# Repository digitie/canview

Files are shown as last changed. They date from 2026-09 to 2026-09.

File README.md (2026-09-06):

# canview

현대·기아·제네시스 차량의 CAN 데이터를 별도 **Communicator**에서 수집하고, `ESP-NOW`로 Waveshare `ESP32-S3-Touch-LCD-3.5` 기반 **Controller**에 전달해 시각화하는 프로젝트다. Controller는 최대 3개의 CAN 버스에서 들어오는 데이터를 표시하고, 필요한 경우 안전하게 제한된 의도 명령을 Communicator에 전달한다.

현재 1차 대상은 다음 차량이다.

- 2017년식 Hyundai Tucson TL
- 2.0 디젤
- 4WD
- BlueLink 사양

차량별 CAN 정의는 `commaai/opendbc`의 공개 DBC를 기준으로 시작한다. upstream에 2017년식 Tucson 전용 항목이 확인되지 않으므로, 현재 저장된 DBC는 실차 캡처로 검증해야 하는 후보 정의다.

## 문서

상세 문서를 한꺼번에 읽지 않도록 [문서 지도](docs/README.md)가 작업별 진입점과 정본 관계를 관리한다.

- [아키텍처 개요](docs/architecture/README.md): 장치·권한·protocol·기능 설계
- [현재 진척과 다음 작업](docs/resume.md)
- [열린 task와 gate](docs/tasks.md)
- [결정 색인과 ADR](docs/decisions.md)
- [적대적 리뷰 아카이브](docs/reviews/README.md)
- [에이전트 workflow](docs/runbooks/agent-workflow.md)

## UI prototype

320×480 세로 화면에 맞춘 주행·소리·FFT·자동화·설정 UI를 HTML prototype과 LVGL 8.4 코드로 제공한다. 현대 표준형 5W의 짙은 청색 tone과 LVGL 공식 eBike·Music 등 전체 데모의 유효한 패턴을 선별했다. 주행 화면 높이의 약 75%를 순정형 4WD 구동계에 할당하고, 중앙 차량·앞뒤 differential·shaft·네 바퀴 분절 torque bar를 표시한다. 순간연비는 차량 중앙에 두며 DPF와 작은 원형 속도·RPM이 이어진다. 현재 속도와 제한속도는 모든 화면에서 유지한다. 아래 값은 레이아웃 검토용 데모이며 실차 측정값이 아니다.

| 주행 상태 | 소리 제어 | FFT 분석 |
|---|---|---|
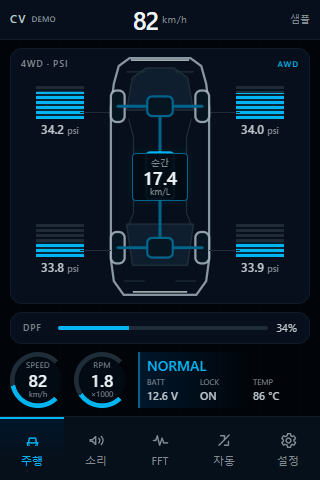
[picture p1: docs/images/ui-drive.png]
주행 화면
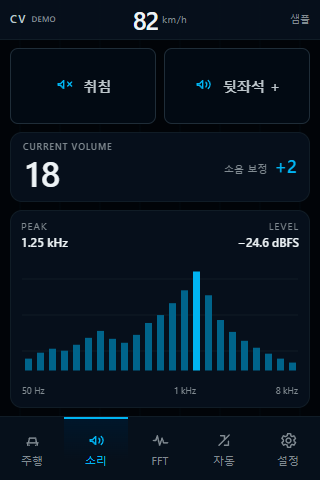
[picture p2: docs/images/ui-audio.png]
소리 화면
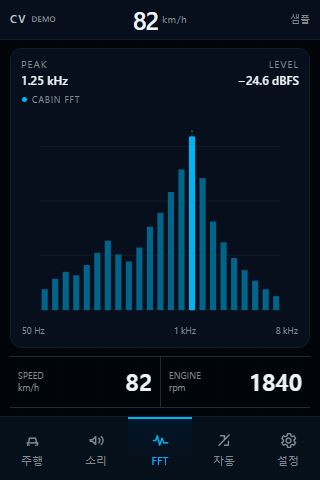
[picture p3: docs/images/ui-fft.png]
FFT 화면
|  |  |  |

| SPORT 자동화 | 설정 | 자동화 상세 설정 |
|---|---|---|
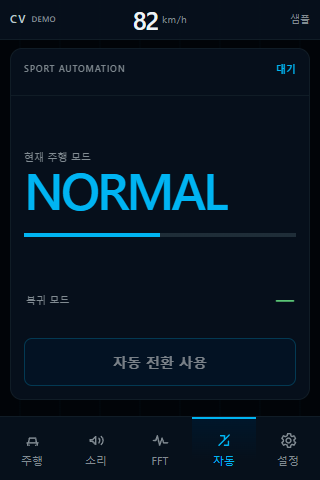
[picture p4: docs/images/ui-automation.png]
자동화 화면
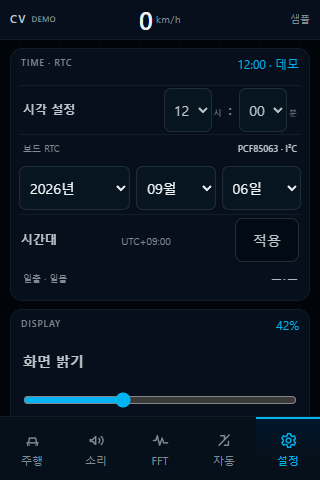
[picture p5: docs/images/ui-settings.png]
설정 화면
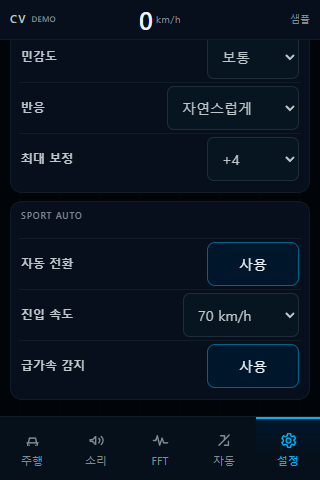
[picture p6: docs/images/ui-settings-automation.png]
소음·SPORT 설정 화면
|  |  |  |

- 브라우저 prototype: [`ui/prototype/`](ui/prototype/)
- LVGL 8.4 UI: [`ui/lvgl/`](ui/lvgl/)
- wire protocol C 구조: [`protocol/canview_protocol.h`](protocol/canview_protocol.h)

미확정 CAN ID·bit·scale은 별도 `Diagnostic Bridge`가 ESP-NOW read-only peer로 수신하고, 휴대폰이 Bridge의 고정-channel SoftAP에 접속해 확인하는 구조를 기본안으로 한다. 아래 정적 prototype은 세 CAN bus 상태, 행동 전후 capture, 64-bit 변화 지도와 후보 decoder의 모바일 정보 구조를 보여준다. 실제 REST·WebSocket firmware는 [구현 명세](docs/architecture/diagnostic-bridge.md)의 단계에 따라 추가한다.

| Diagnostic Bridge 상태 | Signal Lab |
|---|---|
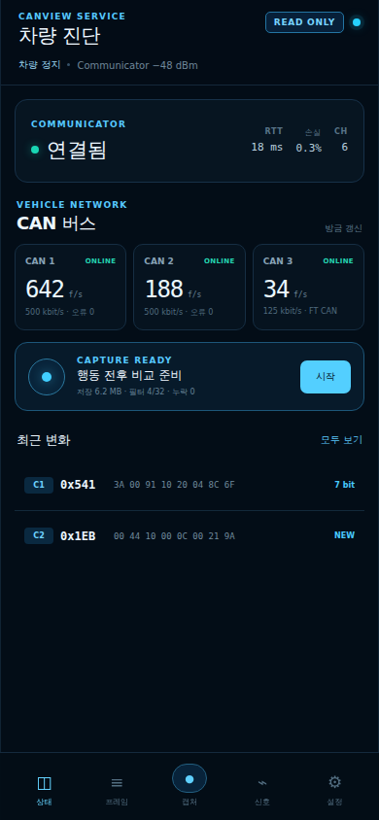
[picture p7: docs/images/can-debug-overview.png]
진단 상태 화면
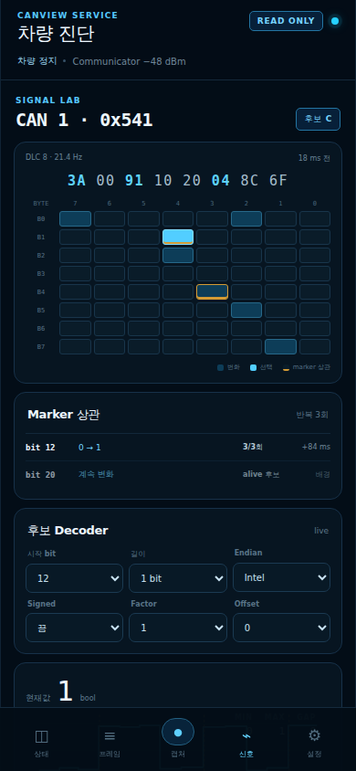
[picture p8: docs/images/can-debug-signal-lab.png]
신호 분석 화면
|  |  |

- 모바일 진단 prototype: [`ui/diagnostic-web/`](ui/diagnostic-web/)

## 저장된 DBC

원본은 `dbc/opendbc/`에 upstream 파일을 수정하지 않고 저장했다.

- `hyundai_can.dbc`: 현재 Hyundai 공통 CAN generator source. 1차 대상의 주 후보
- `hyundai_2015_ccan.dbc`: 구형 Classic CAN 참고 정의
- `hyundai_2015_mcan.dbc`: 구형 Multimedia CAN 참고 정의
- `LICENSE`: DBC 원본 저장에 필요한 upstream MIT License

파일의 upstream commit, SHA-256, 적용 범위는 [dbc/README.md](dbc/README.md)에 고정해 두었다.

## 저장소 상태

DBC 원본, hardware 기준, 기능 안전 경계, ESP-NOW wire 구조, 화면 prototype과 LVGL UI 계층을 포함한 설계 기준 저장소다. 실제 Communicator와 Controller firmware 통합은 실차 capture로 신호를 검증하면서 단계적으로 추가한다.

현재 저장소는 차량 송신 가능 상태가 아니다. protocol payload ABI·codec, 완성 firmware project, 승인 회로도와 firmware 독립 hard TX gate, 대상 차량 evidence가 모두 미완료다. 구현 순서와 차량 연결 gate는 [구현 준비 기준](docs/architecture/implementation-readiness.md)과 [task backlog](docs/tasks.md)를 따른다.

## 주요 원문

- [Waveshare ESP32-S3-Touch-LCD-3.5 제품 문서](https://docs.waveshare.com/ESP32-S3-Touch-LCD-3.5)
- [Waveshare 리소스 및 회로도](https://docs.waveshare.com/ESP32-S3-Touch-LCD-3.5/Resources-And-Documents)
- [Waveshare 예제 저장소](https://github.com/waveshareteam/ESP32-S3-Touch-LCD-3.5/)
- [commaai/opendbc](https://github.com/commaai/opendbc)

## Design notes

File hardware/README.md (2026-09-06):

# CANView KiCad 하드웨어

KiCad **10.0.6 Windows native**로 생성·내보내는 R1 상세 회로 검토본이다. 네 보드 모두 로컬 심벌·footprint, 부품별 사양, 연결표와 실제 KiCad netlist를 포함한다. **PCB 라우팅·Gerber·실물 시험은 포함하지 않으며 제작/차량 연결 승인본이 아니다.**

| 보드 | 편집 프로젝트 | 사람이 읽는 회로 | netlist |
|---|---|---|---|
| Communicator | [KiCad](communicator/kicad/communicator.kicad_pro) | [PDF](communicator/schematic.pdf) | [.net](communicator/communicator.net), [XML](communicator/netlist.xml) |
| Bridge | [KiCad](bridge/kicad/bridge.kicad_pro) | [PDF](bridge/schematic.pdf) | [.net](bridge/bridge.net), [XML](bridge/netlist.xml) |
| Controller 어댑터 | [KiCad](controller-adapter/kicad/controller-adapter.kicad_pro) | [PDF](controller-adapter/schematic.pdf) | [.net](controller-adapter/controller-adapter.net), [XML](controller-adapter/netlist.xml) |
| 원격 마이크 | [KiCad](microphone/kicad/microphone.kicad_pro) | [PDF](microphone/schematic.pdf) | [.net](microphone/microphone.net), [XML](microphone/netlist.xml) |

각 보드의 `bom.csv`는 reference/MPN/footprint/정격/허용오차/source/DNP/sheet를, `pinmap.csv`는 부품의 **물리 패드 번호별** net과 NC를 기록한다. `GEN-R-*`, `GEN-C-*`는 제조사 주문번호가 아니라 명시 사양의 구매 규격이다. 실제 구매품을 고를 때 동일 크기·전압·전력·온도·유효용량을 확인해야 한다. `PCB-PAD-1MM`는 구매 부품이 없는 테스트 패드다. `MP`는 JST 금속 고정 탭이며 신호 접점이 아니므로 명시적으로 NC다. USB 실드 패드는 `SH`로 GND에 연결한다.

설계 이유는 [R1 문서 지도](../docs/hardware/r1/README.md), 제조사 원본과 참조 페이지는 [references](references/README.md), 자동검사 결과는 [validation.json](validation.json), 수치 검산은 [margin-check.json](margin-check.json)에 있다.

## Windows 재생성

```powershell
Set-Location F:/dev/canview
.\tools\hardware\export-review.ps1
& 'C:\Program Files\KiCad\10.0\bin\python.exe' tools\hardware\validate_exports.py
& 'C:\Program Files\KiCad\10.0\bin\python.exe' tools\hardware\check_margins.py
& 'C:\Program Files\KiCad\10.0\bin\python.exe' -m unittest discover -s tools\protocol -p test_navigation_codec.py -v
# commit 이후, 저장된 evidence와 실제 Git blob을 대조 (read-only)
& 'C:\Program Files\KiCad\10.0\bin\python.exe' tools\hardware\validate_exports.py --git-revision HEAD
```

회로 source → KiCad XML/sexpr netlist → ERC → PDF 순서이며 각 native process의 종료를 기다린다. validator는 모든 부품의 실제 footprint를 KiCad `pcbnew`로 열고, 번호 있는 패드 집합/NC/net/BOM/주요 안전 pin을 대조한다. 자동검사 통과는 정격·PCB parasitic·고장 주입 검증을 대신하지 않는다. 로컬 symbol과 footprint에는 생성 입력과 출처가 포함되며 3D 모델은 KiCad 설치 경로 참조일 수 있다.

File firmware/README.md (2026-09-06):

# 펌웨어 진입점

현재 코드는 기능 구현 전의 안전 부팅/공용 codec 기반이다. 후속 agent는 [기반 구조와 인수인계](../docs/architecture/firmware-foundation.md)를 먼저 읽고 자신의 상세 task만 연다.

| 대상 | 프로젝트 |
|---|---|
| Controller | [controller](controller/README.md) |
| Communicator ESP32 | [communicator/esp32](communicator/esp32/README.md) |
| Communicator STM32 | [communicator/stm32](communicator/stm32/README.md) |
| Diagnostic Bridge | [diagnostic-bridge](diagnostic-bridge/README.md) |

공용 C99 코드는 ../shared, 장치 조합은 app/startup.c와 각 bsp, SDK 호출은 platform에 둔다.
BSP는 firmware/boards/boards.json과 원본 pinmap에서 생성한 board_pins.h를 사용한다.
기존 Controller components와 STM32 auto_sport는 legacy host 회귀에만 포함하고 새 target image에서는 제외한다.

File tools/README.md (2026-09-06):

# CANView 개발 도구

이 디렉터리는 Windows 정본 개발환경의 버전 manifest와 SDK 준비 스크립트를 보관한다. 실제 제품 기능이나 차량 설정은 이 디렉터리에 두지 않는다.

## 고정 버전

`toolchain-versions.json`이 현재 선택한 Windows x64 환경의 machine-readable 정본이다.

- ESP-IDF `v6.0.3`, target `esp32s3`
- STM32CubeG4 `v1.6.3`, MCU `STM32G474CEU6`
- CMake `4.4.3`
- Ninja `1.13.2`
- Arm GNU Toolchain `15.3.Rel1` (GCC `15.3.x`)
- KiCad `10.0.6` (`kicad-cli`, 회로도 export/ERC)

ESP-IDF와 STM32CubeG4는 manifest에 기록한 commit까지 검증한다. 버전 tag만 확인하지 않으므로 이동 tag나 잘못된 checkout을 조용히 사용하지 않는다.

## Windows 준비

먼저 CMake, Ninja, Git을 Windows `PATH`에 설치한다. Arm GNU Toolchain은 아래 설치 스크립트로 manifest의 `archiveUrl`에서 직접 내려받아 archive SHA-256, ZIP entry layout, 설치 root 전체 파일 inventory를 검증한다. `setup-windows.ps1`은 archive SHA-256과 provenance의 전체 파일 hash를 다시 확인하며 provenance marker가 없는 ambient `PATH` compiler를 사용하지 않는다. ESP-IDF build path에는 공백을 사용할 수 없으므로 Windows 사용자 profile 경로에 공백이 있으면 공백 없는 `-ToolRoot`를 지정한다. 그 다음 PowerShell에서 다음을 실행한다.

```powershell
Set-ExecutionPolicy -Scope Process -ExecutionPolicy Bypass
. .\tools\environment\install-arm-gnu.ps1
. .\tools\environment\foundation-windows.ps1
. .\tools\environment\setup-windows.ps1
```

기본 직접 설치 위치는 `%LOCALAPPDATA%\CANView\toolchains\arm-gnu-toolchain-15.3.rel1`이며 setup script가 provenance marker와 설치 root 전체 파일 hash를 확인한 뒤 자동 탐색한다. 이미 받은 archive를 재사용하려면 다음처럼 명시한다.

```powershell
. .\tools\environment\install-arm-gnu.ps1 -ArchivePath C:\path\arm-gnu-toolchain-15.3.rel1-mingw-w64-x86_64-arm-none-eabi.zip -AdoptExisting
```

이미 같은 release를 수동 압축 해제한 경로라면 `-AdoptExisting`를 추가한다. 스크립트가 pinned archive의 layout과 전체 파일 SHA-256을 대조한 뒤에만 provenance marker를 만든다. 설치 후 파일을 추가·삭제·변조하면 다음 setup 검증이 실패한다.

다른 verified 설치 위치를 사용할 때는 설치와 setup에 같은 root를 명시한다.

```powershell
. .\tools\environment\install-arm-gnu.ps1 -Destination C:\ArmGNU
. .\tools\environment\setup-windows.ps1 -ArmGnuRoot C:\ArmGNU\arm-gnu-toolchain-15.3.rel1 -ArmGnuArchive C:\path\arm-gnu-toolchain-15.3.rel1-mingw-w64-x86_64-arm-none-eabi.zip
```

예를 들어 사용자 profile에 공백이 있는 경우:

```powershell
. .\tools\environment\setup-windows.ps1 -ToolRoot C:\CANViewToolchains
```

스크립트는 최신으로 임의 갱신하지 않고, manifest에 고정된 ESP-IDF와 STM32CubeG4를 `%LOCALAPPDATA%\CANView\toolchains` 아래에 clone한다. ESP-IDF Python 도구를 설치한 뒤 현재 세션에 `IDF_PATH`와 `STM32CUBE_G4_ROOT`를 설정한다.

이미 SDK를 준비한 뒤 검증만 할 때는 archive가 설치 때 기록한 경로에 남아 있거나, `-ArmGnuArchive`로 같은 archive를 명시해야 한다.

```powershell
. .\tools\environment\setup-windows.ps1 -VerifyOnly -ArmGnuArchive C:\path\arm-gnu-toolchain-15.3.rel1-mingw-w64-x86_64-arm-none-eabi.zip
```

`-VerifyOnly`에서도 archive SHA-256, 설치 root 전체 파일 inventory, CMake·Ninja·Arm GCC 버전과 SDK commit, `idf.py`, STM32G4 device header를 모두 확인한다.

## 대상별 빌드

```powershell
# Controller: ESP32-S3R8, 16 MB Flash / 8 MB PSRAM
idf.py -C firmware/controller set-target esp32s3
idf.py -C firmware/controller build

# Communicator ESP32: ESP32-S3-WROOM-1-N16R8, 16 MB Flash / 8 MB Octal PSRAM (ECC)
idf.py -C firmware/communicator/esp32 set-target esp32s3
idf.py -C firmware/communicator/esp32 build

# 외부 component의 public protocol 의존성 compile fixture
idf.py -C tests/fixtures/idf-public-component set-target esp32s3
idf.py -C tests/fixtures/idf-public-component build

# Communicator STM32: Debug 또는 Release
Push-Location firmware/communicator/stm32
cmake --preset debug
cmake --build --preset debug
Pop-Location
```

## KiCad 회로도 산출물 재생성

KiCad `10.0.6`의 bundled Python으로 회로도 원본을 재생성하고, `kicad-cli`로 XML netlist·ERC JSON·PDF를 같은 revision으로 갱신한다.

```powershell
. .\tools\hardware\export-review.ps1
```

이 스크립트는 `hardware/`의 Communicator·Bridge·Controller adapter·microphone 네 보드를 갱신하고, ERC·BOM·netlist·named-pad 정합성 및 정적 전원/WD 계산까지 검사한다. 검사 실패 시 nonzero로 종료한다. [상세 사용법과 제작 전 제한](../hardware/README.md)을 따른다. 실제 전원·PCB·HIL 승인을 뜻하지 않는다.

PowerShell에서 `idf.py`를 찾지 못하면 새 세션에서 다시 dot-source하고, STM32 configure가 실패하면 Arm archive 경로와 `STM32CUBE_G4_ROOT`를 확인한다. target build가 실제로 실행되지 않은 상태를 성공으로 기록하지 않는다.

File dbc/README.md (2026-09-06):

# Hyundai DBC 저장소

## 1. 저장 목적

이 디렉터리는 `commaai/opendbc`에서 가져온 Hyundai·Kia·Genesis 계열 CAN 정의를 `canview`의 재현 가능한 입력으로 보관한다. DBC 파일은 차량 CAN raw frame을 사람이 읽을 수 있는 message/signal 값으로 decode하기 위한 정의이며, 파일에 정의된다고 해서 모든 연식·트림·시장 사양에서 동일하게 동작한다는 뜻은 아니다.

원본 DBC는 프로젝트에서 임의로 수정하지 않았다. 차량별 보정이나 캡처 결과는 원본 파일을 덮어쓰지 않고 별도 파일과 검증 기록으로 추가한다.

## 2. upstream 고정 정보

| 항목 | 값 |
|---|---|
| 저장소 | [`commaai/opendbc`](https://github.com/commaai/opendbc) |
| snapshot commit | [`3e92d112129507debe45364891954db70238997a`](https://github.com/commaai/opendbc/tree/3e92d112129507debe45364891954db70238997a) |
| snapshot 날짜 | 2026-09-03 기준 checkout |
| 라이선스 | MIT. 원문은 [`dbc/opendbc/LICENSE`](opendbc/LICENSE) |
| 1차 대상 | 2017 Hyundai Tucson TL, 2.0 디젤, 4WD, BlueLink |
| 1차 주 후보 | `hyundai_can.dbc` |

### 저장 파일과 역할

| 로컬 파일 | upstream 원본 경로 | 역할 |
|---|---|---|
| [`hyundai_can.dbc`](opendbc/hyundai_can.dbc) | `opendbc/dbc/generator/hyundai/hyundai_can.dbc` | 현재 Hyundai 공통 CAN generator source. 1차 대상의 주 후보 |
| [`hyundai_2015_ccan.dbc`](opendbc/hyundai_2015_ccan.dbc) | `opendbc/dbc/hyundai_2015_ccan.dbc` | 구형 Classic CAN 비교용 |
| [`hyundai_2015_mcan.dbc`](opendbc/hyundai_2015_mcan.dbc) | `opendbc/dbc/hyundai_2015_mcan.dbc` | 구형 Multimedia CAN 비교용 |
| [`LICENSE`](opendbc/LICENSE) | `LICENSE` | upstream MIT License 원문 |

현재 1차 대상은 Classic CAN 후보이므로 CAN-FD generator와 include 파일은 이 snapshot에 복사하지 않았다. CAN-FD 차량을 추가할 때는 `hyundai_canfd.dbc`와 상대 include인 `_hyundai_canfd_common.dbc`를 같은 upstream commit에서 함께 고정한다.

## 3. 무결성 확인

현재 저장해야 할 SHA-256은 다음과 같다. upstream을 갱신할 때는 commit과 해시를 함께 바꾼다.

| 파일 | SHA-256 |
|---|---|
| `hyundai_can.dbc` | `a3fb6e98bfdc0041914643f1422b1bb9290462981c40249a05cd7773e71a8bc3` |
| `hyundai_2015_ccan.dbc` | `d7f822e3a8d220cfde83aec2ae4ed28ddbc44a38ff29bea2e12e3e321d73a607` |
| `hyundai_2015_mcan.dbc` | `b18e69bdd30e53fe689b23fbd59779095249a1bb5b2391435e814a490fa924e4` |
| `LICENSE` | `6543c4a66b46affddae1b9ae1e1992687f0b7191e74ba3a7235388b9f42a6d13` |

확인 명령:

```bash
sha256sum dbc/opendbc/*.dbc dbc/opendbc/LICENSE
```

## 4. 1차 차량 적용 방법

upstream의 일반 `HYUNDAI_TUCSON` 플랫폼은 `hyundai_can_generated`를 사용한다. 따라서 generator source인 `hyundai_can.dbc`를 1차 decode 후보로 선택했다. 하지만 upstream에는 2017 Tucson TL의 엔진·구동·BlueLink 조합을 별도 fingerprint로 확정한 항목이 없으므로, 이 선택은 “후보”이며 실차 검증 결과가 아니다.

실차 적용 순서는 다음과 같다.

1. 차량의 실제 CAN connector, bus, bitrate를 listen-only로 확인한다.
2. ignition off/on, idle, 주행, 변속, 제동, 4WD 상태를 별도 캡처한다.
3. `hyundai_can.dbc`로 ID와 signal을 decode한다.
4. 계기판·실측값과 비교해 신호를 A/B/C/X 등급으로 기록한다.
5. 검증된 신호만 기본 화면에 표시하고, 미확인 값은 일반 UI에서 숨긴 채 service log에 `candidate`/`raw`로 기록한다.

차량별 결과는 [2017 Tucson TL 문서](../docs/vehicle/target-2017-tucson.md)에 기록한다. 내비·연비·오디오·BCM·IPS·도어를 포함한 상세 후보와 제어 등급은 [signal catalog](../docs/vehicle/signal-catalog.md)에 있다.

## 5. 우선 확인할 신호

다음은 `hyundai_can.dbc`를 읽어 정리한 1차 후보 목록이다. ID는 표준 11-bit decimal/hex 표기이며, 실차 bus 위치와 존재 여부는 아직 확정하지 않았다.

| Message (ID) | 주요 signal | DBC 변환 |
|---|---|---|
| `CLU11` (`0x4F1`) | `CF_Clu_Vanz` | factor `0.5`, `km/h or MPH` |
| `CLU12` (`0x5B0`) | `CF_Clu_Odometer` | factor `0.1`, `km` |
| `WHL_SPD11` (`0x386`) | `WHL_SPD_FL/FR/RL/RR` | factor `0.03125`, `km/h` |
| `EMS11` (`0x316`) | `N`, `TQI`, `VS` | `N`: `0.25 rpm`; `VS`: `1 km/h` |
| `EMS12` (`0x329`) | `TEMP_ENG`, `TPS`, `ENG_VOL` | 온도 `0.75/-48`; TPS `0.4694836/-15.0234742`; 용적 `0.1` |
| `EMS14` (`0x545`) | `VB`, `EMS_VS` | `VB`: `0.1015625 V`; `EMS_VS`: `0.0625 km/h` |
| `EMS16` (`0x260`) | `ENG_STAT`, `GLOW_STAT` | 상태 code/flag |
| `EMS19` (`0x492`) | `CR_Ems_EngOilTemp`, `DPF_LAMP_STAT` | 온도 `0.75/-40` |
| `TCU11` (`0x111`) | `G_SEL_DISP`, `GEAR_TYPE`, `N_TC` | `N_TC`: `0.25 rpm` |
| `TCU12` (`0x112`) | `CUR_GR`, `VS_TCU`, `N_TC_RAW` | 현재 기어/속도/RPM 후보 |
| `_4WD11` (`0x428`) | `_4WD_TYPE`, `_2H_ACT`, `_4H_ACT`, `LOW_ACT`, `AUTO_ACT`, `LOCK_ACT` | bit flag/상태 code |
| `_4WD12` (`0x429`) | `FRSS`, `FLSS`, `RRSS`, `RLSS`, `CLU_PRES` | wheel speed byte, pressure factor `0.0625` |
| `_4WD13` (`0x42A`) | `_4WD_CURRENT`, `_4WD_POSITION`, `_4WD_STATUS` | current/position/status 후보 |
| `ESP12` (`0x220`) | `LAT_ACCEL`, `LONG_ACCEL`, `YAW_RATE` | accel factor `0.01`; yaw factor `0.01` |
| `SAS11` (`0x2B0`) | `SAS_Angle` | signed factor `0.1 deg` |
| `MDPS11`/`MDPS12` (`0x381`/`0x251`) | steering angle/torque | 표시 전용 후보 |
| `TPMS11` (`0x593`) | tire status/pressure bytes | 단위·위치 별도 검증 |
| `SCC11` (`0x420`) | `ObjValid`, `ACC_ObjDist`, `ACC_ObjRelSpd` | read-only 참고 |
| `LKAS11` (`0x340`) | warning/request fields | 송신 금지 |

DBC의 sender/receiver 표기와 실제 차량 bus의 위치는 서로 다른 정보다. `sender`가 `EMS`라고 되어 있어도 차량에서 어느 물리 CAN bus에 보이는지는 캡처로 정한다.

## 6. Python decode 예

검증용으로만 사용한다. 차량에 연결하거나 frame을 송신하는 코드가 아니다.

```bash
python -m pip install cantools
```

```python
import cantools

db = cantools.database.load_file("dbc/opendbc/hyundai_can.dbc")
message = db.get_message_by_frame_id(0x4F1)
decoded = message.decode(bytes.fromhex("00 00 00 00"), decode_choices=False)
print(message.name, decoded)
```

실제 payload의 byte order, counter, checksum, multiplex 조건을 캡처와 함께 확인한다. 임의 payload를 차량 bus로 전송하지 않는다.

## 7. 갱신 절차

upstream DBC를 갱신할 때는 다음을 모두 한 변경으로 남긴다.

1. upstream commit을 선택하고 URL을 기록한다.
2. 원본 상대 경로를 보존해 필요한 include/source를 복사한다.
3. 파일을 수정하지 않고 SHA-256을 계산한다.
4. 이 문서의 commit, 날짜, 해시, 파일 역할을 갱신한다.
5. 1차 대상 차량에서 재캡처하거나 기존 캡처를 다시 decode한다.
6. 변경 전후의 signal 목록과 해석 차이를 기록한다.

## 8. 라이선스

저장된 DBC와 `LICENSE`는 `commaai/opendbc` snapshot에서 가져왔다. 배포·변경·고지 시 [`dbc/opendbc/LICENSE`](opendbc/LICENSE)의 MIT 조건을 따른다. 프로젝트 문서의 차량별 검증 결과와 새 보정 DBC는 원본 upstream 파일과 별도로 관리한다.

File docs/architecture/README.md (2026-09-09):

# CANView 아키텍처

이 문서는 CANView의 장치 관계, 데이터 흐름과 권한 경계를 설명하는 상위 아키텍처 정본이다. 여기서 전체 형태를 확인한 뒤 변경 대상에 해당하는 상세 문서만 읽는다. 구현 순서는 [implementation readiness](implementation-readiness.md), 결정의 역사는 [ADR 색인](../adr/README.md), 현재 작업은 [tasks](../tasks.md)를 따른다.

## 문서 사용법

| 변경 대상 | 상세 정본 |
|---|---|
| 장치명·peer routing·장애 상태 | [시스템 구조](system.md) |
| repository 목표 구조·runtime 경계·release gate | [구현 준비 기준](implementation-readiness.md) |
| 실제 기반 코드·MCU 독립 API·다음 agent 인수인계 | [펌웨어 기반 구조](firmware-foundation.md) |
| 전체 계획 감사·요구사항별 수용 기준 추적 | [요구사항 coverage](requirements-coverage.md) |
| ESP-NOW·UART wire 계약 | [프로토콜 인덱스](protocols/README.md) |
| 독립 OTA·부트 복구·N16R8 회로 변경 | [OTA 설계와 적대적 리뷰](ota.md) |
| 외부 GNSS·온보드 INS·기압·시간 | [센서 확장 계약](protocols/navigation.md), [R1 하드웨어](../hardware/r1/README.md) |
| Controller 수신·filter·DBC decode | [Controller CAN pipeline](controller-can-pipeline.md) |
| Diagnostic Bridge·capture·REST/WS | [Diagnostic Bridge](diagnostic-bridge.md) |
| 4WD·DPF·audio·SPORT 기능 | [기능 설계](features.md) |
| 밝기·FFT 음량·SPORT 상태기계 | [자동화 설계](automation.md) |

하드웨어, 차량 evidence와 UI 시각 설계는 architecture의 입력이지만 각각 [hardware](../README.md#하드웨어), [vehicle](../README.md#차량과-신호), [UI](../README.md#ui) 문서가 상세 정본이다. 일반 작업에서 위 문서를 모두 선제적으로 읽지 않는다.

## 1. 시스템 범위

CANView는 2017 Tucson TL 2.0 디젤 4WD BlueLink를 1차 대상으로 하는 차량 CAN viewer/controller다. 동일한 구조로 현대·기아·제네시스 차량 profile을 확장할 수 있지만, DBC에 존재한다는 이유만으로 차량별 신호나 제어 명령을 확정하지 않는다.

시스템은 다음 세 장치로 나뉜다.

| 장치 | 하드웨어 | 주 책임 |
|---|---|---|
| Controller | Waveshare ESP32-S3-Touch-LCD-3.5 | LVGL 운전자 UI, 터치, Controller-local 설정, ESP-NOW 명령 요청 |
| Communicator | ESP32-S3-WROOM-1-N16R8 + STM32G474CEU6 + 3 CAN PHY | CAN 수집, timestamp, 안전 상태, 검증된 제한 송신 |
| Diagnostic Bridge | 별도 ESP32-S3 | read-only CAN 관찰, capture, signal lab, 휴대폰용 SoftAP 웹 |

## 2. 데이터 흐름

    차량 CAN 1/2/3
          │
          ▼
    TCAN1046AV-Q1 2채널 + MAX3055 1채널
          │
          ▼
    STM32G474CEU6
      ├─ FDCAN raw capture / bus fault / timestamp
      ├─ local safety profile / command executor
      └─ UART 4 Mbps, RTS/CTS
          │
          ▼
    Communicator ESP32-S3-WROOM-1-N16R8
      ├─ ESP-NOW secure session
      ├─ peer별 filter / quota / retry
      └─ Controller·Diagnostic Bridge routing
          │
          ├──────────────► Controller
          │                 LVGL·상태표시·제한 명령 의도
          │
          └──────────────► Diagnostic Bridge
                            capture·후보 분석·HTTP/WebSocket
                                      │
                                      ▼
                                   휴대폰

Controller와 Communicator 사이에는 ESP-NOW 양방향 링크를 사용한다. Diagnostic Bridge는 별도 peer로 관찰 stream을 받으며, 차량 CAN 송신 경로에는 연결하지 않는다. broadcast raw telemetry와 무제한 multi-hop mesh는 사용하지 않는다.

현재 STM32의 capture-only C source 계약은 [T-103 FDCAN capture 문서](../../firmware/communicator/stm32/docs/fdcan-capture.md)에 있다. IRQ raw snapshot, bounded ring, timestamp 확장과 generic inventory는 관찰 데이터만 만들며, 기본 app wiring이 시작되기 전까지 실제 bus 연결 권한을 부여하지 않는다.

## 3. 책임과 신뢰 경계

| 계층 | 허용 책임 | 금지 책임 |
|---|---|---|
| Controller | 운전자에게 검증된 상태 표시, 입력 검증, local 설정, 의미 있는 명령 요청 | 임의 CAN frame 생성, 최종 safety 판정, 후보 신호의 확정 표시 |
| Communicator ESP32 | ESP-NOW 인증·session·queue·peer 권한·UART routing | DBC 의미 해석, CAN peripheral 직접 제어, 최종 TX 허용 |
| Communicator STM32 | CAN timestamp/error, generated profile, local safety 재검사, 제한 executor | 무선 payload를 그대로 신뢰, raw replay, UI 상태를 차량 사실로 사용 |
| Diagnostic Bridge | read-only inventory·capture·candidate·evidence·웹 진단 | control lease, vehicle CAN TX, raw replay |
| CAN PHY | 논리 신호와 물리 bus 변환, standby·fault 처리 | bitrate·signal 의미·제어 권한 결정 |

차량 CAN 송신은 다음 네 요소가 동시에 맞아야 한다.

1. 검증된 vehicle profile과 command builder
2. 최신이고 유효한 STM32 local safety snapshot
3. Primary Controller의 control lease와 인증된 명령
4. build mode·전원·외부 watchdog·hard TX gate의 허용 상태

하나라도 빠지면 송신하지 않고 이유와 revision을 기록한다.

## 4. 안전 상태와 build mode

| build mode | 허용 동작 | 실제 차량 연결 |
|---|---|---|
| CAPTURE_ONLY | CAN 수신·통계·표시·capture | 수신 전용으로만 허용 |
| BENCH_TX | current-limited 전원과 HIL에서 제한 송신 | 차량 연결 금지 |
| VEHICLE_TX | 모든 hardware·firmware·profile·evidence gate 통과 뒤 제한 송신 | release qualification 후에만 허용 |

전원·reset·brownout·watchdog·통신 단절 시 기본 상태는 CAN 송신 차단이다. TCAN 채널은 standby, MAX3055는 Power-On Standby, 외부 TX gate는 off로 수렴해야 한다. firmware GPIO 초기화만으로 이 조건을 보장한다고 간주하지 않는다.

## 5. 저장소 구조

    protocol/                         — ESP-NOW/UART schema와 생성 ABI
    dbc/                              — upstream DBC 원본과 라이선스
    firmware/controller/              — Controller ESP-IDF/LVGL
    firmware/communicator/esp32/      — Communicator 무선 MCU
    firmware/communicator/stm32/      — STM32 CMake/FDCAN/UART
    hardware/communicator/            — pinmap·KiCad·BOM·전원 계산
    ui/prototype/                     — 화면 검토용 HTML prototype
    ui/lvgl/                          — LVGL 화면 코드
    ui/diagnostic-web/                — 모바일 진단 웹 prototype
    tests/                            — host·protocol·fault·HIL test
    docs/architecture/                — 상위 구조·protocol·기능 설계
    docs/hardware/                    — Controller·Communicator 하드웨어
    docs/development/                 — Windows 환경과 toolchain
    docs/vehicle/                     — 대상 차량·DBC·signal evidence
    docs/ui/                          — UI 설계와 LVGL 검토
    docs/reviews/                     — 독립 review 이력
    docs/adr/                         — 결정 기록
    docs/runbooks/                    — 에이전트 운영 절차
    docs/tasks.md                     — 열린 task 요약
    docs/tasks/                       — task별 상세 문서

## 6. 문서 정본

| 목적 | 정본 |
|---|---|
| 전체 구현 기준 | [구현 준비 기준](implementation-readiness.md) |
| 장치·데이터 흐름 | 이 문서와 [시스템 상세](system.md) |
| 하드웨어 | [Communicator](../hardware/communicator.md), [Controller](../hardware/controller.md) |
| protocol | [protocol index](protocols/README.md) |
| 차량 신호·기능 | [signal catalog](../vehicle/signal-catalog.md), [기능 설계](features.md) |
| 진단 웹 | [Diagnostic Bridge](diagnostic-bridge.md) |
| 결정 | [ADR](../adr/README.md), [결정 색인](../decisions.md) |
| 진척 | [resume](../resume.md), [journal](../journal.md) |
| 작업 | [task 요약](../tasks.md)과 [상세 task](../tasks/) |

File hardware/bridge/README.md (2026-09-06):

# Bridge 회로

USB-C 전원의 ESP32-S3-WROOM-1-N8R2 read-only 진단 Bridge다. CAN PHY/차량 TX 경로는 없다.

[KiCad](kicad/bridge.kicad_sch) · [PDF](schematic.pdf) · [netlist](bridge.net) · [BOM](bom.csv) · [pinmap](pinmap.csv)

USB-C는5V1.5A 이상 C-to-C source를 요구한다. 상세 전원/핀/검증은 [R1 설명](../../docs/hardware/r1/bridge-controller-microphone.md)과 [공통 재생성 안내](../README.md)를 따른다. ERC와 정합성 통과는 제작·RF·USB 인증이 아니다.

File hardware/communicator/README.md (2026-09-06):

# Communicator R1 회로 산출물

이 디렉터리는 `R1-review` 제안 회로의 검토 산출물을 보관한다. 현재 상태는 **제작 정본이 아니며 차량 CAN 연결·송신 승인도 아니다**.

## 포함 범위

- [kicad/communicator.kicad_sch](kicad/communicator.kicad_sch): 전원/USB, STM32/ESP32, CAN PHY/gate, MTi7/BMP384, GPS, 24개 테스트 패드의 28개 상세 sheet와 root
- `bom.csv`: MPN·footprint·source·DNP·sheet가 포함된 검토용 BOM
- [netlist.xml](netlist.xml), [communicator.net](communicator.net): KiCad가 실제 내보낸 XML/sexpr netlist
- `pinmap.csv`: KiCad symbol pin과 net을 펼친 기계 판독 표
- `connectivity.json`: source에서 생성된 sheet·component·net 연결 모델과 provenance
- `erc.json`: KiCad ERC 결과
- `preview.png`, `schematic.pdf`: 사람이 검토할 수 있는 export
- `../libraries/`: 이 회로에서 사용하는 symbol·footprint 사본
- `../references/manifest.json`: 부품 원문과 SHA-256 기록. 현재 manifest에는 `stm32g4-hardware` 원문 fetch timeout이 기록되어 있어 reference evidence가 완전하지 않다.

## 현재 gate

KiCad10.0.6에서 **ERC0개와 named-pad/net/BOM 정합성 검사 통과**다. [검증 JSON](../validation.json)을 참조한다. MAX20040 U8 footprint는 제조사 land 원본 대조가 미완료인 PROVISIONAL이며, PCB·열·SI·전원 transient/SOA·HIL 검증도 없다. [제작 전 조건](../../docs/hardware/r1/verification.md)을 닫기 전 주문·조립·차량 연결에 사용하지 않는다.

특히 다음 안전 경계는 회로와 firmware 양쪽에서 다시 확인해야 한다.

- TX permit이 없거나 MCU·rail·watchdog·물리 arm 조건이 사라지면 세 CAN TXD가 recessive/tri-state로 수렴해야 한다.
- CAN1/2 split termination은 DNP, CAN3 RTH/RTL4.7k는 FIT 출발값이다. 검증된 ISO11898-3 버스에서만 사용할 수 있다.
- ESP32 USB/SWD는 차량 전원과 분리된 service 경로이며, USB·SWD만 연결해도 CAN PHY가 활성화되면 안 된다.

## 재생성 원칙

정본 입력은 `tools/hardware/*_circuits.py`다. `connectivity.json`도 생성물이므로 수동 편집하지 않는다. 네 보드의 회로도·netlist·BOM·pinmap·ERC/PDF를 함께 갱신한다. [FW 핀맵](../../docs/hardware/r1/firmware-pinmap.md)과 [전원/CAN 설명](../../docs/hardware/r1/communicator-circuit.md)을 사용하고, [이전 pin proposal](history/pinmap-pre-r1.csv)은 오류가 포함된 이력이므로 구현에 사용하지 않는다. Windows 저장소 루트에서 실행한다.

```powershell
. .\tools\hardware\export-review.ps1
```

이 스크립트가 `build_schematics.py`를 KiCad `10.0.6` bundled Python으로 실행한 뒤 `kicad-cli`로 XML netlist, ERC JSON, PDF를 내보낸다. 생성된 산출물을 손으로 고치지 않으며, vendor PDF는 reference evidence로만 사용한다. `ESP32-S3-MINI-1`은 S2 footprint를 재사용하지 않고 공식 S3 land pattern을 vendored footprint로 사용한다. STM32 UFQFPN48의 7번 패드는 `PG10-NRST` 이중 기능이며 `SYS_RESET_N`에 연결한다.

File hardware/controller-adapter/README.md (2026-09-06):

# Controller 마이크 adapter

Waveshare의32pin female header에 연결하는 male adapter다. 카메라 GPIO38/39/40을 원격 I²S mic에 사용하므로 카메라와 동시 사용할 수 없다. RTC는 Waveshare 내장 회로를 재사용한다.

[KiCad](kicad/controller-adapter.kicad_sch) · [PDF](schematic.pdf) · [netlist](controller-adapter.net) · [BOM](bom.csv) · [pinmap](pinmap.csv)

케이블 LVDS100Ω 종단과5V fuse가 포함된다. mating 높이·방향·간섭은 실물 검증 전이다. [케이블/핀/타이밍 설명](../../docs/hardware/r1/bridge-controller-microphone.md)을 먼저 읽는다.

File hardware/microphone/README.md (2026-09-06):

# 원격 I²S 마이크

T5848 1.8V mic, LVDS 수신/송신, AXC level translation,3.3/1.8V LDO를 사용한다.32kHz/64fs, BCLK2.048MHz가 기준이며 일반3.3V I²S를 케이블에 직접 보내지 않는다.

[KiCad](kicad/microphone.kicad_sch) · [PDF](schematic.pdf) · [netlist](microphone.net) · [BOM](bom.csv) · [pinmap](pinmap.csv)

3m는 검증 전 길이 목표다. acoustic hole/annular GND/paste 공정과 케이블 지연은 [설계·수용 기준](../../docs/hardware/r1/bridge-controller-microphone.md)에 따라 시험한다. ERC 통과만으로 길이·음질·소음 기반 볼륨 동작을 보장하지 않는다.

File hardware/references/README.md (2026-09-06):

# R1 제조사 원문 참조색인

2026-09-05 기준 `pdf/`에 저장된 **PDF 56개, 총 1,745쪽**의 사용처를 연결한다. [manifest](manifest.json)의 저장 문서 56개와 실제 파일을 대조한다. [참조 입력](../../tools/hardware/references.json)은 58개 항목이며, 그중 AN5093와 MAX20040 단독 회로도는 저장되지 않았다. 최신 MAX Rev 16과 land 90-0409의 미확보 상태는 아래에서 별도로 관리한다. 이 색인은 회로·PCB 제작 승인서가 아니다.

## 정본과 읽는 방법

| 찾는 정보 | 정본·해석 |
|---|---|
| 공식 출처·실제 미러·파일 무결성 | [manifest.json](manifest.json)의 같은 `id` 항목: `url`, `download_url`, `file`, `bytes`, `sha256`. `download_url`이 없으면 별도 미러가 기재되지 않은 것이며, 최종 HTTP 리다이렉트까지 기록됐다는 뜻은 아니다. |
| 개정·사용 의도 | 같은 manifest 항목의 `use`와 저장 PDF 본문의 개정 표시. 현재 manifest에는 독립 `revision` 필드가 없고 일부 개정만 `use`에 기록돼 있다. 미기재 개정을 추정하거나 모든 저장본을 최신판으로 간주하지 않는다. 수집 입력의 `use`는 [references.json](../../tools/hardware/references.json)에서 추적한다. |
| 전원·CAN 채택 결정 | [Communicator 회로](../../docs/hardware/r1/communicator-circuit.md), [핀맵·FW 계약](../../docs/hardware/r1/firmware-pinmap.md) |
| 센서·GNSS·원격 수음 결정 | [위치·관성 하드웨어](../../docs/hardware/r1/navigation-hardware.md), [Bridge·Controller·마이크](../../docs/hardware/r1/bridge-controller-microphone.md) |
| 아직 승인하지 않은 조건 | [검증·제작 전 조건](../../docs/hardware/r1/verification.md), [PDF 확보·실패 기록](../../docs/hardware/r1/pdf-acquisition.md) |

아래 파일 링크의 이름은 manifest의 `id`와 동일하다. **모든 쪽수는 표지부터 세는 PDF 1기준**이며 `#page=N`은 첫 참조 쪽이다. 뷰어가 이를 무시하면 쪽 번호를 직접 입력한다. 절·표 이름은 저장본에서 찾을 검색어다. `use`에 적힌 예전 쪽수보다 아래 저장본 기준 위치를 우선한다. 특히 TPS629210 MODE/VSET 표는 11~13쪽, SN74LV1T125 핀 표는 4쪽이다.

MTi 사용자 매뉴얼만은 **PDF 쪽 = 인쇄 쪽 + 3**이다. 예를 들어 인쇄 78쪽 전원 절은 PDF 81쪽이다. 이 보정을 다른 PDF나 별도의 Xsens GNSS 응용 노트에 일괄 적용하지 않는다.

## 1. 차량 입력·보호·AUTO5V — 13개

[Communicator 회로 §2~3](../../docs/hardware/r1/communicator-circuit.md)의 출처다. 제조사 응용회로를 출발점으로 쓰되 TVS 에너지, FET SOA, 보상 루프와 기동 조건은 실제 운용점에서 별도 검증한다.

| 저장 PDF / 전체 쪽수 | 정확한 참조 쪽·절 | 회로 반영 또는 배제 사유 |
|---|---|---|
| [lm7480](pdf/lm7480.pdf#page=3) / 46 | 3쪽 §6 핀, 4~9쪽 §7 정격·전기 특성, 29~32쪽 §10.3 공통 소스 응용, 35쪽 배치, 43~45쪽 DRR 도면·land·paste | LM74800과 공통 소스 FET 2개, OV 차단·VS/CAP 공급에 반영. EP는 FLOAT이며 일반 land 예시를 이유로 GND via를 넣지 않는다. 전류 제한 기능으로 해석하지 않는다. |
| [lm7480-evm](pdf/lm7480-evm.pdf#page=4) / 15 | 4쪽 §3/Fig. 3-1 회로, 9~10쪽 §6.1 배치, 11~12쪽 BOM | 공통 소스 연결·부품 선택 참고. EVM의 CS 15nF는 그대로 채택하지 않고 아래 TI 교정 사례와 데이터시트에 따라 1µF로 반영했다. |
| [lm7480-surge](pdf/lm7480-surge.pdf#page=7) / 13 | 4~6쪽 Design #1~2, 7쪽 Design #3 공통 소스·load dump | 공통 드레인/단일 이상 다이오드와 구분해 공통 소스 구성을 선택. 예제의 200V 표기는 R1의 surge 시험 통과 근거가 아니다. |
| [buk9y12-100e](pdf/buk9y12-100e.pdf#page=2) / 13 | 2쪽 §5 핀·§8 DC VGS ±10V, 4쪽 SOA, 10쪽 SOT669 | **교체·미채택**: LM74800의 지속 게이트 구동 정격에 부족하다. 최초 후보 감사 근거로만 보존한다. |
| [buk7y12-100e](pdf/buk7y12-100e.pdf#page=2) / 13 | 1쪽 RDS(on), 2쪽 §5 핀·§8 **DC VGS ±20V**, 4쪽 SOA, 10쪽 SOT669 | 수정 Q1/Q2, 100V·12mΩ@10V, 기존과 같은 LFPAK56. LM 최대14.5/13V와 DC 정격을 대조했으며 pulse SOA/실측 승인은 별개다. |
| [bas21h](pdf/bas21h.pdf#page=2) / 10 | 2쪽 §2 핀, 3~5쪽 정격·특성, 6~7쪽 §9·11 외형·납땜 land | LM74800 CS→VS bootstrap 공급의 200V 다이오드. 극성과 SOD123F를 보존한다. |
| [bzt52h](pdf/bzt52h.pdf#page=2) / 14 | 2쪽 §5 핀, 4~10쪽 §8~10 정격·제너 특성, 11쪽 §11~12 외형·land | VS의 47V 제너 clamp에 반영. 제너 허용차·전류·손실을 포함해 검증하며 nominal 47V만으로 보호 완료를 주장하지 않는다. |
| [littelfuse-451](pdf/littelfuse-451.pdf#page=2) / 4 | 2쪽 품목별 전기 정격·I²t, 3쪽 시간/전류·온도 곡선, 4쪽 치수·권장 패드 | 0451001.MRL 1A와 Nano2 패키지에 반영; 1206 대체 금지. **2023-09-18 구판**, 확인된 공식 2025-12-01 개정과 다르다. 외부 하네스 퓨즈와 협조 시험이 남아 있다. |
| [smbj](pdf/smbj.pdf#page=2) / 6 | 1~3쪽 최대·품목별 전기 정격, 4쪽 펄스/열 곡선, 5쪽 SMB 외형·패드 | SMBJ36CA 입력 TVS. 600W/10·1000µs 정격을 수백 ms load dump 에너지 보장으로 확대하지 않는다. |
| [max20040](pdf/max20040.pdf#page=9) / 20 | 2~6쪽 정격·전기 특성, 3쪽 패키지 표, 9~10쪽 핀, 14~17쪽 FB/보상 설계, 18쪽 배치, 20쪽 개정 이력 | MAX20040B, 5.0875V nominal 분압, 두 LX/BST 루프·Kelvin sense의 근거. **Rev 15, 3/24 구판**이며 Rev 16의 절대최대정격 Note 1·2 변경을 대체하지 못한다. 3쪽의 land ID만으로 footprint 치수 검증을 완료하지 않는다. |
| [max20040-evm](pdf/max20040-evm.pdf#page=3) / 8 | 3쪽 BOM의 D1 BAT54ALT1G, 4쪽 `MAX20040 EV Kit Schematic`, 8쪽 개정 이력 | **Rev 3, 3/24**. 공통 anode D1의 외부 bootstrap 충전 경로를 반영하되 R1은 PMEG4010BEA 2개를 쓴다. 보상 부품은 출발값일 뿐 수정 출력/PCB의 안정성 승인값이 아니다. 단독 schematic PDF와는 다른 문서다. |
| [pmeg4010bea](pdf/pmeg4010bea.pdf#page=1) / 8 | 1쪽 §5 핀, 2~3쪽 §8~10 정격·누설/순방향 특성, 4~5쪽 외형·land | AUTO_VCC4→BST1/BST2 각각 A→K의 40V Schottky. pin1=K/pin2=A, SOD323을 적용. 고온 누설과 충전 peak/역전압은 실측 대상이다. |
| [coilcraft-xal5030](pdf/coilcraft-xal5030.pdf#page=1) / 4 | 1쪽 XAL50xx 규격 표, 2~3쪽 L/전류 곡선, 4쪽 외형·패드/포장 | XAL5030-472MEC 4.7µH 출발값. 포화·RMS 전류와 온도별 유효 L을 확인하며, 작은 외형만으로 인덕터를 교체하지 않는다. |

## 2. 전원 선택·USB-C·레일 판정 — 9개

[Communicator 회로 §3~4](../../docs/hardware/r1/communicator-circuit.md)에 연결된다. 전원 선택 상태와 PGOOD, 하락 검출 지연과 회복 지연을 서로 구분한다.

| 저장 PDF / 전체 쪽수 | 정확한 참조 쪽·절 | 회로 반영 또는 배제 사유 |
|---|---|---|
| [tps629210](pdf/tps629210.pdf#page=11) / 51 | 3쪽 핀, 5~6쪽 전기 특성, 11쪽 §8.3.1 MODE, 12~13쪽 §8.3.3/Table 8-2 VSET, 20~22쪽 L/C 선정, 40쪽 배치 | SYS3V3: 249k VSET, 27.4k MODE, 2.2µH/22µF 출발값. `use`의 15~17쪽을 VSET 표 위치로 그대로 인용하지 않는다. 임의 bulk 추가는 재검증한다. |
| [murata-dfe252012](pdf/murata-dfe252012.pdf#page=1) / 1 | 1쪽 DFE252012P 규격·2.2µH 품목·치수·권장 패드 | 시스템 buck의 2.2µH 후보와 land 참조. 실제 공급 MPN의 전류·높이·유효 L 확인이 필요하다. |
| [tps2116](pdf/tps2116.pdf#page=3) / 25 | 3쪽 핀, 4~6쪽 정격·전기 특성, 12~15쪽 §7.6/§8 우선선택·응용, 17쪽 배치 | AUTO5V 우선/USB 보조 mux와 역류 차단. ST를 PGOOD로 쓰지 않으며 전환 중 droop·유한 역류 응답을 시험한다. |
| [tps2553](pdf/tps2553.pdf#page=13) / 33 | 3쪽 핀, 4~6쪽 정격, 13~14쪽 §8.5.1/Fig. 22 ILIM, 16~21쪽 응용, 30~32쪽 DBV 외형·land·paste | USB 약1A 및 GPS 전류 제한. RILIM 오차/최소·최대를 반영한다. current limit는 과전압 보호가 아니며 무조건 자동 재시도 회로를 복제하지 않는다. |
| [tusb320lai](pdf/tusb320lai.pdf#page=3) / 38 | 3쪽 핀, **4쪽 VDD2.7~5.0V**, 10쪽 모드 표, 11쪽 §7.2.2 전류 광고, 14쪽 §7.3.3 dead battery, 26~29쪽 UFP 응용·전원·배치 | PORT=GND, ADDR=NC GPIO sink와 내부 Rd. U16 USB전용3.3V로 감지부를 공급하며 VBUS 직결 금지. 외부 Rd 중복·default-current 기동·고전압 PD 협상은 채택하지 않는다. |
| [tps7a20](pdf/tps7a20.pdf#page=3) / 63 | 3~4쪽 패키지별 핀, 5~7쪽 정격, 27~31쪽 §7 커패시터·손실·응용/배치 | USB CC 사전감지/PHY/GPS 및 원격 mic LDO. USB CC용은3k로최소1mA 부하를 두어6쪽 ±1.5% 조건을 맞춘다. 각 도메인을 합치지 않는다. |
| [tlv803e](pdf/tlv803e.pdf#page=4) / 52 | 4~5쪽 DPW 포함 핀, 8~9쪽 임계·reset 시간, 17~19쪽 reset 동작, 20쪽 응용 | SYS/PHY 3.3V reset의 A30 3.08V, release 130~270ms 기준. USB 선연결 뒤 PHY 기동도 초기화하며 MCU 내부 BOR만으로 대체하지 않는다. |
| [tps3700](pdf/tps3700.pdf#page=4) / 27 | 4쪽 핀, 6~7쪽 정확도·타이밍, 13~18쪽 분압·응용 | PROTECTED_VBAT 약8V 판정. 임계·누설·저항 오차를 포함한다. 최종 AUTO5V의 좁은 창은 별도 TPS3890이 맡는다. |
| [tps3890](pdf/tps3890.pdf#page=5) / 27 | 3쪽 핀, 5쪽 §7.5~7.6, 12~16쪽 지연·동작·응용, 24~26쪽 DSE 외형·land·paste | AUTO5V의 1.15V 기준 supervisor와 CT 회복 지연. 하락 지연 max 미명시·작은 collapse 여유를 남은 시험 조건으로 유지한다. |

## 3. CAN 물리계층·독립 TX 차단 — 12개

[Communicator 회로 §5~6](../../docs/hardware/r1/communicator-circuit.md)의 근거다. 수신 허용과 차량 송신 허용은 별개이며, 데이터시트의 기능만으로 차량별 bus 종류나 고장 안전성을 확정하지 않는다.

| 저장 PDF / 전체 쪽수 | 정확한 참조 쪽·절 | 회로 반영 또는 배제 사유 |
|---|---|---|
| [tcan1046av](pdf/tcan1046av.pdf#page=4) / 43 | 4~5쪽 §7 핀, 6~12쪽 정격, 20~25쪽 핀 동작/standby, 26~30쪽 응용·배치 | CAN1/2 PHY. DYY14의 5=GND2, 7=RXD2, 8=STB2, 11=VIO를 반영. reset 중 TXD/STB 외부 pull-up을 유지한다. |
| [tcan1046-evm](pdf/tcan1046-evm.pdf#page=4) / 18 | 4쪽 §1.2.1 회로, 7쪽 §2.1 전원 구성 | bypass와 CAN FD 종단 참고. 차량 중간 노드의 split termination은 DNP이며 EVM 종단/CMC 구성을 전부 복제하지 않는다. |
| [max3055](pdf/max3055.pdf#page=11) / 19 | 1쪽 기본회로, 2~6쪽 정격, 11쪽 핀 설명, 12쪽 INH/기능도, 15~16쪽 모드 표·bus 종단, 17쪽 EMI/반사 | 검증된 저속 FT CAN3에만 사용. BATT/WAKE/INH/ERR과 RTH·RTL 분산 종단을 반영하며 CANH–CANL 120Ω 및 FD 운용은 배제한다. 4.7k는 전체망 100Ω을 혼자 구성한다는 뜻이 아니다. |
| [esd2can24](pdf/esd2can24.pdf#page=3) / 26 | 3쪽 핀, 4~6쪽 정격·용량, 12~13쪽 §7~9 응용·배치 | CAN 포트 ESD 보호와 짧은 return. ESD 정격을 차량 load-dump 전력 흡수 능력으로 해석하지 않는다. |
| [sn74lvc2g125](pdf/sn74lvc2g125.pdf#page=4) / 30 | 4쪽 핀, 5~7쪽 정격·Ioff, 11쪽 기능, 12~14쪽 응용/OE·배치 | FD TX/STB와 GNSS 전원 도메인 격리. 상대 rail과 OE 기본 pull을 함께 설계하며 단순 버퍼 추가만으로 전원 순열 시험을 대신하지 않는다. |
| [sn74lvc2g17](pdf/sn74lvc2g17.pdf#page=3) / 36 | 3쪽 핀, 4~5쪽 정격·입력/Ioff, 8~11쪽 기능·응용 | MAX3055 RXD/ERR 및 도메인 sense의 5V tolerant Schmitt 입력. 무전원 안전 근거 없는 단순 저항 분압안을 배제한다. |
| [sn74lv1t125](pdf/sn74lv1t125.pdf#page=4) / 26 | 4쪽 핀, 5~6쪽 정격·입력 임계, 12~13쪽 기능·전원 | **교체·미채택**: 과거 FT gate 후보 감사용. 별도 PHY3V3의 active-low OE pull-up은 해당 rail 소실 시 fail-open이므로 사용 금지. |
| [sn74ahct1g126-q1](pdf/sn74ahct1g126-q1.pdf#page=3) / 23 | 3쪽 핀, 4~5쪽 VCC3~5.5V·VIH2V·입력누설, 8쪽 active-high OE/필수 pull-down, 13쪽 주문 MPN, **17~19쪽 DBV** 도면(20~22쪽은 DCK) | 수정 U28/U29, AUTO5V 공급·OE마다1k GND. 주문명 CAHCT1G126DBVRQ1을 보존한다. 출력 Ioff를 추정하지 않는다. |
| [sn74lvc1g04](pdf/sn74lvc1g04.pdf#page=3) / 47 | 3쪽 핀, 4~6쪽 정격, 10~12쪽 진리표·응용 | TX_PERMIT→active-low OE 및 논리 극성 변환. reset/무전원 외부 pull을 생략하지 않는다. |
| [sn74lvc1g11](pdf/sn74lvc1g11.pdf#page=3) / 37 | 3쪽 핀, 4~5쪽 정격, 9쪽 진리표, 10~12쪽 응용 | rail/reset/물리 ARM/watchdog의 hardware AND에 반영. 소프트웨어 flag 하나로 permit을 우회하지 않는다. |
| [sn74lvc1g74](pdf/sn74lvc1g74.pdf#page=4) / 31 | 4쪽 핀(Q=5, 반전 Q=3), 6~8쪽 동작·타이밍, 10쪽 비동기 clear 진리표 | 고장 시 arm latch clear, 회복 뒤 새로운 STM 상승 edge로만 재무장. watchdog 회복에 따른 자동 TX 복귀를 배제한다. |
| [tps3431](pdf/tps3431.pdf#page=3) / 31 | 3쪽 핀, 5~7쪽 전기·타이밍, 9~13쪽 watchdog/기동·시간 설정, 17~18쪽 가변 시간 응용 | 외부 WDI health 감시와 WDO latch 해제. 120pF 출발값의 오차를 계산하며 무조건 동작하는 timer/DMA 토글을 건강성 증거로 쓰지 않는다. |

## 4. MCU·무선 모듈·커넥터 — 7개

[핀맵·FW 계약](../../docs/hardware/r1/firmware-pinmap.md)에 적용한다. GPIO 번호, chip pad, module pad와 케이블 mating face를 구분한다.

| 저장 PDF / 전체 쪽수 | 정확한 참조 쪽·절 | 회로 반영 또는 배제 사유 |
|---|---|---|
| [stm32g474](pdf/stm32g474.pdf#page=49) / 236 | 49쪽 §4.1 UFQFPN48, 56~72쪽 Table 12 핀, 73~79쪽 Table 13 AF, 82~88쪽 정격/전원, 117~118쪽 HSE, 133쪽 NRST, 203~205쪽 §6.2 외형·권장 footprint | DS12288 Rev 6 저장본. STM32G474CEU6의 3 FDCAN/UART/SWD·전원·EP49=GND에 반영. 다른 package 표나 PG10 GPIO 설정을 복사하지 않는다. AN5093 저장본을 확보했다는 뜻은 아니다. |
| [esp32s3-mini](pdf/esp32s3-mini.pdf#page=10) / 53 | 10~12쪽 §3 핀, 14~16쪽 boot/reset, 27~29쪽 정격/소비전류, 39~41쪽 모듈·주변회로, 43~46쪽 치수·land/배치 | Communicator N4R2의 pad/USB/UART/INS 연결과 RF keepout. PSRAM용 핀을 회수하지 않으며 WROOM pad 번호를 혼용하지 않는다. |
| [esp32s3-wroom](pdf/esp32s3-wroom.pdf#page=10) / 53 | 10~12쪽 §3 핀, 14~16쪽 boot/reset, 27~29쪽 정격/소비전류, 39~41쪽 모듈·주변회로, 43~46쪽 치수·land/배치 | Bridge N8R2, native USB·BOOT/PAIR 최소 보드에 반영. 별도 CAN PHY·TX 권한이나 SD 회로 추가 근거로 쓰지 않는다. |
| [abracon-abm8](pdf/abracon-abm8.pdf#page=1) / 2 | 1쪽 표준 규격·주문 옵션, 2쪽 외형·권장 패드 | 16MHz/CL18pF HSE crystal 출발값. 부하용량·stray·drive limit를 확인하며 STM의 8MHz 예시 값을 그대로 복제하지 않는다. |
| [gct-usb4105](pdf/gct-usb4105.pdf#page=1) / 2 | 1쪽 전기 정격·접점·기계/PCB 도면 | USB-C receptacle의 A/B 접점·shield·패드 대응. 기계적 전류 정격이 CC 광고나 USB 입력 예산을 대신하지 않는다. |
| [jst-gh](pdf/jst-gh.pdf#page=2) / 6 | 1쪽 정격, 2쪽 PCB/조립 도면, 3쪽 housing/header·No.1 표시, 6쪽 품번 체계 | CAN/GNSS/PPS/mic 하네스의 GH 접점·pin1 방향. 기계 탭 MP는 신호 pad가 아니며 PCB top view와 mating face를 뒤집어 확인한다. |
| [jst-xh](pdf/jst-xh.pdf#page=1) / 9 | 1쪽 3A/AWG22 정격, 2쪽 PCB/조립, 3~5쪽 contact/housing/header | 차량 입력 XH2의 극성·crimp·기계 치수. 차량 OEM 커넥터 pinout 근거가 아니며 외부 퓨즈를 생략하지 않는다. |

## 5. GNSS·INS·기압계 — 5개

[위치·관성 하드웨어](../../docs/hardware/r1/navigation-hardware.md)의 선택 근거다. GNSS 모델/firmware와 PPS·프로토콜 호환성은 실물 조합 시험 전까지 후보 상태다.

| 저장 PDF / 전체 쪽수 | 정확한 참조 쪽·절 | 회로 반영 또는 배제 사유 |
|---|---|---|
| [xsens-mti1-current](pdf/xsens-mti1-current.pdf#page=14) / 96 | PDF 14~18쪽(인쇄 11~15) 핀/strap, PDF 19~27쪽(16~24) MTSSP/SPI, PDF 34쪽(31) barometer·36쪽(33) outage, PDF 41~44쪽(38~41) 정격/footprint, PDF 48쪽(45) 세대별 외형, PDF 81~88쪽(78~85) 전원·연결, PDF 93쪽(90) footprint | 2025-04-23 매뉴얼의 MTI-7-5A-T v5. SPI mode3/≤2MHz·filler/guard·open-drain reset, AUX SPI BMP384, VDDA 필터에 반영. GNSS outage 45초 이후 위치/속도 중단을 명시하고 일반 AHRS·무제한 DR로 확대하지 않는다. |
| [xsens-gnss](pdf/xsens-gnss.pdf#page=16) / 31 | 7쪽 §2.3 지원 수신기/인터페이스, 16~17쪽 §4 u-blox 설정, 20~21쪽 §7 NMEA, 22~25쪽 상태·동기·안테나 | MTAN001 Rev A의 GNSS 설정 ownership와 상태 검증 참고. F9P/MTi 실제 버전 조합을 무조건 호환으로 승격하지 않는다. 이 문서는 쪽수 +3 보정 대상이 아니다. |
| [bmp384](pdf/bmp384.pdf#page=45) / 58 | 6~8쪽 §1~2 정격, 41~44쪽 SPI/타이밍, 45~46쪽 §6 핀·SPI 연결, 48쪽 §7.1~7.2 외형·land, 51~53쪽 실장 | MTi AUX SPI 전용 10pad 센서와 100nF bypass. I²C 스캔 대상이 아니며 bottom drawing을 PCB top view와 대조한다. pressure port 코팅/접착제 차폐는 금지한다. |
| [holybro-f9p](pdf/holybro-f9p.pdf#page=2) / 5 | 2쪽 SKU12018 규격, 3쪽 Pin Map, 4~5쪽 케이스·안테나 치수 | H-RTK F9P Helical UART형 출발점. URL 파일명은 V1.0이지만 **저장 본문은 2020-11 V1.1**이다. GH10 데이터와 GH6 PPS를 분리하고 DroneCAN형·다른 SKU와 혼용하지 않는다. |
| [we74279279](pdf/we74279279.pdf#page=1) / 7 | 1쪽 전기 특성·권장 land, 2쪽 임피던스/온도 derating | MTi v5 VDDA 필터의 0402/600Ω@100MHz ferrite 참고. 전원 필터의 DC 저항·전류를 검증하며 CAN CMC로 전용하지 않는다. |

## 6. Controller·RTC·원격 마이크 — 7개

[Bridge·Controller·마이크](../../docs/hardware/r1/bridge-controller-microphone.md)에 적용한다. raw I²S 장거리 배선, 카메라와 GPIO 동시 사용, T5848의 3.3V 직접 구동은 배제한다.

| 저장 PDF / 전체 쪽수 | 정확한 참조 쪽·절 | 회로 반영 또는 배제 사유 |
|---|---|---|
| [waveshare-controller](pdf/waveshare-controller.pdf#page=1) / 1 | 1쪽 전체 schematic 중 J8 확장 헤더·camera/audio GPIO·RTC 전원 회로 | 기존 Controller를 복제하지 않고 최소 mating 어댑터를 만든다. GPIO38/39/40 사용 시 카메라를 비활성화/분리하고 J8 성별·높이·삽입 방향은 실물 확인한다. |
| [pcf85063](pdf/pcf85063.pdf#page=22) / 65 | 5쪽 §7.2 핀, 22쪽 §8.3.1.1 OS flag, 35쪽 §9.5.1~2 주소/읽기·쓰기, 46쪽 응용 | Waveshare가 연결한 PCF85063A Rev 7 원문. 기존 RTC 0x51을 재사용하고 OS flag·날짜·backup 유지/readback을 확인한다. 정확한 보드 suffix나 시간 유효성을 단순 I²C 응답만으로 단정하지 않는다. |
| [t5848](pdf/t5848.pdf#page=7) / 42 | 5쪽 HQ 조건, 7쪽 I²S 전기/타이밍, 8쪽 최대 정격, 10쪽 핀, 30~31쪽 I²S 형식, 35쪽 bypass, 37쪽 land/paste, 39쪽 package | DS-000479 Rev 1.0. 1.8V, pin7=VDD/pin6=SCK, LR=GND와 음향 NPTH를 적용. R1은 32kHz/64fs(2.048MHz); `use`의 48kHz를 현재 설정으로 옮기지 않는다. 16kHz/64fs는 HQ 범위 밖이며 지연·유효 bit를 실측한다. |
| [sn65lvds1](pdf/sn65lvds1.pdf#page=3) / 44 | 3쪽 driver/receiver 핀, 4~8쪽 정격·전기/스위칭, 14~17쪽 기능, 19~27쪽 응용·종단/전송선 | SN65LVDS1/2로 BCLK·WS·DATA 세 차동 pair를 구성하고 receiver 끝에만 100Ω. 수m raw I²S 및 RJ45/PoE 오접속 가능 구성을 배제한다. 3m는 SI 승인 길이가 아닌 목표다. |
| [sn74axc1t45](pdf/sn74axc1t45.pdf#page=3) / 45 | 3쪽 핀, 5~6쪽 정격, 17쪽 §7.3.4 Ioff, 18~20쪽 고정 방향/단방향 응용 | mic의 1.8↔3.3V 고정 방향 변환과 전원 도메인 분리. LVDS 자체가 mic VDD 정격을 해결한다고 가정하지 않는다. |
| [tpd2e2u06](pdf/tpd2e2u06.pdf#page=3) / 23 | 3쪽 핀/정격, 4쪽 용량·전기 특성, 10~12쪽 응용·배치 | USB/GNSS/LVDS 커넥터 근처 ESD 보호. 용량·return 경로를 포함해 신호 품질을 확인한다. |
| [bourns-psmf](pdf/bourns-psmf.pdf#page=1) / 7 | 1쪽 품목 전기 정격, 2쪽 온도 derating, 3쪽 trip 곡선, 4쪽 리플로 조건 | MF-PSMF010X-2 마이크 전원 PTC: 100mA hold/300mA trip 출발점. 정밀 전류 제한기·즉시 차단기로 해석하지 않으며 고온 hold·저항·단락 열을 시험한다. |

## 7. 비교용으로 보존한 미채택 부품 — 3개

저장돼 있다는 이유로 현재 BOM의 실장 부품으로 간주하지 않는다.

| 저장 PDF / 전체 쪽수 | 정확한 참조 쪽·절 | 배제 사유 |
|---|---|---|
| [sn74lvc125a](pdf/sn74lvc125a.pdf#page=3) / 37 | 3쪽 핀, 4~6쪽 정격, 9~12쪽 tri-state/OE 응용 | 과거 4채널 TX gate 비교 근거. 현재 R1은 SN74LVC2G125/SN74AHCT1G126-Q1이므로 이 문서를 현재 buffer pinmap에 적용하지 않는다. |
| [sn74ahct1g125](pdf/sn74ahct1g125.pdf#page=3) / 26 | 3쪽 핀, 4~5쪽 정격·전기 특성, 8~11쪽 기능·응용 | FT TX/EN 비교 후 미채택. 명시되지 않은 Ioff/무전원 보호를 부품 계열명에서 추정하지 않는다. |
| [tps3808](pdf/tps3808.pdf#page=6) / 39 | 6~7쪽 전기 특성, 10~13쪽 임계·히스테리시스·reset 동작, 14~15쪽 응용 | Rev N 비교본. 좁은 FT 5V 판정 창의 최악 정확도·히스테리시스 조건 때문에 미채택; 최종 AUTO5V 판정은 TPS3890을 참조한다. |

## 8. 저장되지 않은 원문과 웹 열람 근거

아래 항목은 **56개 저장 PDF에 포함하지 않는다**. manifest의 `failures`는 AN5093/단독 schematic 두 항목만 담으므로, 그 배열만 보고 최신 개정·land 원문이 모두 확보됐다고 판단하면 안 된다. 후속 적대적 리뷰 수정에서 BUK7Y12와 AHCT1G126-Q1 원문2개를 추가 확보했다.

| 원문·공식 경로 | 확인 범위와 남은 제한 |
|---|---|
| [MAX20039/MAX20040 Rev 16](https://www.analog.com/media/en/technical-documentation/data-sheets/max20039-max20040.pdf) | 확인된 공식 Rev 16(4/25), 20쪽은 **바이너리 미확보**. 저장 Rev 15와 구분한다. 특히 2~3쪽 절대최대정격/관련 Note 1·2와 20쪽 개정 이력을 다시 확인해야 한다. `max20040-rev16.pdf`는 존재하지 않는다. |
| [ST AN5093](https://www.st.com/resource/en/application_note/an5093-getting-started-with-stm32g4-series--hardware-development-boards-stmicroelectronics.pdf) | 이전 웹 열람에서 Rev 2(2019-10), 35쪽 확인. 전원 6~13쪽, HSE 20쪽, debug·권고·참조회로 25~33쪽이 사용 범위다. **로컬 바이너리 미확보**이므로 이번 Windows PDF 검증 대상이 아니다. |
| [ADI 패키지/land 원문 포털](https://www.analog.com/en/resources/packaging-quality-symbols-footprints/package-index.html) — 21-100068 / 90-0409 | MAX 저장본 3쪽이 outline 21-100068과 land 90-0409를 지정한다. **land 90-0409 원문 미확보**이며 치수 overlay·pad1·EP/paste·via 승인은 남아 있다. 후보 KiCad footprint를 제조사 land 검증 완료로 표시하지 않는다. |
| [MAX20040 단독 schematic](https://www.analog.com/media/en/technical-documentation/eval-board-schematic/max20039_40_evkit_schematic.pdf) | 이전 웹 열람의 1쪽 자료이나 **로컬 바이너리 미확보**. 저장 EVM 4쪽은 bootstrap 근거로 사용할 수 있지만, 이를 추출해 원본 단독 PDF로 대체하지 않는다. |
| [MAX20090/MAX20090B 공식 PDF](https://www.analog.com/media/en/technical-documentation/data-sheets/MAX20090-MAX20090B.pdf#page=29) | 이번 웹 열람에서 Rev 9(3/24), 30쪽 중 **29쪽 Package Information 표** 확인. T2044+4C/21-100172와 T2044Y+4C/21-100068이 land 90-0409를 공유한다. **PDF 바이너리는 미확보**이며 shared-land ID의 교차 근거일 뿐 전체 도면 치수·MAX20040 footprint 승인 또는 MAX20090 회로 채택 근거가 아니다. |

## 9. TI·ST 포럼과 현장 사례

다음은 제조사 포럼의 사용자 측정·지원 답변이다. 데이터시트/정격의 대체 정본이나 CANView 실측 결과가 아니며, 적용 부품·회로·증상 조건을 함께 읽는다. 웹 링크만 보존하며 PDF 확보 목록에 넣지 않는다.

| 근거 링크 | 반영·주의 |
|---|---|
| [TI E2E — LM7480-Q1 DGATE Voltage unstable](https://e2e.ti.com/support/power-management-group/power-management/f/power-management-forum/1575206/lm7480-q1-dgate-voltage-unstable) | TI 답변은 EVM CS 15nF를 1µF로 교정하고 사용자는 A pin 가까이에 적용 후 개선을 보고했다. R1 CS 1µF의 근거다. 글 중 charge-pump 100nF→1µF 시도는 효과가 없었다고 보고됐으므로 CS 교정과 혼동하지 않는다. |
| [TI E2E — TUSB320 VBUS 직접 공급 문의](https://e2e.ti.com/support/interface-group/interface/f/interface-forum/936742/tusb320-maximum-recommended-vdd-is-5v-where-the-usb-voltage-may-be-up-to-5-25v-can-the-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) | TI 지원자가 VDD 권장 범위 준수를 위해 외부 LDO를 권고한다. 수정 R1의 USB_CC3V3 사전 공급과 연결되며 absolute max6V를 정상 운용 상한으로 쓰지 않는다. |
| [ST Community — PG10-NRST를 NRST로 구성하는 방법](https://community.st.com/stm32cubemx-mcus-29/how-we-should-do-to-configure-the-pg10-nrst-pin-as-nrst-we-just-choise-gpio-input-60075) | PG10/NRST 기능이 option byte와 관련됨을 확인하는 사례. R1은 NRST 기능을 보존한다. ST 답변도 RM0440 개정에 따라 절 번호가 바뀌었음을 지적하므로 옛 게시글 절 번호를 현재 RM 절로 복사하지 않는다. |
| [ST Community — STM32G474RE PG10 MCO 사례](https://community.st.com/stm32cubemx-mcus-29/how-to-use-mco-at-pg10-nrest-pin-with-stm32g474re-init-code-from-stm32cubemx-always-works-at-pa8-pin-as-mco-function-613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) | PG10를 GPIO/MCO로 돌리면 외부 reset과 debugger의 hardware-reset 접속을 잃을 수 있다는 사용자 사례다. 해당 전환 코드를 R1에 적용하지 않는다. |

GNSS 하네스의 최신 제품별 접점 설명은 [Holybro 공식 UART F9P pinout](https://docs.holybro.com/gps-and-rtk-system/f9p-h-rtk-series/standard-f9p-uart/pinout)을 함께 참조한다. 기존 회로결정의 GH10-5=SDA/GH6-5=PPS를 확인하는 경로이며, 판매 옵션·구매품 도통 검사를 대체하지 않는다.

## 10. 실제 읽음·검증 범위와 저작권

Windows native KiCad Python 3.11.5에 `.tools/hardware-python`의 PyMuPDF 1.26.4를 로드해 최초54개 파일의 `%PDF`, 바이트 수, SHA-256과1,709쪽 문자 추출을 검증했다. 이후 추가 원문2개를 포함한56개/1,745쪽 재검증은 [검증 기록](../../docs/hardware/r1/verification.md)에 남긴다. 색인에는 절·표제와 선택한 핵심 문구를 확인한 범위를 기록했다. **전체 원문 정독, 모든 표 셀·각주 대조, 모든 그림 육안 검토 또는 land 치수 overlay를 끝냈다는 뜻은 아니다.**

문자 추출이 비어 있는 쪽은 `sn74lvc125a` 29쪽, `sn74lvc1g04` 26쪽, `tlv803e` 42쪽, `tps3431` 27쪽, `tps7a20` 56쪽의 5쪽이다. 파일 손상으로 단정하지 않았고 이 쪽들의 OCR/도면 검증 완료도 주장하지 않는다. 제조사 package 도면·부품 변형·reflow/paste와 전원 정격 최악 조건의 최종 승인은 [제작 전 조건](../../docs/hardware/r1/verification.md)에 남긴다.

공개 다운로드 가능 여부와 재배포 허락은 같은 의미가 아니다. **PDF의 저작권은 각 제조사·원저작권자에게 있으며 CANView 프로젝트 라이선스가 적용되지 않는다.** 원문 고지·상표·개정 표시를 보존하고 각 문서의 이용/재배포 조건을 따른다. 미러 저장본이 공식 서버 파일과 바이트 단위로 같다는 검증은 별도이며, 이 색인의 해시 일치는 저장본과 manifest 사이의 무결성만 뜻한다.

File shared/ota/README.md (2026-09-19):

# OTA portable parser 구현 중

[T-007](../../docs/tasks/T-007-ota-container.md)의 C99 내부 primitive다. 현재
`src/cbor_head.c`와 `src/cbor_document.c`는 head와 문서 구조를 검사하며
완전한 `.cvota` verifier가 아니다.
SDK/HAL/RTOS·heap·전역 가변 상태·ISR·Flash writer 의존성은 없다.

## Schema와 서명 전 JSON 입력

[wire 계약](../../protocol/schema/ota-container-v2.yaml)은 기존 C/Python의 CVOTA002
header·정렬·enum·native metadata 배정을 기록한다. [JSON schema](../../schema/cvota-v2.schema.json)는
packager 작성 입력이며 wire JSON이 아니다. `x-cbor-key` 순서로 integer-key map을 만들고
package_id/sha256의 소문자 hex를 CBOR byte string으로 변환한다. JSON schema는 기본
구조·범위를 기술하며 ABI 교차 제약·중복 target·총길이는 기존 typed 검사기가 맡는다.
JSON 숫자는 정수 literal만 허용한다. 소수/지수 표현과 NaN/Infinity를 거부하며
u64를 문자열이나 JavaScript Number로 변환하지 않는다.

서명 전 CBOR는 다음 명령으로 생성한다. Python 표준 JSON parser와 기존 typed
검사를 재사용하며 새 JSON Schema 엔진이나 암호 구현을 추가하지 않았다.

```powershell
python -B tools/ota/manifest_json.py input.json output.cbor
```

입력은 최대32KiB UTF-8이며 duplicate/unknown key, 경로/URL/Flash 주소 필드를 허용하지
않는다. 출력은 최대16KiB CBOR이고 기존 파일을 덮어쓰지 않는다. 성공 메시지의
`UNSIGNED_MANIFEST`는 인증·native image/hash 검증이나 완전한 `.cvota` 생성이 아니다.
다음 packager 단계에서 실제 native image 검증·서명과 결합해야 한다. 현재 schema도
최종 독립 리뷰 전 구현 후보이며 배포 승인을 뜻하지 않는다.

## 바깥 컨테이너 조립·검사

`tools/ota/container.py`는 위 CBOR의 외부 detached raw P256 서명과 image들을 조립하고,
신뢰된 공개키/identity로 manifest·전체 길이·zero padding·image SHA-256을 검사한다.
기존 `cryptography`와 typed 검사기를 재사용하며 개인키를 생성·읽기·저장하지 않는다.
새 파일만 만들고 기존 출력은 덮어쓰지 않는다. 입력 검증 실패 시 출력 파일을 만들지
않으며 OS 쓰기 실패의 부분 파일도 성공으로 표시하지 않는다.

```powershell
python -B tools/ota/container.py --public-key trusted.pem --role 1 --board BOARD --layout LAYOUT --epoch 7 --key-id 11 assemble input.json signature.bin output.cvota esp.bin stm.bin
python -B tools/ota/container.py --public-key trusted.pem --role 1 --board BOARD --layout LAYOUT --epoch 7 --key-id 11 check output.cvota
```

서명 입력은 정확한 CBOR이고 raw 서명은 big-endian `r[32] || s[32]`다. image 순서는
manifest와 같아야 한다. 성공은 `MANIFEST_AND_HASHES_MATCHED`일 뿐 native image 서명,
로컬 compatibility/floor, Flash 쓰기·설치 승인이 아니다. Native-aware 검사는 아래
`--native` 경로를 사용하며 target owner 연결은 남아 있다. host 입력은 format 상한으로 제한하며 MCU에는
전체 package를 메모리에 올리지 않는다.

### 일반 native 서명·metadata 검사

`--native`를 주면 기존 조립/검사 명령에서 outer 검증 뒤 공식 espsecure5.4.0의
RSA3072 검증 및 MCUboot v2.4.0 imgtool의 SHA256/P256 검증을 실행한다.
ESP image 구조·checksum·선택적 digest는 공식 esptool parser를 사용한다.
MCUboot는 기존 C 검사기와 같은 비압축·비암호화512B header/176B protected TLV
profile로 제한한 뒤 공식 verifier에 넘긴다. CANView 고정168B metadata와 version을
signed manifest에 대조하며 release_sequence는 정수 u64 그대로 비교한다.
package 안의 key/identity를 신뢰 root로 채택하지 않는다.

```powershell
python -m pip install --only-binary=:all: --require-hashes -r tools/requirements-ota-native-build.lock
python -m pip install --no-build-isolation --require-hashes -r tools/requirements-ota-native.lock
python -B tools/ota/container.py --public-key trusted.pem --role 1 --board BOARD --layout LAYOUT --epoch 7 --key-id 11 --native --esp-public-key esp-public.pem --stm-public-key stm-public.pem --mcuboot-root C:/cv/mcuboot-2.4.0 check output.cvota
```

같은 global 옵션 뒤에 `assemble input.json signature.bin output.cvota esp.bin stm.bin`을
사용하면 모든 요청 검증을 마친 뒤에만 새 파일을 만든다. `--native` 없이 native key
옵션을 주면 조용히 무시하지 않고 실패한다. ESP/STM key는 해당 target이 있을 때 필수다.
Controller/Bridge는 ESP 공개키만 필요하며 STM checkout을 요구하지 않는다.
MCUboot checkout은 toolchain manifest의 commit 및 clean 상태를 확인한다.
서명키 생성이나 signing service는 추가하지 않는다. 공식 도구로 이미 서명한 image와
외부 detached manifest 서명을 받아 조립·검증하는 경계다.

성공 출력은 `NATIVE_SIGNATURES_AND_METADATA_MATCHED`이며 로컬 호환성/floor·설치
승인은 여전히 `NOT_VERIFIED`다. Host 임시 디렉터리에는 image와 공개키만 기록한다.
공식 verifier의 실패·timeout·의존성 누락은 실패이며 Flash/serial/provisioning을 호출하지 않는다.
입력 길이는 기존 manifest 상한을 따르지만 host의 image 복사·SDK 객체·subprocess를
포함한 peak RAM/WCET 보장은 아니다. 모든 MCU timing/heap/HIL gate와 구분한다.

Windows CPython3.14용 새 lock은 공식 PyPI의 esptool sdist와 dependency wheel hash를
고정한다. esptool에는 wheel이 없어 고정 setuptools82.0.1을 먼저 설치한 후 build
isolation을 끈다. SDK를 임의 patch하거나 다른 암호 구현으로 바꾸지 않는다.
`ota-native-container` CTest는 보존 golden, 다른 identity의 ESP3역할, u64 경계,
outer-valid/native-invalid·metadata mismatch·잘못된 key·기존 출력 보존을 검사한다.

## Head 검사

- 입력은 호출 동안만 빌리고 저장하지 않는다. output과 입력은 겹치면 안 된다.
- 최대 9 byte만 읽는다. 모든 argument는 unsigned 64-bit이며 최소 길이만 허용한다.
- truncated prefix는 INCOMPLETE, reserve/indefinite·비최소 길이는 MALFORMED다.
- 허용 major type은 unsigned/bytes/text/array/map이다. 음수/tag/float/simple은 거부한다.
- head 함수는 본문을 검사하지 않는다. 문서 검사는 아래 별도 함수를 사용한다.
- OK는 head 파싱만 성공했다는 뜻이며 erase/write/PREPARED/boot selector 권한이 아니다.

바이트 계약의 근거는 [RFC 8949 §3·§4.2.1](https://datatracker.ietf.org/doc/html/rfc8949#section-4.2.1)이다.

## 문서 구조 검사

`canview_ota_cbor_validate()`는 root map 한 개를 고정 크기 stack으로 순회한다.
16 KiB, container 깊이8(root=1), key/value/container 합계2048 item을 상한으로
한다. 모든 map의 unsigned integer key는 엄격한 오름차순이고 중복·역순을
거부한다. UTF-8 scalar, payload truncation, trailing byte도 검사한다.
integer key profile은 내부 구현 후보이며 최종 manifest 필드 schema를 확정한
것이 아니다. 서명 대상의 의미·required field·role/board/layout은 검사하지 않는다.

입력은 호출 동안 읽기만 하며 보존하지 않는다. 재귀·heap·callback·공유 가변
상태가 없어서 불변 입력을 사용하는 독립 호출은 thread-safe다. 실행량은 byte와
item 수에 선형이지만 실제 MCU 시간·전체 call-chain stack은 별도 측정해야 한다.
부분 입력은 INCOMPLETE이며 CBOR 검사기 자체는 내부 수신 상태를 유지하지 않는다.
부분 수신은 아래 prefix 조립기가 담당한다. OK는 구조 검사 성공일 뿐 Flash writer를 호출하지 않는다.

`tools/ota/cbor.py`는 별도 Python encoder/decoder이며 동일 제한·반환 분류를
시험한다. host 객체와 출력 buffer를 사용하므로 C의 무할당 구현과 구분한다.
`tests/ota/`의 CTest 세 개는 uint64 경계·전체 첫 byte 공간·UTF-8·중첩·item/byte
상한·잘린 prefix·고정 seed 변이·순환 Python 입력을 검사한다. 재현 명령은
host build 뒤 `ctest --test-dir build/host-debug -R ota-cbor --output-on-failure`다.

상위 manifest schema·서명 검사·body streaming은 아래 절의 구현을 사용한다.
완전한 native signed packager/golden·정상 target 연결과 최종 검증은
남아 있다. 현재 production app은 이 primitive를
호출하지 않으며 physical/HIL은 NOT_RUN이다. 내부 header는 최종 public API가 아니다.

## 서명 prefix 연결 후보

`canview_ota_prefix_init/feed/finish()`는 caller의 고정16KiB급 buffer에서 prefix만
조립한다. 단일 owner가 task stack 밖에 보관하며 입력 chunk는 호출 중만 빌린다.
호출당 최대16KiB 복사·전체 최대16472B이고 heap/암호 callback은 없다. body가 같은
chunk에 있으면 `consumed` 뒤를 보존해 다음 단계에 전달한다. NULL/겹침/미초기화
인자는 context를 변경하지 않으며 길이·중복·누락 오류는 init 전까지 보존한다.
timeout/연결 종료 시 owner가 init으로 부분 입력을 폐기해야 한다. 자동 재개나 시간
판정은 하지 않는다. 완료 OK는 미인증 byte 조립일 뿐이며 기존 body open의 서명·정책
검사를 통과해야 한다. CTest `ota-prefix-stream`, `ota-container`가 수신 경계와
실제 P256/SHA-256 CNG body 연결·borrowed buffer 수명을 검사한다.

`src/envelope.c`는 작은 header+CBOR+서명 prefix를 검사한다. `tools/ota/envelope.py`
는 같은 prefix 뒤에 image bytes를 순서대로 붙이는 조립 함수다. 압축/파일시스템
경로/임의 Flash 주소는 없다. 아래 byte layout은 T-007 내부 구현 후보이며 전체
manifest schema와 최종 호환성 계약의 review 전에는 배포 포맷으로 사용하지 않는다.

| offset | 크기 | 내용 |
|---|---|---|
| 0 | 8 | ASCII `CVOTA002` |
| 8 | 2 | format version2 |
| 10 | 2 | header 길이24 |
| 12 | 4 | CBOR manifest 길이1..16384 |
| 16 | 2 | manifest signature 길이64 |
| 18 | 2 | header가 주장하는 image 수1..3 |
| 20 | 4 | header가 주장하는 전체 file 길이 |
| 24 | 가변 | 정확한 deterministic CBOR byte열 |
| CBOR 뒤 | 64 | ECDSA-P256/SHA-256 `r[32] || s[32]` |
| 서명 뒤 | 가변 | 64KiB 정렬의0 padding과 순차 image bytes; prefix 입력에는 넣지 않음 |

header 정수는 little-endian, r/s는 각각 big-endian이다. 전체 file 상한은
3×(4MiB+64KiB)+최대 prefix의 보수적 format 상한일 뿐 role/slot 허용값이 아니다. 역할별 한두
이미지 제한·서명된 길이/대상과 header 대조·본문 검증은 다음 manifest 단계에
연결해야 한다. 현재 `declared_*` 결과를 신뢰된 설치 정보로 사용하면 안 된다.

검증 callback에는 정확한 CBOR bytes를 한 번 전달한다. 공개키는 신뢰된 caller
context에서 공급하며 파일 속 key를 root로 채택하지 않는다. portable 코드에는
SDK/heap/Flash writer가 없고 provider의 crypto 상태·수명·cleanup은 별도 책임이다.
실패 시 출력은0이며 provider 오류를 전파한다. 서명 OK도 설치 권한이 아니다.

Windows host 교차 시험만 Microsoft CNG의 실제 P256/SHA-256을 사용한다.
`cryptography==48.0.0`으로 메모리에서 임시 개인키를 생성·서명하고 CNG가 검증한다.
개인키는 파일/Git/장치에 저장하지 않는다. 합성 image는 부팅 가능하거나 image
자체 서명이 검증된 firmware가 아니다. board/epoch/호환성은 아래 typed manifest와
preflight가 검사한다. 부팅·Flash writer 연결은 남아 있다. 별도의 보존
[signed golden](../../tests/fixtures/ota-signed-golden/README.md)은 실제 SDK ESP BIN과
공식 ESP/STM signing 도구를 사용하며 위 임의 bytes 시험과 구분한다.
CNG provider는 장치 firmware에 링크하지 않는다.

Windows x64 CPython3.14에서는 먼저 `python -m pip install --only-binary=:all:
--require-hashes -r tools/requirements-ota.lock`을 실행한다. host build 뒤
`ctest --test-dir build/host-debug -R ota-envelope --output-on-failure`로 재현한다.
Linux는 portable 경계 시험만 실행하며 Windows CNG 시험 성공으로 집계하지 않는다.
암호 API 근거는 [Cryptography48 EC](https://cryptography.io/en/48.0.0/hazmat/primitives/asymmetric/ec/),
[CNG verify](https://learn.microsoft.com/en-us/windows/win32/api/bcrypt/nf-bcrypt-bcryptverifysignature),
[CNG 공개키 구조](https://learn.microsoft.com/en-us/windows/win32/api/bcrypt/ns-bcrypt-bcrypt_ecckey_blob)다.

## Typed manifest 검사 후보

ESP native 검증의 SDK adapter와 실제 compile/link fixture는
[SDK fixture 계약](../../tests/fixtures/idf-ota-image/README.md)에 있다. SDK 타입은
platform/BSP 경계에만 두며 이 portable 모듈에 포함하지 않는다. 반환한 signed
metadata 대조는 아래 공통 검사기로 수행하며 body/설치 provider 연결은 아직 남아 있다.

`canview_ota_manifest_check()`는 기존 prefix/서명 검사를 호출한 뒤 고정 구조체를
채운다. 범용 객체 tree나 heap 없이 필드를 순서대로 읽고 입력 pointer를 보존하지
않는다. 실패 시 결과 전체를0으로 만든다. verify callback의 독립 context/out
재진입은 가능하고, 동일 출력이나 입력을 callback에서 변경하는 것은 금지한다.
실행은 최대16KiB 구조 검사와 서명1회, image≤3·ABI 조합≤16의 고정 반복으로
제한된다. MCU의 실제 timing/전체 call-chain stack은 아직 측정하지 않았다.

아래 integer key는 **미배포 내부 후보**다. 정식 schema/packager/native image
연결과 최종 리뷰 전 wire 계약을 확정하거나 외부에 배포하지 않는다.

| root key | 필드 | 형식 |
|---|---|---|
| 0 | format_version | uint32, 값2 |
| 1 | package_id | bytes16 |
| 2 | role | Communicator1, Controller2, Bridge3; peer 권한 enum과 별개 |
| 3, 4, 5 | board_revision, layout_id, release | 1..63 printable ASCII; 표시 버전은 비교하지 않음 |
| 6, 7 | security_epoch, key_id | uint32 |
| 8 | images | descriptor map 배열 |
| 9 | compatibility | key0 ESP 범위,1 STM 범위,2 peer 범위,3 허용 ESP/STM ABI 쌍 배열 |
| 10 | config_schema | `[read_min:uint32, read_max:uint32, snapshot:uint32]` |
| 11 | requires | `[minimum_bootloader:uint32, minimum_recovery:uint32, capabilities:uint64]` |

image map key0..6은 차례로 target enum, length:uint32, SHA-256:bytes32,
version:text, release_sequence:uint64, native signature 형식, ABI:uint32다.
signature 형식1은 ESP Secure Boot V2,2는 MCUboot P256이며 실제 서명은 native
image 안에 있다. manifest의 이 숫자만으로 이미지 서명이 검증됐다고 판단하지 않는다.
모든 map은 정확한 필수 key 집합만 허용하고 누락/추가/중복/역순을 거부한다.

target1은 Communicator ESP(4MiB),2는 Communicator STM(180KiB),3은 Controller
(4MiB),4는 Bridge(2.5MiB)다. Controller/Bridge는 해당 image1개, Communicator는
중복 없는 ESP/STM1~2개만 허용한다. zero/초과 길이와 잘못된 native signature
형식을 거부하고 offset은 prefix 끝/직전 image 끝을64KiB 경계로 올려 만든다. 외부 offset,
경로, 주소, recovery/bootloader target은 없으므로 겹친 blob을 지정할 수 없다.
계산한 image 수와 전체 길이는 header의 주장과 정확히 대조한다.

정렬 이유와 version1 거절은 [ADR-009](../../docs/adr/009-ota-native-image-alignment.md),
byte 계약은 [OTA §7](../../docs/architecture/ota.md#7-패키지인증보안-계약)을 따른다.
prefix 검사는 padding을 읽거나 검증한 것으로 간주하지 않는다.

identity는 신뢰된 BSP/provisioning caller가 공급한다. 파일/HTTP에서 기대 role,
board/layout, epoch, key_id를 가져오면 안 된다. key_id는 verify context에서 실제
선택한 역할별 root와 같아야 한다. 현재 합성 host fixture의 board/layout 문자열은
실제 보드나 승인된 Flash layout ID가 아니다.

ABI 범위의 min≤max, image ABI 포함, 조합 범위/중복·Communicator 비어 있지 않은
조합 목록, config snapshot의 범위 포함을 검사한다. **실제 실행중/새 image와 네
old/new 조합의 호환성 대조, requires 충족, version floor와 본문 검사는 아래 별도
단계에서 수행한다.** STM native 검사와 ESP SDK adapter·BSP 연결은 구현했다.
정상 OTA owner/장치 실행·target 통합은 아직 남아 있다.
OK는 erase/write/PREPARED/boot selector 권한이 아니다. 정식 CLI·golden/target 연결도 남았다.

`ctest --test-dir build/host-debug -R ota-manifest --output-on-failure`로 C/Python
typed 교차 시험을 실행한다. portable probe는 서명 mock을 사용하며 Windows CNG
probe를 사용하는 별도 시험만 실제 서명 검증이다. 양쪽은 잘못된 role/board/layout/
epoch/key, 필드 누락/추가, 중복 target/key, 길이 상한, uint64 sequence 보존,
truncation, ABI/config 경계를 검사한다. 실제 firmware 설치·물리/HIL은 NOT_RUN이다.

## 순차 image 본문 검사

`body_open()`은 완전한 prefix의 manifest·로컬 호환성·version floor를 검증한 뒤 첫 SHA-256
operation을 시작한다. `body_feed()`는 절대 file offset과0..16KiB chunk를 받아
prefix 실제 크기부터 padding·이미지 경계를 순서대로 처리한다. padding은0인지
검사만 하며 hash에서 제외한다.64KiB buffer는 없다. image bytes는 복사/보존하지 않고 SDK provider의
update에 전달한다. 끝에서 signed descriptor의 SHA-256과 대조한 뒤 operation을
정리한다. 모든 image가 맞아야 `HASHES_MATCHED`가 된다. `body_finish()`는 EOF를
확인하며 아직 부족하면 `INCOMPLETE/FAILED`로 종료한다. 이름은 모두
`canview_ota_` prefix를 가진 내부 C API다.

- caller는 body 객체를 처음에 `{0}`으로 초기화하고 한 task에서 직렬 호출한다.
  prefix/identity/runtime/floor/chunk는 호출 중만 빌리며 descriptor와 hash 함수표는 복사한다.
  provider context는 reset 성공까지 유효해야 한다. 활성 body 복사/memset은 금지한다.
- offset 중복·누락, 길이 초과, hash/provider 오류는 FAILED이며 manifest 결과를
  지우고 floor 판정도 무효화한다. 실패한 stream에 재전송해 이어 쓰지 않는다.
  reset 후 prefix부터 다시 검증한다.
- `body_reset()`은 부분 start/수신/finish/실패를 정리한다. cleanup 실패 시 context와
  자원 소유 상태를 보존해 reset을 재시도할 수 있다. 원 오류와 cleanup 오류는 별도다.
- busy flag는 동일 객체 callback 재진입만 막는다. thread lock이 아니며 ISR에서
  호출하지 않는다. 호출당 hash에 전달하는 데이터는 최대16KiB, image 경계 반복≤3이다.
  빈 chunk는 offset을 진행시키지 않는다. transport timeout은 caller가 reset으로 종료한다.

암호 구현은 provider가 소유한다. Windows host는 기존 CNG P256 verifier를
`tests/ota/cng_provider.c`로 추출해 재사용하고 CNG SHA-256 operation을 연결했다.
Windows SDK가 hash object를 할당/해제하므로 이 **host provider의 할당**을 portable
core의 무힙 특성과 혼동하지 않는다. 실제 장치용 SDK provider는 아직 연결하지 않았다.
[CNG 생성](https://learn.microsoft.com/en-us/windows/win32/api/bcrypt/nf-bcrypt-bcryptcreatehash),
[완료](https://learn.microsoft.com/en-us/windows/win32/api/bcrypt/nf-bcrypt-bcryptfinishhash),
[해제](https://learn.microsoft.com/en-us/windows/win32/api/bcrypt/nf-bcrypt-bcryptdestroyhash)의
공식 계약을 따른다.

`ctest --test-dir build/host-debug -R ota-body --output-on-failure`로 실행한다.
portable probe의 sum/length 모형은 실패·수명 시험일 뿐 SHA-256 검증이 아니다.
Windows crypto probe는 역할별 임시 공개키, 실제 P256 서명과 SHA-256, `abc` known
answer, 본문 변이·최대 image·잘린 입력·provider/cleanup 실패를 시험한다. 시험은
native firmware가 아닌 합성 bytes만 사용하며 개인키를 저장하지 않는다.

`HASHES_MATCHED`는 **native image signature/protected metadata·최신 version floor 재검증,
설치 직전 로컬 상태 재확인, Flash read-back, 설치 또는 PREPARED 승인과 별개**다.
이 모듈에는 writer·boot selector callback 자체가 없다. prefix 부분 수신과 outer 조립/
검사 CLI·보존 signed golden과 host `--native` 연결은 구현되어 있다.
실제 ESP/STM provider와 정상 target owner 통합·최종 검증은 남아 있다.
schema와 서명 전 JSON 작성 도구는 위 절의 구현을 사용한다.

## 수신 저장 호출 순서

수신 저장과 연결할 때는 [stage.h](src/stage.h)의 수신 전용 조정 함수를 사용한다.
순서는 `body_open(서명/identity/길이/호환성/floor) → storage.begin →
body_feed 성공 뒤 storage.write → body_finish 뒤 storage.verify`다.
실제 erase/write/partition 선택은 BSP provider가 소유하며, parser 안에 SDK 호출이나
Flash 주소를 넣지 않는다. 새 설치 상태기계·journal·재부팅·비동기 queue는 없다.

stage는 `{0}`인 단일 task 소유 고정 context와 기존 body를 사용한다. prefix/chunk는
호출 중만 빌리고 복사하지 않는다. 모든 callback은 동기이고 재진입은 RESOURCE_BUSY다.
호출 실패 뒤 추가 write/native 검증을 차단하며 reset이 storage close와 body cleanup을
수행한다. partial begin도 close하며 cleanup 실패 시 최초 오류와 context를 보존한다.
`EMPTY → RECEIVING → NATIVE_MATCHED`, 오류 시 `FAILED → reset → EMPTY`로 전이한다.
NATIVE_MATCHED도 PREPARED·boot selector·사용자 승인·설치 권한이 아니다.

storage.begin은 검증된 enum target을 고정 비활성 slot/staging map에만 대응해야 한다.
write는 prefix 이후 컨테이너 절대 offset·padding을 받으며 read-back 뒤에만 OK다.
verify는 저장된 image 전체 native hash/서명/metadata를 대조한다. provider는 prefix/
manifest 입력을 호출 뒤 보존하지 않고 필요한 상태만 자신의 context에 복사한다.
어떤 callback도 설치나 journal commit을 수행하면 안 된다. 로컬 freshness·전원·실제
partition allowlist는 T-204/T-107, 승인·영속 정책은 T-205에서 추가 검증한다.

`ota-stage-order`는 실제 C parser와 storage/native callback 모형을 연결한다. 세 역할,
금지 target·wrong identity, 사전 검증 실패, 부분 입력·중복/hole·본문 변조, provider 실패,
callback 재진입·cleanup 재시도와 출력 상태를 검사한다. Windows의
`ota-stage-order-crypto`만 outer P256/SHA256에 실제 CNG를 사용한다. storage/native
callback은 양쪽 모두 모형이며 실제 Flash/장치 서명 검증 증거가 아니다.
Open 인자 방어는 정상 입력의 begin/close 양성 대조 뒤 한 인자만 바꿔 검사한다.
중첩 시험은 정렬된 stage storage에 유효 값을 복사하고 제어 필드는 보존한다.
Reset 전에 body가 EMPTY인지 확인해 하위 parser가 입력을 지운 뒤 같은 오류를
반환하는 경우와 사전 거절을 구별한다. `ota-stage-oracle`은 사전 begin·거절 후
write·native 오류 무시·hash context 및 identity 중첩 방어 삭제의 다섯 실제 C
mutant를 컴파일해 정상 exit0/변이 CHECK 실패 exit1을 요구한다.
SDK fixture는 stage 네 API를 compile/link하고 NULL 계약만 연결한다. 이 단계에서도
실제 writer allowlist·장치 실행·total stack/heap/WCET는 NOT_RUN/후속 gate다.

### 정적 자원 근거와 장치 측정 경계

ESP-IDF6.0.3의 현재 Xtensa fixture ELF DWARF에서 prefix16488B, body856B,
stage896B, PSA context108B를 확인했다. stage는 body를 포함하므로 둘을 더하지 않는다.
실제 receiver는 prefix/body/PSA를 static으로 배치해17452B를 사용한다. 향후 같은
prefix/PSA와 stage를 배치하면17492B이며, 별도16KiB chunk buffer까지 둔다면33876B다.
후자의 합계는 통합 전 산술량이며 실제 정상 앱의 전체 RAM이나 여유량이 아니다.
입력 native image는 호출 중 빌리며 이 context에 전체 image를 복사하지 않는다.

현재 compiler의 자체 stack frame은 stage open48B·feed/finish/reset32B,
manifest_check880B·CBOR validate208B·STM native144B다. 각 `.su` 값은 다른
함수와 SDK 호출 chain을 포함하지 않으며 합산만으로 총 stack을 인증하지 않는다.
[수신 fixture](../../tests/fixtures/idf-ota-image/README.md#전체-컨테이너-수신-fixture)의
stack16384B 역시 예약량이지 측정으로 보증한 값이 아니다.

CBOR는16KiB/2048item/depth8로 제한하고 재귀·heap 없이 byte/item에 선형이다.
Manifest P256 검증은 open당1회이며 역할별 image는 최대2개, ABI 조합은 최대16개다.
Body feed는 최대16KiB를 소비하고 image 경계에서만 hash finish/start를 수행한다.
전체 payload의 SHA256은 image당1회이며 native 검증은 별도다. STM native 검사는
최대180KiB image를 SHA256으로 최대2회 읽고 P256을1회 호출한다. 이 연산량 상한과
host 시험 timeout은 MCU 실행시간/WCET가 아니다. callback 내부 지연은 portable
core가 선점하거나 timeout으로 중단하지 못하므로 단일 owner가 watchdog·응답 예산을
실제 target에서 검증해야 한다.

PSA adapter는 volatile 공개키1개와 hash operation1개를 소유한다. SDK 내부 할당은
없다고 가정하지 않으며 부족/실패와 cleanup 재시도를 시험한다. SDK 내부 peak heap,
전체 stack high-water·최대 크기 입력 시간·watchdog 지연은 장비 부재로 NOT_RUN이다.
Owner는 T-204/T-107의 target 구현자, 영속 정책 연결은 T-205, 실측 gate는 T-508 및
해당 장치 qualification 전이다. foundation의 합성 budget fixture로 대체하지 않는다.

## 로컬 호환성 사전 검사

별도 framework 대신 기존 manifest 검사 뒤에 `canview_ota_manifest_preflight()`를
연결했다. body open도 이 함수를 호출하므로 호환성이 맞기 전 hash operation을
시작하지 않는다. 검사 실패 시 해석 결과를 모두 지운다.

- 로컬 snapshot은 BSP와 신뢰된 boot/정상 앱 metadata에서 caller가 읽는다.
  파일/HTTP 입력을 복사하지 않는다. `available=false`면 INCOMPLETE이며0으로 추정하지
  않는다. recovery 실행 중에도 esp/stm_abi는 recovery 자신의 값이 아닌 정상 앱 또는
  검증된 보존 정상본의 값이다. 이를 확인하지 못하면 사전 검사를 통과할 수 없다.
- Communicator의 `(old,old)`, `(new,old)`, `(old,new)`, `(new,new)`가 모두 signed
  조합 목록에 있어야 한다. 한 image만 포함하면 나머지 MCU는 기존 ABI를 유지한다.
  같은 ABI의 중복 조합은 목록에 한 번만 있으면 된다. 범위와 조합 수는 기존 parser가 제한한다.
- ESP/STM 각각의 bootloader/recovery ABI가 manifest 최소 요구 이상인지 확인한다.
  Controller/Bridge에서는 사용하지 않는 stm_*를 검사하지 않는다. 외부 peer의 연결이나
  ABI는 이 설치 사전 조건에 넣지 않는다. peer 기능 협상과 차량 권한은 별도다.
- 필요한 hardware capability는 로컬 bit 집합의 부분집합이어야 한다. 보존 중인 config
  schema는 후보의 읽기 범위 안이어야 한다. snapshot을 수정하거나 migration하지 않는다.

이 함수는 서명된 후보의 주장과 로컬 snapshot을 비교할 뿐이다. native image의
서명/보호 metadata 대조는 별도 단계다. STM 검사와 ESP SDK adapter·공통 metadata
검사는 아래 구현을 사용하며 정상 owner/target 연결은 미완료다.
snapshot을 보존하지 않으므로 설치 owner는 transaction/상태 변경 뒤 다시
검증해야 한다. floor 비교는 아래 검사, 영속 갱신과 write/activation 권한은 별도 owner다.

## 버전 하한 사전 검사

`canview_ota_floor_check()`는 preflight 뒤, 첫 본문 hash operation 전에 호출한다.
기존 [OTA §7.1](../../docs/architecture/ota.md#71-영속-버전-하한과-복원-예외)의 정책을
순수 C99 비교로 구현하며 영속 journal·범용 policy engine을 추가하지 않는다.

| 후보와 로컬 record 비교 | 반환/판정 |
|---|---|
| sequence < minimum_sequence | `STALE`, 수신 후보 거절 |
| 같은 sequence, 다른 confirmed_digest | `AUTH_FAILED`, `CONFLICT` |
| 같은 sequence/hash, 실제 정상 설치 검증 | `ALREADY_INSTALLED` 사전 판정 |
| 같은 sequence/hash, 정상 앱 손상/부팅 선택 불가 확인 | `REPAIR_REQUIRED` 후보 |
| sequence > minimum_sequence | `UPGRADE` 후보 |
| policy 미확인 또는 동일 이미지의 실제 설치 상태 미확인 | `INCOMPLETE` |

sequence는 uint64 직접 비교한다. `floor_result.images[]`는 manifest image 순서이며
record 순서는 독립이다. 누락/중복/잘못된 역할·target·enum·board/layout/epoch를
검사하고, 어느 target이든 실패하면 판정 전체를0으로 지운다. 성공도 floor를 변경하지 않는다.

`floor.ready`는 신뢰된 journal owner가 valid copy 선택과 CONFIRM_INTENT/실제 boot
상태 조정을 완료했다는 뜻이다. `{0}`이나 두 copy 손상을 floor0으로 간주하지 않는다.
이 경우 owner는 RECOVERY_LOCKED와 쓰기 금지를 유지한다. 현재 비교기는 copy를 읽거나
CRC/commit을 검증하지 않는다. `floor`는 영속 wire가 아닌 호출 중만 빌리는 snapshot이다.
네트워크 입력으로 구성하지 않으며 task owner가 Flash/정책 변경과 직렬화해야 한다.

`BOOTABLE`은 실제 정상 앱의 전체 hash/native 서명/board/layout/epoch/부팅 선택
metadata 검증을 뜻한다. 그 앱의 observed sequence/digest도 floor와 대조한다.
recovery 실행이나 과거 transaction 성공은 설치 증거가 아니다. 읽기 실패는 UNKNOWN,
손상/선택 불가를 확인한 경우만 DAMAGED다. 같은 정식 이미지의 복구에도 전체 native
검증·새 activation commit·trial이 필요하다. 자동 rollback/확정/floor 갱신은 하지 않는다.

`ctest --test-dir build/host-debug -R 'ota-version-floor|ota-body' --output-on-failure`
로 순수 비교와 body 연결을 검사한다. 영속 A/B·실제 앱 검사 provider·전원 차단 검증은
아직 남아 있으며 host snapshot 모형을 물리/HIL 결과로 표시하지 않는다.

## ESP-IDF 암호 provider

[PSA adapter](../../firmware/platform/esp32s3/ota_crypto.h)는 기존 manifest callback과
body SHA256 함수표에 ESP-IDF6.0.3의 PSA Crypto를 연결한다. BSP가 공급하는 역할별
신뢰 P256 공개키를 volatile/VERIFY_MESSAGE 전용으로 import한다. 입력 package의
공개키나 개인키·영속 key 생성은 처리하지 않는다. context마다 key1개/hash operation1개를
소유하며 크기는 manifest/chunk16KiB, raw signature64B, digest32B로 제한한다.

한 task가 직렬 호출하며 ISR/동시 호출은 금지한다. 입력은 호출 중만 빌리고, context와
겹치는 입력/출력과 SDK 재진입은 거절한다. setup/update/finish 실패 후에는 reset을
완료해야 재사용할 수 있다. body_reset 성공 뒤 crypto_close로 key를 해제한다.
abort/destroy 실패 시 handle을 지우지 않고 close 재시도 동안 새 검증/hash를 차단한다.
SDK 내부 자원 부족은 실패로 전파하며 portable core에 SDK header를 넣지 않는다.

`ota-psa-provider` CTest는 실제 adapter의 실패·수명·재진입 **모형**이다. 실제 SDK
fixture에서도 compile/link하지만 모형 PASS를 실제 PSA 암호 실행으로 표시하지 않는다.
정상 OTA owner/BSP root provider 연결과 MCU 실행은 아직 남아 있다. 설치/Flash 권한은 없다.

## STM native image 검사

`canview_ota_stm_image_check()`는 MCUboot v2.4.0의 비압축·비암호화 P256 image를
검사한다. 공식 imgtool은 `tools/toolchain-versions.json`의 commit
`6d3b3d2c38ab20c242e5b9abb04d050086383eb2`로 고정한다. header512B, 일반 앱 image
최대180KiB, load address/flags0, 별도 slot padding/trailer가 없는 profile이다.
protected TLV 한 개 뒤 SHA256·KEYHASH·P256 DER TLV만 허용한다.

검사기는 전체 image SHA256을 manifest와 비교하고, header+code+protected TLV의
SHA256과 native signature도 독립 검사한다. DER은 정규 positive integer 두 개를
raw r/s로 옮길 뿐 암호 연산은 SDK가 소유한다. root는 입력 이미지가 아니라 신뢰된
STM 전용 공개키/context에서 공급하며 SPKI DER key hash도 대조한다. 함수는 불변
전체 image를 호출 중만 빌린다. memory-mapped staging도 가능하지만 실제 Flash
reader·SDK provider·T-107 bootloader 연결은 아직 없다. vector/부팅 가능성 검사는
이 image-format 시험의 성공만으로 주장하지 않는다.

보드·역할·sequence는 native 표준 header만으로 표현할 수 없으므로 MCUboot의 기존
vendor protected TLV(tag `0x00A0`)를 사용한다. 내부168B metadata 후보는 다음과 같다.
ESP에는 SDK의 `.rodata_custom_desc`에서 같은 정보를 읽고 공통 검사기로 대조한다.
실제 이미지에 descriptor를 생성·삽입하는 packager/target 연결은 아직 없다.
아래 배정은 wire schema에 기록했으며 최종 독립 리뷰 전 구현 후보다.

| offset | 내용 |
|---|---|
| 0 | `CVIMG001`8byte |
| 8,10 | version1:u16, size168:u16 |
| 12,16,20,24,28 | role, target, security_epoch, ABI, reserved0:u32 |
| 32 | release_sequence:u64 |
| 40,104 | board_revision, layout_id: 각각64byte |

정수는 little-endian, 문자열은 printable ASCII1..63byte/NUL/나머지0이다. 이 값들과
manifest/local identity가 다르면 거부한다. image version도 native header와 정규
`major.minor.revision+build` 문자열을 대조한다. 서명된 metadata의 잘못된 역할이나
sequence는 서명이 유효해도 거부한다. 성공은 영속 floor/REPAIR/activation 승인이 아니다.

`native_metadata.c`는 기존 STM 대조를 공통화한 무상태 C99 코드다. STM과 ESP가
별도 parser를 유지하지 않는다. `canview_ota_native_metadata_check()`는 정확한168B와
유효한 role/target/signature 조합을 요구한다. `canview_ota_esp_metadata_check()`는
여기에 SDK `app.version[32]`의1..31byte printable ASCII/NUL/zero padding 대조만 더한다.
ESP SDK native 서명·전체 hash 성공 뒤, 같은 불변 이미지의 반환 metadata를 전달해야 한다.
이 함수에 웹 입력 metadata만 주어 얻은 OK는 서명 증거가 아니다. `secure_version`을
u64 release_sequence나 제조 epoch로 변환하지 않으며 epoch는 위 custom 필드에서 대조한다.
Communicator의 [BSP 연결](../../firmware/communicator/esp32/bsp/ota.h)은 generated board ID와
고정 `bundle_stage`의 주소/크기를 검사한 뒤 SDK→metadata를 호출한다. 입력은 인증된
COMM_ESP descriptor와 신뢰된 provisioning identity이며 외부 partition pointer/주소를
받지 않는다. template staging의 `encrypted` flag와 BSP 위치/크기도 generator가 소유한다.
실제 OTA task의 단일 owner/Flash 불변 보장·body orchestration과 다른 장치 연결은 남아 있다.
`ctest --test-dir build/host-debug -R ota-native --output-on-failure`로 공통 경계와
기존 공식 imgtool/CNG STM 회귀시험을 실행한다.

Windows에서 `MCUBOOT_ROOT`를 위 commit의 clean checkout으로 지정하고 기존 OTA
wheel lock을 설치한 뒤 `ctest --test-dir build/host-debug -R ota-native-stm
--output-on-failure`를 실행한다. 기본 경로는 `C:/cv/mcuboot-2.4.0`이다. CI도 같은
commit을 clone/확인한다. 시험은 imgtool의 실제 생성/검증과 CNG 검증을 사용하며
개인키는 메모리에만 둔다. 합성 code bytes는 부팅 가능한 firmware가 아니다.
`--model`은 Python 계산 결과를 돌려주는 비암호 callback 모형으로 별도 집계한다.

공식 근거:
[MCUboot imgtool](https://github.com/mcu-tools/mcuboot/blob/6d3b3d2c38ab20c242e5b9abb04d050086383eb2/docs/imgtool.md),
[image 형식](https://github.com/mcu-tools/mcuboot/blob/6d3b3d2c38ab20c242e5b9abb04d050086383eb2/docs/design.md),
[ESP-IDF custom descriptor](https://github.com/espressif/esp-idf/blob/v6.0.3/docs/en/api-reference/system/app_image_format.rst).

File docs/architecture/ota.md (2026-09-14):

# 독립 OTA와 전원 차단 복구 설계

검토일: 2026-09-06. 대상: Controller, Communicator(ESP32-S3 + STM32G474), Diagnostic Bridge.

이 문서는 OTA 설계, 필요한 회로 변경, 구현 계약, 검증 조건과 독립 적대적 리뷰를 한 파일에 모은다. 펌웨어 구현 및 실물 전원 차단 시험은 후속 단계다.

## 1. 채택 방향과 적용 범위

각 장치가 자체 Wi-Fi AP와 업데이트 웹 페이지를 제공한다. 휴대폰의 기본 브라우저에서 서명된 업데이트 파일을 선택하면 된다. Controller가 없거나 Bridge가 꺼져 있어도 Communicator의 ESP32가 자체 업데이트와 STM32 업데이트를 수행한다. Bridge도 자기 AP에서 자신만 업데이트하며 차량 제어 권한을 얻지 않는다.

| 대상 | 정상 업데이트 | 첫 부팅 실패 | 정상 앱 둘 다 사용할 수 없을 때 |
|---|---|---|---|
| Controller ESP32 | 내부 `ota_0/ota_1` 교대 | 이전 앱으로 rollback | 어댑터 RECOVERY 버튼으로 별도 복구 앱 → 휴대폰 재업로드 |
| Communicator ESP32 | 내부 `ota_0/ota_1` 교대 | 이전 앱으로 rollback | RECOVERY 버튼 → 복구 앱이 ESP/STM 업데이트 제공 |
| Communicator STM32 | ESP가 UART로 내부 secondary 기록 → MCUboot 교체 | 시험 앱 미확정이면 revert | 보호된 부트로더가 UART 복구 수신; 필요 시 ESP가 STM만 reset |
| Bridge ESP32 | 내부 `ota_0/ota_1` 교대 | 이전 앱으로 rollback | 기존 PAIR 버튼을 reset 중 길게 눌러 복구 앱 |

권고 구성은 **외장 SPI NOR 없이** ESP 이중 앱 슬롯과 STM 내부 교체 슬롯을 사용한다. 부트로더와 파티션표의 최초 설치는 안정된 작업대 전원과 유선 도구로 수행한다. 이후 일반 OTA에서는 이 영역과 복구 앱을 갱신하지 않는다. ESP-IDF도 앱 OTA와 달리 부트로더·파티션표의 교체는 전원 차단에 취약한 작업으로 구분한다. [ESP-IDF v6.0 OTA](https://docs.espressif.com/projects/esp-idf/en/v6.0/esp32s3/api-reference/system/ota.html)

여기서 안정성은 전원 차단 뒤 유효한 이전 앱으로 부팅하거나, 안전하게 업데이트를 재개하거나, 서명된 파일을 다시 받을 수 있는 상태로 남는다는 뜻이다. 전원이 계속 흔들리는 동안 정상 동작하거나 물리 Flash 고장까지 소프트웨어로 복구한다고 보장하지 않는다. 보장 범위는 §12 시험으로 입증한다.

최초 OTA 변경은 회로 생성 입력과 KiCad 산출물에 적용했다. ESP-IDF 프로젝트, STM linker, 실제 부트로더·웹 서버·서명 키 provisioning은 아직 구현하지 않았다. 이 문서의 Flash 표는 후속 구현 계약이며 현재 CSV가 이미 OTA용이라는 뜻이 아니다. 최초 검토는 사용자의 단일 MD 요청에 따라 리뷰까지 본문에 기록했다. 이후 전체 계획 재점검 요청으로 구현 작업은 [task 요약](../tasks.md)의 T-007/T-107/T-108/T-204/T-205/T-306/T-507/T-508로 분리했고, 본문 §14의 과거 독립 리뷰 원문은 그대로 보존한다.

## 2. 기준선과 현재 제약

하드웨어 비교 기준은 `cffa3373e2f9f63291f8e89ebeddaa13dfe0fb70`의 R1이다. [도구 잠금 파일](../../tools/toolchain-versions.json)은 ESP-IDF `v6.0.3` / `76f5dedd9950a3012fee8fb7d5586df21fc67802`, STM32CubeG4 `v1.6.3`를 고정한다. 본문에서는 v6.0 공식 문서와 v6.0.3 Kconfig 원문을 대조했다. 움직이는 `stable/latest` 문서의 새 기능을 현재 SDK에 있다고 가정하지 않는다.

| 항목 | 확인한 현재 상태 | OTA에 미치는 영향 |
|---|---|---|
| Controller | ESP32-S3, Flash16MiB, PSRAM8MiB; Waveshare 보드 | 카메라 미사용 variant의 GPIO41을 복구 버튼에 사용 |
| Communicator | 기존 MINI-1-N4R2에서 **WROOM-1-N16R8**로 변경 | Flash16MiB/Octal PSRAM8MiB; ECC 사용 시 가용7.5MiB |
| STM32 | G474CEU6 Flash512KiB, 기존 linker가 전체 Flash 사용 | 부트로더/슬롯 도입 시 최초 유선 재설치 필요 |
| Bridge | WROOM-1-N8R2, PAIR GPIO4, BOOT GPIO0 | PAIR 재사용으로 추가 회로 없이 복구 진입 가능 |
| 기존 ESP 파티션 | Controller/Comm 모두 단일 `factory`, `otadata` 없음 | 현재 설치본에서 파티션표를 OTA로 바꾸지 않음 |
| 기존 reset | ESP CHIP_PU와 STM PG10-NRST가 `SYS_RESET_N` 공유 | ESP가 STM reset을 당기면 자기 자신도 reset되는 구조를 수정 |
| 전원 | Communicator의 CAN PHY는 차량 전원만 사용 | USB 단독 서비스 시 MCU는 켜지고 CAN PHY는 무전원 |

하드웨어 상세의 기존 reset/허용식은 이번 OTA 변경에 한하여 §6과 생성된 netlist로 대체된다. [R1 회로](../hardware/r1/communicator-circuit.md), [생성 입력](../../tools/hardware/ota_circuits.py), [Controller 헤더](../hardware/controller.md)를 함께 참조한다. 이전 문서의 GPIO43/44 표기보다 R1에서 공식 회로와 대조한 실제 헤더 매핑을 우선하며, 이번 버튼은 UART를 사용하지 않는다.

## 3. 휴대폰 업데이트 절차와 통신 선택

1. 정차 후 장치의 업데이트 화면/서비스 버튼에서 세션을 연다. Communicator는 J31 RUN shunt를 제거한다. 이 커넥터는 케이스 밖 서비스 덮개에서 손으로 조작 가능해야 한다. 전용 앱·드라이버·분해용 도구를 요구하지 않는 기구 설계를 수용 조건으로 둔다.
2. Communicator/Bridge는 C-to-C 5V, 1.5A 이상을 광고하는 충전기/보조배터리를 권고한다. 현재 R1은 A-to-C/default-current 전원만으로 켜지지 않는다. Controller는 Waveshare 전원 입력을 사용한다. 차량 전원과 USB 사이 자동 전환은 도움이 되지만 무중단 보장은 시험 전에는 하지 않는다.
3. 휴대폰을 `CANView-<role>-<short-id>` AP에 연결하고 기기 라벨/화면의 고유 암호를 입력한다. 인터넷 없음 안내에서 연결을 유지한다. 브라우저에서 `http://192.168.4.1`을 연다. QR/captive portal/mDNS는 편의 기능이며 이 고정 주소 경로도 동작해야 한다.
4. 공식 배포처에서 미리 받은 `.cvota` 파일을 선택한다. 파일 선택창, 진행률, 현재/대상 버전, 업데이트 결과만 노출한다. 별도 코드 입력이나 콘솔은 필요 없다.
5. 파일 검증 후 사용자가 설치를 누른다. 화면은 `전송 중 → 검증 중 → 설치 중 → 재시작 중 → 완료/이전 버전 복원`을 구분한다. 전송 100%를 설치 성공으로 표시하지 않는다.
6. 재접속하면 장치에서 읽은 결과를 표시한다. 휴대폰이 잠자기/화면 닫기/통신 끊김 상태여도 사용자 설치 승인까지 영속 commit된 교체는 장치가 수행한다. 전송이 미완성이면 기존 앱을 보존하고 재업로드를 요청한다. PREPARED만으로는 재부팅 뒤에도 설치하지 않고 승인 대기한다.
7. Communicator는 완료 후 J31을 다시 연결하고 서비스 모드를 종료한다. 새 handshake·local safety check·새 control lease 없이 CAN TX를 자동 재개하지 않는다. 실패한 업데이트를 같은 부팅에서 무한 자동 재시도하지 않는다.

STA + HTTPS 다운로드는 선택적 후속 기능이다. AP 기본 경로는 인터넷·DNS·RTC·Controller·Bridge에 의존하지 않는다. 휴대폰 hotspot 자체에 연결한 장치에 그 휴대폰이 항상 접속할 수 있다고 가정하지 않는다. BLE는 초기 설정에만 선택적으로 검토하며 Web Bluetooth 지원 차이 때문에 필수 업데이트 경로로 삼지 않는다. ESP-NOW로 펌웨어 전체를 중계하는 기능은 v1 범위에서 제외한다. 업데이트 중에는 해당 장치의 ESP-NOW raw/capture를 중지해 단일 radio의 channel 충돌을 피한다.

Controller OTA는 Communicator에 서비스 상태를 알리고 제어 lease를 반납한다. 상대가 없더라도 Controller 자체 업데이트는 가능하다. 상대 응답이 없으면 마지막 명령을 재전송하지 않으며 Communicator의 자체 lease 만료가 적용된다. Communicator OTA는 J31 하드웨어 차단을 먼저 확인하므로 Controller 응답에 의존하지 않는다. Bridge는 오직 자신의 observer 세션만 종료한다.

## 4. ESP 부팅·Flash 배치

### 4.1 정상 앱과 복구 앱

ESP-IDF `CONFIG_BOOTLOADER_APP_ROLLBACK_ENABLE=y`로 시험 부팅 후 명시적으로 확정한다. 앱의 `app_main()` 도달이나 Wi-Fi 송신 callback만으로 확정하지 않는다. 내부 메모리 검사, 설정 snapshot 판독, watchdog, 역할별 최소 장치 검사를 통과한 뒤 `esp_ota_mark_app_valid_cancel_rollback()`을 호출한다. USB 서비스 중 CAN PHY가 꺼져 있거나 상대 Controller가 없는 것은 자체 OTA 실패 사유가 아니다.

복구 앱은 별도 ESP-IDF 프로젝트로 빌드한 `app/test` 이미지다. `CONFIG_BOOTLOADER_APP_TEST=y`, active-low, hold5초를 사용한다. GPIO는 Controller41, Communicator8, Bridge4다. GPIO0은 ROM download strap이므로 이 용도로 쓰지 않는다. 복구 앱은 LCD·SD·PSRAM·정상 앱 NVS schema 없이 AP/서명 검증/업로드/상태 조회/Communicator STM UART 복구를 제공한다. 장치 고유 AP 자격증명은 별도 provisioning 영역의 검증된 두 사본으로 읽고, 모두 손상되면 라벨 secret을 별도 복구 절차로 입력받는 정책을 제조 단계에서 확정해야 한다. 무암호 AP로 자동 전환하지 않는다. [ESP-IDF bootloader](https://docs.espressif.com/projects/esp-idf/en/v6.0/esp32s3/api-guides/bootloader.html)

`test`라는 subtype 자체가 쓰기 보호는 아니다. 공통 flash writer에서 bootloader/partition table/test/provisioning 영역 쓰기를 거부하고, 업데이트 manifest target allowlist에서도 제외한다. ESP Secure Boot는 서명 검증 기능이며 정상 서명 앱의 임의 Flash 쓰기를 막는 메모리 방화벽으로 주장하지 않는다. 최종 앱의 취약점으로 전체 Flash가 손상되는 경우까지 A/B가 보호하지는 않는다.

### 4.2 제안 주소표

주소는 ESP 외부 부팅 Flash의 offset, 길이는 바이트, 구간 끝은 미포함이다. 모든 app은 64KiB 경계, data는 4KiB 경계를 따른다. 선두 256KiB는 공통이며 아래 정본을 토대로 CSV를 생성한다.

| 공통 영역 | 시작 | 길이 | 계약 |
|---|---|---|---|
| bootloader + 예약 | `0x000000` | `0x018000` | Secure Boot 서명 크기까지 확인; 실제 ROM/IDF 크기 상한도 별도 검사 |
| partition table | `0x018000` | `0x001000` | OTA에서 수정 금지 |
| nvs | `0x019000` | `0x006000` | 비권위 캐시만; 자동 전체 erase 금지 |
| otadata | `0x01F000` | `0x002000` | IDF 전용 이중 sector |
| phy_init | `0x021000` | `0x001000` | RF 초기 데이터 |
| nvs_keys | `0x022000` | `0x001000` | 암호화 키 영역 |
| OTA journal A/B | `0x023000` | `0x002000` | 서로 다른4KiB sector |
| config A/B | `0x025000` | `0x008000` | 각각16KiB; version/CRC/commit record |
| provisioning A/B | `0x02D000` | `0x008000` | 각각16KiB; normal OTA 쓰기 금지 |
| 예약 | `0x035000` | `0x00B000` | 앱 시작 `0x040000` |

| 장치 | recovery test | ota_0 | ota_1 | 일반 데이터 |
|---|---|---|---|---|
| Controller16MiB | `0x040000 + 0x100000` | `0x140000 + 0x400000` | `0x540000 + 0x400000` | `0x940000 + 0x6C0000` |
| Communicator16MiB | `0x040000 + 0x200000` | `0x240000 + 0x400000` | `0x640000 + 0x400000` | `0xA40000 + 0x5C0000` |
| Bridge8MiB | `0x040000 + 0x100000` | `0x140000 + 0x280000` | `0x3C0000 + 0x280000` | `0x640000 + 0x1C0000` |

CI 기준은 서명·정렬 padding 포함 이미지 길이 ≤ 슬롯 길이, 그리고 성장 여유128KiB 이상이다. Communicator 정상 앱은3968KiB 이하, 복구 앱은1920KiB 이하를 설계 목표로 둔다. Controller/Bridge 복구 앱은896KiB 이하가 목표다. 실제 완성 이미지 크기는 후속 build gate다. UI/웹 자산은 해당 앱에 포함해 함께 교체하며, 공유 파일시스템을 갱신해야 한다면 versioned immutable object + 이중 manifest를 사용한다. 파일 전체를 제자리 덮어쓰는 업데이트는 금지한다.

사용자가 더 큰 모듈과 N16R8을 지정해 WROOM-1-N16R8을 채택했다. MINI의4MiB 제한안은 역사적 비교안이며 새 회로에 적용하지 않는다. WROOM은18.0×25.5mm 본체와 antenna keepout을 반영해야 하므로 기존70×45mm 보드 목표의 성립을 다시 검토한다. GPIO35/36/37은 R8 Octal PSRAM에 연결되어 외부 사용 금지다. 기존 MINI GPIO33의 mux sense는 WROOM GPIO38/pad31로 옮긴다. PSRAM은80MHz Octal + ECC를 설정하며120MHz 실험 모드를 쓰지 않는다. 공식 R8 온도 범위는 기본 최대65°C, ECC 사용 시 최대85°C 조건이며 실제 보드 열시험을 대체하지 않는다. ECC는8MiB의1/16을 사용한다. [Espressif module 사양](https://documentation.espressif.com/esp32-s3-wroom-1_wroom-1u_datasheet_en.html), [v6.0.3 PSRAM Kconfig](https://github.com/espressif/esp-idf/blob/v6.0.3/components/esp_psram/esp32s3/Kconfig.spiram)

Communicator 일반 데이터 영역 중 `0xA40000 + 0x480000`(4.5MiB)은 한 개의 수신 bundle staging, 나머지 `0xEC0000 + 0x140000`은 비권위 일반 데이터로 배정한다. 최대 정상 ESP 이미지4MiB + STM180KiB + manifest16KiB가 staging에 들어간다. cache는 활성 앱/설정/유일한 정상본과 분리한다. 다운로드 시작 시 이전 staging을 지워도 현재 부팅에는 영향이 없어야 한다. 전체 hash·서명 검증 후에만 PREPARED journal을 commit한다. 재부팅 후 cache를 다시 검증하며 cache 손상 시 기존 호환 앱 조합을 유지하고 재업로드를 받는다.

## 5. STM32 부트로더와 ESP 제어

### 5.1 선택과 메모리

MCUboot의 `swap using offset` 방식으로 primary 고정 실행 주소를 유지한다. primary/secondary에 old/new 이미지를 보존하고 교체 상태를 기록해 재개한다. scratch 방식이나 `BFB2` option-byte 변경으로 bank를 뒤집는 방식은 채택하지 않는다. MCUboot는 이 MCU를 위한 완제품이 아니므로 CMake/bare-metal G474 port의 flash map, signature, fault handling을 구현·검증해야 한다. 검토 시 공식 최신 release는 v2.4.0이며 도입 시 정확한 commit을 lock한다. [MCUboot 설계](https://docs.mcuboot.com/design.html), [port 계약](https://github.com/mcu-tools/mcuboot/blob/main/docs/PORTING.md), [v2.4.0](https://github.com/mcu-tools/mcuboot/releases/tag/v2.4.0)

DBANK=1의 2KiB page를 전제로 한다. production option-byte profile을 최초 유선 provisioning 때 읽어 확인하고 OTA 중 변경하지 않는다. DBANK/WRP/NRST 설정이 다르면 erase 이전에 실패한다. [ST RM0440](https://www2.st.com/resource/en/reference_manual/dm00355726-stm32g4-series-advanced-armbased-32bit-mcus-stmicroelectronics.pdf)

| STM Flash 영역 | 시작 주소 | 길이 | 용도 |
|---|---|---|---|
| bootloader | `0x08000000` | `0x10000` /64KiB | signature 검증, UART 복구, swap; WRP 보호 |
| primary | `0x08010000` | `0x30000` /192KiB | 실행 이미지 + MCUboot header/TLV/trailer |
| secondary | `0x08040000` | `0x30800` /194KiB | offset swap의 추가 page 포함; 새 이미지 시작 `0x08040800` |
| policy/journal A | `0x08070800` | `0x1000` /4KiB | transaction·호환성 기록 |
| policy/journal B | `0x08071800` | `0x1000` /4KiB | 이전 세대 보존 |
| config A | `0x08072800` | `0x4000` /16KiB | 설정 snapshot |
| config B | `0x08076800` | `0x4000` /16KiB | 시험 앱용 snapshot |
| 예약 | `0x0807A800` | `0x5800` /22KiB | 끝 `0x08080000` |

MCUboot header는512B를 기준으로 linker vector 위치 `0x08010200`을 사용한다. `imgtool`과 port의 실제 sector 수·trailer·signature TLV 산식으로 최대 payload를 검증한다. 서명 이미지 전체180KiB 이하를 초기 gate로 두고, bootloader64KiB 이내도 실제 map 파일로 확인한다. 192KiB를 모두 C code에 사용할 수 있다고 계산하지 않는다.

### 5.2 부트·복구 순서

1. ESP는 `ESP_RUN_OK=0`을 유지하고 J31 제거를 확인한다. UART runtime queue와 control lease를 종료한다.
2. `STM_RECOVERY_N`을 LOW로 당기고 `STM_RESET_CMD_N`을 최소10ms LOW → HIGH로 해제한다. PB9 recovery 요청은 부트로더 HELLO를 받을 때까지 유지한다. BOOT0는 LOW다.
3. STM 부트로더는 CAN peripheral·ARM_EDGE를 활성화하지 않는다. UART2를115200 8N1, flow control 없이 시작한다. 검증된 프레임 단위 stop-and-wait로 수신하고, 완전한 flash operation 뒤 ACK한다. 일반 앱의4Mbps/RTS/CTS 상태를 이어받지 않는다.
4. 서명과 board ID를 검증한 manifest를 먼저 받아 secondary만 지운다. read-back·전체 hash·image signature 검증 후 PREPARED metadata만 기록한다. TEST pending은 기록하지 않는다. ACTIVATE_TEST 수신 후 transaction/package/target digest에 결합한 activation intent를 write/read-back/commit하고 그 뒤에만 TEST pending을 기록한다.
5. 재부팅 후 부트로더가 swap을 마치고 후보 앱을 실행한다. 단전 시 swap 기록에 따라 계속 진행한다. 후보 앱은 자체 검사와 ESP 관리 프로토콜 호환성 확인 뒤 확정한다. 실패/hang/reset은 revert한다.
6. pending TEST 상태가 없고 유효 primary가 있으면 그것을 부팅한다. 복구 요청 또는 유효 앱 부재이면 서명된 파일을 기다린다. 손상된 journal에서 임의 주소로 jump하거나 bootloader를 자동 erase하지 않는다.

SWD가 STM을 reset해도 ESP reset net은 올라가 있어야 한다. STM 내부 reset 시 PG10-NRST 출력 동작은 option-byte profile로 보장하고 검증한다. IWDG는 후보 앱 hang 복구용으로 사용하며 외부 TPS3431의 CAN latch 차단과 구분한다. TPS3431은 STM을 재부팅시키는 장치가 아니다.

G4 Flash는 doubleword/ECC 제약이 있으므로 기록을8B 정렬하고 같은 doubleword를 부분 재프로그램하지 않는다. 전원 차단 중 ECC 오류를 단순 CRC mismatch로만 처리하지 말고 NMI/Flash 오류를 안전 복구로 연결한다. bank1 쓰기 중 bootloader 실행·ISR fetch stall, 최악 page erase 시간, IWDG window를 port에서 분석한다. 필요한 flash critical code/벡터는 SRAM에 배치하고 `map`으로 검증한다. watchdog을 무기한 끄거나 인터럽트에서 무조건 feed하지 않는다.

### 5.3 ROM BOOT0 경로의 범위

BOOT0는 주 OTA 경로가 아니라 부트로더 최초 설치/물리 서비스용이다. J32 shunt가 없으면 ESP의 BOOT0 요청은 STM에 연결되지 않는다. J31 RUN 연결 상태에서는 추가 AND gate가 BOOT0 요청을 LOW로 강제한다. STM ROM UART를 사용할 때는 AN2606에서 G47/G48·UFQFPN48의 USART2 PA2/PA3 경로와 option-byte boot pattern을 확인하고, AN3155의 autobaud `0x7F`, 8E1, ACK/NACK를 사용한다. custom recovery의8N1/COBS와 섞지 않는다. [AN2606](https://www.st.com/resource/en/application_note/an2606-introduction-to-system-memory-boot-mode-on-stm32-mcus-stmicroelectronics.pdf), [AN3155 Rev21](https://www.st.com/resource/en/application_note/cd00264342-usart-protocol-used-in-the-stm32-bootloader-stmicroelectronics.pdf)

일반 웹/API에는 raw ROM 명령·mass erase·option-byte 수정·RDP 해제를 노출하지 않는다. WRP가 보호하는 부트로더를 ROM으로 다시 쓰려면 보호 해제가 필요하며 데이터 소실 가능성이 있다. 이 작업은 통제된 유선 서비스이고 자동 OTA 복구의 성공 경로로 계산하지 않는다.

## 6. 실제 회로 변경과 핀 계약

회로 정본은 [ota_circuits.py](../../tools/hardware/ota_circuits.py), 연결된 기존 core/power/sensor 생성 입력이다. 추가 부품은 U17 TLV803EA30DPWR, U50 SN74LVC1G07DBVR, U52/U53/U55 SN74LVC1G11DCKR, U54 SN74LVC1G04DBVR, U56 SN74LVC1G17DBVR, J31/J32 및 pull/decoupling/복구 버튼이다. [TI open-drain buffer](https://www.ti.com/lit/ds/symlink/sn74lvc1g07.pdf)의 DBV pin2=A, pin4=Y(open-drain)를 사용한다. Push-pull 출력으로 NRST를 HIGH 구동하지 않는다.

구형 MINI 회로와 구분해 Communicator 회로 title revision을 `R2 N16R8 REVIEW`, Controller 어댑터를 `R1.1 OTA REVIEW`로 갱신한다. OTA board ID는 `comm-r2-n16r8`, `controller-waveshare35-adapter-r1_1`, `bridge-r1-n8r2`, layout ID는 각 역할에 `ota-layout-v1`을 결합한다. 제조 provisioning과 bootloader가 역할별 상수를 보존하며 파일 입력값으로 바꾸지 않는다. 구형 `comm-r1-mini-n4r2`에는 새 파티션이나 핀맵을 적용하지 않는다. `docs/hardware/r1/`은 상세 설계 묶음의 기존 경로이며 회로 revision 식별자로 사용하지 않는다.

### 6.1 Reset 분리

U6(ESP)와 U17(STM)은 같은3V3를 각각 감시하고 MR만 `GLOBAL_RESET_N`에 연결한다. 각 reset 출력에는 개별10k pull-up이 있다. 공통 RESET 버튼은 두 MR을 당긴다. U50은 ESP GPIO1의 active-low 요청을 STM reset에 open-drain으로 전달한다. STM의 SWD reset, 내부 reset, U17 출력이 ESP CHIP_PU를 당기는 직접 연결은 제거한다. 모든 reset 관련 test point도 분리한다.

| 기능 | ESP WROOM GPIO / 물리 pad | STM 물리 연결 | reset/default |
|---|---|---|---|
| STM reset 요청 | GPIO1 /39 | U50 → PG10-NRST /7 | 외부10k PU; HIGH=해제 |
| ROM BOOT0 요청 | GPIO2 /38 | U55 →1k →J32 →PB8 /46 | 외부10k PD; J32 open; STM BOOT0도10k PD |
| 정상 동작 허용 | GPIO7 /7 | U53 입력 | 외부10k PD; OTA/boot/recovery에서는0 |
| ESP 복구 버튼 | GPIO8 /12 | 해당 없음 | 외부10k PU; 버튼=LOW |
| STM custom 복구 요청 | GPIO9 /17 | PB9 /47 | 외부10k PU; ESP open-drain LOW=요청 |
| 서비스 인터록 감지 | GPIO48 /25 | U56 Y →4.7k →SERVICE_RUN_SENSE | MCU측100k PD; J31 원신호와 MCU 출력 분리 |
| ESP reset | CHIP_PU /3 | U6 출력 | `ESP_RESET_N` |
| STM reset | 해당 없음 | PG10-NRST /7, SWD J10/10 | `STM_RESET_N` |

기존 UART는 ESP GPIO17TX→STM PA3RX, GPIO18RX←PA2TX, GPIO15RTS→PA0CTS, GPIO16CTS←PA1RTS를 유지한다. 각 physical pad와33Ω 직렬/flow-stop pull은 생성 pinmap에서 대조한다. STM reset 제어를 위해 UART pin을 재배정하지 않는다.

### 6.2 CAN 하드웨어 차단

`SERVICE_RUN`은 J31 물리 신호이며10k pull-down으로 shunt 부재 시0이다. U52/U54는 이 원신호를 읽고 MCU에는 직접 연결하지 않는다. U56 SN74LVC1G17의 A(pin2)→Y(pin4) 단방향 경로와4.7k 직렬 뒤 SERVICE_RUN_SENSE만 GPIO48에 전달한다. MCU측100k PD, U56의100n decoupling을 둔다. GPIO48의 잘못된 HIGH/LOW 출력은 원신호를 구동하지 못하고 충돌 전류는3.6V/4.7k≈0.77mA 이하다. J30 TX_ARM은 별개다. J31 제거 시 GPIO7/GPIO48 상태와 무관하게 RX/TX와 ARM latch를 차단한다. 정상 부품의 GPIO 출력 고장 모델이며 U56 내부 단락까지 포함한 모든 단일 부품 고장 보장은 아니다. [TI buffer pin/truth table](https://www.ti.com/lit/ds/symlink/sn74lvc1g17.pdf)

```text
MCU_HEALTH_N = ESP_RESET_N & STM_RESET_N & SERVICE_RUN
RUN_ALLOWED = MCU_HEALTH_N & ESP_RUN_OK & PHY_RESET_N
RX_ALLOWED = AUTO_GOOD & RUN_ALLOWED & PHY_RESET_N
ARM_HEALTH_N = WD_OK_N & RUN_ALLOWED & AUTO_GOOD
ARM_CLEAR_N = ARM_HEALTH_N & PHY_RESET_N & TX_ARM
ARM_LATCH = DFF(D=1, CLK=STM_ARM_EDGE, asynchronous_clear=ARM_CLEAR_N)
TX_PERMIT = ARM_LATCH & ARM_CLEAR_N & RX_ALLOWED
GPS_PWR_EN = GPS_PWR_REQ & AUTO_GOOD & RUN_ALLOWED
```

U52/U53은 PHY3V3로 구동하며 해당 logic의 Ioff와 기존 FT active-high OE의1k pull-down을 유지한다. PHY3V3가 없을 때의 정적 차단과 전원 하강 중 지연은 구분해 시험한다. J31을 다시 끼우거나 watchdog이 회복되어도 지워진 latch는 새 STM ARM edge 없이는 올라가지 않는다. 서비스 종료 시 stale ARM edge/queue를 폐기한다. 펌웨어 미구현 상태의 GPIO7 기본 LOW는 정상 CAN RX도 차단한다. 이 인터록을 우회하는 임시 pull-up을 추가해서 bring-up하지 않는다.

### 6.3 Controller와 Bridge

Controller 어댑터 J1/13(원보드 J8/13 GPIO41)에10k pull-up과 RECOVERY 버튼, J1/22 RESET에 sink-only HOST_RESET 버튼을 추가한다. 카메라는 분리·비활성화한 variant만 허용한다. GPIO38/39/40 마이크 LVDS 회로와 충돌하지 않는다. 복구 앱이 정상 LCD driver에 의존하지 않도록 IP/암호/버튼 절차를 제품 라벨에 남긴다.

Bridge는 기존 GPIO4 PAIR와 RESET을 재사용하므로 OTA용 추가 IC가 필요 없다. reset 중 PAIR5초는 복구 앱, 정상 실행 중 PAIR3초는 commissioning으로 명확히 구분한다. GPIO0 BOOT는 ROM download다. Bridge의 회로와 권한에 차량 TX 경로를 추가하지 않는다.

## 7. 패키지·인증·보안 계약

패키지는 압축 archive를 해제하는 구조 대신 작은 길이 제한 manifest와 순차 image blob을 갖는 `.cvota` 컨테이너다. 파서가 임의 파일 경로·외부 URL·Flash 절대주소를 받아들이지 않는다. revision2는 최대3개 image, manifest16KiB, 개별 blob 길이는 대상 슬롯 이하, HTTP chunk16KiB 이하로 제한한다. Controller/Bridge 단일 image, Communicator는 ESP/STM 최대2개를 선택한다.

[ADR-009](../adr/009-ota-native-image-alignment.md)에 따라 header magic은 `CVOTA002`,
version은2이며 미배포 compact version1은 거절한다. 첫 image offset은 작은 prefix
(24B header+manifest+64B 서명) 끝을64KiB 경계로 올린 값이다. 다음 image는 이전
image 끝을 같은 경계로 올린 위치에 둔다. 사이 padding은0만 허용하고 최대16KiB
chunk에서 검사한다. 마지막 image 뒤 padding은 금지한다. 총길이에는 padding을
포함하지만 signed image length/hash에는 포함하지 않는다. native SDK 검증을 위한
staging 시작도64KiB 정렬이어야 한다. prefix buffer를64KiB로 키우지 않는다.

| 서명 manifest 필드 | 의미와 검증 |
|---|---|
| `format_version`, `package_id` | version2,128bit ID; 지원하지 않는 버전 거절 |
| `role`, `board_revision`, `layout_id` | 대상 장치·회로·파티션 일치; 사용자 입력으로 override 금지 |
| `release`, `security_epoch`, `key_id` | release는 표시용; 제조 고정 epoch와 역할별 서명키 대조 |
| `images[]` | enum target, byte length, SHA-256, firmware version, signed release_sequence:u64, image signature |
| `compatibility` | ESP/STM/peer의 지원 ABI 범위와 허용 조합 목록 |
| `config_schema` | 읽을 수 있는 schema 범위와 새 snapshot schema |
| `requires` | 최소 bootloader/recovery ABI, hardware capabilities |

정규화된 CBOR manifest의 정확한 byte열을 서명하고, duplicate key·unknown critical field·길이 overflow·중첩 제한 초과를 거절한다. 컨테이너 header의 lengths와 signed lengths를 비교한다. 역할/board/layout/호환성 검증 뒤에만 비활성 슬롯을 지우고, 전체 image 검증 전에는 부팅 표시를 변경하지 않는다. unsigned CRC는 전송 손상 검사일 뿐 인증이 아니다.

기존 revision2 byte 배정은 [wire schema](../../protocol/schema/ota-container-v2.yaml),
packager 작성용 JSON 표현은 [JSON schema](../../schema/cvota-v2.schema.json)에 기록한다.
작성용 JSON은 차량 wire/API가 아니며 서명 전 CBOR 변환 성공도 package 인증이 아니다.
schema 파일 존재와 최종 독립 리뷰·native image/target 통합 완료를 구분한다.

ESP는 production Secure Boot V2 + Flash Encryption, STM은 부트로더 내 공개키로 ECDSA-P256/SHA-256 image 검증을 기본으로 한다. manifest 서명은 ECDSA-P256으로 별도 검증한다. STM은 ESP의 검증 결과만 신뢰하지 않고 자기 signed protected TLV의 board/role/ABI와 image hash·서명을 다시 검사한다. Flash 주소는 bootloader의 enum→고정 map으로만 결정한다. private signing key를 장치·웹·Git에 넣지 않는다. dev와 production root는 분리하고 Bridge 서명키로 Communicator 이미지를 허용하지 않는다.

`test` 복구 앱과 ESP 표준 hardware anti-rollback은 함께 사용할 수 없다. 따라서 이번 availability 우선 baseline은 `CONFIG_BOOTLOADER_APP_ANTI_ROLLBACK=n`이며 OTA에서 eFuse security epoch/키 폐기를 변경하지 않는다. 같은 security epoch 내에서 이전 정상 앱 복귀를 허용하고, 일반 웹의 자의적 downgrade는 signed manifest 정책으로 제한한다. 이는 물리 공격까지 막는 단조 hardware anti-rollback 보장이 아니다. 강한 anti-rollback이 요구되면 test 복구 구조·키 관리까지 별도 재설계해야 한다. [v6.0.3 test Kconfig](https://github.com/espressif/esp-idf/blob/v6.0.3/components/bootloader/Kconfig.projbuild), [v6.0.3 rollback Kconfig](https://github.com/espressif/esp-idf/blob/v6.0.3/components/bootloader/Kconfig.app_rollback)

보안 기능의 최초 eFuse/option-byte provisioning은 전원이 안정된 작업대에서만 한다. Secure Boot를 켰다는 이유로 ROM/SWD 복구가 항상 가능하다고 표시하지 않는다. UART secure download/JTAG/RDP/WRP 조합과 서명된 복구 앱까지 시험한 뒤 production으로 잠근다. [Espressif provisioning](https://docs.espressif.com/projects/esp-idf/en/v6.0/esp32s3/security/security-features-enablement-workflows.html)

AP는 장치별 강한 WPA2 암호, 물리적으로 연10분 세션,1개 관리 client를 기본으로 한다. HTTP 로컬 경로는 공용 인터넷에 노출하지 않는다. 업데이트 요청은 로그인 세션·난수 CSRF token·Origin/Host allowlist·Content-Type·request size 검사를 거친다. CORS를 열지 않고 STA에서 수신 업데이트 포트는 기본 닫는다. 상태/log 내 token/키/VIN/좌표/capture를 노출하지 않는다. 타임아웃은 monotonic clock으로 재며 RTC 시간이 틀려도 오프라인 서명 검증이 가능하다. 온라인 HTTPS 인증서 검증을 RTC 문제 때문에 끄지는 않는다.

### 7.1 영속 버전 하한과 복원 예외

ESP 정상 앱·불변 recovery 앱·STM bootloader가 같은 policy-v1 규칙을 사용한다. 문자열 버전 비교를 금지하고 signed release_sequence를 image와 manifest에서 대조한다. STM protected TLV에도 동일 값을 넣는다. security_epoch는 최초 제조 상수와 일치해야 하며 OTA로 변경하지 않는다.

각 target의 권위 record는 min_accepted_sequence:u64, confirmed_digest, previous_known_good_digest/sequence, board/layout/epoch, trial transaction, generation, CRC와 마지막 commit marker를 가진다. ESP는 §4 OTA journal A/B, STM은 §5 policy/journal A/B에 저장한다. 각 copy는 전체 policy와 현재 transaction snapshot을 담고 고정 인코딩 최대3072B를 CI로 제한한다. 4KiB copy 교체 중에도 다른 copy를 보존한다. image 본문/chunk log를 넣지 않는다. recovery도 정상 NVS 대신 이 규격을 읽는다.

- 수신 sequence가 floor 미만이면 erase 전에 거절한다. floor와 같지만 confirmed_digest와 다르면 CONFLICT다. sequence와 digest가 모두 같을 때도 policy만 보고 이미 설치됨으로 응답하지 않는다. 정상 앱의 실제 전체 image hash·서명·board/layout·부팅 선택 metadata를 검증해 정상 부팅 가능한 설치본이 확인된 경우에만 ALREADY_INSTALLED다. recovery 앱 자체나 policy의 confirmed flag는 그 증거가 아니다.
- 같은 sequence/digest인데 정상 앱이 손상됐거나 부팅 선택이 불가능하면 동일 정식 bundle의 REPAIR 재설치를 허용한다. 새 sequence가 없어도 복구 가능해야 한다. target allowlist·인증·전체 image 검증·PREPARED·새 사용자 activation commit·trial/confirmation은 동일하게 적용하며 floor는 올리거나 내리지 않는다. 기존 transaction의 성공 결과도 손상 여부를 생략하는 근거로 재사용하지 않는다. status가 REPAIR_REQUIRED를 보고하고 새 repair transaction을 연다. 정상본이 남아 있으면 보호하고, 정상본이 없으면 허용된 비활성/복구 수신 slot에만 기록한다. bootloader/recovery 영역을 덮어쓰지 않는다. 수리 중 단전은 동일 signed bundle 재업로드 또는 이미 승인된 repair 재개로 복원한다.
- floor 초과 image는 나머지 서명·호환성 검증 뒤 정상 upgrade 후보로 받는다. 위 REPAIR는 정확히 같은 signed sequence/digest만 허용하는 예외이며 임의 구버전·변조 이미지 허용이 아니다.
- 시험 앱 local health 통과 후, boot library image confirmation 이전에 CONFIRM_INTENT(candidate sequence/digest, old known-good, transaction)를 영속화한다. 실제 confirmation 뒤 floor/confirmed_digest를 갱신한다. 부팅 때 update API와 서비스 종료보다 먼저 확인된 실행 digest/boot 상태를 intent와 대조한다. 실제 확인 완료가 일치하면 floor commit을 마친 뒤 API를 연다. 아직 시험 중이면 확인 전 절차를 계속하며 실패/revert이면 이전 floor와 설정을 유지한다. 상태가 해석되지 않으면 복구 격리한다.
- 자동 rollback은 활성 trial 실패와 그 transaction에 보존한 previous-known-good digest로만 허용한다. 옛 파일 업로드나 manifest의 rollback 표시는 예외가 아니다. 확인 완료 후 임의 과거 앱 선택도 금지한다. rollback용 이전 app/config는 trial 종료 전 지우지 않는다.
- recovery를 포함해 두 policy copy가 모두 손상되면 floor를0으로 초기화하지 않고 RECOVERY_LOCKED로 둔다. 웹은 상태만 제공하며 Flash 쓰기·차량 송신은 금지한다. 서명·제조 이력을 대조하는 통제된 작업대 재-provisioning이 필요하다. 한 copy라도 valid이면 그 정책으로 복구한다.

정상 OTA 입력과 전원 차단에 대한 소프트웨어 정책이며, 공격자가 Flash 전체를 임의 변경하는 물리 공격에 대한 hardware monotonic counter 보장은 아니다.

## 8. 응답 확인·멱등성·전송 중단

브라우저 HTTP200, Wi-Fi 전송 성공, UART ACK, 이미지 검증, 재부팅 성공, 최종 확정은 서로 다른 상태다. 상태 API에는 `device_id`, `boot_id`, `transaction_id`, `package_hash`, `target`, `phase`, `bytes_verified`, `running_version`, `confirmed_version`, `result`, `error_code`를 포함한다. 웹은 서버의 이 값으로 진행률을 복원한다.

| API | 기능 | 완료 응답 조건 |
|---|---|---|
| `GET /api/ota/v1/status` | 역할/설치 상태/직전 결과 | 민감 정보 제외한 현재 장치 상태 |
| `POST /api/ota/v1/transactions` | signed manifest 검증·exclusive session 생성 | target/전원/서비스/공간 검사 후 `READY` |
| `PUT /api/ota/v1/transactions/{id}/images/{target}` | 순서대로 chunk 수신 | offset·chunk hash 확인, Flash write/read-back 완료 |
| `POST .../{id}/prepare` | 전체 이미지/호환성 검증 | verified metadata만 영속화한 PREPARED; boot selector/TEST pending 변경 없음 |
| `POST .../{id}/activate` | 시험 부팅 승인 | 인증된 승인 intent의 write/read-back/commit 후 ACCEPTED; 성공은 후속 STATUS |
| `POST .../{id}/cancel` | 설치 승인 전 취소 | ACTIVATION_COMMITTED 전만 허용; 이후 TOO_LATE, swap 시작 여부와 무관 |

전체 HTTP retry는 같은 idempotency key·transaction·package hash로 수행한다. 같은 요청의 재전송은 저장된 결과를 돌려주며 다른 payload를 같은 ID로 보내면 `CONFLICT`다. 진행 중 다른 업데이트는 `BUSY`다. 인증·CRC·schema·hash 오류는 자동 재시도하지 않는다. Communicator의 HTTP WRITE는 먼저 내부 staging에 기록하고 PREPARE는 bundle 검증 완료를 뜻한다. 이후 각 MCU에 쓰는 PREPARE/시험 부팅 결과는 target별 phase로 구분한다. Controller/Bridge는 직접 비활성 앱 slot에 받는다.

STM custom recovery UART 프레임은 COBS + `0x00` delimiter, little-endian 정수, CRC32C다. header는 `magic:u16, version:u8, type:u8, transaction_id:16B, request_id:u32, offset:u32, payload_len:u16, status:u16`, payload≤512B, CRC4B이며 COBS 포함 frame 상한576B다. magic/version/type을 먼저 검사하고 allocation 없이 정적 버퍼로 처리한다. CRC polynomial/초기값/reflection/xor-out, 모든 enum·golden vector는 구현 때 schema 정본에 고정한다.

명령은 `HELLO, BEGIN, WRITE, STATUS, PREPARE, ACTIVATE_TEST, CANCEL`만 둔다. HELLO에는 MCU identity, board/layout/bootloader ABI, 현재/후보 digest, reset cause, swap state가 있다. ACK는 request/transaction/offset/length/digest를 echo한다. WRITE ACK는 해당 Flash 기록을 read-back한 뒤 보낸다. 유효한 동일 chunk 중복은 재기록하지 않고 ACK한다. 앞선 offset에 다른 데이터, hole, 초과 length는 거절한다. PREPARED는 서명 검증 결과·후보 digest만 영속화한다. ACTIVATE_TEST는 해당 후보의 activation intent를 먼저 commit하고 MCUboot TEST pending을 그 뒤 기록한다. 재부팅 시 valid activation intent와 검증된 후보가 모두 있어야 미완료 pending 기록을 완성한다. PREPARED만 있으면 primary를 유지한다. 새 pending이 있으나 intent가 없거나 손상됐으면 추정 설치하지 않고 복구 격리한다. 이미 진행 중인 swap/revert는 MCUboot 자체 journal 규칙을 따른다.

UART response timeout 기본2초, 같은 요청 최대3회 retry, erase/prepare는 `IN_PROGRESS`와 최대30초 deadline을 사용한다. 이 시간은 G4 worst-case flash와 서명 실행 측정 후 줄이거나 늘린다. ESP가 timeout만 보고 이미 실행 중인 erase/swap을 중복 시작하지 않으며 STATUS로 판정한다. ACTIVATE_TEST 뒤 ACK가 유실되면 재부팅 후 boot_id와 실제 image digest를 조회한다. 최종 `CONFIRMED`는 STM 자신이 기록하고 자기 부팅에서 보고해야 한다.

전송 재개는 v1에서 단순하게 제한한다. **같은 부팅·같은 transaction 안에서만 chunk retry를 보장**한다. 전원 차단/ESP·STM reset으로 boot_id가 달라지면 미완료 blob은 처음부터 다시 보낸다. 미완료 secondary/비활성 ESP slot만 지우므로 기존 정상 앱은 유지된다. PREPARED는 재부팅 뒤에도 승인 대기다. ACTIVATION_COMMITTED 이후에만 브라우저 없이 승인된 plan의 설치/rollback을 이어간다. 앱 교체 중간 복구를 사용자가 다시 전송해야 하는 다운로드 재개와 혼동하지 않는다.

### 8.1 승인 commit 경계

PREPARED는 verified metadata/cache가 있다는 뜻일 뿐 설치 권한이 아니다. boot selector나 STM TEST pending을 미리 기록하지 않는다. 인증된 activate 요청은 현재 PREPARED의 transaction/package/ordered target digests에 결합한 immutable plan과 ACTIVATION_COMMITTED marker를 write/read-back/commit한 뒤 ACCEPTED를 보낸다. 그 다음에만 ESP boot selector 또는 STM ACTIVATE_TEST를 변경한다.

commit 전 단전이면 torn intent는 무효이며 기존 앱 + PREPARED_WAIT다. commit 뒤 ACK가 유실되면 STATUS가 ACTIVATION_COMMITTED 또는 더 진행된 실제 상태를 반환한다. 동일 activate retry는 저장된 결과만 돌려주고 다른 plan은 CONFLICT다. cancel/activate는 단일 writer가 직렬화하며 먼저 영속 commit된 전이가 이긴다. CANCELLED 뒤 activate는 거절하고 activation commit 뒤 cancel은 TOO_LATE다. reboot/timeout을 사용자 승인 대신 사용하지 않는다.

## 9. 상태기계와 두 MCU의 호환성

```text
IDLE -> SERVICE_LOCKED -> RECEIVING -> VERIFYING -> PREPARED_WAIT
     -> [사용자 ACTIVATE 영속 commit] -> ACTIVATION_COMMITTED
     -> TRIAL_BOOT -> LOCAL_HEALTH_OK -> CONFIRMED -> SERVICE_EXIT
RECEIVING/VERIFYING 중 reset: 기존 앱, 부분 image 폐기 또는 재업로드
activation commit 전 단전: 기존 앱, 승인 대기, 취소 가능
activation commit 후 단전/ACK 유실: 승인 plan 재검증 후 계속, 취소 TOO_LATE
TRIAL_BOOT 중 reset/실패: 이전 앱으로 ROLLBACK
swap 중 reset: MCUboot journal에 따라 swap/revert 재개
유효 앱 부재/상태 해석 불가: RECOVERY_WAIT, CAN 계속 차단
```

모든 상태에서 reset 기본값은 GPIO7 LOW이고, Communicator 서비스 동안 J31도 제거된 상태다. 어떤 journal이 손상돼도 service 종료나 CAN 허용을 추정하지 않는다. UI를 사용할 수 있는 Controller는 업데이트 중 주행 데이터가 표시되지 않음을 알리고, 차량 연결이 정상일 때 speed=0이5초 유지되어야 시작한다. CAN이 없는 USB 작업대/복구 경로는 속도 데이터 부재만으로 영구 차단하지 않고 물리 service 진입을 사용한다.

ESP/STM 사이에는 진정한 원자적 동시 commit이 없다. 이를 숨기는 `두 MCU 모두 완료` 플래그 하나를 두지 않는다. 릴리스는 `(ESP_old,STM_old)`, `(ESP_new,STM_old)`, `(ESP_old,STM_new)`, `(ESP_new,STM_new)`와 각각의 recovery ABI를 모두 검사한다. 모든 조합이 관리·복구 통신을 지원해야 한 번의 bundle로 허용한다. 새 기능은 capability가 교집합인 동안만 동작한다.

기본 순서는 전체 bundle 내부 staging 검증 → PREPARED_WAIT → 사용자 승인과 plan 영속 commit → ESP의 새 호환 앱 설치·자체 확정 → staging 재검증 → STM 설치·시험 부팅·확정이다. 승인 commit 후만 휴대폰 없이 계속 진행한다. immutable plan은 transaction/package/ordered target digests에 결합하며 ESP 교체 후에도 동일하게 읽는다. STM ACTIVATE_TEST도 이 plan의 승인 범위 안에서만 수행한다. 재부팅을 승인으로 추정하지 않는다. STM 정상본은 MCUboot secondary에 보존한다. 어느 단계에서든 전원이 꺼지면 실행 중 조합을 HELLO에서 재평가한다. 전체 bundle 완료는 두 MCU의 확인된 실제 digest가 manifest와 일치할 때만 기록한다. 이미 확정된 다른 MCU를 임의로 rollback 표시해 원자성을 흉내 내지 않는다. staging이 손상되면 현재 호환 조합을 보존하고 파일 재선택을 요청한다.

네 조합이 호환되지 않는 변경은 먼저 구버전/신버전을 모두 이해하는 중간 호환 릴리스를 설치하는 단계적 migration을 배포한다. 최소 recovery ABI를 넘는 패키지는 설치 전에 거절하고 유선 서비스 필요로 표시한다. Controller/Bridge의 구버전 부재를 이유로 Communicator 자신의 복구를 막지 않는다. 차량 제어 profile/권한은 firmware 호환성과 별도 검증하며 OTA 완료가 VEHICLE_TX 승인으로 이어지지 않는다.

ESP와 STM journal의 각 record에는 generation, phase, target hashes, CRC, 마지막에 기록하는 commit marker가 있다. 반대편 sector의 유효 record를 지우기 전에 새 record write/read-back/commit을 완료한다. 부팅 시 highest valid generation만 채택하고 둘 다 불명확하면 안전 복구를 선택한다. STM MCUboot swap/trailer는 자체 형식을 그대로 사용하며 공통 journal로 대체하지 않는다.

config는 기존 앱이 읽는 snapshot을 보존하고 후보 앱용 snapshot을 별도로 작성한다. 후보 확정 전에 원본 schema를 파괴적으로 migration하지 않는다. rollback 시 이전 앱은 자신의 snapshot을 선택한다. OTA가 NVS 초기화 실패를 만나면 `nvs_flash_erase()`로 pairing/설정을 없애는 예제 코드를 사용하지 않는다. config·profile·firmware의 복구 호환성을 함께 시험한다.

## 10. 외장 SPI NOR 검토 결과

독립 검토자 Heisenberg(`01a073c2-a5ee-7100-8b44-5d2336652ba4`)는 ESP A/B + STM 내부 swap으로 정상 전원 차단 복구가 가능하므로 외장을 필수로 보지 않았다. 원안의 W25Q128JV16MiB 상시 실장은 철회했다. **이번 회로에는 외장 NOR·전용 SPI 배선·footprint를 추가하지 않는다.** 이후 사용자가 N16R8을 지정하여 내부16MiB에 bundle staging까지 확보했다. 외장은 여러 세대 장기 백업 같은 추가 요구가 생길 때 검토한다.

| 질문 | 판정 |
|---|---|
| OTA 도중 단전에서 정상본 보존에 필수인가 | 아니다. ESP 비활성 slot과 STM primary/secondary가 담당 |
| 휴대폰 연결이 끊겨도 설치할 수 있는가 | ACTIVATION_COMMITTED 이후 가능; PREPARED는 승인 대기, 미완료는 재업로드 |
| 외장의 추가 가치 | 여러 버전의 signed bundle/STM 정상본을 장기 보관, 재업로드 없는 복구 |
| ESP 내부4MiB 앱 슬롯을 늘리는가 | 아니다. 추가 SPI NOR를 boot-mapped app slot처럼 사용할 수 없음 |
| 추가 위험 | 부품·면적·SPI/전원 검증 부담; 유일한 복구본으로 의존하면 추가 고장점 |
| PSRAM 대체 가능성 | 전원 소실 시 내용이 사라지므로 영구 백업에 사용할 수 없음 |

이 판정은 외장 캐시가 아무 이점도 없다는 뜻이 아니다. unattended fleet 업데이트가 목표가 되면 별도 cache를 선택할 수 있지만 없어도 내부 복구 앱과 재업로드가 동작해야 한다. [ESP SPI Flash API](https://docs.espressif.com/projects/esp-idf/en/v6.0/esp32s3/api-reference/peripherals/spi_flash/index.html)

## 11. 전원 정책과 복구 경계

OTA 시작은 stable power5초, supervisor 정상, 충분한 비활성 저장공간, 서비스 인터록 상태를 검사한다. `USB_SERVICE_SENSE`는 mux source 표시이지 PGOOD가 아니다. 이를 안정된 USB 전압의 증명으로 사용하지 않는다. 실제 rail 측정/qualifier가 없는 조건에서는 전압 수치를 만들어 내지 않고 `전원 연결됨/감시 정상/전압 미측정`을 구분한다.

짧은 순간단전 대응을 위해 기존 mux/decoupling을 유지하지만 큰 supercap으로 업데이트 전체를 끝낼 수 있다고 계산하지 않는다. 수십 초 OTA 유지용 에너지 저장은 부피·돌입전류·수명·buck 안정성 비용이 크다. 이번 방식은 완주에 필요한 hold-up을 전제하지 않고 중단된 작업을 복구한다. 안정된 USB 보조 전원은 권고하지만 복구의 논리적 전제는 아니다.

전압 저하 감지 시 신규 erase/program 요청을 중지하고 진행 중 Flash operation의 제조사 조건을 따른다. 완전히 꺼지면 supervisor/reset/pull/PHY gate가 안전 상태로 수렴한다. 최악 rail collapse 중 잘못된 Flash 쓰기와 CAN dominant pulse는 실물 시험으로 확인한다. 불안정 전원 반복 부팅에서는 최신 update attempt를3회 이상 자동 반복하지 않고 복구 대기로 남긴다. 서비스 종료·pairing 초기화·자동 차량 제어 재개로 탈출하지 않는다.

불변 부트로더/복구 앱이 물리 손상되거나 최초 provisioning이 중단되면 웹 복구가 불가능할 수 있다. ESP ROM/SWD 작업대 복구 가능 여부는 보호 설정에 달렸으며, 복구가 막힌 production 보드는 교체가 필요할 수 있다. 일반 OTA가 이 영역을 쓰지 않는 이유다.

## 12. 구현 모듈과 검증 수용 기준

구현 의존 방향은 웹/ESP-NOW adapter → `ota_manager` 상태기계 → platform flash/crypto/reset/UART이다. `ota_manager`는 ESP-IDF/HAL 레지스터를 직접 참조하지 않는다. STM bootloader와 normal application은 별도 CMake target/링커/서명 artifact다. ISR은 UART 바이트/오류를 bounded queue에 넣고 파싱·검증·Flash 작업을 task/main context로 넘긴다. Flash writer는 target당1개이며 OTA journal 소유권도 그 writer에 둔다.

실행 순서는 다음 gate를 모두 통과해야 한다. 이 목록은 후속 상세 task로 옮길 수 있는 구현 단위이며 아직 수행 완료 목록이 아니다.

| 단계 | 산출물 | 완료 기준 |
|---|---|---|
| OTA-01 | signed container schema/parser/CLI packager | wrong role/layout/signature, integer overflow, malformed CBOR, truncated blob 거절; golden vectors |
| OTA-02 | ESP 파티션·recovery3종 | signed app 크기 gate; PSRAM/SD/LCD/정상 NVS 없이 recovery AP 실행 |
| OTA-03 | G474 MCUboot CMake port | map/WRP/DBANK 검증; header/trailer 경계; interrupted swap/revert 반복 |
| OTA-04 | ESP↔STM boot UART | duplicate/reorder/lost ACK/reset_id, timeout, malformed frame, wrong signed TLV 시험 |
| OTA-05 | 브라우저 UI·세션 | Android Chrome/iOS Safari에서 기본 파일 선택·오프라인AP·재접속·결과 확인 |
| OTA-06 | compatibility·config migration | 네 ESP/STM 조합과 Controller/Bridge old/new, rollback config 보존 |
| OTA-07 | 제조 provisioning | 키/보호 설정/복구 버튼·UART·unplug 절차를 샘플에서 검증; 유선 최초 설치 |
| OTA-08 | HIL 전원·CAN | 아래 고장 주입 및 회로 gate 측정; 차량 연결 전 작업대 완료 |

| 고장 주입 | 기대 결과 |
|---|---|
| 매4KiB ESP erase/write, otadata 각 기록 전후 전원 차단 | 이전 앱 또는 정상 새 앱, invalid image 실행 없음 |
| STM 매2KiB erase,8B write, swap status/confirm 전후 차단 | swap/revert 재개 또는 명시 recovery; bootloader 보존 |
| ESP/STM 한쪽만 reset, 두 쪽 reset, SWD reset | ESP가 STM reset으로 죽지 않음; CAN latch clear |
| 후보 panic/hang/IWDG, UART 무응답/CTS 고정 | 미확정 후보 rollback; old/new digest로 실제 상태 판정 |
| J31 제거/재삽입, GPIO7 HIGH·GPIO48 HIGH/LOW 고착, STM ARM 지속 | buffer 역구동 차단; J31 제거 시 PHY 차단; 재삽입 시 새 ARM 없이 TX 없음 |
| AUTO5V/PHY3V3/3V3 독립 하강·USB/차량 hot-plug | 역급전/잘못된 PHY enable/dominant pulse 제한을 실제 측정 |
| 휴대폰 잠금/브라우저 종료/AP channel 변경 | 미완료는 재업로드, PREPARED는 승인 대기, 승인 commit 후만 local 설치 |
| activation commit 직전/직후 단전·ACK 유실·중복 activate/cancel | commit 전 boot 변경0·취소 가능; 이후 동일 plan만 계속·TOO_LATE; torn record는 승인 아님 |
| 확정 직전/직후와 floor 갱신 사이 단전·구버전 recovery | confirmed digest와 CONFIRM_INTENT 재조정; 정책 적용 전 update API 닫힘; 구 signed bundle 거절 |
| policy A/B 기록 중 단전·두 사본 손상 | 이전 valid floor 보존; 양쪽 불명확하면 RECOVERY_LOCKED, floor0 초기화 금지 |
| 잘못된 파일·다운그레이드·다른 보드·서명·빈 용량 | erase 대상 제한, 유효 정상본/설정 보존 |
| 앱 양쪽 invalid·정상 NVS 손상·PSRAM 불량 | 물리 버튼으로 복구 앱, CAN TX0; 숨은 초기화 의존 없음 |
| policy 정상·normal 앱 양쪽 invalid·최신보다 높은 릴리스 없음 | 현재 정식 sequence/digest bundle로 REPAIR 허용; 실제 trial/confirmation 뒤 정상 부팅·floor 불변 |
| 동일 버전 REPAIR 중 단전·승인 ACK 유실·과거 성공 transaction 재전송 | 손상 앱을 ALREADY_INSTALLED로 오판하지 않음; 새 repair 승인 경계·재업로드/재개·CAN 차단 유지 |
| 잘못된 DBANK/WRP/ROM strap/J32 absent | erase 전에 거절; 무단 보호 해제/ROM 진입 없음 |

단계별 결정적 cut point 전수 시험 + 무작위 시점1000회 이상을 각 hardware variant에서 수행한다. 성공률뿐 아니라 발견된 brick, reset loop, Flash ECC/NMI, CAN dominant 폭, 복구 소요와 로그를 기록한다. 0건 실패도 모든 물리 고장에 대한 수학적 보장으로 표현하지 않는다. host Boolean 검사·ERC 통과로 아날로그/Flash/HIL 시험을 대체하지 않는다.

## 13. 변경 산출물과 실행 검증

회로 열기: [Communicator PDF](../../hardware/communicator/schematic.pdf), [Controller 어댑터 PDF](../../hardware/controller-adapter/schematic.pdf), [Bridge PDF](../../hardware/bridge/schematic.pdf). 부품/핀은 각 보드의 `bom.csv`, `pinmap.csv`, `connectivity.json`, 실제 KiCad `.net`/XML로 교차 검증한다. PCB 배치·배선·제작은 이번 범위가 아니다.

Windows 검증 명령:

```powershell
.\tools\hardware\export-review.ps1
& 'C:\Program Files\KiCad\10.0\bin\python.exe' -m unittest discover -s tools\hardware -v
python tools\validate_document_links.py
git diff --check
```

2026-09-06 실제 실행: KiCad10.0.6 전체 재생성·4보드 ERC 각0개, component/physical pad/BOM/netlist 정합성 PASS, 기존 전원 margin 계산 PASS, hardware 회귀9개 PASS다. Communicator는292개 physical item/947개 named pad, Controller 어댑터는19개/87개다. 128개 Boolean 입력 조합과 GPIO48 HIGH/LOW 고착·J31 제거/재삽입 순서 시험은 정적 논리 검증이며 아날로그 타이밍을 입증하지 않는다. 생성 중 Bridge BOM 접근이 한 번 실패했고 전체 재실행에서 정상 종료했다. 원본 리뷰의 Markdown hard-break 후행 공백은 보존하므로 이 파일만 `git -c core.whitespace=-blank-at-eol diff --check`로 검사하고 나머지 파일은 기본 whitespace 검사한다. 문서 링크와 immutable hash의 최종 결과는 §14에 누적한다.

`setup-windows.ps1 -VerifyOnly`는 PATH에 `cmake`가 없어 실패했다. 따라서 N16R8 defaults는 공식 SDK Kconfig와 대조했으나 target build·실물 메모리 검사는 미실행이다. firmware OTA/HIL도 미실행이며 이 문서와 회로를 OTA 완제품으로 표시하지 않는다. 기존 MAX20040 U8 footprint의 `PROVISIONAL` 및 전원/HIL gate도 유지한다.

## 14. 독립 적대적 리뷰 기록

원본 요청은 Bridge 없는3장치 독립 OTA, 범용 브라우저 업데이트, ESP가 STM을 관리하는 회로, 전원 차단 우선 설계, 단일 MD와 실제 회로 변경이다. 사용자 추가 요청에 따라 외장 NOR 필요성을 별도 전문 검토한 결과를 §10에 반영했다.

전문 리뷰어 A는 reset/전원/PHY/Flash 고장 복구를, B는 update protocol/서명/버전 조합/저장공간과 사용자 복구 경로를 독립적으로 공격한다. 동일 immutable commit을 object-only로 읽게 하고 원본 결과·severity·수정·재검증을 이 절에 누적한다. 리뷰 결과를 기록하기 전까지 최종 판정은 대기다.
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

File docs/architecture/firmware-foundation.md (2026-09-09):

# 펌웨어 기반 구조와 후속 구현 계약

## 범위와 현 상태

2026-09-06 사용자 요청에 따른 기반 구현이다. 세 장치·네 MCU target의 프로젝트 구조,
MCU 독립 framing/CRC/COBS/classic CAN batch/sequence window, 안전 idle 부팅, host 검증을 제공한다.
언어와 문서 도구 결정은 [ADR-008](../adr/008-portable-foundation-and-api-docs.md)을 따른다.

2026-09-07 T-200a의 Communicator ESP32 core를 T-400a에서 Bridge와 [공용 bench core](../../firmware/docs/esp-core-bench.md)로 추출했다. `firmware/app/esp_core.c`가 boot/health·고정 pool을 조합하고 `firmware/module/esp_core`와 interface는 SDK 독립 C99다. `firmware/platform/esp32s3/core_runtime.c`와
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

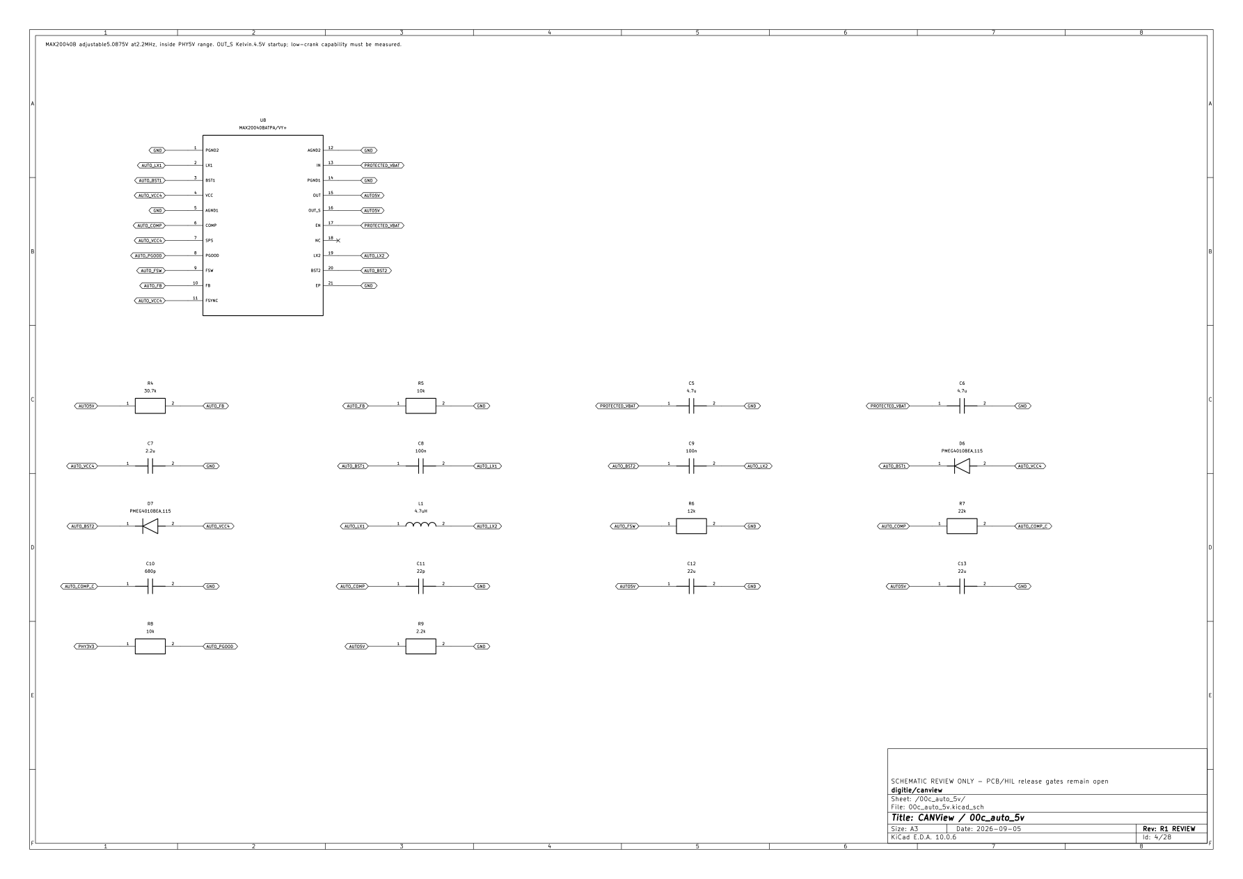
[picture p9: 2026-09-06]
hardware/communicator/preview.png

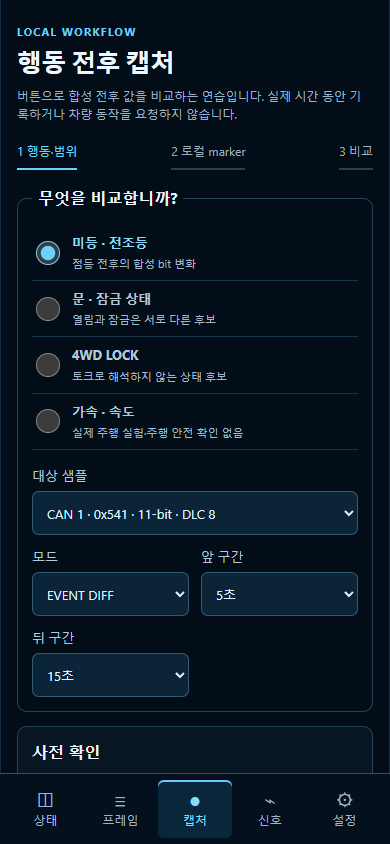
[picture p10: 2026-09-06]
docs/images/diagnostic-capture.png

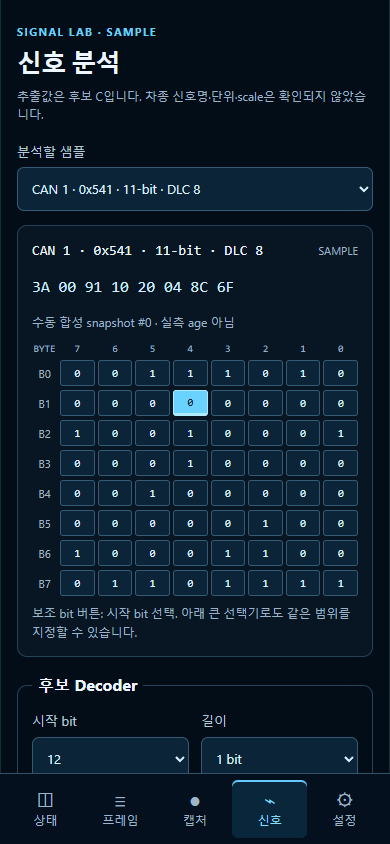
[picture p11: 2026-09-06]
docs/images/diagnostic-signals.png

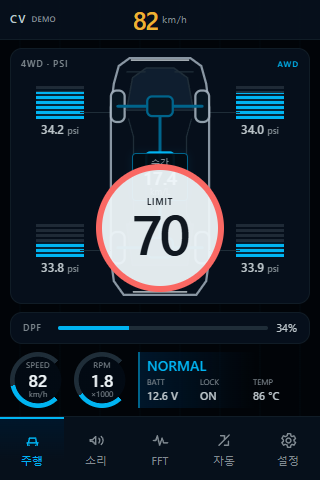
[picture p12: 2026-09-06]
docs/images/ui-drive-warning.png

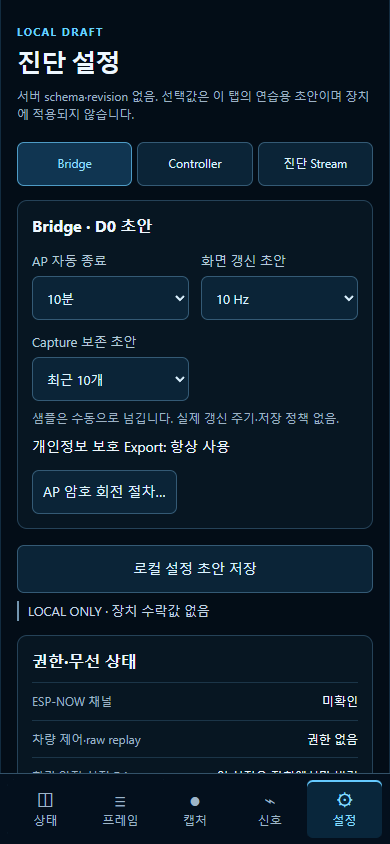
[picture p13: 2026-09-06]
docs/images/diagnostic-settings.png

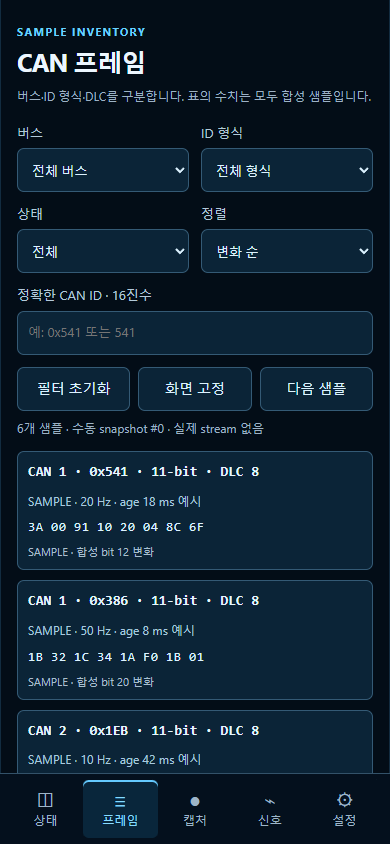
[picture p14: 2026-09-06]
docs/images/diagnostic-frames.png

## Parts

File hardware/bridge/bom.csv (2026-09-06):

ref | value | mpn | footprint | spec | source | dnp | sheet | note
J1 | USB4105-GF-A | USB4105-GF-A | CANView:Connector_USB__USB_C_Receptacle_GCT_USB4105-xx-A_16P_TopMnt_Horizontal | 16contactUSB2 receptacle; shield bonded at entry; 5V only; C-to-C >=1.5A source required | gct-usb4105: mechanical drawing, contact assignments | False | 01_usb_c
C1 | 1u | GEN-C-0603-1u-16V-X7R | CANView:Capacitor_SMD__C_0603_1608Metric | 16V; ±10%; X7R; -55..125C; verify effective capacitance under DC bias |  | False | 01_usb_c | Keep total pre-switch VBUS capacitance below10uF
D1 | TPD2E2U06DCKR | TPD2E2U06DCKR | CANView:Package_TO_SOT_SMD__SOT-323_SC-70 | 5.5V standoff;1.5pF typical; ESD only, not DC overvoltage protection | tpd2e2u06:p3 DCK pins1/2=IO,pin3=GND | False | 01_usb_c
D2 | TPD2E2U06DCKR | TPD2E2U06DCKR | CANView:Package_TO_SOT_SMD__SOT-323_SC-70 | 5.5V standoff;1.5pF typical; ESD only, not DC overvoltage protection | tpd2e2u06:p3 DCK pins1/2=IO,pin3=GND | False | 01_usb_c
U1 | TUSB320LAIRWBR | TUSB320LAIRWBR | CANView:Package_DFN_QFN__Texas_X2QFN-12_1.6x1.6mm_P0.4mm | PORT=GND UFP; ADDR NC GPIO mode; internal Rd, NO external5.1k; OUT1 low only attached1.5/3A | tusb320lai:pp3,12 Table3,23 application,36 land | False | 01_usb_c
R1 | 900k | GEN-R-0402-900k-1% | CANView:Resistor_SMD__R_0402_1005Metric | 0.1W; 50V; ±1%; ±100ppm/K; -55..155C |  | False | 01_usb_c
R2 | 10k | GEN-R-0402-10k-1% | CANView:Resistor_SMD__R_0402_1005Metric | 0.1W; 50V; ±1%; ±100ppm/K; -55..155C |  | False | 01_usb_c
C2 | 100n | GEN-C-0402-100n-16V-X7R | CANView:Capacitor_SMD__C_0402_1005Metric | 16V; ±10%; X7R; -55..125C; verify effective capacitance under DC bias |  | False | 01_usb_c
U2 | SN74LVC1G04DBVR | SN74LVC1G04DBVR | CANView:Package_TO_SOT_SMD__SOT-23-5 | USB-domain inverter, default/unattached => limiter disabled | sn74lvc1g04 | False | 01_usb_c
C3 | 100n | GEN-C-0402-100n-16V-X7R | CANView:Capacitor_SMD__C_0402_1005Metric | 16V; ±10%; X7R; -55..125C; verify effective capacitance under DC bias |  | False | 01_usb_c
R3 | 100k | GEN-R-0402-100k-1% | CANView:Resistor_SMD__R_0402_1005Metric | 0.1W; 50V; ±1%; ±100ppm/K; -55..155C |  | False | 01_usb_c
U16 | TPS7A2033PDBVR | TPS7A2033PDBVR | CANView:Package_TO_SOT_SMD__SOT-23-5 | 300mA LDO; fixed 3.3V; 1uF effective output minimum | tps7a20: p4 DBV pins, input/output capacitor requirements | False | 01a_usb_cc_supply
C4 | 1u | GEN-C-0603-1u-16V-X7R | CANView:Capacitor_SMD__C_0603_1608Metric | 16V; ±10%; X7R; -55..125C; verify effective capacitance under DC bias |  | False | 01a_usb_cc_supply
C5 | 2.2u | GEN-C-0603-2.2u-16V-X7R | CANView:Capacitor_SMD__C_0603_1608Metric | 16V; ±10%; X7R; -55..125C; verify effective capacitance under DC bias |  | False | 01a_usb_cc_supply
R4 | 3k | GEN-R-0402-3k-1% | CANView:Resistor_SMD__R_0402_1005Metric | 0.1W; 50V; ±1%; ±100ppm/K; -55..155C |  | False | 01a_usb_cc_supply | >=1mA minimum load for LDO specified output accuracy; include in pre-attach/suspend current budget
U3 | TPS2553QDBVRQ1 | TPS2553QDBVRQ1 | CANView:Package_TO_SOT_SMD__SOT-23-6 | 2.5..6.5V; programmable current limit; thermal shutdown; finite trip response | tps2553:pp3,13 | False | 01b_usb_limit
R5 | 26.7k | GEN-R-0402-26.7k-1% | CANView:Resistor_SMD__R_0402_1005Metric | 0.1W; 50V; ±1%; ±100ppm/K; -55..155C |  | False | 01b_usb_limit
R6 | 10k | GEN-R-0402-10k-1% | CANView:Resistor_SMD__R_0402_1005Metric | 0.1W; 50V; ±1%; ±100ppm/K; -55..155C |  | False | 01b_usb_limit
C6 | 1u | GEN-C-0603-1u-16V-X7R | CANView:Capacitor_SMD__C_0603_1608Metric | 16V; ±10%; X7R; -55..125C; verify effective capacitance under DC bias |  | False | 01b_usb_limit
C7 | 1u | GEN-C-0603-1u-16V-X7R | CANView:Capacitor_SMD__C_0603_1608Metric | 16V; ±10%; X7R; -55..125C; verify effective capacitance under DC bias |  | False | 01b_usb_limit
R7 | 0 | GEN-R-0805-0-1% | CANView:Resistor_SMD__R_0805_2012Metric | 0.25W; 50V; ±1%; ±100ppm/K; -55..155C |  | False | 02_system_power | Current>=1A zero-ohm jumper
U5 | TPS629210DRLR | TPS629210DRLR | CANView:Package_TO_SOT_SMD__SOT-583-8 | 1A buck; VSET249k=3.3V; MODE27.4k=autoPFM/PWM and output discharge | tps629210:pp3,11-13,20-22 | False | 02_system_power
R8 | 249k | GEN-R-0402-249k-1% | CANView:Resistor_SMD__R_0402_1005Metric | 0.1W; 50V; ±1%; ±100ppm/K; -55..155C |  | False | 02_system_power
R9 | 27.4k | GEN-R-0402-27.4k-1% | CANView:Resistor_SMD__R_0402_1005Metric | 0.1W; 50V; ±1%; ±100ppm/K; -55..155C |  | False | 02_system_power
L1 | 2.2uH | DFE252012PD-2R2M=P2 | CANView:Murata_DFE252012PD | 2.2uH±20%;2.5x2.0x1.2mm;Isat2.8A/Itemp2.2A;DCR84mohm;20VDC;-40..125C | murata-dfe252012:p1; tps629210 p22 | False | 02_system_power
C8 | 4.7u | GEN-C-0603-4.7u-16V-X7R | CANView:Capacitor_SMD__C_0603_1608Metric | 16V; ±10%; X7R; -55..125C; verify effective capacitance under DC bias |  | False | 02_system_power
C9 | 22u | GEN-C-0805-22u-10V-X7R | CANView:Capacitor_SMD__C_0805_2012Metric | 10V; ±10%; X7R; -55..125C; verify effective capacitance under DC bias |  | False | 02_system_power | Verify effective capacitance with ALL downstream bypass; no extra100uF bulk without stability analysis
U6 | TLV803EA30DPWR | TLV803EA30DPWR | CANView:Package_SON__Texas_X2SON-5_0.8x0.8mm_P0.48mm | 3.08V threshold;130..270ms release delay; active-low open-drain | tlv803e:pp4-5,9; DPW pin3 PAD may be grounded | False | 03_reset
R10 | 10k | GEN-R-0402-10k-1% | CANView:Resistor_SMD__R_0402_1005Metric | 0.1W; 50V; ±1%; ±100ppm/K; -55..155C |  | False | 03_reset
C10 | 100n | GEN-C-0402-100n-16V-X7R | CANView:Capacitor_SMD__C_0402_1005Metric | 16V; ±10%; X7R; -55..125C; verify effective capacitance under DC bias |  | False | 03_reset
SW1 | RESET | TL3342F160QG | CANView:Button_Switch_SMD__SW_SPST_TL3342 | Momentary normally-open; Communicator drives both supervisor MR inputs, never joins reset outputs |  | False | 03_reset
U11 | ESP32-S3-WROOM-1-N8R2 | ESP32-S3-WROOM-1-N8R2 | CANView:RF_Module__ESP32-S3-WROOM-1 | 8MiB Quad flash + 2MiB Quad PSRAM; 3.0..3.6V; -40..85C | esp32s3-wroom: ordering table, pin definitions, R8 reserved GPIO35/36/37; PSRAM ECC temperature note | False | 02_esp32
C11 | 100n | GEN-C-0603-100n-16V-X7R | CANView:Capacitor_SMD__C_0603_1608Metric | 16V; ±10%; X7R; -55..125C; verify effective capacitance under DC bias |  | False | 02_esp32
C12 | 10u | GEN-C-0603-10u-16V-X7R | CANView:Capacitor_SMD__C_0603_1608Metric | 16V; ±10%; X7R; -55..125C; verify effective capacitance under DC bias |  | False | 02_esp32
C13 | 10u | GEN-C-0603-10u-16V-X7R | CANView:Capacitor_SMD__C_0603_1608Metric | 16V; ±10%; X7R; -55..125C; verify effective capacitance under DC bias |  | False | 02_esp32
R11 | 10k | GEN-R-0402-10k-1% | CANView:Resistor_SMD__R_0402_1005Metric | 0.1W; 50V; ±1%; ±100ppm/K; -55..155C |  | False | 02_esp32
SW2 | BOOT | TL3342F160QG | CANView:Button_Switch_SMD__SW_SPST_TL3342 | Momentary normally open; logic signal only |  | False | 03_service
R12 | 22 | GEN-R-0402-22-1% | CANView:Resistor_SMD__R_0402_1005Metric | 0.1W; 50V; ±1%; ±100ppm/K; -55..155C |  | False | 03_service
R13 | 22 | GEN-R-0402-22-1% | CANView:Resistor_SMD__R_0402_1005Metric | 0.1W; 50V; ±1%; ±100ppm/K; -55..155C |  | False | 03_service
R14 | 10k | GEN-R-0402-10k-1% | CANView:Resistor_SMD__R_0402_1005Metric | 0.1W; 50V; ±1%; ±100ppm/K; -55..155C |  | False | 03_service
SW3 | PAIR | TL3342F160QG | CANView:Button_Switch_SMD__SW_SPST_TL3342 | Momentary normally open; hold >=3s commissioning |  | False | 03_service
R15 | 2.2k | GEN-R-0402-2.2k-1% | CANView:Resistor_SMD__R_0402_1005Metric | 0.1W; 50V; ±1%; ±100ppm/K; -55..155C |  | False | 03_service
D3 | BLUE | GEN-LED-0603-BLUE | CANView:LED_SMD__LED_0603_1608Metric | Blue LED; pad1 cathode, pad2 anode; If<=1mA; Vf<=3.2V |  | False | 03_service

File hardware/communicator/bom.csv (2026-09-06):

ref | value | mpn | footprint | spec | source | dnp | sheet | note
J2 | VEHICLE12V | B2B-XH-A(LF)(SN) | CANView:Connector_JST__JST_XH_B2B-XH-A_1x02_P2.50mm_Vertical | 3A rated connector; external1A harness fuse at tap; fused IGN/ACC preferred; NOT an OBD pin assignment | jst-xh | False | 00_vehicle_input
F1 | 1A125V | 0451001.MRL | CANView:Fuse__Fuse_Littelfuse-NANO2-451_453 | 1A;125V;50A interrupt@125VAC/DC,300A@32VDC;6.1x2.69mm; replace after trip; coordinate upstream harness fuse | littelfuse-451:pp2,4 | False | 00_vehicle_input
D100 | SMBJ36CA | SMBJ36CA | CANView:Diode_SMD__D_SMB | 36V bidirectional TVS;600W10/1000us rating NOT350ms load-dump energy guarantee | smbj | False | 00_vehicle_input
C1 | 100n | GEN-C-0805-100n-100V-X7R | CANView:Capacitor_SMD__C_0805_2012Metric | 100V; ±10%; X7R; -55..125C; verify effective capacitance under DC bias |  | False | 00_vehicle_input
Q1 | BUK7Y12-100E | BUK7Y12-100E | CANView:Package_TO_SOT_SMD__LFPAK56 | 100V N-MOS; DC VGS +/-20V; RDSon<=12mohm@10V/25C; LFPAK56; common-source pair; pulse SOA qualification required | buk7y12-100e:pp1-2,4,10 pinout, DC VGS and SOA; lm7480 pp6,29-32 | False | 00b_reverse_ov
Q2 | BUK7Y12-100E | BUK7Y12-100E | CANView:Package_TO_SOT_SMD__LFPAK56 | 100V N-MOS; DC VGS +/-20V; RDSon<=12mohm@10V/25C; LFPAK56; common-source pair; pulse SOA qualification required | buk7y12-100e:pp1-2,4,10 pinout, DC VGS and SOA; lm7480 pp6,29-32 | False | 00b_reverse_ov
U7 | LM74800QDRRRQ1 | LM74800QDRRRQ1 | CANView:Package_SON__WSON-12-1EP_3x3mm_P0.5mm_EP1.5x2.5mm | 3..65V controller; no current limiting; RTN EP13 isolated copper only | lm7480:pp3,29-32; LM EVM CS capacitor erratum via TI forum | False | 00b_reverse_ov
R1 | 10k | GEN-R-0805-10k-1% | CANView:Resistor_SMD__R_0805_2012Metric | 0.25W; 150V; ±1%; ±100ppm/K; -55..155C |  | False | 00b_reverse_ov
C2 | 100n | GEN-C-0805-100n-100V-X7R | CANView:Capacitor_SMD__C_0805_2012Metric | 100V; ±10%; X7R; -55..125C; verify effective capacitance under DC bias |  | False | 00b_reverse_ov
C3 | 100n | GEN-C-0402-100n-25V-X7R | CANView:Capacitor_SMD__C_0402_1005Metric | 25V; ±10%; X7R; -55..125C; verify effective capacitance under DC bias |  | False | 00b_reverse_ov
C4 | 1u | GEN-C-1206-1u-100V-X7R | CANView:Capacitor_SMD__C_1206_3216Metric | 100V; ±10%; X7R; -55..125C; verify effective capacitance under DC bias |  | False | 00b_reverse_ov | TI EVM15nF corrected to1uF due to DGATE oscillation
D4 | BAS21H,115 | BAS21H,115 | CANView:Diode_SMD__D_SOD-123F | 200V diode; anodeCS cathodeVS; supplies controller from CS after input drop | bas21h | False | 00b_reverse_ov
D5 | BZT52H-C47,115 | BZT52H-C47,115 | CANView:Diode_SMD__D_SOD-123F | 47V zener±5%;375mW; VS clamp below65V subject to pulse qualification | bzt52h | False | 00b_reverse_ov
R2 | 100k | GEN-R-0603-100k-0.1% | CANView:Resistor_SMD__R_0603_1608Metric | 0.1W; 100V; ±0.1%; ±10ppm/K; -55..155C |  | False | 00b_reverse_ov
R3 | 4.75k | GEN-R-0603-4.75k-0.1% | CANView:Resistor_SMD__R_0603_1608Metric | 0.1W; 50V; ±0.1%; ±10ppm/K; -55..155C |  | False | 00b_reverse_ov
U8 | MAX20040BATPA/VY+ | MAX20040BATPA/VY+ | CANView:Package_DFN_QFN__TQFN-20-1EP_4x4mm_P0.5mm_EP2.9x2.9mm | 36V input max;5.0875V/1.2A nominal;4.7uH;2.2MHz; compensation starting point per EVM | max20040:pp9-10,14-17; max20040-evm; KiCad21-100172 footprint / shared land90-0409 per MAX20090p29 | False | 00c_auto_5v | FOOTPRINT PROVISIONAL: manufacturer land90-0409 original not archived/overlaid; fabrication blocked until pad geometry sign-off
R4 | 30.7k | GEN-R-0603-30.7k-0.1% | CANView:Resistor_SMD__R_0603_1608Metric | 0.1W; 50V; ±0.1%; ±10ppm/K; -55..155C |  | False | 00c_auto_5v
R5 | 10k | GEN-R-0603-10k-0.1% | CANView:Resistor_SMD__R_0603_1608Metric | 0.1W; 50V; ±0.1%; ±10ppm/K; -55..155C |  | False | 00c_auto_5v
C5 | 4.7u | GRM32ER71H475KA88L | CANView:Capacitor_SMD__C_1210_3225Metric | 50V; ±10%; X7R; -55..125C; verify effective capacitance under DC bias |  | False | 00c_auto_5v
C6 | 4.7u | GRM32ER71H475KA88L | CANView:Capacitor_SMD__C_1210_3225Metric | 50V; ±10%; X7R; -55..125C; verify effective capacitance under DC bias |  | False | 00c_auto_5v
C7 | 2.2u | GRM188R61C225KE15D | CANView:Capacitor_SMD__C_0603_1608Metric | 16V; ±10%; X5R; -55..85C; verify effective capacitance under DC bias |  | False | 00c_auto_5v
C8 | 100n | GRM155R71H104KE14D | CANView:Capacitor_SMD__C_0402_1005Metric | 50V; ±10%; X7R; -55..125C; verify effective capacitance under DC bias |  | False | 00c_auto_5v
C9 | 100n | GRM155R71H104KE14D | CANView:Capacitor_SMD__C_0402_1005Metric | 50V; ±10%; X7R; -55..125C; verify effective capacitance under DC bias |  | False | 00c_auto_5v
D6 | PMEG4010BEA,115 | PMEG4010BEA,115 | CANView:Diode_SMD__D_SOD-323 | 40V1A Schottky; SOD323; replaces EVM30V dual diode for voltage margin; validate bootstrap ripple/leakage at hot | max20040-evm:p4 external bootstrap feed; pmeg4010bea:pp1-5 | False | 00c_auto_5v
D7 | PMEG4010BEA,115 | PMEG4010BEA,115 | CANView:Diode_SMD__D_SOD-323 | 40V1A Schottky; SOD323; replaces EVM30V dual diode for voltage margin; validate bootstrap ripple/leakage at hot | max20040-evm:p4 external bootstrap feed; pmeg4010bea:pp1-5 | False | 00c_auto_5v
L1 | 4.7uH | XAL5030-472MEC | CANView:Inductor_SMD__L_Coilcraft_XAL5030-XXX | 4.7uH±20%; shielded; peak current/temperature per vendor and regulator limit | coilcraft-xal5030; max20040-evm | False | 00c_auto_5v
R6 | 12k | GEN-R-0402-12k-1% | CANView:Resistor_SMD__R_0402_1005Metric | 0.1W; 50V; ±1%; ±100ppm/K; -55..155C |  | False | 00c_auto_5v
R7 | 22k | GEN-R-0402-22k-1% | CANView:Resistor_SMD__R_0402_1005Metric | 0.1W; 50V; ±1%; ±100ppm/K; -55..155C |  | False | 00c_auto_5v
C10 | 680p | GEN-C-0402-680p-16V-C0G | CANView:Capacitor_SMD__C_0402_1005Metric | 16V; ±5%; C0G; -55..125C; verify effective capacitance under DC bias |  | False | 00c_auto_5v
C11 | 22p | GEN-C-0402-22p-16V-C0G | CANView:Capacitor_SMD__C_0402_1005Metric | 16V; ±5%; C0G; -55..125C; verify effective capacitance under DC bias |  | False | 00c_auto_5v
C12 | 22u | GRM32ER71E226KE15L | CANView:Capacitor_SMD__C_1210_3225Metric | 25V; ±10%; X7R; -55..125C; verify effective capacitance under DC bias |  | False | 00c_auto_5v
C13 | 22u | GRM32ER71E226KE15L | CANView:Capacitor_SMD__C_1210_3225Metric | 25V; ±10%; X7R; -55..125C; verify effective capacitance under DC bias |  | False | 00c_auto_5v
R8 | 10k | GEN-R-0402-10k-1% | CANView:Resistor_SMD__R_0402_1005Metric | 0.1W; 50V; ±1%; ±100ppm/K; -55..155C |  | False | 00c_auto_5v
R9 | 2.2k | GEN-R-0402-2.2k-1% | CANView:Resistor_SMD__R_0402_1005Metric | 0.1W; 50V; ±1%; ±100ppm/K; -55..155C |  | False | 00c_auto_5v | Defined discharge,2.3mA at5V; not a substitute for transient tests
J1 | USB4105-GF-A | USB4105-GF-A | CANView:Connector_USB__USB_C_Receptacle_GCT_USB4105-xx-A_16P_TopMnt_Horizontal | 16contactUSB2 receptacle; shield bonded at entry; 5V only; C-to-C >=1.5A source required | gct-usb4105: mechanical drawing, contact assignments | False | 01_usb_c
C14 | 1u | GEN-C-0603-1u-16V-X7R | CANView:Capacitor_SMD__C_0603_1608Metric | 16V; ±10%; X7R; -55..125C; verify effective capacitance under DC bias |  | False | 01_usb_c | Keep total pre-switch VBUS capacitance below10uF
D1 | TPD2E2U06DCKR | TPD2E2U06DCKR | CANView:Package_TO_SOT_SMD__SOT-323_SC-70 | 5.5V standoff;1.5pF typical; ESD only, not DC overvoltage protection | tpd2e2u06:p3 DCK pins1/2=IO,pin3=GND | False | 01_usb_c
D2 | TPD2E2U06DCKR | TPD2E2U06DCKR | CANView:Package_TO_SOT_SMD__SOT-323_SC-70 | 5.5V standoff;1.5pF typical; ESD only, not DC overvoltage protection | tpd2e2u06:p3 DCK pins1/2=IO,pin3=GND | False | 01_usb_c
U1 | TUSB320LAIRWBR | TUSB320LAIRWBR | CANView:Package_DFN_QFN__Texas_X2QFN-12_1.6x1.6mm_P0.4mm | PORT=GND UFP; ADDR NC GPIO mode; internal Rd, NO external5.1k; OUT1 low only attached1.5/3A | tusb320lai:pp3,12 Table3,23 application,36 land | False | 01_usb_c
R10 | 900k | GEN-R-0402-900k-1% | CANView:Resistor_SMD__R_0402_1005Metric | 0.1W; 50V; ±1%; ±100ppm/K; -55..155C |  | False | 01_usb_c
R11 | 10k | GEN-R-0402-10k-1% | CANView:Resistor_SMD__R_0402_1005Metric | 0.1W; 50V; ±1%; ±100ppm/K; -55..155C |  | False | 01_usb_c
C15 | 100n | GEN-C-0402-100n-16V-X7R | CANView:Capacitor_SMD__C_0402_1005Metric | 16V; ±10%; X7R; -55..125C; verify effective capacitance under DC bias |  | False | 01_usb_c
U2 | SN74LVC1G04DBVR | SN74LVC1G04DBVR | CANView:Package_TO_SOT_SMD__SOT-23-5 | USB-domain inverter, default/unattached => limiter disabled | sn74lvc1g04 | False | 01_usb_c
C16 | 100n | GEN-C-0402-100n-16V-X7R | CANView:Capacitor_SMD__C_0402_1005Metric | 16V; ±10%; X7R; -55..125C; verify effective capacitance under DC bias |  | False | 01_usb_c
R12 | 100k | GEN-R-0402-100k-1% | CANView:Resistor_SMD__R_0402_1005Metric | 0.1W; 50V; ±1%; ±100ppm/K; -55..155C |  | False | 01_usb_c
U16 | TPS7A2033PDBVR | TPS7A2033PDBVR | CANView:Package_TO_SOT_SMD__SOT-23-5 | 300mA LDO; fixed 3.3V; 1uF effective output minimum | tps7a20: p4 DBV pins, input/output capacitor requirements | False | 01a_usb_cc_supply
C17 | 1u | GEN-C-0603-1u-16V-X7R | CANView:Capacitor_SMD__C_0603_1608Metric | 16V; ±10%; X7R; -55..125C; verify effective capacitance under DC bias |  | False | 01a_usb_cc_supply
C18 | 2.2u | GEN-C-0603-2.2u-16V-X7R | CANView:Capacitor_SMD__C_0603_1608Metric | 16V; ±10%; X7R; -55..125C; verify effective capacitance under DC bias |  | False | 01a_usb_cc_supply
R13 | 3k | GEN-R-0402-3k-1% | CANView:Resistor_SMD__R_0402_1005Metric | 0.1W; 50V; ±1%; ±100ppm/K; -55..155C |  | False | 01a_usb_cc_supply | >=1mA minimum load for LDO specified output accuracy; include in pre-attach/suspend current budget
U3 | TPS2553QDBVRQ1 | TPS2553QDBVRQ1 | CANView:Package_TO_SOT_SMD__SOT-23-6 | 2.5..6.5V; programmable current limit; thermal shutdown; finite trip response | tps2553:pp3,13 | False | 01b_usb_limit
R14 | 26.7k | GEN-R-0402-26.7k-1% | CANView:Resistor_SMD__R_0402_1005Metric | 0.1W; 50V; ±1%; ±100ppm/K; -55..155C |  | False | 01b_usb_limit
R15 | 10k | GEN-R-0402-10k-1% | CANView:Resistor_SMD__R_0402_1005Metric | 0.1W; 50V; ±1%; ±100ppm/K; -55..155C |  | False | 01b_usb_limit
C19 | 1u | GEN-C-0603-1u-16V-X7R | CANView:Capacitor_SMD__C_0603_1608Metric | 16V; ±10%; X7R; -55..125C; verify effective capacitance under DC bias |  | False | 01b_usb_limit
C20 | 1u | GEN-C-0603-1u-16V-X7R | CANView:Capacitor_SMD__C_0603_1608Metric | 16V; ±10%; X7R; -55..125C; verify effective capacitance under DC bias |  | False | 01b_usb_limit
U4 | TPS2116DRLR | TPS2116DRLR | CANView:Package_TO_SOT_SMD__SOT-583-8 | 1.6..5.5V;4A power mux; source status NOT PGOOD; finite reverse response | tps2116:pp3,12-16 | False | 02_system_power
R16 | 100k | GEN-R-0402-100k-1% | CANView:Resistor_SMD__R_0402_1005Metric | 0.1W; 50V; ±1%; ±100ppm/K; -55..155C |  | False | 02_system_power
R17 | 30.1k | GEN-R-0402-30.1k-1% | CANView:Resistor_SMD__R_0402_1005Metric | 0.1W; 50V; ±1%; ±100ppm/K; -55..155C |  | False | 02_system_power
R18 | 10k | GEN-R-0402-10k-1% | CANView:Resistor_SMD__R_0402_1005Metric | 0.1W; 50V; ±1%; ±100ppm/K; -55..155C |  | False | 02_system_power
C21 | 1u | GEN-C-0603-1u-16V-X7R | CANView:Capacitor_SMD__C_0603_1608Metric | 16V; ±10%; X7R; -55..125C; verify effective capacitance under DC bias |  | False | 02_system_power
C22 | 1u | GEN-C-0603-1u-16V-X7R | CANView:Capacitor_SMD__C_0603_1608Metric | 16V; ±10%; X7R; -55..125C; verify effective capacitance under DC bias |  | False | 02_system_power
U5 | TPS629210DRLR | TPS629210DRLR | CANView:Package_TO_SOT_SMD__SOT-583-8 | 1A buck; VSET249k=3.3V; MODE27.4k=autoPFM/PWM and output discharge | tps629210:pp3,11-13,20-22 | False | 02_system_power
R19 | 249k | GEN-R-0402-249k-1% | CANView:Resistor_SMD__R_0402_1005Metric | 0.1W; 50V; ±1%; ±100ppm/K; -55..155C |  | False | 02_system_power
R20 | 27.4k | GEN-R-0402-27.4k-1% | CANView:Resistor_SMD__R_0402_1005Metric | 0.1W; 50V; ±1%; ±100ppm/K; -55..155C |  | False | 02_system_power
L2 | 2.2uH | DFE252012PD-2R2M=P2 | CANView:Murata_DFE252012PD | 2.2uH±20%;2.5x2.0x1.2mm;Isat2.8A/Itemp2.2A;DCR84mohm;20VDC;-40..125C | murata-dfe252012:p1; tps629210 p22 | False | 02_system_power
C23 | 4.7u | GEN-C-0603-4.7u-16V-X7R | CANView:Capacitor_SMD__C_0603_1608Metric | 16V; ±10%; X7R; -55..125C; verify effective capacitance under DC bias |  | False | 02_system_power
C24 | 22u | GEN-C-0805-22u-10V-X7R | CANView:Capacitor_SMD__C_0805_2012Metric | 10V; ±10%; X7R; -55..125C; verify effective capacitance under DC bias |  | False | 02_system_power | Verify effective capacitance with ALL downstream bypass; no extra100uF bulk without stability analysis
U6 | TLV803EA30DPWR | TLV803EA30DPWR | CANView:Package_SON__Texas_X2SON-5_0.8x0.8mm_P0.48mm | 3.08V threshold;130..270ms release delay; active-low open-drain | tlv803e:pp4-5,9; DPW pin3 PAD may be grounded | False | 03_reset
R21 | 10k | GEN-R-0402-10k-1% | CANView:Resistor_SMD__R_0402_1005Metric | 0.1W; 50V; ±1%; ±100ppm/K; -55..155C |  | False | 03_reset
C25 | 100n | GEN-C-0402-100n-16V-X7R | CANView:Capacitor_SMD__C_0402_1005Metric | 16V; ±10%; X7R; -55..125C; verify effective capacitance under DC bias |  | False | 03_reset
SW1 | RESET | TL3342F160QG | CANView:Button_Switch_SMD__SW_SPST_TL3342 | Momentary normally-open; Communicator drives both supervisor MR inputs, never joins reset outputs |  | False | 03_reset
U9 | TPS7A2033PDBVR | TPS7A2033PDBVR | CANView:Package_TO_SOT_SMD__SOT-23-5 | 300mA LDO; fixed 3.3V; 1uF effective output minimum | tps7a20: p4 DBV pins, input/output capacitor requirements | False | 03b_phy_power
C26 | 1u | GEN-C-0603-1u-16V-X7R | CANView:Capacitor_SMD__C_0603_1608Metric | 16V; ±10%; X7R; -55..125C; verify effective capacitance under DC bias |  | False | 03b_phy_power
C27 | 2.2u | GEN-C-0603-2.2u-16V-X7R | CANView:Capacitor_SMD__C_0603_1608Metric | 16V; ±10%; X7R; -55..125C; verify effective capacitance under DC bias |  | False | 03b_phy_power
U12 | TLV803EA30DPWR | TLV803EA30DPWR | CANView:Package_SON__Texas_X2SON-5_0.8x0.8mm_P0.48mm | 3.08V threshold;130..270ms release delay; active-low open-drain | tlv803e:pp4-5,9; DPW pin3 PAD may be grounded | False | 03b_phy_power
R22 | 10k | GEN-R-0402-10k-1% | CANView:Resistor_SMD__R_0402_1005Metric | 0.1W; 50V; ±1%; ±100ppm/K; -55..155C |  | False | 03b_phy_power
C28 | 100n | GEN-C-0402-100n-16V-X7R | CANView:Capacitor_SMD__C_0402_1005Metric | 16V; ±10%; X7R; -55..125C; verify effective capacitance under DC bias |  | False | 03b_phy_power
R23 | 4.7k | GEN-R-0402-4.7k-1% | CANView:Resistor_SMD__R_0402_1005Metric | 0.1W; 50V; ±1%; ±100ppm/K; -55..155C |  | False | 03b_phy_power
U13 | TPS3700DDCR | TPS3700DDCR | CANView:Package_TO_SOT_SMD__SOT-23-6 | Battery rising8Vnom; protects MAX3055 BATT operating condition; OUTB unused opposite polarity | tps3700:pp4,6-7 | False | 03c_auto_qualification
R24 | 190k | GEN-R-0603-190k-0.1% | CANView:Resistor_SMD__R_0603_1608Metric | 0.1W; 50V; ±0.1%; ±100ppm/K; -55..155C |  | False | 03c_auto_qualification
R25 | 10k | GEN-R-0402-10k-0.1% | CANView:Resistor_SMD__R_0402_1005Metric | 0.1W; 50V; ±0.1%; ±100ppm/K; -55..155C |  | False | 03c_auto_qualification
R26 | 10k | GEN-R-0402-10k-1% | CANView:Resistor_SMD__R_0402_1005Metric | 0.1W; 50V; ±1%; ±100ppm/K; -55..155C |  | False | 03c_auto_qualification
C29 | 100n | GEN-C-0402-100n-16V-X7R | CANView:Capacitor_SMD__C_0402_1005Metric | 16V; ±10%; X7R; -55..125C; verify effective capacitance under DC bias |  | False | 03c_auto_qualification
U14 | TPS389001DSER | TPS389001DSER | CANView:Package_SON__WSON-6_1.5x1.5mm_P0.5mm | 1.15V adjustable sense±1%; delayed release; monitor AUTO5V independently of converterPGOOD | tps3890:pp3,5; DSE package | False | 03c_auto_qualification
R27 | 32k | GEN-R-0603-32k-0.05% | CANView:Resistor_SMD__R_0603_1608Metric | 0.1W; 50V; ±0.05%; ±10ppm/K; -55..155C |  | False | 03c_auto_qualification
R28 | 10k | GEN-R-0603-10k-0.05% | CANView:Resistor_SMD__R_0603_1608Metric | 0.1W; 50V; ±0.05%; ±10ppm/K; -55..155C |  | False | 03c_auto_qualification
C30 | 10n | GEN-C-0603-10n-16V-C0G | CANView:Capacitor_SMD__C_0603_1608Metric | 16V; ±5%; C0G; -55..125C; verify effective capacitance under DC bias |  | False | 03c_auto_qualification
C31 | 100n | GEN-C-0402-100n-16V-X7R | CANView:Capacitor_SMD__C_0402_1005Metric | 16V; ±10%; X7R; -55..125C; verify effective capacitance under DC bias |  | False | 03c_auto_qualification
R29 | 10k | GEN-R-0402-10k-1% | CANView:Resistor_SMD__R_0402_1005Metric | 0.1W; 50V; ±1%; ±100ppm/K; -55..155C |  | False | 03c_auto_qualification
U15 | SN74LVC1G11DCKR | SN74LVC1G11DCKR | CANView:Package_TO_SOT_SMD__SOT-363_SC-70-6 | 3-input AND; Ioff support | sn74lvc1g11: DCK pin functions | False | 03c_auto_qualification
C32 | 100n | GEN-C-0402-100n-16V-X7R | CANView:Capacitor_SMD__C_0402_1005Metric | 16V; ±10%; X7R; -55..125C; verify effective capacitance under DC bias |  | False | 03c_auto_qualification
U45 | SN74LVC1G11DCKR | SN74LVC1G11DCKR | CANView:Package_TO_SOT_SMD__SOT-363_SC-70-6 | 3-input AND; Ioff support | sn74lvc1g11: DCK pin functions | False | 19_gps_power
C33 | 100n | GEN-C-0402-100n-16V-X7R | CANView:Capacitor_SMD__C_0402_1005Metric | 16V; ±10%; X7R; -55..125C; verify effective capacitance under DC bias |  | False | 19_gps_power
R30 | 100k | GEN-R-0402-100k-1% | CANView:Resistor_SMD__R_0402_1005Metric | 0.1W; 50V; ±1%; ±100ppm/K; -55..155C |  | False | 19_gps_power
U46 | TPS2553QDBVRQ1 | TPS2553QDBVRQ1 | CANView:Package_TO_SOT_SMD__SOT-23-6 | 2.5..6.5V; programmable current limit; thermal shutdown; finite trip response | tps2553:pp3,13 | False | 19_gps_power
R31 | 61.9k | GEN-R-0402-61.9k-1% | CANView:Resistor_SMD__R_0402_1005Metric | 0.1W; 50V; ±1%; ±100ppm/K; -55..155C |  | False | 19_gps_power
R32 | 10k | GEN-R-0402-10k-1% | CANView:Resistor_SMD__R_0402_1005Metric | 0.1W; 50V; ±1%; ±100ppm/K; -55..155C |  | False | 19_gps_power
C34 | 1u | GEN-C-0603-1u-16V-X7R | CANView:Capacitor_SMD__C_0603_1608Metric | 16V; ±10%; X7R; -55..125C; verify effective capacitance under DC bias |  | False | 19_gps_power
C35 | 1u | GEN-C-0603-1u-16V-X7R | CANView:Capacitor_SMD__C_0603_1608Metric | 16V; ±10%; X7R; -55..125C; verify effective capacitance under DC bias |  | False | 19_gps_power
R33 | 4.7k | GEN-R-0402-4.7k-1% | CANView:Resistor_SMD__R_0402_1005Metric | 0.1W; 50V; ±1%; ±100ppm/K; -55..155C |  | False | 19_gps_power | Discharge switched receiver supply after shutdown
U10 | STM32G474CEU6 | STM32G474CEU6 | CANView:Package_DFN_QFN__QFN-48-1EP_7x7mm_P0.5mm_EP5.6x5.6mm | See manufacturer datasheet | stm32g474: UFQFPN48 pinout, AF9/AF11/AF7; pin 7 PG10-NRST reset function; stm32g4-hardware | False | 04_stm32
C36 | 100n | GEN-C-0402-100n-16V-X7R | CANView:Capacitor_SMD__C_0402_1005Metric | 16V; ±10%; X7R; -55..125C; verify effective capacitance under DC bias |  | False | 04_stm32 | One per VDD pin: 23,35,48; shortest return to EP49
C37 | 100n | GEN-C-0402-100n-16V-X7R | CANView:Capacitor_SMD__C_0402_1005Metric | 16V; ±10%; X7R; -55..125C; verify effective capacitance under DC bias |  | False | 04_stm32 | One per VDD pin: 23,35,48; shortest return to EP49
C38 | 100n | GEN-C-0402-100n-16V-X7R | CANView:Capacitor_SMD__C_0402_1005Metric | 16V; ±10%; X7R; -55..125C; verify effective capacitance under DC bias |  | False | 04_stm32 | One per VDD pin: 23,35,48; shortest return to EP49
C39 | 4.7u | GEN-C-0603-4.7u-16V-X7R | CANView:Capacitor_SMD__C_0603_1608Metric | 16V; ±10%; X7R; -55..125C; verify effective capacitance under DC bias |  | False | 04_stm32
C40 | 100n | GEN-C-0402-100n-16V-X7R | CANView:Capacitor_SMD__C_0402_1005Metric | 16V; ±10%; X7R; -55..125C; verify effective capacitance under DC bias |  | False | 04_stm32 | VBAT pin1
R34 | 0 | GEN-R-0402-0-1% | CANView:Resistor_SMD__R_0402_1005Metric | 0.1W; 50V; ±1%; ±100ppm/K; -55..155C |  | False | 04_stm32 | Do not substitute unmodelled high-Q ferrite
C41 | 1u | GEN-C-0603-1u-16V-X7R | CANView:Capacitor_SMD__C_0603_1608Metric | 16V; ±10%; X7R; -55..125C; verify effective capacitance under DC bias |  | False | 04_stm32
C42 | 100n | GEN-C-0402-100n-16V-X7R | CANView:Capacitor_SMD__C_0402_1005Metric | 16V; ±10%; X7R; -55..125C; verify effective capacitance under DC bias |  | False | 04_stm32
R35 | 10k | GEN-R-0402-10k-1% | CANView:Resistor_SMD__R_0402_1005Metric | 0.1W; 50V; ±1%; ±100ppm/K; -55..155C |  | False | 04_stm32
R36 | 10k | GEN-R-0402-10k-1% | CANView:Resistor_SMD__R_0402_1005Metric | 0.1W; 50V; ±1%; ±100ppm/K; -55..155C |  | False | 04_stm32
R37 | 10k | GEN-R-0402-10k-1% | CANView:Resistor_SMD__R_0402_1005Metric | 0.1W; 50V; ±1%; ±100ppm/K; -55..155C |  | False | 04_stm32
R38 | 10k | GEN-R-0402-10k-1% | CANView:Resistor_SMD__R_0402_1005Metric | 0.1W; 50V; ±1%; ±100ppm/K; -55..155C |  | False | 04_stm32
R39 | 10k | GEN-R-0402-10k-1% | CANView:Resistor_SMD__R_0402_1005Metric | 0.1W; 50V; ±1%; ±100ppm/K; -55..155C |  | False | 04_stm32
R40 | 10k | GEN-R-0402-10k-1% | CANView:Resistor_SMD__R_0402_1005Metric | 0.1W; 50V; ±1%; ±100ppm/K; -55..155C |  | False | 04_stm32
R41 | 10k | GEN-R-0402-10k-1% | CANView:Resistor_SMD__R_0402_1005Metric | 0.1W; 50V; ±1%; ±100ppm/K; -55..155C |  | False | 04_stm32
R42 | 10k | GEN-R-0402-10k-1% | CANView:Resistor_SMD__R_0402_1005Metric | 0.1W; 50V; ±1%; ±100ppm/K; -55..155C |  | False | 04_stm32
R43 | 10k | GEN-R-0402-10k-1% | CANView:Resistor_SMD__R_0402_1005Metric | 0.1W; 50V; ±1%; ±100ppm/K; -55..155C |  | False | 04_stm32
Y1 | ABM8-16.000MHZ-D2-T | ABM8-16.000MHZ-D2-T | CANView:Crystal__Crystal_SMD_3225-4Pin_3.2x2.5mm | 16MHz; CL18pF; ±20ppm; ±50ppm temperature; -40..85C; ESR70ohm maximum; drive10..100uW | abracon-abm8: pp1-2, D temperature option | False | 05_debug_clock_uart
R44 | 0 | GEN-R-0402-0-1% | CANView:Resistor_SMD__R_0402_1005Metric | 0.1W; 50V; ±1%; ±100ppm/K; -55..155C |  | False | 05_debug_clock_uart | HSE drive-limiting series R footprint; measure crystal drive and startup margin before release
C43 | 27p | GEN-C-0402-27p-50V-C0G | CANView:Capacitor_SMD__C_0402_1005Metric | 50V; ±5%; C0G; -55..125C; verify effective capacitance under DC bias |  | False | 05_debug_clock_uart
C44 | 27p | GEN-C-0402-27p-50V-C0G | CANView:Capacitor_SMD__C_0402_1005Metric | 50V; ±5%; C0G; -55..125C; verify effective capacitance under DC bias |  | False | 05_debug_clock_uart
J10 | SWD 2x5 1.27mm | SWD 2x5 1.27mm | CANView:Connector_PinHeader_1.27mm__PinHeader_2x05_P1.27mm_Vertical | Unshrouded header; matching keyed adapter or controlled pin1 orientation required; VTref sense only |  | False | 05_debug_clock_uart | Use pin1 marking; SWO not routed; do not power from debugger
R45 | 33 | GEN-R-0402-33-1% | CANView:Resistor_SMD__R_0402_1005Metric | 0.1W; 50V; ±1%; ±100ppm/K; -55..155C |  | False | 05_debug_clock_uart | Place next to the named transmitter
R46 | 33 | GEN-R-0402-33-1% | CANView:Resistor_SMD__R_0402_1005Metric | 0.1W; 50V; ±1%; ±100ppm/K; -55..155C |  | False | 05_debug_clock_uart | Place next to the named transmitter
R47 | 33 | GEN-R-0402-33-1% | CANView:Resistor_SMD__R_0402_1005Metric | 0.1W; 50V; ±1%; ±100ppm/K; -55..155C |  | False | 05_debug_clock_uart | Place next to the named transmitter
R48 | 33 | GEN-R-0402-33-1% | CANView:Resistor_SMD__R_0402_1005Metric | 0.1W; 50V; ±1%; ±100ppm/K; -55..155C |  | False | 05_debug_clock_uart | Place next to the named transmitter
R49 | 10k | GEN-R-0402-10k-1% | CANView:Resistor_SMD__R_0402_1005Metric | 0.1W; 50V; ±1%; ±100ppm/K; -55..155C |  | False | 05_debug_clock_uart
R50 | 10k | GEN-R-0402-10k-1% | CANView:Resistor_SMD__R_0402_1005Metric | 0.1W; 50V; ±1%; ±100ppm/K; -55..155C |  | False | 05_debug_clock_uart
R51 | 47k | GEN-R-0402-47k-1% | CANView:Resistor_SMD__R_0402_1005Metric | 0.1W; 50V; ±1%; ±100ppm/K; -55..155C |  | False | 05_debug_clock_uart
R52 | 47k | GEN-R-0402-47k-1% | CANView:Resistor_SMD__R_0402_1005Metric | 0.1W; 50V; ±1%; ±100ppm/K; -55..155C |  | False | 05_debug_clock_uart
U11 | ESP32-S3-WROOM-1-N16R8 | ESP32-S3-WROOM-1-N16R8 | CANView:RF_Module__ESP32-S3-WROOM-1 | 16MiB Quad flash + 8MiB Octal PSRAM; 3.0..3.6V; -40..65C base, up to85C with PSRAM ECC; ECC usable7.5MiB; validate complete board thermal range | esp32s3-wroom: ordering table, pin definitions, R8 reserved GPIO35/36/37; PSRAM ECC temperature note | False | 06_esp32
C45 | 100n | GEN-C-0603-100n-16V-X7R | CANView:Capacitor_SMD__C_0603_1608Metric | 16V; ±10%; X7R; -55..125C; verify effective capacitance under DC bias |  | False | 06_esp32
C46 | 10u | GEN-C-0603-10u-16V-X7R | CANView:Capacitor_SMD__C_0603_1608Metric | 16V; ±10%; X7R; -55..125C; verify effective capacitance under DC bias |  | False | 06_esp32
C47 | 10u | GEN-C-0603-10u-16V-X7R | CANView:Capacitor_SMD__C_0603_1608Metric | 16V; ±10%; X7R; -55..125C; verify effective capacitance under DC bias |  | False | 06_esp32
R53 | 10k | GEN-R-0402-10k-1% | CANView:Resistor_SMD__R_0402_1005Metric | 0.1W; 50V; ±1%; ±100ppm/K; -55..155C |  | False | 06_esp32
SW2 | BOOT | TL3342F160QG | CANView:Button_Switch_SMD__SW_SPST_TL3342 | Momentary normally open; logic signal only |  | False | 07_esp_service
R54 | 22 | GEN-R-0402-22-1% | CANView:Resistor_SMD__R_0402_1005Metric | 0.1W; 50V; ±1%; ±100ppm/K; -55..155C |  | False | 07_esp_service
R55 | 22 | GEN-R-0402-22-1% | CANView:Resistor_SMD__R_0402_1005Metric | 0.1W; 50V; ±1%; ±100ppm/K; -55..155C |  | False | 07_esp_service
U20 | TCAN1046AVDYYRQ1 | TCAN1046AVDYYRQ1 | CANView:TI_DYY0014A | Dual CAN FD; 4.5..5.5V VCC; 3.3V VIO; bus fault ±58V | tcan1046av: pp4-5, operating modes, DYY0014A land pattern | False | 08_can_fd
C48 | 100n | GEN-C-0402-100n-16V-X7R | CANView:Capacitor_SMD__C_0402_1005Metric | 16V; ±10%; X7R; -55..125C; verify effective capacitance under DC bias |  | False | 08_can_fd
C49 | 100n | GEN-C-0402-100n-16V-X7R | CANView:Capacitor_SMD__C_0402_1005Metric | 16V; ±10%; X7R; -55..125C; verify effective capacitance under DC bias |  | False | 08_can_fd
C50 | 4.7u | GEN-C-0603-4.7u-16V-X7R | CANView:Capacitor_SMD__C_0603_1608Metric | 16V; ±10%; X7R; -55..125C; verify effective capacitance under DC bias |  | False | 08_can_fd
R56 | 10k | GEN-R-0402-10k-1% | CANView:Resistor_SMD__R_0402_1005Metric | 0.1W; 50V; ±1%; ±100ppm/K; -55..155C |  | False | 08_can_fd
R57 | 10k | GEN-R-0402-10k-1% | CANView:Resistor_SMD__R_0402_1005Metric | 0.1W; 50V; ±1%; ±100ppm/K; -55..155C |  | False | 08_can_fd
R58 | 10k | GEN-R-0402-10k-1% | CANView:Resistor_SMD__R_0402_1005Metric | 0.1W; 50V; ±1%; ±100ppm/K; -55..155C |  | False | 08_can_fd
R59 | 10k | GEN-R-0402-10k-1% | CANView:Resistor_SMD__R_0402_1005Metric | 0.1W; 50V; ±1%; ±100ppm/K; -55..155C |  | False | 08_can_fd
U21 | SN74LVC2G17DCKR | SN74LVC2G17DCKR | CANView:Package_TO_SOT_SMD__SOT-363_SC-70-6 | 5.5V-tolerant inputs; partial-power-down Ioff; powered from MCU rail | sn74lvc2g17: DCK pins, Ioff, VIH/VIL | False | 08_can_fd
C51 | 100n | GEN-C-0402-100n-16V-X7R | CANView:Capacitor_SMD__C_0402_1005Metric | 16V; ±10%; X7R; -55..125C; verify effective capacitance under DC bias |  | False | 08_can_fd
U22 | MAX3055ASD+ | MAX3055ASD+ | CANView:Package_SO__SOIC-14_3.9x8.7mm_P1.27mm | 125kbps FT CAN; VCC4.75..5.25V; BATT>=5V for valid operation; bus fault±80V | max3055: pp1,11,16-17 | False | 09_can_ft
C52 | 100n | GEN-C-0402-100n-16V-X7R | CANView:Capacitor_SMD__C_0402_1005Metric | 16V; ±10%; X7R; -55..125C; verify effective capacitance under DC bias |  | False | 09_can_ft
C53 | 100n | GEN-C-0603-100n-50V-X7R | CANView:Capacitor_SMD__C_0603_1608Metric | 50V; ±10%; X7R; -55..125C; verify effective capacitance under DC bias |  | False | 09_can_ft
C54 | 4.7u | GEN-C-0603-4.7u-16V-X7R | CANView:Capacitor_SMD__C_0603_1608Metric | 16V; ±10%; X7R; -55..125C; verify effective capacitance under DC bias |  | False | 09_can_ft
R60 | 10k | GEN-R-0603-10k-1% | CANView:Resistor_SMD__R_0603_1608Metric | 0.1W; 50V; ±1%; ±100ppm/K; -55..155C |  | False | 09_can_ft
R61 | 220k | GEN-R-0603-220k-1% | CANView:Resistor_SMD__R_0603_1608Metric | 0.1W; 50V; ±1%; ±100ppm/K; -55..155C |  | False | 09_can_ft | Defined load <0.18mA at32V; INH never controls regulator
R62 | 4.7k | GEN-R-0805-4.7k-1% | CANView:Resistor_SMD__R_0805_2012Metric | 0.25W; 100V; ±1%; ±100ppm/K; -55..155C |  | False | 09_can_ft
R63 | 4.7k | GEN-R-0805-4.7k-1% | CANView:Resistor_SMD__R_0805_2012Metric | 0.25W; 100V; ±1%; ±100ppm/K; -55..155C |  | False | 09_can_ft
R64 | 10k | GEN-R-0402-10k-1% | CANView:Resistor_SMD__R_0402_1005Metric | 0.1W; 50V; ±1%; ±100ppm/K; -55..155C |  | False | 09_can_ft
R65 | 10k | GEN-R-0402-10k-1% | CANView:Resistor_SMD__R_0402_1005Metric | 0.1W; 50V; ±1%; ±100ppm/K; -55..155C |  | False | 09_can_ft
U23 | SN74LVC2G17DCKR | SN74LVC2G17DCKR | CANView:Package_TO_SOT_SMD__SOT-363_SC-70-6 | 5.5V-tolerant inputs, Ioff; do not replace with resistor divider | sn74lvc2g17 | False | 09_can_ft
C55 | 100n | GEN-C-0402-100n-16V-X7R | CANView:Capacitor_SMD__C_0402_1005Metric | 16V; ±10%; X7R; -55..125C; verify effective capacitance under DC bias |  | False | 09_can_ft
U24 | SN74LVC2G125DCUR | SN74LVC2G125DCUR | CANView:Package_SO__VSSOP-8_2.3x2mm_P0.5mm | Dual independent tristate buffers; 3.3V PHY-domain supply | sn74lvc2g125: p4, Ioff | False | 10_tx_gate
U28 | SN74AHCT1G126-Q1 | CAHCT1G126DBVRQ1 | CANView:Package_TO_SOT_SMD__SOT-23-5 | 3..5.5V supply; TTL VIH2V at5V; active-high permit. OE LOW => Z even when PHY3V3 is absent; no general output Ioff claim | sn74ahct1g126-q1:pp3-5,8,13; active-high OE with pulldown; input tolerance independent of supply | False | 10_tx_gate
R66 | 1k | GEN-R-0402-1k-1% | CANView:Resistor_SMD__R_0402_1005Metric | 0.1W; 50V; ±1%; ±100ppm/K; -55..155C |  | False | 10_tx_gate | Required fail-closed OE pulldown, place at buffer pin1; about3.3mA permit driver load. Never replace with PHY-rail pull-up
C56 | 100n | GEN-C-0402-100n-16V-X7R | CANView:Capacitor_SMD__C_0402_1005Metric | 16V; ±10%; X7R; -55..125C; verify effective capacitance under DC bias |  | False | 10_tx_gate
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

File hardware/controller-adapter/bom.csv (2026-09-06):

ref | value | mpn | footprint | spec | source | dnp | sheet | note
J1 | Waveshare 2x16 mating male | GEN-2x16-MALE-2.54 | CANView:Connector_PinHeader_2.54mm__PinHeader_2x16_P2.54mm_Vertical | Mates with board female socket;2.54mm pitch verified, insertion height/board-side orientation require mechanical check;5V only when host source provides it | waveshare-controller schematic and official STEP HEADER-SMD-F-2_54-2X16PIN | False | 01_waveshare_header
C1 | 4.7u | GEN-C-0603-4.7u-16V-X7R | CANView:Capacitor_SMD__C_0603_1608Metric | 16V; ±10%; X7R; -55..125C; verify effective capacitance under DC bias |  | False | 01_waveshare_header
C2 | 100n | GEN-C-0402-100n-16V-X7R | CANView:Capacitor_SMD__C_0402_1005Metric | 16V; ±10%; X7R; -55..125C; verify effective capacitance under DC bias |  | False | 01_waveshare_header
U1 | SN65LVDS1DBVR | SN65LVDS1DBVR | CANView:Package_TO_SOT_SMD__SOT-23-5 | 3.3V LVDS endpoint; 100ohm twisted pair; shared ground required | sn65lvds1: pp3-4 DBV pin functions, timing tables | False | 02_i2s_differential
C3 | 100n | GEN-C-0402-100n-16V-X7R | CANView:Capacitor_SMD__C_0402_1005Metric | 16V; ±10%; X7R; -55..125C; verify effective capacitance under DC bias |  | False | 02_i2s_differential
U2 | SN65LVDS1DBVR | SN65LVDS1DBVR | CANView:Package_TO_SOT_SMD__SOT-23-5 | 3.3V LVDS endpoint; 100ohm twisted pair; shared ground required | sn65lvds1: pp3-4 DBV pin functions, timing tables | False | 02_i2s_differential
C4 | 100n | GEN-C-0402-100n-16V-X7R | CANView:Capacitor_SMD__C_0402_1005Metric | 16V; ±10%; X7R; -55..125C; verify effective capacitance under DC bias |  | False | 02_i2s_differential
R1 | 100 | GEN-R-0402-100-1% | CANView:Resistor_SMD__R_0402_1005Metric | 0.1W; 50V; ±1%; ±100ppm/K; -55..155C |  | False | 02_i2s_differential | 100ohm receiver-end differential termination; do not add at transmitter
U3 | SN65LVDS2DBVR | SN65LVDS2DBVR | CANView:Package_TO_SOT_SMD__SOT-23-5 | 3.3V LVDS endpoint; 100ohm twisted pair; shared ground required | sn65lvds1: pp3-4 DBV pin functions, timing tables | False | 02_i2s_differential
C5 | 100n | GEN-C-0402-100n-16V-X7R | CANView:Capacitor_SMD__C_0402_1005Metric | 16V; ±10%; X7R; -55..125C; verify effective capacitance under DC bias |  | False | 02_i2s_differential
J2 | REMOTE MIC / NOT ETHERNET | SM08B-GHS-TB(LF)(SN) | CANView:Connector_JST__JST_GH_SM08B-GHS-TB_1x08-1MP_P1.25mm_Horizontal | 8-wire4twisted-pairs; keyed GH8 both ends;1:1 cable <=3m design target, SI qualification required | jst-gh | False | 03_mic_cable
F1 | 0.10A PTC | MF-PSMF010X-2 | CANView:Fuse__Fuse_0805_2012Metric | 15V;Ihold0.1A@23C;Itrip0.3A;R1max7.5ohm;trip<=1.5s@0.5A; -40..85C; not a precision limiter | bourns-psmf:pp1-3 | False | 03_mic_cable
C6 | 1u | GEN-C-0603-1u-16V-X7R | CANView:Capacitor_SMD__C_0603_1608Metric | 16V; ±10%; X7R; -55..125C; verify effective capacitance under DC bias |  | False | 03_mic_cable
D1 | TPD2E2U06DCKR | TPD2E2U06DCKR | CANView:Package_TO_SOT_SMD__SOT-323_SC-70 | 5.5V standoff;1.5pF typical; ESD only, not DC overvoltage protection | tpd2e2u06:p3 DCK pins1/2=IO,pin3=GND | False | 03_mic_cable
D2 | TPD2E2U06DCKR | TPD2E2U06DCKR | CANView:Package_TO_SOT_SMD__SOT-323_SC-70 | 5.5V standoff;1.5pF typical; ESD only, not DC overvoltage protection | tpd2e2u06:p3 DCK pins1/2=IO,pin3=GND | False | 03_mic_cable
D3 | TPD2E2U06DCKR | TPD2E2U06DCKR | CANView:Package_TO_SOT_SMD__SOT-323_SC-70 | 5.5V standoff;1.5pF typical; ESD only, not DC overvoltage protection | tpd2e2u06:p3 DCK pins1/2=IO,pin3=GND | False | 03_mic_cable
R2 | 10k | GEN-R-0402-10k-1% | CANView:Resistor_SMD__R_0402_1005Metric | 0.1W; 50V; ±1%; ±100ppm/K; -55..155C |  | False | 04_ota_recovery
SW1 | RECOVERY | TL3342F160QG | CANView:Button_Switch_SMD__SW_SPST_TL3342 | Normally-open momentary; host reset is sink-only; hold recovery5s across reset |  | False | 04_ota_recovery
SW2 | HOST_RESET | TL3342F160QG | CANView:Button_Switch_SMD__SW_SPST_TL3342 | Normally-open momentary; host reset is sink-only; hold recovery5s across reset |  | False | 04_ota_recovery

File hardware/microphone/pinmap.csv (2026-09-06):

reference | mpn | pin | pin_name | electrical_type | net | sheet
J1 | SM08B-GHS-TB(LF)(SN) | 1 | 5V | passive | MIC5V | 01_receiver_power
J1 | SM08B-GHS-TB(LF)(SN) | 2 | GND | passive | GND | 01_receiver_power
J1 | SM08B-GHS-TB(LF)(SN) | 3 | BCLK_P | passive | CLK_P | 01_receiver_power
J1 | SM08B-GHS-TB(LF)(SN) | 4 | BCLK_N | passive | CLK_N | 01_receiver_power
J1 | SM08B-GHS-TB(LF)(SN) | 5 | WS_P | passive | WS_P | 01_receiver_power
J1 | SM08B-GHS-TB(LF)(SN) | 6 | WS_N | passive | WS_N | 01_receiver_power
J1 | SM08B-GHS-TB(LF)(SN) | 7 | DATA_P | passive | DATA_P | 01_receiver_power
J1 | SM08B-GHS-TB(LF)(SN) | 8 | DATA_N | passive | DATA_N | 01_receiver_power
J1 | SM08B-GHS-TB(LF)(SN) | MP | MECHANICAL_NC | passive | NC | 01_receiver_power
U1 | TPS7A2033PDBVR | 1 | IN | power_in | MIC5V | 01_receiver_power
U1 | TPS7A2033PDBVR | 2 | GND | power_in | GND | 01_receiver_power
U1 | TPS7A2033PDBVR | 3 | EN | input | MIC5V | 01_receiver_power
U1 | TPS7A2033PDBVR | 4 | NC | passive | NC | 01_receiver_power
U1 | TPS7A2033PDBVR | 5 | OUT | power_out | 3V3 | 01_receiver_power
C1 | GEN-C-0603-1u-16V-X7R | 1 | 1 | passive | MIC5V | 01_receiver_power
C1 | GEN-C-0603-1u-16V-X7R | 2 | 2 | passive | GND | 01_receiver_power
C2 | GEN-C-0603-2.2u-16V-X7R | 1 | 1 | passive | 3V3 | 01_receiver_power
C2 | GEN-C-0603-2.2u-16V-X7R | 2 | 2 | passive | GND | 01_receiver_power
U2 | TPS7A2018PDBVR | 1 | IN | power_in | 3V3 | 01_receiver_power
U2 | TPS7A2018PDBVR | 2 | GND | power_in | GND | 01_receiver_power
U2 | TPS7A2018PDBVR | 3 | EN | input | 3V3 | 01_receiver_power
U2 | TPS7A2018PDBVR | 4 | NC | passive | NC | 01_receiver_power
U2 | TPS7A2018PDBVR | 5 | OUT | power_out | 1V8 | 01_receiver_power
C3 | GEN-C-0603-1u-16V-X7R | 1 | 1 | passive | 3V3 | 01_receiver_power
C3 | GEN-C-0603-1u-16V-X7R | 2 | 2 | passive | GND | 01_receiver_power
C4 | GEN-C-0603-2.2u-16V-X7R | 1 | 1 | passive | 1V8 | 01_receiver_power
C4 | GEN-C-0603-2.2u-16V-X7R | 2 | 2 | passive | GND | 01_receiver_power
D1 | TPD2E2U06DCKR | 1 | IO1 | passive | CLK_P | 01_receiver_power
D1 | TPD2E2U06DCKR | 2 | IO2 | passive | CLK_N | 01_receiver_power
D1 | TPD2E2U06DCKR | 3 | GND | passive | GND | 01_receiver_power
D2 | TPD2E2U06DCKR | 1 | IO1 | passive | WS_P | 01_receiver_power
D2 | TPD2E2U06DCKR | 2 | IO2 | passive | WS_N | 01_receiver_power
D2 | TPD2E2U06DCKR | 3 | GND | passive | GND | 01_receiver_power
D3 | TPD2E2U06DCKR | 1 | IO1 | passive | DATA_P | 01_receiver_power
D3 | TPD2E2U06DCKR | 2 | IO2 | passive | DATA_N | 01_receiver_power
D3 | TPD2E2U06DCKR | 3 | GND | passive | GND | 01_receiver_power
R1 | GEN-R-0402-100-1% | 1 | 1 | passive | CLK_P | 02_i2s_link
R1 | GEN-R-0402-100-1% | 2 | 2 | passive | CLK_N | 02_i2s_link
U3 | SN65LVDS2DBVR | 1 | VCC | power_in | 3V3 | 02_i2s_link
U3 | SN65LVDS2DBVR | 2 | GND | power_in | GND | 02_i2s_link
U3 | SN65LVDS2DBVR | 3 | A_P | input | CLK_P | 02_i2s_link
U3 | SN65LVDS2DBVR | 4 | B_N | input | CLK_N | 02_i2s_link
U3 | SN65LVDS2DBVR | 5 | R | output | BCLK_3V3 | 02_i2s_link
C5 | GEN-C-0402-100n-16V-X7R | 1 | 1 | passive | 3V3 | 02_i2s_link
C5 | GEN-C-0402-100n-16V-X7R | 2 | 2 | passive | GND | 02_i2s_link
R2 | GEN-R-0402-100-1% | 1 | 1 | passive | WS_P | 02_i2s_link
R2 | GEN-R-0402-100-1% | 2 | 2 | passive | WS_N | 02_i2s_link
U4 | SN65LVDS2DBVR | 1 | VCC | power_in | 3V3 | 02_i2s_link
U4 | SN65LVDS2DBVR | 2 | GND | power_in | GND | 02_i2s_link
U4 | SN65LVDS2DBVR | 3 | A_P | input | WS_P | 02_i2s_link
U4 | SN65LVDS2DBVR | 4 | B_N | input | WS_N | 02_i2s_link
U4 | SN65LVDS2DBVR | 5 | R | output | WS_3V3 | 02_i2s_link
C6 | GEN-C-0402-100n-16V-X7R | 1 | 1 | passive | 3V3 | 02_i2s_link
C6 | GEN-C-0402-100n-16V-X7R | 2 | 2 | passive | GND | 02_i2s_link
U5 | SN65LVDS1DBVR | 1 | VCC | power_in | 3V3 | 02_i2s_link
U5 | SN65LVDS1DBVR | 2 | GND | power_in | GND | 02_i2s_link
U5 | SN65LVDS1DBVR | 3 | Z_N | output | DATA_N | 02_i2s_link
U5 | SN65LVDS1DBVR | 4 | Y_P | output | DATA_P | 02_i2s_link
U5 | SN65LVDS1DBVR | 5 | D | input | DATA_3V3 | 02_i2s_link
C7 | GEN-C-0402-100n-16V-X7R | 1 | 1 | passive | 3V3 | 02_i2s_link
C7 | GEN-C-0402-100n-16V-X7R | 2 | 2 | passive | GND | 02_i2s_link
MK1 | MMICT5848-00-012 | 1 | WS | input | WS_1V8 | 03_mems_microphone
MK1 | MMICT5848-00-012 | 2 | LR | input | GND | 03_mems_microphone
MK1 | MMICT5848-00-012 | 3 | GND | power_in | GND | 03_mems_microphone
MK1 | MMICT5848-00-012 | 4 | WAKE | output | NC | 03_mems_microphone
MK1 | MMICT5848-00-012 | 5 | THSEL | input | NC | 03_mems_microphone
MK1 | MMICT5848-00-012 | 6 | SCK | input | BCLK_1V8 | 03_mems_microphone
MK1 | MMICT5848-00-012 | 7 | VDD | power_in | 1V8 | 03_mems_microphone
MK1 | MMICT5848-00-012 | 8 | SD | output | DATA_1V8 | 03_mems_microphone
C8 | GEN-C-0402-100n-16V-X7R | 1 | 1 | passive | 1V8 | 03_mems_microphone
C8 | GEN-C-0402-100n-16V-X7R | 2 | 2 | passive | GND | 03_mems_microphone
R3 | GEN-R-0402-100k-1% | 1 | 1 | passive | DATA_1V8 | 03_mems_microphone
R3 | GEN-R-0402-100k-1% | 2 | 2 | passive | GND | 03_mems_microphone
U6 | SN74AXC1T45DCKR | 1 | VCCA | power_in | 1V8 | 03_mems_microphone
U6 | SN74AXC1T45DCKR | 2 | GND | power_in | GND | 03_mems_microphone
U6 | SN74AXC1T45DCKR | 3 | A | bidirectional | BCLK_1V8 | 03_mems_microphone
U6 | SN74AXC1T45DCKR | 4 | B | bidirectional | BCLK_3V3 | 03_mems_microphone
U6 | SN74AXC1T45DCKR | 5 | DIR | input | GND | 03_mems_microphone
U6 | SN74AXC1T45DCKR | 6 | VCCB | power_in | 3V3 | 03_mems_microphone
C9 | GEN-C-0402-100n-16V-X7R | 1 | 1 | passive | 1V8 | 03_mems_microphone
C9 | GEN-C-0402-100n-16V-X7R | 2 | 2 | passive | GND | 03_mems_microphone
C10 | GEN-C-0402-100n-16V-X7R | 1 | 1 | passive | 3V3 | 03_mems_microphone
C10 | GEN-C-0402-100n-16V-X7R | 2 | 2 | passive | GND | 03_mems_microphone
U7 | SN74AXC1T45DCKR | 1 | VCCA | power_in | 1V8 | 03_mems_microphone
U7 | SN74AXC1T45DCKR | 2 | GND | power_in | GND | 03_mems_microphone
U7 | SN74AXC1T45DCKR | 3 | A | bidirectional | WS_1V8 | 03_mems_microphone
U7 | SN74AXC1T45DCKR | 4 | B | bidirectional | WS_3V3 | 03_mems_microphone
U7 | SN74AXC1T45DCKR | 5 | DIR | input | GND | 03_mems_microphone
U7 | SN74AXC1T45DCKR | 6 | VCCB | power_in | 3V3 | 03_mems_microphone
C11 | GEN-C-0402-100n-16V-X7R | 1 | 1 | passive | 1V8 | 03_mems_microphone
C11 | GEN-C-0402-100n-16V-X7R | 2 | 2 | passive | GND | 03_mems_microphone
C12 | GEN-C-0402-100n-16V-X7R | 1 | 1 | passive | 3V3 | 03_mems_microphone
C12 | GEN-C-0402-100n-16V-X7R | 2 | 2 | passive | GND | 03_mems_microphone
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

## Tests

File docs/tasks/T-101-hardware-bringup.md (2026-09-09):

# T-101 Communicator PCB bring-up과 전원/reset fault 검증

- 상태: `BLOCKED`
- 우선순위: `P0`
- Gate: `G1`
- 선행: `T-100a`, `T-500`
- 외부 선행: 조립 PCB, T-102/T-200의 시험용 boot image, bench 장비
- 후속: `T-501`, `T-106`

## 목표

설계 계산이 실제 PCB에서 성립하고 모든 비정상 전원 순서가 CAN TX 비활성으로 수렴함을 계측한다.

## 시험 준비

- current-limited programmable supply와 transient source 또는 검증된 pulse fixture
- oscilloscope/logic analyzer, electronic load, CAN simulator/analyzer
- 세 CAN channel dummy bus와 독립 termination
- hard gate off가 물리적으로 확인되는 `CAPTURE_ONLY` image
- test report template와 board serial/revision

## 순서

1. unpowered resistance/short와 termination population 확인
2. MCU 미실장 또는 reset held 상태의 rail sequence·TXD/STB/EN 측정
3. 12 V nominal, slow ramp, fast cycle, brownout, cold-crank profile
4. reverse input와 OV cutoff/reconnect
5. ESP32 RF burst·세 PHY load에서 5 V/3.3 V droop와 thermal
6. STM/ESP 개별 reset, SWD reset, boot failure, watchdog loop
7. TXD stuck-low injection과 hard gate off 차단
8. CAN short-to-ground/battery, bus-off, MAX ERR
9. 4 Mbps UART eye와 CTS stall
10. 외부 IGN/ACC 차단·USB service의 OFF/current 검증 (CAN wake 없음)
11. BATT/ACC/USB/SWD의 모든 투입·제거 순서와 phantom power
12. PROTECTED_VBAT UV에서 MAX3055 BATT/VCC/EN/TXD와 hard gate timing

## 수용 기준

- [ ] 어떤 reset/brownout 시험에서도 unintended dominant pulse가 검출되지 않는다.
- [ ] hard gate off에서 MCU pin low fault가 bus dominant를 만들지 않는다.
- [ ] 차량/USB mux·SYS/PHY 각 rail의 실제 경로와 독립 supervisor threshold/delay·상승/하강 순서가 현행 회로 계산 범위 안이다. 모든 경우를 단일 5 V PGOOD→3.3 V 순서로 가정하지 않는다.
- [ ] rail droop가 MCU/PHY UV threshold margin을 침범하지 않는다.
- [ ] OV cutoff/reconnect에서 oscillation/chatter가 없다.
- [ ] CAN fault 뒤 부품 손상·latch-up·역급전이 없다.
- [ ] UART 4 Mbps 오류율과 eye margin이 기준을 만족한다.
- [ ] 외부 IGN/ACC OFF·USB 유무 조합의 current와 phantom power를 측정하고 상시 BAT+의 1 mA/자동 CAN wake를 달성했다고 표시하지 않는다.
- [ ] 72시간 OFF 및 온도 corner에서 의도하지 않은 재기동·역급전이 없다.
- [ ] CPU halt, ISR spin, WDI 미갱신/과속·정상 cadence 오갱신에서 외부 guardian 동작과 한계가 기록된다.
- [ ] gate off에서는 TXD valid-frame/stuck-low injection에도 세 bus의 dominant/ACK/error/data frame이 0건이다.

## 계획 보완 수용 기준

- [ ] 독립 ESP/STM reset, J31 제거/재삽입, GPIO7·48 고착, stale ARM edge를 현행 회로로 측정한다. OTA flash cut-point 시험은 T-508에서 별도 수행한다.
- [ ] `run_power_faults.py`, `assert_no_tx.py`, `validate_hardware_evidence.py`는 T-500 공용 rig API로 이 task에서 구현·등록하고 실패 fixture부터 확인한다.

## 검증

```bash
python tests/hil/run_power_faults.py --rig-config private/rig.yaml --board-rev REV
# 세 값은 같은 실행의 trusted evidence manifest에서 주입한다.
python tests/hil/assert_no_tx.py evidence/latest/can-analyzer.log `
  --expected-source <manifest-source> `
  --expected-execution-id <manifest-execution-id> `
  --expected-firmware-identity <manifest-firmware-identity>
python tests/hil/validate_hardware_evidence.py evidence/hardware/REV/SERIAL
```

## 증거

`evidence/hardware/<board-rev>/<serial>/`에 setup 사진, scope CSV/PNG, supply profile, firmware digest, 결과 JSON을 저장한다. 대용량 원본은 release storage URL과 SHA-256만 repo에 둔다.

## rollback

한 항목이라도 실패하면 board revision을 `CAPTURE_ONLY laboratory`로 표시한다. resistor 값만 조용히 바꿔 재시험하지 말고 BOM variant와 재시험 ID를 남긴다.

## 산출물·범위 경계

- 예상 산출물은 `tests/hil/` power/rail/gate script·negative 로그 fixture와 `docs/hardware/r1/verification.md`의 실측 evidence다. PCB routing 변경/발주 및 vehicle TX 기능은 범위 밖이다.

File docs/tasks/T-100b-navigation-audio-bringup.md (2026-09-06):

# T-100b R1 센서·원격 수음·전원 상태 firmware와 bring-up

- 상태: `BLOCKED`
- 우선순위: `P1`
- Gate: `G1/G2` 보조, 차량 TX 승인 아님
- 선행: `T-002`, `T-004`, `T-101`, `T-200`, `T-201`, `T-202`, `T-203`, `T-300`, `T-303`, `T-304`
- 외부 선행: 실물 보드·GNSS·마이크, 승인된 센서 장착·배선

## 목표와 고정 결정

[R1 pinmap](../hardware/r1/firmware-pinmap.md), [센서 회로](../hardware/r1/navigation-hardware.md), [mic 회로](../hardware/r1/bridge-controller-microphone.md), [navigation wire](../architecture/protocols/navigation.md)를 firmware와 bench evidence로 연결한다. Communicator N16R8/Bridge N8R2 module 차이를 보존하고 BMP384는 MTi AUX SPI 소유다. 기존 generic CAN 경로와 Controller 제한 의미 제어 권한을 바꾸지 않는다.

## 구현 범위

1. ESP-IDF BSP UART/RTS/CTS, MTSSP SPI/DRDY/open-drain reset, GPS switched power/read-only tap/PPS를 pinmap revision으로 구현한다. STM CMake BSP에 HSE/PG10-NRST/AF/gate health를 반영한다.
2. driver와 business model을 분리한다. ISR은 event/timestamp만 넘기고 host parser/fusion quality/telemetry는 task에서 수행한다. bounded buffers/queue bytes/priority/WCET/watchdog ownership을 문서화한다.
3. capability/version 협상과 peer별 atomic subscribe allocator, 전체8192B/s/peer4096B/s,latest-only/drop/count,16entry/30s result cache/high-water mark를 구현한다. ACK와 APPLIED를 구분한다.
4. GNSS/MTi firmware identity·baud/config readback, PPS epoch/clock anchor,45초 DR expiry,stale/reacquire,baro P0/mount revision을 구현한다. sensor fault로 CAN capture를 재부팅하지 않는다.
5. Controller I²S1 32kHz/64fs, DMA/FFT/level/peak와 mic health, 기존 volume automation holdoff/ramp를 통합한다. camera conflict를 build configuration에서 금지한다.
6. RTC0x51 oscillator-stop/백업/write-readback/source quality와 일몰 경고의 invalid 처리를 실제 보드로 검증한다.

## 예상 변경 파일

`firmware/communicator/{esp32,stm32}/`, `firmware/controller/`, `protocol/schema/`, 생성 codec, `tests/`, R1 pinmap 검증, `docs/hardware/r1/`의 실측 evidence. 구체 module 경계는 해당 embedded skills와 기존 architecture를 먼저 따른다.

## 수용 기준

- [ ] Windows target build와 host CI가 같은 pin/schema revision을 사용한다.
- [ ] 실제4Mbps CTS stall/overflow/reboot/frame corruption에서 bounded recovery한다.
- [ ] 수신/센서-only 모드에서 physical ARM 유무와 관계없이 vehicle TX를 실행하지 않는다.
- [ ] duplicate/lost RESULT/expired cache/conflict/reboot/revision wrap/동시 peer quota 시험이 통과한다.
- [ ] F9P UART1+UART2 PPS와 MTi firmware 조합이 readback·outage·재획득 시험을 통과한다.
- [ ] mic0.5/1/3m·고온/단락·탈착·clock loss에서 data integrity와 host 보호가 확인된다.
- [ ] 원음/실제 위치/키가 공개 Git에 들어가지 않는다. 합성 golden fixture만 공유한다.
- [ ] 모든 미지원 센서는 정상 숫자 대신 invalid/미지원으로 표시한다.

## 계획 보완 수용 기준

- [ ] ESP-NOW 1.4/UART 1.1 미협상 peer에는 센서 메시지가 0건이며 1.3/1.0 CAN 기능은 보존된다.
- [ ] calibration/P0/mount 설정의 owner, schema/revision, 영속 write/readback와 실패 복구를 T-304/T-205 저장 계약에 맞춰 확인한다.
- [ ] 16 kHz 온보드 분석과 32 kHz 원격 수음은 source별 설정·calibration을 분리한다. T-303 DSP를 재사용하고 T-100b는 원격 SI/센서 통합 evidence를 소유한다.

## 검증·evidence·rollback

현 단계 host 명령은 `python -m unittest discover -s tools/protocol -p test_navigation_codec.py -v`다. 이것만으로 위 acceptance를 체크하지 않는다. target map/build log, logic analyzer/Oscope waveform, sample counter/latency/power trace를 revision·환경·장비 정보와 함께 기록한다. 민감 위치/음성 원본은 로컬에 둔다.

범위 밖: 차량 제어 신호 확정, RTK 보정망 운영, 무제한 DR, 새 raw CAN 송신 API, 상시 BAT/CAN wake 회로. 실패 시 sensors/mic automation capability를 끄고 capture-only를 유지한다. 보호 gate를 firmware로 우회해 시험을 진행하지 않는다.

## 산출물·범위 경계

- CAN evidence 승격·차량 제어 권한 확대·OTA 공통 manager 구현은 범위 밖이다. 지원 센서가 없으면 정상 수치로 대체하지 않는다.

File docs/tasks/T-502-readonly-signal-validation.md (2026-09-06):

# T-502 4WD, TPMS, DPF, 연비와 주행 신호 read-only 승격

- 상태: `BLOCKED`
- 우선순위: `P1`
- Gate: `G3`
- 선행: `T-501`, `T-301`, `T-403`
- 병렬 가능: `T-503`

## 목표

운전자 기본 화면에 필요한 신호를 실차 evidence로 VERIFIED 승격하고 정상·stale·fault UI를 완성한다.

## 우선순위

1. speed, RPM, battery voltage, transmission clutch lock, transmission temperature, engine temperature
2. 4WD rear coupling/clutch torque 후보와 바퀴별 drive index
3. TPMS FL/FR/RL/RR와 warning mapping
4. instant fuel economy
5. DPF lamp; soot/load/regeneration은 별도 진단 근거가 있을 때만
6. speed limit, tail/headlamp, dimmer, drive mode feedback

## 검증 방법

- 최소 3 ignition cycle, independent action repetition, negative control
- OEM cluster/scanner/physical gauge와 같은 시간축 비교
- unit, sign, byte order, wheel order, invalid raw, range, period, stale threshold 확인
- derived 4WD index는 실제 wheel torque percent로 이름 붙이지 않음
- DPF lamp off를 regeneration complete로 해석하지 않음

## 수용 기준

- [ ] 각 승격 signal에 evidence ID, raw vector, unit/range/freshness가 있다.
- [ ] TPMS wheel order는 한 바퀴씩 압력 변화로 확인된다.
- [ ] 4WD 표시가 검증된 물리량과 추정값을 명확히 구분한다.
- [ ] DPF unavailable field가 demo 숫자를 표시하지 않는다.
- [ ] stale/fault/unavailable에서 마지막 숫자를 고정하지 않는다.
- [ ] 경고 없는 기본 화면과 각 fault/과속/야간 screenshot이 있다.
- [ ] candidate 값은 운전자 화면 output에서 차단된다.

## 계획 보완 수용 기준

- [ ] 미션 lock과 미션 온도는 엔진 온도/4WD LOCK과 분리해 OEM scanner·실측에 대조한다. direct lock 신호 부재 시 RPM/slip 추정을 확정 lock으로 승격하지 않는다.
- [ ] 순간연비의 km/L·L/100 km·단위 enum·공회전·연료차단·0·invalid/max sentinel을 대조하며 injector 추정으로 빈칸을 채우지 않는다.
- [ ] SPORT용 gear/brake/ABS/TCS/ESC/longitudinal acceleration/drive mode의 valid·status·freshness·manual override 근거도 T-505a에 제공한다. GNSS/INS를 CAN safety 대신 쓰지 않는다.
- [ ] 정상 lamp off는 검증된 lamp 의미만 나타내며 soot/load/regen 또는 모든 DPF 정상을 보장하지 않는다. 범위 내 미지원 항목은 이유·추가 evidence gate를 남긴다.

## 검증

```bash
python tools/validate_cvtrace.py private/evidence/<capture>.cvtrace
python tools/generate_vehicle_profile.py vehicle-profiles/tucson-tl-2017/profile.yaml --check
python tests/profile/cross_decode.py vehicle-profiles/tucson-tl-2017/profile.yaml
python tests/ui/capture_screens.py --profile tucson-tl-2017 --all-quality-states
```

## 결과 문서

`docs/vehicle/signal-catalog.md`, `docs/vehicle/target-2017-tucson.md`, profile report와 UI screenshot을 함께 갱신한다.

## 산출물·범위 경계

- 위 신호별 read-only 검증 matrix가 구현 범위다. 산출물은 `tests/vehicle/` 분석/부정 fixture, profile/evidence manifest와 `docs/vehicle/signal-catalog.md`다. OBD/UDS query·DPF 강제 재생·candidate 정상 UI는 범위 밖이다.
- 미증명 신호는 미확인/미지원으로 남기고 해당 기능 gate를 닫는다. 미지원 사유는 release 제한으로 추적한다.

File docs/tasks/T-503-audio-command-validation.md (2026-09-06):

# T-503 OEM audio command와 feedback 수신 조사

- 상태: `BLOCKED`
- 우선순위: `P0`
- Gate: `G3` 수신 조사; bench 송신·복원은 T-503a
- 선행: `T-501`, `T-403`, `T-500`
- 후속: `T-106`, `T-503a`

## 목표

취침 mode, 뒷좌석 강화, 상대 volume offset과 OEM snapshot 복원에 필요한 frame owner, alive counter, checksum, feedback을 수신 조사와 offline 비교로 검증한다. 실제 bench 송신·복원 재현은 T-503a가 담당한다.

## 조사 항목

- physical head-unit 조작 전후 TX owner와 arbitration ID
- volume/fader/balance/main mute/rear mute/SDVC signal 방향과 enum/range
- alive counter/checksum 계산과 다른 field 보존
- command event인지 periodic owner frame인지
- 적용 feedback, OEM manual override, source/phone/reverse 안내와 충돌
- ignition cycle/reboot 때 OEM default와 snapshot validity

## 고정 기능 경계

- Controller는 raw fader/balance UI를 제공하지 않는다.
- semantic profile은 필요한 scope 전체가 있을 때만 atomic하게 적용한다.
- periodic owner spoof는 owner arbitration과 충돌 해소 근거 없이 금지한다.
- audio snapshot이 stale/unknown이면 restore를 실행하지 않고 기능을 disable한다.

## 수용 기준

- [ ] 각 field/counter/checksum/feedback에 반복 capture와 negative control이 있다.
- [ ] physical operation과 offline generated frame의 byte/mask 비교가 일치한다. 실제 bench TX 비교는 T-503a에서 수행한다.
- [ ] unrelated payload bit가 바뀌는 frame이 0개다.
- [ ] partial profile failure와 reverse/call/manual override의 기대 복원 matrix·timeout·scope를 정의하고 T-503a로 전달한다.
- [ ] snapshot revision/TTL과 ignition invalidation 규칙이 test로 고정된다.
- [ ] vehicle profile generator가 VERIFIED evidence 없이는 audio command를 생성하지 않는다.

## 검증

```bash
python tests/audio/analyze_owner_counter.py private/evidence/audio/*.cvtrace
python tests/audio/check_capture_vectors.py --no-transmit
```

## 차량 송신 금지

이 task 전체는 read-only다. 현재 없는 두 audio 분석 script는 이 task의 산출물이다. 실물 bench 명령·restore 시험은 T-106 이후 T-503a에서 수행하며 조사 완료가 차량 송신 승인이 아니다.

## 결정 변경 기록

2026-09-06 계획 감사: T-106이 필요했던 기존 bench acceptance를 T-503a로 옮겨 조사→executor→bench 순서를 만들었다. wire/profile 권한은 변경하지 않는다.

## 산출물·범위 경계

- 위 조사 항목과 두 audio 분석 script·합성 offline fixture·source manifest가 산출 범위다. CAN bench/차량 TX는 범위 밖이며 비교 실패 시 candidate로 유지한다.

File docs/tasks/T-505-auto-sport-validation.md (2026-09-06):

# T-505 자동 SPORT monitor, HIL과 폐쇄시험

- 상태: `BLOCKED`
- 우선순위: `P2`
- Gate: `G4/G5`
- 선행: `T-106`, `T-305`, `T-505a`, `T-500`, `T-508`
- 병렬 가능: `T-504`

## 목표

속도 또는 중속 이상 급가속을 감지해 SPORT로 전환하고 속도가 충분히 내려가면 이전 mode로 복귀하는 기능을 monitor-only부터 단계적으로 검증한다.

## 고정 로직

- entry speed 선택 60/70/80 km/h; exit는 entry−15 km/h
- speed entry confirmation, exit confirmation, minimum SPORT hold
- acceleration은 중속 이상에서 median-filtered longitudinal value와 hysteresis 사용
- brake, reverse/non-forward, ABS/TCS/ESC, stale signal, mode fault, link/lease 문제에서 inhibit
- 실제 운전자 mode 변경은 manual hold로 우선
- previous mode raw 값을 직접 ECU에 쓰지 않고 검증된 button event를 feedback마다 한 번씩 사용
- safety input freshness ceiling 300 ms, tick gap 250 ms 초과 시 dwell reset과 pulse 금지
- `DISABLED/MONITOR_ONLY/ARMED_TX/PENDING/ACTIVE/INHIBITED` 분리, reboot 기본 MONITOR_ONLY
- entry setter는 wire 600/700/800만 받아들이고 그 밖의 값을 clamp하지 않고 무변경 거부
- feedback timeout 1,500 ms는 first physical TX-complete 기준

## 단계

1. capture replay와 pure C state machine
2. 실제 주행 `MONITOR_ONLY`: proposed action만 log, TX 0
3. HIL에서 button/feedback/timeout/fault
4. 정차 bench의 한 pulse
5. 폐쇄시험장에서 기능별 opt-in

## 수용 기준

- [ ] MONITOR_ONLY analyzer에서 TX 0건이다.
- [ ] threshold 주변 속도/가속도 noise에서 chatter가 없다.
- [ ] SPORT 진입 전 previous mode를 한 번 snapshot하고 external change에서 ownership을 놓는다.
- [ ] exit는 minimum hold와 confirm을 모두 만족해야 한다.
- [ ] feedback 없는 반복 pulse가 command limit을 넘지 않는다.
- [ ] 모든 inhibit/fault에서 새 pulse 0건이다.
- [ ] T-505a에서 해당 차량에 실제 확인한 mode만 이전 mode로 복귀하고 미관측 ECO/SMART/COMFORT 등을 있다고 가정하지 않는다. unknown은 자동화 disable이다.
- [ ] stale signal이나 scheduler stall이 entry/exit confirmation을 충족시키거나 복귀 pulse를 만들지 않는다.
- [ ] enable만으로는 action/TX 0건이고 explicit arm+G5 capability 뒤에만 pulse가 가능하다.
- [ ] 590/650/730/750/810은 거부·state 불변, 600/700/800만 성공한다.

## 검증

```bash
ctest --preset host-sanitize -R auto-sport --output-on-failure
python tests/vehicle/replay_sport_monitor.py private/evidence/drive/*.cvtrace
python tests/hil/run_auto_sport_matrix.py --bench-only
```

## release

기본 off, opt-in이다. public road에서 첫 TX 시험을 하지 않는다. 폐쇄시험 evidence와 rollback 확인 전 G5를 통과시키지 않는다.

## 산출물·범위 경계

- 위 단계와 inhibit/복귀 matrix가 구현 범위다. 산출물은 STM SPORT·Controller arm 통합·replay/HIL scripts·feature report다. 다른 ECU 제어·미확인 mode·일반도로 첫 TX는 범위 밖이다.
- T-508 포함 작업대/보안 gate 뒤에만 새 OTA firmware로 차량 시험한다. 실패 시 disarm/monitor-only로 남고 previous mode feedback 없이 복귀 완료로 표시하지 않는다.

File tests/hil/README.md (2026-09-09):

# T-500 fault bench와 HIL harness

T-500은 protocol loss, reset, UART fault, CAN load와 safety/resource 경계를
같은 scenario 형식으로 반복 실행하기 위한 공용 harness다. 이 구현은 먼저
하드웨어와 분리된 deterministic host subset과 fail-closed lab adapter 계약을
제공한다. host PASS는 board/HIL PASS가 아니며, 실제 rig가 없으면 `SKIPPED` 또는
`BLOCKED`로 끝난다.

## Scenario 형식

`scenarios/*.yaml`은 외부 YAML dependency 없이 읽을 수 있는 YAML 1.2
JSON-compatible subset이다. JSON은 YAML 1.2의 유효한 표현이므로 Windows와 CI의
parser 차이를 없애면서 `schema_version`, `id`, `suites`, `mode`, `actions`,
`expect`를 동일하게 유지한다. scenario digest는 canonical 내용에서 계산한다.

현재 inventory는 ESP-NOW loss/delay, 독립 reset, UART byte/CTS fault, 세 CAN
channel load, pool/queue exhaustion, stale/revision/profile/lease/hard-gate deny,
duplicate command, result/feedback timeout, brownout, injection/cache overflow,
guardian timeout, SoftAP/observer radio pressure의 12개다.

## 실행

```powershell
python -B tests/hil/run.py --suite host --seed 1 --output build/hil-host
python -B tests/hil/validate_evidence.py build/hil-host --expect-status PASS

# 선택 실행은 validator에 trusted selection을 별도로 전달한다.
python -B tests/hil/validate_evidence.py build/hil-selected `
  --expect-status PASS --expected-scenario brownout

# local rig가 없을 때는 성공으로 승격되지 않는다.
python -B tests/hil/run.py --suite g2-readonly `
  --rig-config tests/hil/rig.example.yaml --output build/hil-g2
python -B tests/hil/validate_evidence.py build/hil-g2 --expect-status SKIPPED
```

실제 lab 설정은 `lab-contract-v1` adapter, 세 CAN channel과 장치 식별자만
공개 metadata로 둔다. serial/port/secret은 private 파일에서만 공급한다.
현재 연결된 lab backend가 없으므로 `available: true`도 실행을 가장하지 않고
`BLOCKED`로 반환한다. 실제 hardware adapter와 G2/G4 결과는 T-101, T-103,
T-104, T-201, T-501, T-503a, T-505, T-508이 각각 소유한다.

## Evidence contract

runner는 report JSON과 scenario별 JSONL을 생성한다. report에는 seed, firmware와
harness source digest, 실행별 event identity, scenario digest, adapter, metrics,
physical/HIL 상태가 들어간다. runner가 만든 각 JSONL event에는 report의
execution_id와 firmware source SHA-256 identity가 동일하게 들어가며, monotonic timestamp,
연속 sequence와 byte `log_offset`도 있다. analyzer는 다음 순서로 첫 위반을 보존한다.

JSONL record delimiter는 ASCII LF(`\n`) 하나로 고정한다. JSON 문자열 안의
U+0085/U+2028/U+2029 같은 Unicode line separator는 record를 나누지 않으며,
writer·reader·byte offset 검증이 같은 delimiter 규칙을 사용한다.

1. event 존재·sequence·monotonic timeline
2. `CAPTURE_ONLY` CAN TX 0 및 command allow-list
3. expected event/field
4. map/stack/heap/queue/WCET/latency budget

scenario가 `ordered_events`를 선언하면 action event의 순서와 field subset을
앞에서부터 검증하고, 모든 실행은 `CAPTURE_ONLY` `TX_GATE_STATE`와
`HARNESS_COMPLETE`로 끝나야 한다. `validate_evidence.py`는 trusted host
scenario의 PASS report에 대해 현재 inventory를 deterministic replay하여 event,
metric, seed와 byte length를 report와 대조한다. 따라서 report에 적힌 metric만으로
예산 통과를 주장할 수 없다. selection을 생략한 PASS 검증은 trusted 전체 host
inventory를 요구하며, 선택 실행은 `--expected-scenario` 또는 API의
`expected_scenarios`로 caller가 지정한 trusted 부분집합과 정확히 일치해야 한다.
trusted PASS는 `trusted-replay`, custom FAIL은 구조적 analyzer 결과만 재계산하는
`structural-only`로 표시하며, 후자는 임의 scenario assertion의 증거로 승격하지
않는다. custom scenario의 `expect`는 report에 반영하지 않고 구조적 검사에는
빈 assertion contract를 사용한다. report와 event log는 각각 bounded writer와
validator의 공통 8 MiB report/event 상한을 적용하며, 상한을 넘으면 compact
`BLOCKED` report를 남긴다.

실패 report는 반드시 `first_violation.invariant`와 `log_offset`을 포함한다.
`fixtures/forbidden-can-tx.jsonl`은 capture-only TX 판정이 실제로 실패해야 하는
negative fixture다. positive host scenario에서는 CAN TX event를 생성하지 않는다.
T-103 전용 `run_can_capture.py`는 host runner가 만든 can-load event log를 report의
`execution_id`와 firmware `source_sha256` identity로 strict no-TX analyzer에
다시 전달하며, synthetic fixture 검사는 이 연결을 대신하지 않는다.

`run_can_capture.py`의 T-103 smoke는 expected candidate commit, firmware source
digest, harness source digest를 필수로 받아 현재 checkout과 report identity가
같은지 확인한다. 세 값은 동일한 evidence manifest에서 주입해야 하며, harness
digest가 맞지 않으면 report 생성 전에 `BLOCKED`로 끝난다.

`--suite g2-readonly`는 같은 scenario inventory를 소비하지만 rig 설정이 없거나
하드웨어가 없으면 실행을 거부한다. 따라서 host simulator를 physical evidence로
재사용하지 않는다.

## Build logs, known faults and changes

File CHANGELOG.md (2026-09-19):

# CHANGELOG

이 문서는 사용자에게 보이는 변경을 기록한다.

## [Unreleased]

### Added

- OTA v2 서명 컨테이너의 C99 bounded 수신·호환성/버전 검사, 일반 조립/native 검사 CLI와 합성 signed golden을 추가했다. 인증 전 수신 저장 금지와 오류 후 쓰기 차단을 검증하며, 실제 Flash 설치·영속 정책·장치/HIL 검증은 후속 작업이다.

- Bridge N8R2에 공용 ESP bench core·메모리/입력 계약·watchdog 진단을 연결하고 Communicator와 중복 없이 재사용한다. 두 보드 host/SDK 설정 교차 부정 시험을 포함하며 무선·웹·차량 권한은 활성화하지 않는다.

- Communicator ESP32 bench core에 C99 health·고정 pool, 단일 owner TWDT·메모리·USB 진단과 실제 SDK 설정 차단을 추가했다. 넓은 실패·동시성·coverage 시험을 포함하며 실제 통신/OTA/HIL은 후속 gate다.

- STM32 최소 boot/fault bench core에 bounded HSE/PLL·IWDG·TIM2/SysTick, 진척 감시 scheduler·고정 queue와 host fault 검증을 추가했다. 실제 UART/CAN/OTA·보드 G1/G2는 포함하지 않는다.

- 네 MCU의 안전 idle/BSP/platform 프로젝트, MCU 독립 C99 framing·CRC·COBS·classic CAN batch·sequence window를 추가했다. 보드 pin/config 생성, 넓은 host 시험·coverage·strict API 문서를 포함하며 실제 통신·차량 송신·OTA 기능은 후속 구현이다.

- 전체 계획 2차 대조용 요구사항 추적표와 누락된 OTA·PCB·오디오/SPORT evidence 작업 11개, task metadata/선행 DAG 검증을 추가했다. 제품 구현·차량 승인과 계획 완료를 분리했다.
- 운전자/진단 웹 5뷰씩의 오프라인 동작 검사와 공식 LVGL8.4 실제 host 수명·상태 회귀시험을 추가했다.
- Bridge 없이 가능한 장치별 브라우저 OTA, STM 내부 이중 슬롯 복구와 설치 승인·버전 정책을 단일 [설계·리뷰 문서](docs/architecture/ota.md)에 추가했다. OTA 펌웨어 구현은 후속 단계다.
- Communicator N16R8/Octal PSRAM ECC 설정, ESP·STM reset 분리, 물리 서비스 인터록과 역구동 차단 buffer, Controller 복구 버튼 회로를 반영했다.

- Communicator·Bridge·Controller adapter·원격 I²S mic의 KiCad10 상세 회로·PDF·netlist·BOM·local footprint와 교차 검증기를 추가했다.
- 차량/USB 전원 분리, brownout/watchdog 재무장 latch, 외장 GNSS·MTi7 DR·BMP384와 상세 FW 핀맵을 추가했다. 제작·차량 시험 gate는 미완료다.
- 센서 protocol 확장 schema, host codec·golden 시험, 구독 적용 응답·재시도·예산 설계와 T-100b를 추가했다.
- 제조사 원문 PDF·출처/개정/hash와 참조 절, 미확보 원문 및 footprint 검증 제한을 기록했다.
- kor-travel-geo 방식의 에이전트 운영 문서 구조를 추가했다.
- 상위 아키텍처, ADR, runbook, resume, journal 정본을 추가했다.
- 열린 task 요약을 docs/tasks.md로 분리하고 상세 task 파일은 docs/tasks/에 유지했다.
- Windows 개발환경과 일회성 worktree 운영 결정을 ADR-003으로 추가했다.
- 중앙 문서 지도와 architecture·hardware·development·vehicle·UI 하위 구조를 추가했다.
- 실행별 적대적 리뷰 archive와 전문 리뷰어 서브에이전트 2인 독립 review gate를 추가했다.
- 계층형 문서 정보구조와 누적 리뷰 정책을 ADR-004로 기록했다.
- 최신 Windows 임베디드 toolchain manifest와 SDK 준비 스크립트를 추가했다.
- Controller와 Communicator ESP32의 독립 ESP-IDF bootstrap, public protocol component, module별 partition 설정을 추가했다.
- STM32 CMake preset을 최신 CMake/Ninja/Arm GNU baseline과 compiler version 검증에 맞췄다.

### Changed

- 현대 5W 청색 UI의 큰 4WD·순간연비·작은 원형계기·FFT/차속/RPM·날짜 설정·터치 투과 경고를 다듬고 개별 미수신/정차 잠금/로컬 초안을 구분했다.
- CAN 밝기 stale 시 반복 감광, 음량 미확인 명령 중복, SPORT 오래된 feedback·외부 mode 변경·시간 점프 처리를 보강했다. 실제 transport/차량 연결은 후속 gate다.
- 기존 docs/tasks/README.md는 상세 task directory 안내 포인터로 변경했다.
- root README의 task 링크를 docs/tasks.md로 통일했다.
- AGENTS.md는 필수 정책과 단계별 문서 선택만 남기고 상세 절차를 runbook으로 분리했다.
- protocol과 시스템 설계 문서는 docs/architecture/ 아래로, 나머지 상세 문서는 분야별 하위 디렉터리로 이동했다.
- ESP32 baseline을 ESP-IDF `v6.0.3`으로, STM32CubeG4를 `v1.6.3`으로 갱신했다. 실제 BSP와 통신 기능은 후속 task에서 검증한다.

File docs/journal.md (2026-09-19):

# CANView 작업 일지

## 2026-09-19 (codex, MCUboot 전체 링크와 libc 실패 경로)

전체 `boot_go` 링크 probe에서 newlib assert가 stdio/미구현 syscall을 끌어와
fatal warning으로 실패했다. `bootloader/fail_stop.c`에서 두 실패 ABI만 기존
FIH panic으로 연결했다. assert 조건과 MEDIUM 보호는 유지하고 새 오류 framework나
성공을 반환하는 syscall 대역을 추가하지 않았다. Host 모형 libc는 변경하지 않는다.

명시적 trust가 있는 기존 Arm 비배포 SRAM 시험에 bootutil/crypto/identity를 링크하고
symbol/실제 panic 분기/heap·출력 부재를 검사한다. wrapper 누락의 실제 링크 실패와
검사기 입력 변이도 시험한다. 상세 전제는 [포트 설명](../firmware/communicator/stm32/bootloader/README.md#boot-sram-배치와-sdk-초기화-복사)에 둔다.
최종 boot entry·정책 승인·runtime 실행 근거는 아니며 T-107은 IN_PROGRESS다.
Physical/HIL은 NOT_RUN, 차량 TX는 NO-GO다. 기본 dirty checkout과 SDK/evidence는 보존했다.

`build/t107-failstop-final-arm-{debug,release}.log`의 실제 Arm 링크는37184/29116B,
SRAM copy1076/852B이며 compiler/linker/CMake warning0이다. Host 새 실패 경로와
runtime/handoff3/3, GNU strict C99, Clang ASan/UBSan, fail-stop C의 function2/2·
region4/4·line10/10 coverage100%를 확인했다(조건 분기는0개, FIH assembly coverage 아님).
최초 WSL 명령의 include 인자 전달 실패는 원 로그에 보존했고 명시 인자 재실행은
`build/t107-failstop-sanitize-coverage-retry.log`에 있다. Doxygen/Sphinx strict API74개,
문서409/1514·task49 errors0, 합성 T-103 fixture13/13도 통과했다.
전체 host Debug/Release 회귀·독립 리뷰·새 CI는 후속 검증으로 남긴다.

## 2026-09-19 (codex, 승인 뒤 primary handoff primitive)

기존 ECC read/runtime과 BSP 주소 계약으로 고정 primary의 MSP/Thumb reset PC를
검사하는 C99 진입부를 추가했다. 첫32bit fetch까지 authenticated payload 안인지
확인하며, 잘못된 길이/read/runtime/MPU/lazy FPU는 cleanup 전에 거절한다. SysTick/
NVIC cleanup 뒤16B naked trampoline으로 MSP를 바꾼다. 새로운 OTA format이나
approval bool은 만들지 않았다. 소유권·전제는 [포트 설명](../firmware/communicator/stm32/bootloader/README.md#승인-뒤-primary-진입)에 둔다.

`build/t107-handoff-final-arm-{debug,release}.log`의 실제 Arm 비배포 link 시험은
ELF/MAP/BIN5284/3924B, SRAM copy1048/824B, warning0이다. 최초 명령열128bit
개별 변조·truncation과 기존 startup/linker negative를 통과했다. 앱 primary binary는
51768/39776B다. link 시험은 길이0 거절만 호출하며 실제 boot_go/정책을 우회하지 않는다.
최종 loader나 physical handoff 성공을 주장하지 않는다.

Linux GCC strict C99와 Clang ASan/UBSan, handoff C의 function/region/line/branch100%
(`build/t107-handoff-sanitize-coverage.log`), Doxygen/Sphinx strict API74개를 확인했다.
coverage는 host 대역 호출 경로이며 실제 assembly/interrupt timing은 포함하지 않는다.
Windows 전체 host 회귀와 독립 리뷰 결과는 후속 closure에 남긴다. physical/HIL은
NOT_RUN, 차량 TX는 NO-GO다. default dirty checkout·SDK·기존 evidence를 보존했다.

이전 runtime c0f1b81의 CI35441935530 전체 success를 확인했다. 내려받은
`build/t107-handoff-base-ci-35441935530`의33개 artifact 크기/SHA256,15개 source의
LF/CRLF hash,34개 target log warning/error0을 대조했다. 새 handoff 기준선 CI와는
구분하며 CI manifest에 boot runtime/handoff source provenance를 추가했다.

## 2026-09-19 (codex, boot bounded progress와 IWDG)

T-107의 HSI16/DWT/IWDG runtime을 C99로 구현했다. 기존 BSP safe output과 SDK startup을
재사용하고 앱 PLL/RTOS/새 timer 계층은 넣지 않았다. nominal30초 boot budget·100ms
최소 feed 간격, context/config 검사와 fault latch의 전제는 [포트 설명](../firmware/communicator/stm32/bootloader/README.md#boot-시간원과-watchdog--최종-loader-연결-전)에 둔다.
초기 초안의 WINR 쓰기를 없애 공식 SDK의 PR/RLR→SR 대기→reload 순서로 맞췄다.
Window가 reset값이 아니면 거절한다. API 문서와 실제 코드의 소유권을 함께 갱신했다.

새 register 시험은 lifecycle/partial init/멈춘 시간/단일 wrap/역행/deadline/context/
설정 변이와 feed 제한을 검사했다. Windows Clang Debug와 Linux GCC가 통과했고,
Clang ASan/UBSan·coverage는 line95.65%, branch98.75%, function100%다.
ready 직후 deadline이 넘어가는 두 번째 방어 검사 한 분기는 host 미재현이다.
`build/t107-runtime-sanitize-coverage.log`에 수치를 보존했다. 실제 IWDG reset이나
debug freeze·LSI 편차·실기 swap 총 시간은 검증하지 않았다.

`build/t107-runtime-final-primary-{debug,release}.log`에서 실제 Arm SRAM link 시험
ELF/MAP/BIN4956/3660B, copy1048/824B, compiler/linker/CMake warning0을 확인했다.
제품 runtime은 실제 SDK와 링크하지만 boot_go/정책/handoff가 없는 비배포 시험이다.
`build/t107-runtime-docs.log`의 Doxygen/Sphinx strict·public API73개, board drift0,
문서401/1498·task49 errors0도 확인했다. 전체 host D/R 회귀와 새 독립 리뷰는 진행 중이다.

이전 기준선 ce3fe1f의 CI35440849349는 success/completed다. 내려받은 target artifact
33개 size/SHA256, 해당 Git source15개 LF/CRLF 정규화 hash, target logs34개 warning/error0을
별도 대조했다. `build/t107-runtime-base-ci-35440849349`가 증거 위치다. 새 후보 CI 결과로
대체하지 않는다. Physical/HIL·Flash·option-byte·production provisioning은 NOT_RUN,
차량 TX는 NO-GO이며 T-107은 IN_PROGRESS다. 사용자 checkout/SDK는 변경하지 않았다.

## 2026-09-19 (codex, boot SRAM linker와 SDK 복사 연결)

T-107의 code/read SRAM section을 boot64KiB linker에 배치하고 기존 Cube Reset_Handler
word-copy를 재사용했다. 별도 복사 알고리즘 없이 preinit DSB/ISB만 C로 추가했다.
비배포 `canview-boot-ram-link-test`의 실제 Arm Debug3956B/Release2804B ELF/MAP/BIN,
copy1048/824B와 primary 앱51768/39776B를 확인했다. 최종 loader는 아직 아니며
부팅 정책·watchdog·handoff·전체 call-chain stack·실기 Flash/HIL은 미완료다.

`build/t107-sram-primary-{debug,release}.log`에서 warning0과 실제 SRAM 함수/branch,
ELF/BIN copy span, SDK copy/bss/preinit·VTOR 명령 및 negative linker 시험을 확인했다.
추가592 startup/VTOR bit 변이와 preinit32bit, 주소/크기/누락 거절을 실행했다.
primary map 기존 unit6개도 통과했다. host 전체 회귀와 독립 리뷰는 이어서 수행한다.

첫 시도는 신규 object 전에 앱 stack 검사가 실행되는 의존성 누락으로 실패했다.
다음 link에서 기존 syscall 구현 누락과 NOLOAD stack segment 배치 문제를 발견해
기존 syscall을 재사용하고 stack을 load segment에서 제외했다. 경고 억제는 없다.
초기 bit 시험은 동일 값을 담은 다른 SDK literal 선택 두 건을 허용했다. 고정 SDK
literal pool 순서까지 대조하도록 보강한 뒤 모두 거절했다. 실패 로그도 보존했다.
SDK SystemInit의 primary VTOR macro를 source-global에서 target-local로 옮겼고,
boot의 실제 VTOR 명령도 검사한다. 사용자 checkout·SDK 원본은 변경하지 않았다.

## 2026-09-19 (codex, BSP trust 리뷰 경로 결함 수정)

`6c14950`을 commit/push하고 독립 A/B 원본을 [중간 리뷰](reviews/adversarial/2026-09-19-T-107-trust.md)에
보존했다. A PASS/B CONDITIONAL, B-BOOT-TRUST-01 P2는 fresh configure 상대 DER
입력의 자동 절대경로 변환이다. 유효 파일을 준비한 회귀로 Windows/WSL에서 실제
기대 거절 실패를 재현한 뒤 STRING cache로 수정했다. 첫 직접 PowerShell 명령은
인수 분리 오류로 실패했으므로 증거로 사용하지 않고 Python argv 경로로 재현했다.
Windows 전체 trust1/1·GNU4개+통합·fixture13개를 다시 통과했고 원 reviewer 재확인 대기다.

추가로 Doxygen1.18/Sphinx strict와71 API 계약 통과(`build/t107-trust-docs.log`),
Debug key-only 재생성 회귀1/1(`build/t107-trust-key-only-retest.log`)를 확인했다.
이전 CI35437256268/35437911211은 각각 전체 성공이며 target artifact27개 byte/hash,
source11개와 target log34개 warning/error0을 감사했다. source 첫 raw hash 대조는
로컬 LF/CI CRLF 차이로 실패해 동일 git blob의 LF/CRLF 해시를 대조했고 전부 CI CRLF와
일치했다. binary는 줄바꿈 변환 없이 byte-exact 비교했다. 로컬 evidence는
`build/t107-trust-base-ci-35437256268`, `build/t107-io-ci-35437911211`이다.
현재 candidate의 CI나 새 identity의 Arm CI를 이 이전 성공으로 대체하지 않는다.

최종 boot 연결·물리 gate는 그대로 미완료다. PR37 Draft/T-107 IN_PROGRESS,
HIL/provisioning NOT_RUN, 차량 TX NO-GO를 유지한다.

## 2026-09-19 (codex, T-107 명시적 BSP identity·공개키)

기존 MCUboot 공개키 ABI와 identity 계약에 const BSP 공급자를 추가했다. 표준91B
P-256 공개 SPKI DER와 명시적 제조 epoch/manifest root ID/STM ABI만 build 입력으로
받으며 새 container·키 형식·범용 framework는 만들지 않았다. OTA 전체 board ID와
하위 STM32 pin profile ID는 구별한다. 설정과 제한은 [포트 설명](../firmware/communicator/stm32/bootloader/README.md#bsp-identity와-공개키-빌드-입력)에 둔다.

- 최초728bit 변이 시험에서 cryptography UnsupportedAlgorithm의 오류 변환 누락을
  발견했다. 입력 자체는 실패했지만 약속한 ValueError가 아니었다. 변환을 보강했고
  첫 실패 로그 `build/t107-trust-test.log`는 보존했다.
- Python4개 시험의 하위 경계/728bit 변이, 실제 C null·출력 불변·반복 복사,
  CMake 누락4/path3/DER/u32 오류·기존 build 입력 교체 검사가 통과했다.
  Windows `build/t107-trust-retest.log`, WSL GNU `build/t107-trust-gcc.log`.
- Host Debug/Release는 이번 관련157/157이 각각81.42/67.16초에 통과했다.
  `build/t107-trust-host-{debug,release}-{config,build,test}.log`.
  기존 장시간 MCUboot108시나리오/11240cut은 이번 실행에서 제외했으며 직전
  `06383d6` 실행 결과와 구별한다. 이번 변경은 해당 모형의 제품 IO를 바꾸지 않았다.
- 새 C 공급자 Clang ASan/UBSan, line/region/function/branch100%를 확인했다.
  `build/t107-trust-sanitize-coverage.log`. 메모리 전용 개인키에서 얻은 공개 DER만
  로컬 `build/t107-trust-test-public.der`로 보존했고 Git에 넣지 않았다.
- 실제 Arm primary-debug/release에서 identity archive compile와 기존 앱
  ELF/MAP/BIN51768/39776B를 확인했다. `build/t107-trust-primary-*-{config,build}.log`.
  위 Arm·sanitizer configure/build 로그의 compiler/linker/CMake warning/error0이다.
  이 archive는 부트로더 final binary가 아니다. 최종 link/WRP·실기 boot는 미완료다.
- source digest를 `d677a131843fb58f982f5abd88654a792827eeac04d13f5679748a548f3ef6f5`로
  재계산해 합성 capture fixture를 갱신했다. board drift0, 문서392/1482targets 오류0,
  task49 오류0이다. physical evidence로 바꾸지 않았다.

독립 리뷰·새 CI는 이어 수행한다. T-107/PR37은 IN_PROGRESS/Draft이며 SRAM linker/copy,
boot executable/handoff·watchdog 시간·T-205 floor 연결이 남았다. Production 입력 승인,
Flash/provisioning·HIL은 NOT_RUN, 차량 TX는 NO-GO다. 사용자 checkout·SDK는 보존했다.

## 2026-09-19 (codex, ECC finding closure와 제품 IO의 MCUboot 모형 통합)

`122924c`를 commit/push하고 원 A/B의 [post-fix 원본과 disposition](reviews/adversarial/2026-09-19-T-107-ecc-post.md)을
보존했다. 양쪽 source PASS, A-01 P1·B-01/B-02 P2는 FIXED다. 과거 원본 verdict는 바꾸지 않았다.
전체 task나 boot 실행 승인은 아니며 아래 후속 모형 변경은 해당 리뷰 candidate 밖이다.

기존 `mcuboot_model.c`의 별도 IO 구현을 없애고 제품 `flash_io.c`를 실제 boot_go에 link했다.
모형은 bounded read와 한8B program/한2KiB erase만 대체한다. FF skip·read-back은 제품 C를
그대로 실행한다. 기존 API 단위 cut 대신 작은 image의 모든 primitive 전후를 중단한다.
swap5610/revert5630, 합계11240 cut에서 이전 정상 image 복귀와 중복 program0을 확인했다.
명령 내부 torn word/page, 실제 ECC/NMI나 시간은 여전히 NOT_RUN이다.

- Windows Debug 통합시험1/1 319.41초, Release1/1 44.41초. 각각108 image/identity/IO 시나리오.
  Debug 결과는 실행 도구 stdout, Release는 `build/t107-io-model-release-test.log`에 남았다.
- 나머지156개를 별도 실행해 Debug156/156 29.11초, Release156/156 27.95초 성공.
  따라서 두 구성 모두 전체157개를 검증했으며 단일 CTest run이라고 주장하지 않는다.
  로그 `build/t107-io-model-{debug,release}-other-retest.log`.
- 최초 나머지 시험은 README를 포함하는 source hash 불일치로 python-unit이 실패했다.
  hash 산식을 완화하지 않고 합성 fixture/기대값을 재계산해 위 재시험했다.
  digest `220c06d99eeb4aa2b106787647513d9b161f24b24204e4fb5eaad771a846c1de`.
- WSL Clang21.1.8 ASan/UBSan Debug의 exhaustive cut은240초 timeout으로 실패했다.
  새 `/tmp/canview-t107-io-model-sanitize` RelWithDebInfo에서 sanitizer·FIH/assert를 유지하고
  같은108시나리오/11240cut을 다시 실행해1/1 234.02초 성공했다. timeout 실패를 성공으로
  바꾸지 않는다. `build/t107-io-model-sanitize.log`, `build/t107-io-model-sanitize-optimized.log`.
- GNU15.2 Release에서도 동일 통합1/1 44.32초 성공. 첫 기존 build에는 MCUboot root가
  없어 target 미존재로 실패했고, pinned SDK/Python을 명시한 재configure 뒤 실행했다.
  `build/t107-io-model-gcc.log`, `build/t107-io-model-gcc-retest.log`.
- 이번 delta는 시험 연결·문서이며 제품 C는122924c와 동일하다. 새 target binary나 새 coverage를
  생성했다고 주장하지 않는다. 제품 IO의 이전 unit coverage와 Arm 검증 근거는 직전 항목에 있다.
- PR37 body는 현재 scope/test/review/미완료 gate 중심으로 줄이고 상세 이력은 이 journal에 보존했다.
  `122924c` CI35437256268은 현재5/6 성공, target job 진행 중으로 아직 전체 성공이 아니다.

다음은 최종 SRAM linker/copy·trusted BSP identity/공개키·boot executable/handoff와 시간 정책이다.
T-107 IN_PROGRESS / PR37 Draft 유지. Physical/HIL NOT_RUN, 차량 TX NO-GO. 사용자 checkout·SDK와
이전 evidence를 보존했으며 실제 Flash/option-byte/provisioning 변경은 하지 않았다.

## 2026-09-19 (codex, T-107 ECC 리뷰 수정과 Flash IO primitive 연결)

481a805의 독립 A/B 원문과 전달 manifest를 [중간 리뷰](reviews/adversarial/2026-09-19-T-107-ecc.md)에
보존했다. A-01 P1은 post-load RDERR를 성공으로 전달하는 결함이며 회귀시험의 반환값
assertion 실패로 재현했다. 매 load 뒤 SR을 검사하고 오류·출력 불변을 보존하도록 수정했다.
예상 밖 BSY는 SRAM fail-stop이다. 최소1B·65 load 위치의 RDERR와 BSY를 추가 시험한다.
최초 모형 assertion의 Windows CRT abort는 timeout됐고 해당 test process만 종료했다.
오류 주입 자체를 허용하도록 모형을 고친 뒤 실제 반환값 반례를 재현했다.

B-01 P2는 조건부 간접 분기·blx lr를 거절하고 실제 Arm negative object로 회귀했다.
B-02 P2는 archive POST_BUILD 대신 의존하는 항상 실행 검사 target으로 수정했다.
소스 변경 없는 build와 script-only 변경 build 모두 기존 실제 object 검사를 재실행했다.
경고 억제나 별도 범용 stamp framework는 만들지 않았다. 원 A/B post-fix 확인 전에는
finding을 닫지 않는다. 최초 BLOCK/CONDITIONAL 원문도 수정하지 않는다.

병행한 다음 구현은 `flash_io.c`의 기존 MCUboot read/write/erase 세 함수다.
BSP 범위를 재검사하고 bounded read,8B program/FF skip,2KiB erase와 read-back을 연결했다.
실패에 자동 retry/erase를 하지 않고 이전 단위의 부분 변경 가능성을 API에 명시했다.
상위 swap/recovery·최종 boot 연결·watchdog 시간 정책은 여전히 별도다.

- Windows Host Debug157/157(126.61초), Release157/157(71.02초) 성공.
  `build/t107-io-post-host-*-{build,test}.log`.
- 실제 Arm primary Debug/Release clean ELF/MAP/BIN과 IO archive 생성 성공.
  BIN51768/39776B, read SRAM564/456B, compiler/linker/CMake warning/error0.
  63개 C object stack·103 CMSIS/model+2 DMAMUX 상수 대조. 앱 image는 이전과 같으며
  bootloader image로 표시하지 않는다. `build/t107-io-ecc-post-*-clean.log`.
- 실제 Arm negative object는 bx lr 정상, bxne/blxne r3·blx lr 거절을 확인한다.
  compiler/assembler stderr도 비어 있어야 한다. 무변경/검사 script 변경 재실행은
  `build/t107-ecc-recheck-no-source-change.log`, `build/t107-ecc-recheck-script-only.log`.
- ASan/UBSan read/IO2/2, GNU15.2 read/IO/validator3/3 성공. host 모형 coverage:
  read region284/function5/line117/branch72 모두100%; IO region95/function6/line68 모두100%,
  branch57/58(98.28%). IO에서 BSP가 성공했지만 다른 주소를 반환하는 불가능한 분기는
  별도 fault 주입하지 않았다. target MMIO/주소 검사와 실제 HIL coverage는 아니다.
  `build/t107-ecc-io-post-sanitize-coverage.log`.
- 481a805 CI35436057000 6/6 success. artifact27개 bytes/SHA256, source11개 commit blob의
  Windows CRLF checkout hash와 manifest source/run identity 일치. target log34개 warning/error0.
  `build/t107-ecc-ci-35436057000/`. 이 CI는 수정 전 candidate의 근거이며 P1 closure를 대신하지 않는다.
- 합성 fixture source digest는 `d526c819b6088ea80bbaaca8e8b372ab36fc0f8f5521940086f09e55a93be578`.
  사용자 checkout·SDK·이전 evidence를 보존했으며 물리 장치/option-byte/키는 변경하지 않았다.

T-107/PR37은 IN_PROGRESS/Draft, 원 reviewer 재검토·새 CI가 남는다. boot executable,
SRAM 최종 linker/copy·trusted BSP identity·T-205와 physical ECC/reset/전원/HIL은 미완료다.
Physical/HIL은 NOT_RUN, 차량 TX는 NO-GO이며 이전 reviewer 면제를 적용하지 않는다.

## 2026-09-19 (codex, T-107 bounded ECC guarded read)

f3283fb에서 이어 기존 G474 platform에1..256B guarded read C를 추가했다.
오류가 없는 staging 결과만 출력에 복사하며 ECCC/ECCD는 실패로 반환한다.
임시 NMI는 현재 read 실패/flag clear만 담당하고 erase/복구 정책을 수행하지 않는다.
다른 예외, 동시 clock/parity fault, clear 실패·NMI 전달 timeout은 SRAM reset/fail-stop이다.
API 소유권·SRAM/stack/RTOS 제한은 기존 bootloader README에 통합했다.

- 전체 슬롯98816word, alignment4×length256, per-load ECC195, NMI 지연31,
  read 전후 비활성 NMI2, fatal14경로와 RDP256값·출력/보호 register 불변을 시험했다.
- Windows Clang23.1 Host Debug156/156(93.40초), Release156/156(75.27초) 성공.
  최종 test helper 변경 뒤 read/validator2/2도 두 구성에서 재실행했다.
  로그: `build/t107-ecc-host-*-build-verified.log`, `build/t107-ecc-host-*-test-verified.log`.
- Board drift0, 문서386개/링크1469개·task49개 오류0. 기본 사용자 checkout과 SDK,
  기존 build/evidence는 보존했다.
- 실제 Arm bench/primary Debug/Release clean ELF/MAP/BIN 생성 후 최종 register 모형
  대조도 재실행했다. BIN51760/39768/51768/39776B, compiler/linker/CMake warning/error0.
  read SRAM object528/436B, 외부 relocation0. 최대 개별 stack1352/1320B는 전체
  boot call-chain budget이 아니다. 실제 CMSIS/model103개+DMAMUX2개를 대조했다.
  로그: `build/t107-ecc-arm-*-final.log`, `build/t107-ecc-arm-*-verified.log`.
- 공식 imgtool actual/최대 payload 서명·변조 거절 성공. signed52607/40616B,
  최대184135/184134B, trailer2376B/reserve4096B. `build/t107-ecc-primary-*-imgtool.log`.
- Clang21.1.8 ASan/UBSan MCUboot/command/read3/3(53.14초), 최종 test helper 변경 뒤
  read1/1 재성공. 새 read C의 host 모형 coverage는 region272/function5/line114/branch68
  모두100%다. 실제 MMIO·AIRCR reset·SRAM 주소 검사는 이 수치에 포함하지 않는다.
  로그: `build/t107-ecc-sanitize-coverage-final.log`,
  `build/t107-ecc-gcc-sanitize-coverage-verified.log`.
- GNU15.2 Release guard/read/validator3/3 성공. SRAM 검사기는 기존 command 검사를
  재사용하며 read 세 함수와 cbz/cbnz 영역 밖 변이도 거절한다.
- 첫 Clang compile의 미초기화 context 주소 인자 진단은 uintptr 주소 전달로 수정했다.
  첫 Arm compile의 RM/CMSIS enable 이름 차이는 실제 `FLASH_ECCR_ECCIE`로 수정했다.
  register 모형 확장으로 Windows aggregate snapshot이 `__atomic_load`를 요구한 것은
  테스트용 byte snapshot으로 고쳤다. GCC longjmp loop 진단은 setjmp를 별도 test helper로
  분리해 해결했다. 경고 억제·추가 atomic library·SDK 원본 변경은 하지 않았다.
- 중간 전체 host 실행 중 barrier fault 시험을 추가해 합성 source identity가 바뀌었다.
  그 실행의 python-unit 실패는 성공으로 쓰지 않고, digest를 갱신해 고정 source에서
  전체 host를 재실행했다. 최종 fixture digest는
  `c83d2035a06e14f5bacf71cac85647f8586a286cbba74813acce7128ff933270`이다.

기존 f3283fb CI35434965672는6/6 success/completed를 확인했다. 새 candidate CI와
최종 artifact/hash 감사·독립2인 T-107 review를 대신하지 않는다. Flash IO backend,
최종 SRAM linker/copy, trusted BSP identity, boot executable/handoff, T-205 정책은
미완료다. Physical ECC/NMI latency·전원/reset/HIL/provisioning은 NOT_RUN이며 차량
TX는 NO-GO, PR37/T-107은 Draft/IN_PROGRESS를 유지한다.

## 2026-09-19 (codex, T-107 startup parity 누락 수정)

ecbce7d의 후속 source 검토에서 P1 수준의 전제 누락을 발견했다. 고정 CubeG4
`stm32g4xx_hal_flash.h:408`의 SRAM parity 대상은 CCM뿐 아니라 SRAM1 첫32KiB다.
ES0430 Rev9 §2.2.7은 parity 활성 영역에서 dummy initialization을 요구한다.
이전 read-only wrapper는 미초기화 parity에 의한 NMI를 고려하지 않았으므로
직전 항목의 BIN/모형 성공을 parity 활성 startup 수용 근거로 사용하지 않는다.
독립 reviewer finding은 아니며, 독립2인 task review를 대체하지 않는다.

전용4B NOLOAD dummy를 SRAM1 시작에 예약했다.44B naked wrapper가 그 word에
zero write/DSB를 두 번 실행한다. 첫 write 소실을 허용하고 두 번째로 초기화하며,
앱 data는0x20000004부터 배치한다. 나머지 세 cut은 기존 read를 사용한다.
SDK 원본과 option byte는 변경하지 않는다. 새 gate는 dummy/data 주소와 실제 BIN
명령열까지 확인하며 linker도 dummy 주소/크기를 ASSERT한다.

- 단위12개 성공. 실제 opcode 접근 모형에서 parity on/off와 네 cut의 첫 write
  손실32조합 성공. 이전 read-only 명령열은 parity 활성 오류로 재현된다.
  512개 bit 변이·두 base의 잘림772개·symbol/CCM 오류 거절도 유지했다.
- Windows Clang23.1 Host Debug155/155(85.59초), Release155/155(67.71초) 성공.
  host build warning/error0. `build/t107-parity-host-{debug,release}-{build,test}.log`.
- 실제 Arm bench Debug/Release·primary Debug/Release clean build의 ELF/MAP/BIN 성공.
  BIN은51760/39768/51768/39776B, wrapper44B/dummy4B/CCM0B이며 compiler/linker/CMake
  warning/error0이다. `build/t107-parity-arm-{debug,release,primary-debug,primary-release}.log`.
- 공식 imgtool 실제/최대 payload 서명·변조 검증 성공. 실제 signed52607/40614B,
  최대184136/184134B, trailer2376B/reserve4096B다.
  로그: `build/t107-parity-primary-{debug,release}-imgtool.log`.
- Board drift0, 문서386개/링크1467개와 task49개 오류0. 합성 fixture source digest는
  `dfd9478aa1290553b0bb0766cb8217ddc4f1b6e6e8d30bc9a038acbf01449bc1`이다.

이 변경은 target-only startup이므로 host sanitizer/coverage 수치로 실행을 주장하지
않는다.32조합은 SRAM 접근 모형이며 실제 cold/warm reset·parity/전원 fault/HIL은
NOT_RUN이다. T-107/PR37은 IN_PROGRESS/Draft, ECC-safe read·Flash backend·boot executable과
독립2인 task review·최종 CI/artifact 감사는 미완료다. 차량 TX는 NO-GO다.

## 2026-09-19 (codex, T-107 SRAM reset startup 전제)

4839f38/PR37 Draft에서 이어 진행했다. ECC 검토 중 ES0430 Rev9 §2.2.7과 고정
CubeG4 startup의 첫 SystemInit 호출을 대조해, SRAM 첫 write 이전 dummy read가
없음을 확인했다. SDK를 복사/수정하지 않고 linker wrap과32B naked 진입부로 보완했다.
스택을 쓰는 C prologue보다 앞서 실행해야 하는 이 부분만 최소 assembly다.
§2.2.3에 따른 ECCR 단독 주소 기반 자동 erase 금지도 포트 설명에 기록했다.

- 실제 bench Debug/Release와 primary Debug/Release ELF/MAP/BIN 생성 성공.
  BIN 크기는 각각51748/39752/51756/39760B이며 CCM section0B다. 새 gate는 실제
  vector/MSP/reset 명령/read4회/tail branch를 대조한다. Primary Debug는 clean build도
  재실행했다. 로그: `build/t107-startup-arm-{debug,release,primary-debug,primary-release}.log`.
- gate 단위11개 성공. 새 startup 시험은416개 단일 bit 변이, 두 image base의
  잘림748개, symbol 누락/중복/주소·CCM 사용을 거절한다. 이는 물리 SRAM fault 주입이 아니다.
- 공식 imgtool로 primary 실제/최대 payload를 다시 서명·검증했다. 실제 signed 크기
  52594/40599B, 최대184134/184135B로180KiB 안이며 trailer2376B/reserve4096B다.
  로그: `build/t107-startup-primary-{debug,release}-imgtool.log`. 임시 개인키는 보관하지 않는다.
- Windows Clang23.1 Host Debug155/155(69.93초), Release155/155(68.68초) 성공.
  로그: `build/t107-startup-host-{debug,release}-{build,test}.log`.
- WSL ASan/UBSan MCUboot/Flash command 회귀2/2(31.74초) 성공.
  로그: `build/t107-startup-sanitize.log`. Target-only startup assembly는 host sanitizer와
  C coverage 대상이 아니며 실제 Arm BIN 대조로 검증한다.
- Arm4개·host2개·sanitizer build log의 compiler/linker/CMake warning/error0.
  board drift0, 문서386개/링크1467개와 task49개 오류0. 합성 fixture digest는
  `e4ed1868ba2f85f2b2a054e5352e9a432dfd59bf37c691edf35654921237aa89`다.
- 보조 조회에서 PowerShell에 shell brace 구문을 잘못 사용한 parse 오류와 imgtool
  검사 스크립트 경로 오기가 있었다. 파일 변경 없이 수정해 실제 `tests/ota/` 경로로
  위 검증을 실행했다. SDK 원본은 clean이며 이전 evidence/사용자 checkout은 보존했다.

4839f38 CI35433675129는 확인 시 in_progress였으며 성공으로 표시하지 않는다.
T-107은 IN_PROGRESS/PR Draft다. 다음은 ECC-safe read/Flash backend·최종 SRAM
배치/복사와 boot executable이다. 신규 독립2인 리뷰·최종 CI/artifact 감사는 아직이며
physical reset/ECC/Flash/HIL/provisioning은 NOT_RUN, 차량 TX는 NO-GO다.

## 2026-09-19 (codex, T-107 SRAM 단일 Flash 명령)

9bc5bd0/PR37 Draft와 clean worktree에서 이어 구현했다. 이전 guard 구현은 실제
진척이며 CI35432704415도 success/completed를 확인했다. 새 candidate의 CI·최종
artifact 감사나 독립2인 리뷰가 완료됐다는 뜻은 아니다.

- 기존 platform 경계에 단일 page erase/8B program C를 추가했다. 고정 guard,
  RDP0/lock·status 검사, 슬롯 범위·정렬·enum/all-FF/duplicate 거절, cache/lock/
  PRIMASK/VTOR 복원을 구현한다. option-byte 변경이나 watchdog feed/disable은 없다.
- 고정 HAL의 program/erase/cache 순서를 사용하되 tick 의존 busy 대기는 SRAM
  DWT/유한 poll로 대체했다. NMI/HardFault와 busy timeout은 SRAM reset/fail-stop이다.
  실제 ECC-safe read·persistent ECC recovery·상위 Flash backend는 미연결이다.
  임시 vector/실행 전제와 reset loop 위험은 bootloader README에 명시했다.
- Windows Clang23.1 Host Debug155/155(70.74초), Release155/155(55.10초) 성공.
  로그: `build/t107-command-host-{debug,release}-{build,test}.log`.
- WSL Clang21.1.8 ASan/UBSan2/2(13.84초), 새 C의 host 모형 coverage 실행1/1(3.53초).
  region309/309, function4/4, line119/119, branch66/66=100%. target 전용 register
  쓰기와 SRAM 주소 검사는 이 coverage에 포함되지 않는다.
  로그: `build/t107-command-sanitize-coverage-final.log`.
- 실제 Arm primary Debug/Release 앱 ELF/MAP/BIN 및 새 명령 archive 생성 성공.
  object busy section은480B/364B, 두 내부 함수·literal, 외부 relocation0이며 자동
  post-build 검사와10개 거절 mutation을 추가했다. 상수96개+DMAMUX2개는 SDK 대조
  성공이다. 앱 BIN은51724B/39728B다. 최종 boot SRAM map/복사와 부트로더 BIN은 아직 없다.
  로그: `build/t107-command-arm-primary-{debug,release}.log`.
- 네 host/Arm build log의 compiler/linker/CMake warning/error scan0, board drift0,
  문서386개/링크1466개 오류0, task49개 오류0. source digest
  `cbfbc07fb98a615ed3953df599892bebc527381949763ad56cd32faaf341ad19`를 합성 fixture에
  반영했으며 실제 HIL로 승격하지 않았다.

다음은 ECC-safe read/Flash backend·SRAM linker/startup 연결과 boot executable이다.
RDP 생산 정책/T-507, physical Flash/ECC·stall·watchdog·전원 fault/HIL은 NOT_RUN,
차량 TX는 NO-GO다. T-107 AC와 리뷰·최종 CI/artifact gate는 열려 있고 merge하지 않았다.

## 2026-09-19 (codex, T-107 G474 읽기 전용 Flash 보호 guard)

eaa5751 다음 단위다. 시작 시 해당 HEAD/remote와 clean 상태, CI35432132535의
in_progress를 확인했다. 이전 turn은 실제 C 구현·commit/push가 있는 진행으로 분류한다.
드라이버/architecture/cstyle/documentation 기준에 따라 MCU register 접근은 기존
platform 경계에 두고 공용 MCUboot adapter는 필수 preflight 함수만 호출한다.

- `flash_guard.c`는512KiB·DBANK1·BFB2off·bank remap 없음·양방향 NRST,
  WRP1A page0..31과 나머지 WRP 비활성, SYSCFG clock·busy/option 오류를 확인한다.
  매 write/erase 전달 전에 실제 값을 새로 읽고 실패하면 backend IO를 호출하지 않는다.
  option-byte/Flash 상태 register에 쓰지 않는다. 생산용 RDP/PCROP·복구 조합 승인과
  샘플 qualification은 T-507에 남아 있으며 guard 성공을 그 승인으로 해석하지 않는다.
- Host 모형에도 실제 guard source를 link했다. 정상 boot_go108개 image/identity/IO
  시나리오와 swap/revert258개 API 중단 경로를 유지한다. Guard 단위시험은 옵션16개,
  크기65536개, WRP65536개 조합과 register 불변을 확인한다.
- WSL Clang21.1.8 ASan/UBSan2/2(18.59초), coverage2/2(7.00초) 성공.
  guard 자체의 region95/95·function2/2·line32/32·branch20/20은100%다.
  전체 firmware나 물리 Flash coverage 주장이 아니다. 로그는
  `build/t107-guard-sanitize-coverage.log`다.
- 실제 Arm primary-debug/primary-release clean build에서 기존 앱 ELF/MAP/BIN과
  새 guard archive를 생성했다. compiler/linker/CMake warning0, CMSIS/model 상수73개
  (신규19개 포함)와 기존 DMAMUX2개 대조 성공. 로그는
  `build/t107-guard-arm-primary-{debug,release}.log`다. Bootloader 최종 binary는 아직 없다.
- Windows Clang23.1 전체 Host Debug153/153(70.00초), Release153/153(53.83초) 성공.
  `build/t107-guard-host-{debug,release}-{build,test}.log`를 보존한다. 두 host build 로그도
  compiler/linker/CMake warning0이다. 새 guard는 SDK 없는 host matrix에도 포함된다.
- board generation, 문서386개/로컬 링크1464개, task49개 정합 검사 성공.
  합성 capture fixture의 source digest만 갱신했으며 실제 HIL로 승격하지 않았다.

다음은 실제 Flash program/erase·ECC/NMI·SRAM critical path와 bootloader executable다.
현재 guard는 이 실행부를 대체하지 않는다. T-107 AC·독립2인 리뷰·최종 CI/artifact
감사는 열어 두며 PR37은 Draft다. Physical/HIL/Flash/provisioning은 NOT_RUN,
차량 TX는 NO-GO, Diagnostic Bridge는 read-only다.

## 2026-09-19 (codex, T-107 MCUboot protected metadata hook)

430d73a 뒤의 작은 C 구현 단위다. Embedded architecture/cstyle/documentation 기준에
따라 기존 T-007 metadata parser와 MCUboot hook/loader 상태 API를 재사용했다.
새 암호 구현·swap 엔진·범용 framework는 추가하지 않았다.

- `image_hooks.c`는 고정 header/protected TLV/일반 TLV 구조와180KiB 경계를 검사한다.
  신뢰된 identity 공급 계약의 board/role/layout/제조 epoch/ABI와 대조한 뒤에도
  FIH_BOOT_HOOK_REGULAR를 반환해 native hash/P-256 검증을 이어간다.
  실제 BSP 공급자는 미구현이며 합성 identity는 host model 안에만 있다.
- 시험 중 일반 TLV info length만 변조한 image가 upstream 서명 검증을 통과했다.
  고정 T-007 profile과 같은 SHA256/keyhash/ECDSA 순서·길이 대조로 이를 거절했다.
  최초 hook 연결에서는 offset copy 후처리 symbol 누락으로 link가 실패했고,
  upstream 기본값0의 no-op hook을 연결했다. 경고/검증기를 억제하지 않았다.
- 공식 imgtool의 임시 메모리 키를 사용한108개 image/identity/IO 시나리오와
  swap120/revert138 API 경계 중단을 실제 C boot_go로 실행했다.
  정상 키로 재서명한 잘못된 metadata, 잘린 TLV, 길이 합 overflow/초과,
  identity 공급 실패와 각 read 실패를 포함한다. 실제 torn word/page 시험은 아니다.
- WSL Clang21.1.8 ASan/UBSan23.85초 PASS. 새 profile의 hook coverage는
  line113/113·function8/8=100%, region155/158=98.10%, branch75/82=91.46%다.
  미실행 방어 분기에는 불변 슬롯 open 실패와 upstream 상태 offset 손상 및 FIH
  macro 경로가 포함된다. 전체 firmware coverage100%로 표시하지 않는다.
  로그는 `build/t107-identity-sanitize-final.log`, `build/t107-identity-coverage-final.log`다.
- 실제 Arm primary Debug/Release clean build에서 기존 앱 ELF/MAP/BIN과 변경된
  bootutil archive를 생성했다. 앱 크기51724/39728B, vector0x08010200 검사 성공.
  로그 `build/t107-identity-arm-primary-{debug,release}-final.log`를 보존한다.
- Windows Clang23.1 전체 Host Debug152/15286.73초, Release152/15258.55초 성공.
  `build/t107-identity-host-{debug,release}-{build,test}.log`를 보존한다.
  두 host build와 두 Arm clean build 로그의 compiler/linker/CMake warning/error는0이다.
- board generation, 문서386개/로컬 링크1463개, task49개 정합 검사 성공.
  합성 capture fixture source digest만 갱신했으며 physical evidence로 승격하지 않았다.

아직 T-107 IN_PROGRESS다. 실제 G474 Flash/profile/ECC/SRAM/watchdog와 bootloader
실행 파일, BSP identity 공급, T-205 floor/activation/confirmation 연결 및 독립2인
리뷰·최종 CI/artifact 감사가 남았다. Physical/HIL·provisioning은 NOT_RUN,
차량 TX는 NO-GO이며 PR37은 Draft를 유지한다.

## 2026-09-19 (codex, T-107 MCUboot C boot_go·swap/revert 첫 연결)

a2f1f9c 다음 단위다. 해당 commit CI35429702531 success/completed를 확인했다.
새 source 단위는 [포트 설명](../firmware/communicator/stm32/bootloader/README.md)의
얇은 C Flash adapter·공식 bootutil/TinyCrypt/ASN1 연결과 host 모형이다. 드라이버 설계
기준에 따라 BSP map을 재사용하고 실제 register/HAL IO를 portable 영역에 넣지 않았다.
SDK 원본 pin6d3b3d2/clean 유지, 개인키는 공식 imgtool 시험의 메모리 전용이다.

- `stm32-mcuboot-model`은30개 image 시나리오와 swap120/revert138 API 경계 중단을
  실행했다. 정상·최대 크기·truncated/header/TLV/서명 변조·미신뢰 key·confirm 및
  이전 정상본 복귀를 확인했다. Flash 모형은 FF doubleword도 중복 program을 거절한다.
- Windows Clang23.1 Debug/Release에서 실행. Arm15.3.Rel1/CubeG4 v1.6.3의
  primary-debug/primary-release clean build도 기존 앱 ELF/MAP/BIN과 새 library를 생성했다.
  로그 `build/t107-mcuboot-arm-primary-{debug,release}-clean.log`, compiler/linker/CMake warning0.
  Boot library는 아직 앱에 link하지 않으며 final bootloader ELF/BIN은 없다.
- 전체 Host Debug152/15269.96초, Release152/15249.33초 성공.
  `build/t107-mcuboot-host-{debug,release}-{build,test}.log`를 보존했다.
  board generation·문서386개/로컬 링크1461개·task49개 정합 검사도 성공했다.
- Arm 첫 빌드는 FIH 반환형 top-level volatile 경고로 실패했고 Release에서는
  TinyCrypt t5 초기화 경고도 발견했다. 경고 억제/보호 profile 하향 없이 build 사본에서
  반환35+4곳 및 임시 배열3개만 변환했다. Python이64개 source 파일과 원본을 대조하고,
  C `_Generic` assertion이 FIH 전역/지역/멤버의 volatile과 반환 layout을 검사한다.
  Host는 Arm panic loop만 abort로 대체하며 double-variable/CFI를 유지한다.
- Clang21.1.8 ASan/UBSan18.70초 PASS. 별도 coverage 실행6.03초,
  `flash_map.c` region117/function15/line101/branch66 모두100%.
  로그 `build/t107-mcuboot-sanitizer-coverage-final.log`.
- WSL 보조 환경은 `/tmp/canview-t107-mcuboot-sdk-native`의 같은 pin clean clone,
  `/tmp/canview-t107-model-clean`의 Python3.14.4·cryptography48.0.0/cffi2.1.1/
  pycparser3.0/cbor2 6.1.4/intelhex2.3.0/click8.5.0이며 pip check 성공.
  최초 Python 선택에서 click이 없었고 system-site venv는 무관한 dependency 충돌을
  보여 별도 clean venv로 재실행했다. Windows wheel lock 검증과는 별도 보조 결과다.
- 처음 WSL shell 변수 전달/Arm 로그 상대 경로 오류는 검증 PASS가 아니며,
  명시적인 경로로 재실행했다. 사용자 checkout·SDK·기존 evidence는 변경/삭제하지 않았다.
- CI Windows host에 MCUboot root를 명시하고 target primary 두 구성에 같은 root를
  연결했다. 새 CI·artifact 감사·독립 task 리뷰2건은 후속 gate다. T-107 AC는 열려 있다.
- board/role/ABI TLV·profile·실제 Flash/ECC/NMI/stall/watchdog·boot handoff·
  T-205 confirmation/floor는 미완료. Physical/HIL·실제 option-byte/provisioning·
  torn word/page는 NOT_RUN, 차량 TX는 NO-GO다.

## 2026-09-19 (codex, T-107 실제 primary 앱 image 연결)

179ab64 다음 단위로 primary-debug/primary-release preset과 primary linker를 추가했다.
기존 bench section/RAM/stack 내용은 application-sections.ld로 추출해 공유하며,
primary vector0x08010200/payload179KiB를 고정한다. SDK SystemInit 공식 macro로 VTOR를
설정한다. ISR 설계 기준에 따라 SDK startup 순서와 실제 disassembly를 확인했으며
ISR에 새 parsing/Flash/heap 처리를 넣지 않았다. Bootloader handoff 실기 검증은 아니다.

- 실제 Arm15.3.Rel1/CubeG4 v1.6.3의 primary-debug BIN51724B,
  primary-release BIN39728B; ELF/MAP/BIN과 기존 bench 두 빌드 모두 성공.
- `cmake --preset primary-debug/primary-release`, 같은 이름 build preset.
  로그 `build/t107-{primary-debug,primary-release,debug,release}-layout-build.log`와
  `build/t107-primary-{debug,release}-final-layout-build.log`. compiler/linker/CMake warning0.
- `arm-none-eabi-objdump -d --disassemble=SystemInit`의 release 실제 명령은
  SCB base0xE000ED00 +8에0x08010200을 store한다. Vendor 원본 변경 없음.
- `tools/ota/validate_stm32_map.py`는 실제 ELF bytes/load span과 BIN의 byte 대조,
  map Flash geometry·vector/Reset_Handler/stack·중첩·gap을 확인한다.
  실제 bench ELF를 넣었을 때 primary geometry 오류로 거절하는 것도 확인했다.
- `build/ota-native-clean/Scripts/python.exe -B tests/ota/check_stm32_primary_image.py
  --binary firmware/communicator/stm32/build/<primary-mode>/canview-communicator-stm32.bin
  --mcuboot C:/cv/mcuboot-2.4.0`: 실제 BIN·최대 payload183296B를 공식 imgtool로
  임시 서명/검증하고 byte 변조 거절. 고정 SDK pin6d3b3d2/clean 확인.
  이번 기록 실행에서 actual signed52563/40567B, 최대 padding 사례184135B,
  trailer2376B/page reserve4096B. signed180KiB·secondary 추가2048B 안에 들어간다.
  ECDSA DER 길이는 실행별로 달라질 수 있으므로 수치는 해당 실행값이며 deterministic
  production 서명 artifact 주장이 아니다. 개인키는 메모리, 임시 signed file은 자동 정리.
  로그 `build/t107-primary-{debug,release}-imgtool.log`.
- map 검사기 mutation6개 unittest 및 기존 core gate8개 성공.
  Host Debug151/15119.28초, Release151/15117.52초;
  `build/t107-primary-host-{debug,release}-test.log`.
- `CANVIEW_STM_IMAGE_LAYOUT=INVALID`는 명시 configure 오류로 거절.
  첫 명령의 따옴표 없는 -D toolchain 인자는 PowerShell에서 분리돼 실패했으며
  그 실패를 negative PASS로 쓰지 않았다. 인자를 인용해 재실행한
  `build/t107-invalid-layout-quoted.log`에서 의도한 거절을 확인했다.
- CI YAML과6개 PowerShell run script syntax 검사 성공. Primary2개 build·공식 imgtool
  확인·artifact6개와 source provenance4개를 기존 target job에 추가했다.
  서명 시험은 별도 임시 venv와 기존 hash lock을 써 ESP-IDF 환경을 변경하지 않는다.
- 합성 fixture source digest는 `f18dc0834ec5ddccd06b05a27e5d3c684d61482f36942a1da83073ef7f15fada`.
  실제 capture는 변경하지 않았다. Board/doc385개1456targets/task49개 검사 오류0.

부트로더64KiB image·actual Flash API/profile/ECC·swap/revert·confirmation·독립2인
task 리뷰는 아직 남아 있다. 이번 commit의 CI 완료/artifact 감사도 아직이다.
T-107 IN_PROGRESS, 실제 Flash/HIL NOT_RUN, 차량 TX NO-GO를 유지한다.

## 2026-09-19 (codex, T-107 C Flash 배치 첫 구현 단위)

PR37은 Draft이며 BSP `flash_layout.c/.h`, portable interface와 CTest를 추가했다.
전체512KiB의 모든 byte offset을 READ/PROGRAM/ERASE 단위로 검사하고, 문서의
literal map·null/zero/invalid enum/UINT32_MAX/끝 경계·실패 출력 불변을 확인한다.
BOOT/RESERVED의 변경 요청은 항상 거절한다. Library만 추가했으며 현재 앱이나
실제 Flash IO에 연결하지 않았다. 범위 성공은 쓰기 권한이 아니다.

최초 Arm build는 새 library의 CAPTURE_ONLY forced include 누락으로 post-build
검증이 실패했다. 기존 compile 계약을 적용하고 재실행해 통과했으며 검증기를
완화하지 않았다. 작업 중 source digest 변경과 겹친 최초 Release python-unit도
실패했다. 합성 fixture/expected digest를 `0f722a0b1c609f97ac8fec65e1a7f49be4a3b3e1482a5d9fea4b0db72b0ea703`로
맞춘 뒤 고정 source에서 Debug/Release 전체를 다시 실행했다. 실제 capture는 변경하지 않았다.

- `ctest --preset host-debug --parallel 4`:151/151,19.41초.
- `ctest --preset host-release --parallel 4`:151/151,18.56초.
- 로그: `build/t107-host-{debug,release}-postfix-test.log`.
- STM32 `cmake --build --preset debug/release`:ELF/MAP/BIN 생성,
  새 BSP Arm object도 strict C99 컴파일. post-fix 로그의 compiler/linker/CMake warning0.
  Debug text51712/data4/bss+stack79808; Release text39712/data4/bss+stack79808.
- 로그: `build/t107-arm-{debug,release}-postfix-build.log`; 실패 로그도 보존했다.
- WSL Ubuntu26.04 Clang21.1.8, 새 두 C 파일을 `-std=c99 -Wall -Wextra -Wpedantic
  -Werror -Wconversion -Wshadow -Wstrict-prototypes -Wmissing-prototypes`로 컴파일해
  `-fsanitize=address,undefined` 실행 성공. 출력 binary는 `/tmp/canview-t107-flash-asan`.
- 동일 source의 `-fprofile-instr-generate -fcoverage-mapping` 실행 후 llvm-profdata/cov:
  production `flash_layout.c` 42regions/2functions/46lines/32branches 모두100%.
  profile은 `/tmp/canview-t107-flash.profdata`; 전체 firmware coverage 주장 아님.
- Board 생성물 PASS, 문서385개/1456targets 오류0, task49개 오류0(아래 문서 추가 전 검사).

MCUboot2.4.0 pin6d3b3d2의 PORTING.md·bootutil CMake·imgtool trailer와 offset status
source를 읽었다. imgtool trailer 계산과 offset bootutil의 실제 상태 수가 다르므로
별도 port의 sector/trailer 경계를 직접 연결해 검증해야 하며 현재 완료로 표시하지 않는다.
DBANK/WRP/NRST·실제 Flash/ECC·swap/revert·bootloader binary·2인 리뷰는 남아 있다.

도구는 기존 t104 worktree의 검증된 LLVM23.1.0/CMake4.4.3/Ninja1.13.2,
Arm15.3.Rel1, `C:/cv/STM32CubeG4-1.6.3`을 재사용했다. 처음 현재 worktree의 환경
script를 호출해 중복 LLVM 압축 해제가 시작됐으나, 해당 실행 PID/명령/부모를 확인해
그 두 process만 중단했다. 현재 worktree `.tools/llvm-23.1.0` 부분 추출물은 사용하지
않으며 삭제하지 않았다. 기존 SDK·evidence·사용자 checkout은 보존했다.

Physical/HIL은 NOT_RUN, 차량 TX는 NO-GO, T-107은 IN_PROGRESS다.

## 2026-09-19 (codex, PR36 merge와 T-107 source 시작)

e1df406 CI35427174458을 재시작 없이 기다려6/6 성공을 확인했다.
target21개 bytes/SHA256·source7개·target logs28개 warning/error0,
manifest `dc2d83a51dfb76dddb0b389ebdd9d5fffa1714092e6a91163d95d85c2a69966b`를
다운로드해 대조했다. 최신 CI host artifact도 Debug/Release150/150이며
host simulation report의 commit은 e1df406, physical_hil은 NOT_RUN이다.
로컬 closure HEAD는 Debug150/15055.01초·Release150/15014.70초,
board 생성물·문서385개/1456 targets·task49개 검사 오류0이다.

PR36 ready 후 match-head-commit을 지정해 merge했다.
2026-09-19T06:58:42Z merge `c60641f218ca5a9966781cc1e8d417df26bb2712`,
origin/main 일치와 e1df406 ancestry를 확인했다. PR body와
[최종 comment](https://github.com/digitie/canview/pull/36#issuecomment-5740075821)에 증거를 기록했다.
T-007 DONE을 archive로 이동한다. 전체 목표나 물리 gate의 완료는 아니다.

다음은 STM32 core/OTA 순서의 T-107이다. T-102 PR29 source merge50410ba는
확인했지만 물리 수용은 열려 있다. 사용자가 승인한 G1 이전 source 범위로
codex/t107-stm32-mcuboot를 origin/main에서 만들고 기존 worktree 경로·SDK·
빌드 증거를 보존했다. 기본 checkout의 사용자 untracked 파일은 건드리지 않았다.
먼저 고정 map과 negative 시험을 구현한다. 실제 Flash/option-byte/provisioning은
실행하지 않았고 physical/HIL NOT_RUN·차량 TX NO-GO를 유지한다.

## 2026-09-19 (codex, T-007 전체 소프트웨어 수용 closure)

77b84cf의 [최종 독립 A/B 감사](reviews/adversarial/2026-09-19-T-007-final-acceptance.md)는
추가 P0–P3 없음, 다섯 AC의 구현·시험 구성 충족, 최신 CI 확인 조건의 CONDITIONAL이다.
두 raw를 그대로 보존하고 원 verdict를 바꾸지 않았다. CI35426085834는6/6이며
내려받은 target21개 bytes/SHA256·source7개·target logs28개 warning/error0을 대조했다.
Manifest SHA256: `4730a7a1b8b361ab4771465e14eb00e4e15028df101e90a962784fa87556a787`.
후속 closure commit의 CI와 merge는 아직 진행 전이다.

최신77b 별도 Linux clone ASan/UBSan139/13918.72초, 실제 compile_commands 옵션 확인,
strict Doxygen/Sphinx71API, 일반 CLI --native394310B 검사를 다시 통과했다.
로그는 final report에 기록했다. WSL rg의 pipe quoting 조회1회는 실패했으며
cat 출력에 PowerShell Select-String을 적용해 옵션을 확인했다. 실패를 PASS로 집계하지 않는다.

Stage post2는 양쪽 PASS·B-STAGE-01 FIXED다. 전체 감사 원문은 진행 정보 응답 때문에
wait의 최신 메시지로 교체돼 기존 원문을 재전송받고 exact 비교했다. 추가 리뷰 실행이나
PASS 변경은 아니다. Resume는 현재 상태·다음 조치·안전 경계만 남기고 과거 이력을
기존 journal/review로 안내한다. Production code 변경 없음. Physical/HIL·Flash·실차·
총 자원 실측은 NOT_RUN, vehicle TX NO-GO. 사용자 checkout과 SDK/evidence를 보존했다.

## 2026-09-19 (codex, identity overlap 사전 거절 oracle)

[82c5193 재검토](reviews/adversarial/2026-09-19-T-007-stage-post.md)에서 원 A는 PASS,
원 B는 identity 사례의 B-STAGE-01 잔존 P2로 CONDITIONAL을 반환했다. 양쪽 원문을
보존하고 B의 OPEN을 유지했다. 해당 조건만 삭제한 C mutant가 기존 시험에서 exit0인
것을 실제 재현했다. reset 전에 body EMPTY를 검사해 하위 parser가 입력을 지운 후
같은 오류를 반환하는 경로와 사전 거절을 구별한다. Production C는 변경하지 않았다.

다섯 실제 C mutant와 baseline, model/CNG stage27그룹씩 통과했다. 전체 Debug150/150
27.52초·Release150/15023.42초, 수정 모형 ASan/UBSan27그룹도 통과했다.
로그: build/t007-stage-post2-{debug,release}-test.log,
before-fix 재현은 build/t007-stage-identity-before-fix.log다. source/합성 digest를 먼저
고정하고 전체 시험을 실행했다. 원 A/B의 재확인과 새 candidate CI는 아직 남아 있다.

569cc83 CI35424935438은6/6, target21개 bytes/hash·source7개·target logs28개
warning/error0을 대조했다. Manifest SHA256:
`707b25dc3d9234cea85e581e4418e91e591309950d628db257d6718cfdadf30b`.
82c5193 독립 Linux clone ASan/UBSan139/13919.30초와 구분한다. 정적 예산 기록
부족은 원 A/B FIXED지만 physical/HIL·총 자원/시간은 NOT_RUN, 차량 TX NO-GO다.

## 2026-09-19 (codex, stage 인자 방어 oracle 수정)

569cc83의 [독립 리뷰](reviews/adversarial/2026-09-19-T-007-stage.md)는 A 정적 PASS,
B CONDITIONAL이다. B-STAGE-01 P2는 여러 잘못된 인자가 겹쳐 의도한 방어 삭제를
검출하지 못하는 시험 결함이다. hash context overlap 조건만 삭제한 실제 C mutant가
기존 시험에서 exit0인 것을 재현했다. production stage.c는 변경하지 않았다.

유효한 입력의 begin/close 양성 대조 뒤 인자 하나만 변경하도록 시험을 고쳤다.
중첩 구조는 stage의 정렬된 충분한 공간에 유효 값을 복사하고 제어 필드는 보존한다.
Hash start 모형은 불법 context를 역참조하지 않는다. 같은 방어 삭제 mutant는 이제
CHECK exit1로 실패하며 compile 오류/crash/timeout을 성공으로 세지 않는다.
기존 call-order3개와 함께4개 mutant, model/CNG27그룹씩을 확인했다.

최종 Debug150/15016.24초·Release150/15014.11초, build warning/error0이다.
로그는 build/t007-stage-post-debug-final-test.log 및
build/t007-stage-post-release-test.log다. 첫 Debug 전체 실행은 문서의 합성 digest를
갱신하던 중 시작해 capture identity 시험1개가 실패했다. source/fixture를 고정한
뒤 위 전체 회귀를 다시 실행했다. 실패 로그도 t007-stage-post-debug-test.log에 남긴다.
수정된 stage 모형 ASan/UBSan27그룹·함수6/6·행91/91·분기90/92를 확인했다.
기존569cc83의 독립 Linux 전체139/139와 구분한다. 원 A/B post-fix 확인·새 CI는 남았다.
실제 Flash/HIL·장치 자원/시간은 NOT_RUN, 전체 T-007 완료는 아직 선언하지 않는다.

## 2026-09-19 (codex, stage 정적 자원 근거와 Linux 전체 회귀)

stage candidate569cc83의 ESP fixture DWARF에서 prefix16488B/body856B/stage896B/
PSA108B를 재확인했다. `.su`의 자체 frame과 상한 연산량을 OTA README에 모았다.
stage는 body를 포함하며 SDK 내부 heap·호출 chain·시간을 무사용/통과로 추정하지 않는다.
실측은 해당 target owner와 T-508 gate에 남긴다. 문서 변경에 따른 합성 digest만
갱신했고 Windows Python/link 회귀2/2·strict docs71 API가 통과했다.

Windows worktree를 /mnt/f에서 직접 사용한 보조 Linux 전체 실행은138/139였다.
python-unit에서 Git commit 식별자가 없어 HIL evidence validation이 실패했다.
WSL git이 .git의 F:/dev/canview/... 포인터를 Linux 상대 경로로 해석하는 것을
직접 재현했다. source 결함으로 우회하거나 evidence validator를 완화하지 않았다.
새 독립 clone /tmp/canview-stage-repo-Lk67Ca에서 동일569cc83을 detached checkout해
Clang ASan/UBSan·leak 검사139/13918.29초가 통과했다. configure/build 경고0,
로그는 clone의 configure.log/build.log/test.log다. 기본 checkout은 변경하지 않았다.
이 성공은 후속 문서 source나 실제 장치 Flash/HIL·시간·heap 측정 성공이 아니다.

## 2026-09-19 (codex, C 수신 저장 순서 연결)

기존 parser/body를 재사용한 작은 C99 stage open/feed/finish/reset을 추가했다.
서명·identity·길이·호환성·floor 실패 시 begin0회, chunk 거절 뒤 write0회,
전체 body/hash 성공 뒤 native callback1회와 실패 후 진행 차단을 검사한다.
정상 begin/write의 양성 기준을 먼저 실행하므로 writer 부재를0회 PASS로 세지 않는다.
heap·RTOS·설치 상태기계·영속 journal·boot selector는 추가하지 않았다.
SDK와 Flash map의 실제 enforcement는 후속 BSP owner 책임으로 유지한다.

- Windows model/CNG stage 입력27그룹씩: 각 정상 입력에서 failure/reentry/cleanup
  시나리오와 chunk1/31/최대 길이를 실행했다. native/storage는 모형이다.
- 실제 C mutant3종(조기 begin, 거절 후 write, native 오류 무시)은 CHECK exit1로
  검출했다. baseline exit0을 선행하며 compiler 오류/timeout/crash는 성공이 아니다.
- Debug150/15052.33초·Release150/15044.42초, configure/build warning/error0.
  로그: build/t007-stage-full-{debug,release}-{build,test}.log.
- WSL Ubuntu26.04 Clang ASan/UBSan·leak 검사 통과. build:
  /tmp/canview-stage-check-VLrbYx. stage.c 함수6/6·행91/91·분기90/92.
- 실제 ESP-IDF6.0.3 fixture ELF/MAP/BIN·metadata172개 음성 시험 통과,
  build/t007-stage-sdk.log warning/error0. BIN SHA256:
  `d6119ceb51fb4cef0f2e141aefe7bbffd6659da961eb5e61b1b49c12287d06f2`.
  API4개 target link, DWARF stage896B, 자체 frame open48B·나머지32B.
  실제 저장 provider나 정상 owner 연결·device 실행 근거는 아니다.
- strict Doxygen/Sphinx 통과: build/t007-stage-docs.log, public API71개.
  합성 HIL source digest만 갱신했으며 실제 차량 evidence는 수정하지 않았다.

최초 host fixture는 stage를 context 첫 멤버로 둬 overlap 검사에서 거절됐다.
CHECK abort의 Windows CRT 대기로 Python30초 timeout이 났고 실행 중 재링크도
permission denied였다. 원 process 종료와 process inventory를 확인한 뒤 fixture를
별도 stage pointer로 고치고 CHECK를 exit1로 바꿨다. 이후 위 전체 회귀가 통과했다.
첫 WSL 변수 전달은 quoting 때문에 /configure.log 권한 오류였다. 독립 mktemp와
확정 절대 경로로 다시 실행했으며 실패한 최초 명령은 PASS로 집계하지 않는다.

native CLI6cf1106은 [원 A/B 재확인](reviews/adversarial/2026-09-19-T-007-native-post.md)에서
정적 PASS·관련 finding FIXED다. 같은 source CI35423635752는6/6 성공이며 내려받은
target21개 bytes/hash·source7개·target logs28개 warning/error0을 직접 대조했다.
manifest SHA256: `efdfff60aa2cd3db8215bb267e1dab8b2044d3fa5f7b27ea0230f85f2b7bce9e`.
이 CI/리뷰를 새 stage source에 재사용하지 않는다. stage 독립 리뷰/최종 CI와
T-007 AC3·최종 수용 감사는 OPEN이다. 실제 Flash/HIL·device crypto·장치
timing/heap/stack 실측은 NOT_RUN, 차량 TX NO-GO, PR36 Draft를 유지한다.

## 2026-09-19 (codex, native ESP 서명 블록 결합 회귀)

7cb07be의 독립 A 리뷰가 A-NCLI-01 P2를 발견했다. espsecure의 외부 공개키 서명
검증만으로는 block의 scheme·내장 key와 결합되지 않았다. scheme와 RSA n/e/rr/m
필드를 각각 변경하고 block CRC·outer hash·outer 서명을 갱신한5건이 기존 코드에서
거절되지 않는 것을 실행해 확인했다. 장치 검증 우회나 Flash 실행 증거는 아니다.

새 암호 구현 대신 고정 공식 pre-calculated-signature helper로 실제 RSA 서명을
검증하고 동일 block을 재구성해 byte 단위로 대조한다. 올바른 scheme/key/digest와
서명이 서로 다른 block에 있어도 통과하지 않는다. CRC를 갱신한 서명 변이까지
6개 필드 거절·정상3개 슬롯·교차 block 거절을 추가했다. 도구 버전·dirty checkout·
timeout/실행 실패와 CLI 출력 미생성 시험도 보강했다. 총8개 unittest method 통과,
로그는 build/t007-native-block-binding-test.log다. 원 리뷰어 재확인은 아직 남아 있다.

T-007에는 상위 OTA 정본과 후속 T-204/T-107/T-205의 책임을 대응했다. 실제 writer
부재를 금지 쓰기0회 성공으로 보지 않으며 AC3 연결 시험은 여전히 OPEN이다.
문서 링크 검사에서 잘못 적은 T-508 파일명을 실제 경로로 수정했다.

앞선 c7f5780의 CI35422223529는6/6 성공이다. target artifact21개 bytes/hash와
source7개를 Windows CRLF로 재구성해 대조했고 target log28개 warning/error0이었다.
manifest SHA256: `32c53499dca5b0916a5d8d916034cf38b79bbf3a975259af8c64ca230cbf7985`.
실제 ESP host RSA10건도 통과했다. 이후 native source의 CI 결과로 재사용하지 않는다.
Physical/HIL·device crypto·Flash·장치 timing/heap은 NOT_RUN, 차량 TX는 NO-GO다.

## 2026-09-19 (codex, 일반 native-aware CLI 연결)

기존 container.py에 `--native`를 연결했다. Outer 검증 뒤 공식 espsecure5.4.0의
RSA3072·esptool ESP32-S3 image parser와 고정 clean MCUboot v2.4.0 imgtool verifier를
사용한다. CANView metadata168B·version·정확한 u64를 비교하며 host 설치 권한을
발급하지 않는다. 조립도 native 검사 뒤에만 새 출력을 생성한다.

6개 unittest가 보존 golden, 다른 board/layout의 ESP3역할, outer가 유효한 native
변조와 sequence/version/ABI 오류, key/SDK 오류, 기존 출력 보존을 검사한다.
ESP 역할별 fixture는 기존 SDK image를 공식 parser로 읽고 checksum/digest를 갱신해
공식 서명 도구에 넘겼다. 시험 개인키는 메모리에만 만들며 파일/Git에 저장하지 않는다.
초기 시험에서 공식 signing API가 BytesIO.name을 요구해 실패했고 합성 입력 이름을
제공하도록 수정했다. 실패를 성공으로 바꾸거나 원 golden을 변경하지 않았다.

esptool에는 Windows wheel이 없어 --only-binary 다운로드가 실패했다. 공식 PyPI
sdist SHA256과 dependency wheel, setuptools82.0.1 backend를 별도 lock에 고정했다.
SDK를 수정하지 않고 build/ota-native-clean venv에 설치했다. 캐시 없이 sdist를 다시
빌드한 설치와 병렬로 실행됐던 host 결과는 최종 gate로 사용하지 않고, 설치 process의
정상 종료 뒤 Debug/Release를 다시 실행해 각각147/147 통과했다.
pip check·generator·문서/task 검사도 통과했고 host compiler/linker/CMake 경고0이다.
로그는 build/t007-native-*.log, 최종 시험은 t007-native-final-{debug,release}-test.log다.
모듈 README 변경으로 합성 T103 digest를
`de0355a890823f2bf64879c6655fdfcaadefaf130ab4ea95aec51991387c19e5`로 갱신했다.
실제 physical evidence나 private 자료는 변경하지 않았다.

receiver P2는 [원 A/B 재검토](reviews/adversarial/2026-09-19-T-007-receiver-post.md)에서
FIXED·정적 PASS다. c7f5780 CI35422223529의 Windows/Linux 등5개 job이 통과했고
target job은 진행 중이다. 이후 native CLI 구현의 검증·리뷰는 별도다.
T-007 전체 acceptance는 아직 OPEN/BLOCK이며 scope 충돌·writer/정책/target 예산
gate를 생략하지 않는다. Physical/HIL/Flash/device PSA NOT_RUN, 차량 TX NO-GO다.

## 2026-09-19 (codex, receiver oracle 조기 인증 오류 회귀 수정)

0acdc45의 [A/B 독립 원문](reviews/adversarial/2026-09-19-T-007-receiver.md)을 보존했다.
A PASS/B CONDITIONAL이며 B-RX-01 P2를 실제 CNG C mutant로 재현했다. 본문 마지막
byte를 변조하기 전에 AUTH_FAILED가 나도 이전 status-only oracle은 성공했다.
변이 feed 자체의 오류와 끝 offset을 함께 요구하도록 고쳤다. 새 회귀 CTest는
조기 open/feed 오류에서 exit1, 이전 약한 oracle 대조에서 exit0을 확인한다.
컴파일 실패를 기대 실패로 인정하지 않으며 제품 source는 변경하지 않는다.

Windows Debug/Release146/146, SDK 재빌드·metadata172개 음성 사례·경고0을 확인했다.
로그는 `build/t007-receiver-oracle-{test,sdk}.log`와
`build/t007-receiver-post-{debug,release}-test.log`다. 원 reviewer 재확인과 새 CI는 남아 있다.
0acdc45 CI35421702811의 Windows job 실패는 Doxygen 공식 ZIP 다운로드 실패다.
진행 중인 target job은 유지했으며 개별 rerun은 GitHub가 거절했다. 이전 d87516a
CI35420771316은6/6과 target21개/source7개/log28개 경고0을 감사했고 이후 source에
재사용하지 않는다. 로컬 strict Doxygen/Sphinx·API71개도 통과했다.
실제 device PSA/Flash/HIL·총 stack/heap/timing은 NOT_RUN, 차량 TX는 NO-GO다.

## 2026-09-19 (codex, 실제 SDK C parser/body 수신 연결·전체 수용 감사)

기존8개 portable C 파일을 IDF component로 등록하고 read-only signed golden을
fixture BIN에 넣었다. manifest P256/SHA256은 실제 SDK PSA를 사용하며 native
image 검증/Flash/설치 승인 경로는 아니다. 같은 receiver.c를 실제 Windows CNG로
실행해 정상·서명/본문 변조·identity 불일치4건을 검사했다. Debug/Release145/145다.
Windows host driver의 fopen deprecation 실패는 fopen_s로 수정했으며 경고를 억제하지 않았다.

SDK build는 `build/t007-idf-receiver-sdk-build.log`, host는
`build/t007-receiver-{debug,release}-{configure,build,test}.log`에 남겼다.
SDK ELF/MAP/BIN과 parser/body/PSA symbol을 확인했다. BIN SHA256은
`17bc7bf232acc156c94690a3f331fdb955a21129afc9d383da78cec241c046bc`이며 unsigned fixture다.
metadata168개 변이+4개 절단을 거절했다. 기존 보존 golden은 과거 provenance 입력을
계속 사용하며 새 fixture로 재서명하지 않았다.

DWARF sizeof prefix/body/PSA=16488/856/108B이며 함수 static이다. 자체 `.su`에서
app_main480B·receiver624B·manifest_check880B를 확인했다. SDK 전체 stack은 아니다.
fixture sdkconfig.defaults의 main stack을16384B로 예약하고 기존 ignored sdkconfig의
같은 항목도 갱신해 재빌드했다. watchdog은 변경하지 않았다. MCU timing/high-water/
heap/실제 PSA/Flash/HIL은 NOT_RUN이다. 새 firmware component/모듈 README 때문에
합성 T103 source identity를 `8ac453bbece8b1f635ed989bb57b6807f8087d382be5318a43ada718e55e63f6`로
갱신했으며 실제 physical evidence를 변경하지 않았다.

d87516a의 [독립 전체 수용 감사](reviews/adversarial/2026-09-19-T-007-acceptance.md)는
A/B BLOCK이다. 원문2개와 공통 request를 보존했다. Native 일반 검사·task 책임 충돌·
target/예산은 OPEN, README의 구현된 prefix/golden 상태 문구는 수정 후보다.
다음은 기존 공식 도구를 이용한 일반 native-aware CLI 연결이며 새 framework는 없다.
기본 checkout의 사용자 dirt는 그대로 보존했다. PR36 Draft·차량 TX NO-GO를 유지한다.

## 2026-09-19 (codex, PSA ready 중첩 시험·golden artifact 감사)

6f078ac의 원 A/B [재검토 원문](reviews/adversarial/2026-09-19-T-007-psa-post.md)을
보존했다. B-PSA-01 P3는 FIXED지만 동일한 신규 P2(A-PSA-POST-01/B-PSA-02)를
받았다. union context가 unready라 signature 중첩 조건을 없애도 같은 오류로
통과할 수 있었다. 별도 context를 정상 init한 뒤 시험하고 SDK 호출 수 불변,
후속 정상 verify와 close, reentry 대상 교체를 확인하도록 고쳤다.

Signature 중첩 조건만 제거한 실제 C mutant는 GCC 빌드 뒤 새 CHECK에서 실패했다.
정상 source는 PASS였다. `build/t007-psa-overlap-mutant.log`가 근거다.
이전 권한 상수를0x1000으로 되돌린 별도 header mutant도 독립 typedef 검사에서
컴파일 실패했다. `build/t007-psa-usage-mutant.log` SHA256은
`548c812f245b4e0f0f71bb343ba53aa04217f564e090387a43d778e1c9c6f65f`다.
제품 provider를 수정하거나 경고를 억제하지 않았다. 새 ASan/UBSan 모형도 통과했고
adapter 행149/149·분기114/118은 유지했다.
Windows Debug/Release144/144와 build 경고0을 재확인했다.
로그는 `build/t007-psa-overlap-{debug,release}-{build,test}.log`다.

262bf09의 CI35418535641 target artifacts를 실제 내려받아21개 ELF/MAP/BIN
bytes/SHA256과 source7개 Git object의 Windows CRLF byte열을 대조했다.
28개 target log에서 실제 warning/error 진단0, 공식 ESP RSA host10건도 확인했다.
Manifest SHA256은 `ebbccfbab14726e514d99c87610f49c37e434c985adb5f1c621a29ff8af5eec3`다.
이 감사는 golden 수정본262bf09만의 증거이며 이후PSA source의 최종 gate가 아니다.
PSA6f078ac CI35420077728의 GCC·Clang·sanitizer는 성공했고 Windows/target은 확인 당시
진행 중이었다. 이번 P2 수정본의 reviewer/CI는 별도 확인해야 한다.

정상 OTA owner·root·영속 policy 연결 미완료, physical/HIL NOT_RUN·차량 TX NO-GO를 유지한다.

## 2026-09-19 (codex, PSA 리뷰·GCC 시험 수정)

70c7a38의 [독립 원문과 disposition](reviews/adversarial/2026-09-19-T-007-psa.md)을
보존했다. A는 정적 PASS, B는 모형 VERIFY_MESSAGE=0x1000 오류 B-PSA-01 P3를
보고했다. 공식 값0x0800으로 고치고 host·SDK fixture 양쪽에서 독립 기대값을
compile-time 검사한다. 실제 제품 adapter는 처음부터 공식 macro를 사용했다.

CI35419613785의 GCC job105834675834가 시험의 작은 context→큰 배열 인자를
`-Werror=stringop-overread`로 거절했다.65B union backing으로 바꿔 합법적인 크기의
중첩 입력을 시험한다. 경고나 음성 사례를 삭제하지 않았다. 완료 job 로그는
`gh run view --log`가 전체 run 진행 중이라 거절해 jobs API의 logs endpoint로 받았다.
원 로그는 `build/t007-psa-ci-gcc.log`다. 수정 후 GCC O3 strict와 Clang ASan/UBSan
모형은 통과했고 행149/149·분기114/118도 유지했다.

별도 실제 PSA Windows host 실행을 시도했으나 공식 TF-PSA-Crypto의 standalone
CMake는 clang에 MSVC 옵션(/W3,/utf-8,/WX)을 넘겨 실패했다. 같은 고정 Clang의
clang-cl로 바꾼 뒤에는 Espressif port의 `mbedtls/bignum.h`가 필요해 빌드 실패했다.
SDK를 수정하거나 가짜 header/암호를 넣지 않았으며 이 추가 host 실행은 NOT_RUN이다.
실패 로그는 `build/t007-psa-host-sdk{,-cl}-{configure,build}.log`에 보존했다.

실제 ESP-IDF fixture 재빌드는 경고0으로 통과했다.262144B BIN SHA256은
`fadfa94c32694baf02caa5d0e268665b796691aa4e72431e7395fc8768a5f18d`이고
metadata168변이·4절단 시험도 통과했다. `build/t007-psa-post-sdk-build.log`가 근거다.
최종 수정 source의 Windows Debug/Release144/144와 build 경고0도 재확인했다.
로그는 `build/t007-psa-final-{debug,release}-{build,test}.log`다.
이전 golden은 바꾸지 않았다. 원 reviewer 재검토·수정본 CI는 아직 남아 있다.
physical/HIL NOT_RUN·vehicle TX NO-GO·정상 OTA owner 미연결을 유지한다.

## 2026-09-19 (codex, ESP-IDF PSA C 암호 provider)

`firmware/platform/esp32s3/ota_crypto.c`에 공식 PSA API 어댑터를 추가했다.
자체 암호 구현이나 범용 framework 없이 volatile P256 공개키 한 개와 SHA256 operation
한 개를 단일 owner가 관리한다. 실패한 hash setup/update/finish 뒤 reset, abort/destroy 실패
뒤 handle 보존과 재시도를 시험했다. 입력 상한·중첩·NULL과 SDK 호출8단계×오류5종,
각 호출 중 재진입도 검사했다. 모형 암호 결과를 실제 암호 검증으로 표시하지 않는다.

Windows Debug/Release는 각각144/144 통과했다. 로그는
`build/t007-psa-{debug,release}-{build,test}.log`다. WSL Clang ASan/UBSan 모형 시험도
통과했고 `build/t007-psa-sanitize-coverage.log`의 adapter coverage는 함수11/11,
행149/149, 분기114/118(96.61%)이다. 전체 OTA나 target coverage로 확대하지 않는다.

ESP-IDF6.0.3 `idf.py -C tests/fixtures/idf-ota-image -B build/idf-ota-image build`로
실제 ELF/MAP/BIN을 생성했다. `build/t007-psa-sdk-build.log`의 실제 진단은 경고/오류0,
nm으로 adapter와 psa_import_key/verify_message/hash/abort/destroy symbol을 확인했다.
262144B BIN SHA256은 `37c90183bac8c3f7d8a90c1862d3e5ed47c123aa35dfd34e1d7ca606718449b9`다.
합성 descriptor offset288/168개 변이/4개 절단 검사는 통과했고, 이전 signed golden은
그 입력 source에 고정된 artifact이므로 새 unsigned BIN으로 덮어쓰지 않았다.
synthetic HIL fixture의 source digest만 현재 source로 갱신했다. physical evidence가 아니다.

앞선 signed golden 원 A/B 재검토 raw와 통합 report는6209eac에 보존했다.
262bf09의 CI35418535641은6/6 성공했으나 그 artifact 감사는 아직 하지 않았다.
PSA 추가분은 독립 리뷰 전이다. 정상 OTA owner·trusted root·영속 policy 통합은 남아 있고
장치 암호 실행·Flash·physical/HIL은 NOT_RUN, 차량 TX는 NO-GO다.

## 2026-09-19 (codex, signed golden STM 서명 거절 경로 보강)

`bd9a1a6`의 새 golden CTest를 포함해 로컬 Debug/Release는 각각143/143 통과했다.
빌드 로그의 compiler/linker/CMake 경고는0이다. 별도 clean detached checkout에서
public-only golden 검증도 통과했다. 그 시험은 기존 동일 C 소스의 CNG 실행파일을
재사용했으며 새 checkout의 전체 재빌드라고 주장하지 않는다. 시험 뒤 clean 상태를
확인해 임시 worktree만 제거했다. 추적 파일은 commit에서 재생성할 수 있다.

Reviewer A 원문 A-SG-01 P2를 수용했다. 최초 STM 음성 두 건은 내부 SHA256 또는
root hash에서 거절돼 P256 verify 실패를 직접 입증하지 못했다. payload와 내부 SHA256
TLV·whole hash를 갱신하되 원본 서명을 유지한 네 번째 사례를 추가했다. native probe
호출 횟수도 정상3·내부 hash 실패2·root 실패0·P256 실패3으로 대조한다.
실제 C 소스의 verify 반환을 무시해 OK로 바꾼 임시 변이 실행파일을 경고0으로 빌드했고
시험이 `[0,12,12,0] != [0,12,12,12]`로 실패했다. 실제 repository verifier는 바꾸지 않았다.
변이 로그 `build/t007-golden-mutant-test.log` SHA256은
`71351ea9c7637624b0cd917ecf94a9fea602cf28d2afd52cc5f3ae4667a5c4b8`다.

Host 초기 환경 로드는 현재 worktree의 도구 cache를 중복 추출하기 시작해 해당 두
실행만 중단했다. 검증된 `t104-stm32-uart-control`의 고정 도구 환경을 재사용했다.
기본 checkout의 사용자 파일은 변경하지 않았다. physical/HIL NOT_RUN·차량 TX NO-GO를 유지한다.

## 2026-09-19 (codex, 공식 native 서명 합성 golden)

공식 espsecure5.4.0과 MCUboot imgtool v2.4.0을 재사용했다. 실제 ESP-IDF 합성
BIN에 RSA3072/PSS 서명을 추가하고 별도의 STM 합성 payload/P256·outer manifest/P256를
하나의394310B 컨테이너로 조립했다. SHA256은
`68eb18e10bf35d351c1604500bf85f6e95aa41c6b49477ffbbdacd9477902655`다.
세 시험 개인키는 메모리 전용이며 공개키·컨테이너·provenance만 보존했다.
무작위 서명 재생성이 아니라 보존된 서명/image로 조립한 byte 일치를 재현 gate로 사용한다.

첫 생성 시 ESP-IDF Python에 cbor2가 없어 실패했다. 제품 SDK 환경을 바꾸지 않고 기존
OTA 시험 venv의 lock된 의존성에 esptool5.4.0을 추가해 생성했다. pip show의 CP949
출력 오류는 도구 정보 출력 문제이며 이후 Python은 UTF-8로 실행했다.
첫 CNG STM golden 시험은 시험 wire의 signed_size/hash/signature를0으로 전달해
INVALID_ARGUMENT를 반환했다. 기존 probe의 입력 계약대로 실제 값을 전달한 뒤
CNG 수신12건·native STM3건과 공식 imgtool 검증, ESP host RSA10건이 통과했다.
firmware 검사를 완화하거나 실패를 성공으로 계산하지 않았다.

정상 OTA owner·영속 policy·제품 signing CLI/target 통합은 남아 있다.
장치 native 실행·Flash·physical/HIL은 NOT_RUN, 차량 TX는 NO-GO다.

## 2026-09-19 (codex, SDK metadata와 prefix checkpoint artifact 감사)

`624848a`에서 C const custom descriptor를 실제 ESP-IDF6.0.3 시험 image에 넣었다.
자동 서명/키/provisioning/Flash 동작 없이 ELF/MAP/BIN 경고0을 확인했고
`tests/ota/check_sdk_metadata.py`로 offset288의168B·u64최대값과168개 byte 변이·4개
절단 거절을 확인했다. BIN SHA256은 `e9dc9177c696a13bdba0631c1da2b3ec125b688862ab2c04921c05c0675d3735`,
로그는 로컬 `build/t007-sdk-metadata-build.log`다. 이는 합성 descriptor 위치/값
증거이며 native 서명·정상 device firmware·boot·HIL 성공이 아니다.

앞선63c8727의 CI35416056122는6/6 성공했다. 내려받은 target21개 ELF/MAP/BIN의
bytes/SHA256을 manifest와 대조했고 source7개도 해당 Git object의 Windows CRLF
byte열과 일치했다. Manifest SHA256은
`5a72e85918d474e679b1eb5fff255fef4a24bdd6aa225658a0cdacaa6fdb21d4`다.
26개 target log에 실제 warning/error 진단은0개다. 최초 넓은 `error` 검색은 SDK의
`error.c.obj` 컴파일 행5개를 검출했다. 내용을 읽어 source filename임을 확인했고
warning 전체·error 진단·CMake/fatal/FAILED 패턴으로 재검사했다. 진단을 억제하지 않았다.
Windows CI Debug/Release LastTest.log도 각각142개 성공·실패0·CNG90교차를 확인했다.
이전63c8727 검증을 이후metadata/새HEAD 검증으로 확대하지 않는다. 이후21cb047의
CI35416950979는 진행 중이다. 전체 T-007·native signing/golden·정상 owner 연결은 남아 있다.

## 2026-09-19 (codex, T-007 prefix·packager checkpoint)

`63c87272fe9f2b00b76893055bfcc8a9ca71cf26`을 Draft PR36에 push했다. C99 고정 buffer
prefix 조립과 host detached P256 서명 조립/검사만 추가했으며 native 설치 승인은 아니다.
기존 SDK/cryptography와 parser를 재사용한다. 실제 CNG 교차90개(collector 경로45개),
Windows Debug/Release142/142 및 Linux 독립 checkout ASan/UBSan137/137이 통과했다.
최초 Debug141/142는 합성 T103 fixture digest mismatch였으며 실제 계산한 source digest
`8e128a30cfe2b153bcd0e1f17267078fe22dc12c2c4cbe374c85018bab325fe1`로 fixture5행과
helper 기대값만 갱신했다. 실제 capture evidence는 변경하지 않았다.
Release 최초 재실행은 실행 중 HEAD 변경에 따른 identity mismatch, WSL 최초 실행은
Windows worktree의 `.git` 경로 해석 실패로 완료 gate를 통과하지 못했다. 고정 commit과
Linux native Git checkout으로 재실행해 위 결과를 확인했다. 검사 기준은 완화하지 않았다.

로그는 로컬 `build/t007-packager-debug.log`, `build/t007-packager-release-rerun.log`,
`build/t007-packager-sanitize-nativegit.log`에 보존했다. 새 collector coverage의
prefix_feed 행93.33%·분기96%, init/finish100%를 확인했다. 최초 llvm-cov 호출은
PowerShell 인자 분리로 실패했고 `-instr-profile=...` 전체를 인용한 재실행이 성공했다.
전체 envelope.c coverage나 MCU timing 성공으로 집계하지 않는다.
CI35416056122의 host5개 job은 통과했고 target job은 진행 중이다.
독립 A 정적 PASS/B CONDITIONAL의 원문을 보존했다. B의 P3 두 표현을 수정했으며
원 reviewer 재확인 전이다. 전체 T-007 IN_PROGRESS·physical/HIL NOT_RUN·차량 TX NO-GO다.

## 2026-09-19 (codex, 명시적 재개와 T-007 후속 구현)

사용자가 "이어서 완주까지 진행"을 요청했다. PR35 MERGED, 열린 PR 없음과
origin/main `6cf1b8e57840a27b83c407d1325a92f869cf2f5d`를 Git/GitHub로 확인했다.
기본 checkout은 기존 branch/사용자 파일을 보존했다. clean T-007 worktree에서
`codex/t007-ota-packager`를 origin/main 기준으로 만들고 로컬 SDK/evidence를 재사용한다.
이전 source 재구현 없이 signed package 작성·검사와 C 수신 연결부터 진행한다.
물리/HIL NOT_RUN, 차량 CAN TX NO-GO, 전체 T-007 IN_PROGRESS를 유지한다.

## 2026-09-15 (codex, 현재 PR merge 후 일시중지 범위 확정)

사용자의 "지금 작업까지만 머지하고 작업 일시중지", "완료시키고 머지 후 일시중지"를
현재 PR #35 구현분의 검증·merge 요청으로 적용한다. 앞선 범위 질문을 이유로 계속
대기하지 않는다. 전체 T-007 수용 기준을 축소하거나 완료로 바꾸지 않으며, 남은
packager/정상 OTA 통합과 다음 task는 재개 요청 전 시작하지 않는다.
review 원본은 그대로 보존하고 현재 상태/후속 작업 안내만 갱신했다.
현재 target CI 및 review 기록 반영 뒤 CI와 artifact 감사를 마친 다음 merge한다.
physical/HIL NOT_RUN, 차량 CAN TX NO-GO는 유지한다.

## 2026-09-15 (codex, 현재 구현분 post-fix 독립 리뷰 closure)

`63197e3`를 같은 reviewer2명에게 object-only로 재검토시켰다. 요청·submission ID·시각과
두 원본을 [post-fix 기록](reviews/adversarial/2026-09-15-T-007-current-post.md)에 연결했다.
A는 정적 PASS, B는 CI/artifact 조건부 CONDITIONAL이며 네 finding은 모두 FIXED,
새 P0/P1/P2/P3는 없다. B의 CONDITIONAL을 PASS로 변경하지 않았다. 양 원본 보존 후
결과를 종합하고 두 reviewer 실행을 종료했다. 이번 변경은 review/상태 기록뿐이다.

CI34908276012는23:25 UTC 확인 시5/6 성공이고 target은 실행 중이었다. Windows artifact를
내려받아 Debug/Release140 Passed/0 Failed, body mock1702/CNG1708, host-sim12 PASS와
commit/source identity를 확인했다. 실제 MCUboot CNG 시험은 이번 실행2283건이며 DER 길이에
따라 건수가 달라진다. 정확한 log digest와 scope는 post-fix 기록에 있다. Node/Git 경고와
예상 argparse 음성시험 출력을 포함한 전체 CI를 warning0으로 표시하지 않는다.

현재 source 결함 리뷰는 닫혔지만 target artifact/source/hash 감사와 기록 반영 후 CI,
사용자의 완료·merge 범위 답변은 남아 있다. T-007 전체 acceptance를 완료로 바꾸지 않았고
추가 기능/다음 task는 시작하지 않는다. physical/HIL NOT_RUN, 차량 CAN TX NO-GO다.

## 2026-09-15 (codex, 현재 구현분 reviewer finding 수정)

`21909e5` 기준 A/B 원본을 모두 보존했다. 각각 CONDITIONAL이며 P0/P1 없음,
A-01/B-01 P2와 A-02/B-02 공통 문서 P3가 있었다. 상세 원문과 disposition은
[통합 리뷰](reviews/adversarial/2026-09-15-T-007-current.md)에 있다. 추가 기능은 구현하지 않았다.

- A-01: 이미 FAILED인 body의 reset 재시도는 최초 error를 유지하고 cleanup 오류만 별도로
  전달한다. 새 scenario9는 최초 AUTH_FAILED/INCOMPLETE 뒤 cleanup이 추가로2번 실패한 뒤
  성공하는 경로를 역할3종에서 검사한다. 수정 전 모형 시험의 exit1을 실제 확인했다.
- B-01: staging data_offset64KiB 정렬을 generator에서 검사한다. Flash 끝은 보존하면서
  offset을4KiB씩15가지 이동한 회귀가 수정 전 모두 실패했고 수정 후 통과했다.
  현재 board 설정과 generated13개 출력은 변경하지 않았다.
- A-02/B-02: 기존 검사기/adapter 구현과 미완료 owner·signed packager·target 통합을
  README에서 구분했다. 새 계층/SDK/의존성 없이 기존 함수와 검사 조건만 수정했다.
- `python -B tests/ota/test_body.py build/host-debug/canview-ota-body-probe.exe` 모형1702건,
  crypto probe `--crypto` 실제 P256/SHA-2561708건. generator11개 시험 통과.
- WSL Clang ASan/UBSan 모형1702건 통과. 새 build/ota-review-fix-body.profraw/.profdata로
  body.c 함수10/10·행220/220·분기94/94 확인. core와 body_probe를 현재 source에서 직접
  `-fsanitize=address,undefined -fprofile-instr-generate -fcoverage-mapping`으로 빌드했다.
- Windows strict 전체 Debug140/140(30.81s), Release140/140(24.99s). build compiler/linker/CMake
  warning/error0. 로그는 build/ota-review-fix-{debug,release}-{build,test}.log다.
- 문서331개/링크1363개·plan49 오류0, board generation check 통과.
  firmware source SHA256 `639bfe1c01453de483e2dd3dbc9b6540c9064e3433526a053a8360f2d2cec1e3`.
  T103 합성 fixture identity만 동기화했으며 physical evidence는 바꾸지 않았다.

직전 candidate의 CI34906746695는6/6 성공했다. 이후 수정 source의 CI/target artifact
감사는 별도이며 원 reviewer post-fix 재확인도 남아 있다. 현재 구현분 merge와 T-007 전체
완료를 구분한다. 범위 질문은 답변 대기, physical/HIL NOT_RUN, 차량 TX NO-GO를 유지한다.

## 2026-09-15 (codex, 현재 구현분 closure 준비·사용자 일시중지 요청)

사용자는 현재 작업 완료·merge 뒤 일시중지를 요청했다. T-007 전체 완성인지 현재
구현분 merge인지 질문했으며 아직 답변을 받지 않았다. 새 packager 구현은 시작하지
않았다. 두 경우 공통인 독립 review와 현재 CI 확인만 진행하며 다음 task는 시작하지 않는다.

- source candidate `21909e586d8fc9e7ebf8d0a4aacd7037e1d7f962`, base `d229772de77a48ae197e2ff1b4e55b6cef9a88ed`.
- 2026-09-14 23:03:32 UTC 새 A/B 요청. execution ID와 공통 manifest는
  [A 실행 기록](reviews/adversarial/evidence/2026-09-15-T-007-current-reviewer-a.md),
  [B 실행 기록](reviews/adversarial/evidence/2026-09-15-T-007-current-reviewer-b.md)에 보존했다.
  object-only 독립 검토 중이며 원본 verdict는 미수신이다. 60초 관찰 timeout 뒤에도 재시작하지 않았다.
- CI `34906746695`: Windows host/GCC/Clang/sanitizer/browser 성공, target 실행 중.
  `gh run download 34906746695 --name windows-foundation-evidence --dir build/ci-34906746695-windows`로
  받은 LastTest.log에서 Debug/Release 각각140 Passed/0 Failed, coverage 실행9 Passed/0 Failed 확인.
  Debug log SHA256 `2d82973bb2fb2e98ec469c189a573733c3d444997b38f49803043e16935d8d9d`,
  Release log SHA256 `0fd049f44aacb6a115a631d4a5bd8ac589ceac70ccde0a2f58d25b0a45c37767`.
- 내려받은 host-sim report는 candidate/source hash와 일치하며
  `python -B tests/hil/validate_evidence.py build/ci-34906746695-windows/hil-host --expect-status PASS`
  12 scenario PASS. physical/HIL은 report 자체도 NOT_RUN이다.
- job `104185088872`의 실제 로그에서 ASan/UBSan136/136과 OTA 모형 실행을 확인했다.
  Windows CNG 4개 시험을 Linux에서 실행한 것으로 집계하지 않는다.
- Windows job `104185089154`의 로그 진단 검색6건은 Node deprecation4건, annotated Git tag
  경고1건, argparse 필수 인자 누락을 의도한 음성 시험 error1건이다. 별도로 runner의
  Node20→24 경고 annotation도 있다. Git은 바로 다음 줄에서 고정 MCUboot commit으로
  checkout했고 이후 실제 imgtool/CNG 시험이 통과했다. compiler/linker/CMake 경고와
  구분하며 전체 CI warning0을 주장하지 않는다. 로그는 build/ci-34906746695-windows-job.log와
  build/ci-34906746695-sanitizer-job.log에 있다.

PR35는 Draft이며 merge하지 않았다. target artifact/hash 대조와 원본 review/disposition은
남아 있다. 차량 TX NO-GO, physical/HIL NOT_RUN과 미완료 T-007 수용 기준을 유지한다.

## 2026-09-15 (codex, OTA schema와 서명 전 manifest 작성 도구)

직전 턴은 BSP 구현·push progress다. `7b36478` clean에서 시작했고 CI `34905471810`은
이번 재확인까지 in_progress였다. 동일 실행을 재시작하지 않았다. T-007은 IN_PROGRESS다.

T-007 수용 범위와 기존 C/Python을 다시 대조했다. 정상 OTA app/owner 확대 전에 누락된
schema와 packager 입력을 완성하는 순서로 조정했다. 기존 byte 계약을 바꾸지 않고
schema/cvota-v2.schema.json과 protocol/schema/ota-container-v2.yaml에 기록했다.
JSON 이름→CBOR integer key는 schema의 x-cbor-key를 재사용한다. JSON 표준 parser와
기존 typed validator를 쓰며 범용 JSON Schema 엔진/새 암호 구현을 만들지 않았다.

tools/ota/manifest_json.py는 최대32KiB UTF-8 JSON을 검증하고 서명 전 CBOR만 생성한다.
duplicate/unknown field, float/NaN, 잘린 입력, 잘못된 hex/type/range/ABI/target 조합을
거부한다. u64를 Python 정수로 보존하며 출력 파일은 exclusive create로 기존 파일을
덮어쓰지 않는다. 실제 signing/native image 검증과 전체 cvota packager는 아직 남아 있다.
UNSIGNED_MANIFEST 출력에 header·dummy signature·image bytes를 넣지 않는다.

- 최초 직접 시험에서 테스트의 read_text가 Windows cp949를 사용해 한글 schema 읽기에
  실패했다. UTF-8을 명시하고 같은 직접 명령과 CTest를 재실행해 통과했다.
- `python -B tests/ota/test_manifest_json.py build/host-debug/canview-ota-manifest-probe.exe -v`
  4개 unittest 통과. 각 JSON prefix 절단, role3종×sequence6종의 C 대조, schema
  매핑/enum/header/native layout 상수와 CLI 기존 출력 보존·실패 입력 비노출을 확인했다.
- 로컬 기존 jsonschema4.26.0의 Draft202012Validator.check_schema, 역할3종 positive,
  newline/role/signature negative 통과. runtime/CI dependency를 추가하지 않았다.
  새 CTest는 mapping drift와 기존 Python/C validator 대조이며 metaschema 엔진 실행은 아니다.
- Windows strict build warning/error0, Debug140/140(30.64s), Release140/140(24.27s).
  build/ota-schema-debug.log, build/ota-schema-release.log와 각 -build.log에 기록했다.
- 문서328개/링크1353개·plan49개 오류0, generated board check 통과. firmware source SHA256
  `33e89e01de8b93e58ec5aac7580fa50ab97c9e2743a5611e88296bf283608ae6`.
  protocol schema/README 추가를 반영해 T103 합성 fixture만 동기화했다.

문서화 스킬에 따라 schema/도구 책임과 검증 한계를 기존 README/OTA 정본에 연결했다.
이번 변경에 firmware C/SDK 경로 수정은 없으며 target/sanitizer를 새로 실행한 것으로
집계하지 않는다. 이후 전체 target CI·native signing/golden·prefix 수신/owner/영속 policy와
독립2인 리뷰가 남았다. physical/HIL은 NOT_RUN, 차량 TX는 NO-GO다. 사용자 파일은 보존했다.

## 2026-09-15 (codex, Communicator OTA BSP 읽기 검증 연결)

직전 턴은 구현·push progress다. `ba10e46` clean에서 시작했다. CI `34904547650`은
재확인 시 in_progress이며 그 부모 `69508bf`의 `34903724621` 성공을 확인했다.
관찰 대기만으로 CI를 재시작하지 않았다. T-007/PR35는 IN_PROGRESS/Draft다.

Communicator BSP `ota.c`는 외부 partition pointer/주소를 받지 않고 고정 bundle_stage를
찾는다. generated board ID/위치/크기, COMM_ESP target과 서명 scheme, prefix 뒤 정렬된
offset을 검사한 다음 기존 SDK 전체 hash/native 서명과 공통 metadata 대조를 호출한다.
정상 OTA task가 호출을 직렬화하고 Flash 불변을 보장해야 하며 현재 이 owner 연결은 없다.
새 mutex/상태기계/writer/부팅 선택은 만들지 않았다. 구조/C 스타일 스킬은 SDK 경계에,
문서화 스킬은 기존 SDK README의 신뢰 입력·수명·미완료 범위 갱신에 적용했다.

- generator에 staging 위치/크기의 BSP macro와 encrypted flag를 연결했다. 최초 공식
  SDK partition parser 실행에서 기존 recovery label이 SDK subtype 이름과 겹치는
  WARNING을 발견했다. 세 template의 label만 recovery_app으로 바꾼 뒤 다시 실행해
  경고0을 확인했다. 주소/크기/app-test subtype과 factory-only sdkconfig는 불변이다.
- `python C:/cv/esp-idf-6.0.3/components/partition_table/gen_esp32part.py --offset 0x18000
  --flash-size 16MB firmware/communicator/esp32/partitions.ota-template.csv build/ota-communicator-esp32-partitions.bin`
  및 Controller16MB/Bridge8MB도 성공. CI의 같은 SDK parser/warning scan에 세 검사를 추가했다.
  partition BIN은 생성만 했으며 flash/migration하지 않았다.
- Windows Debug139/139(34.93s), Release139/139(28.78s). 로그는
  build/ota-comm-bsp-debug.log와 build/ota-comm-bsp-release.log다. generator10개 시험도 통과했다.
- BSP/SDK/metadata/STM 관련9개 CTest 통과. BSP 모형은 실제 metadata 코드를 실행하고
  SDK만 대체한다. NULL·wrong board/role/target/scheme·offset·partition 위치/크기/type·
  SDK 오류·전체168B 변조·version 불일치를 시험했다. 모형은 실제 RSA 검증이 아니다.
- WSL Clang21 ASan/UBSan 통과, BSP 함수1/1·행29/29·분기32/32·region66/66.
  build/ota-comm-bsp.profdata와 build/ota-comm-bsp-asan에 해당한다.
- 실제 SDK fixture에서 BSP/SDK/metadata 심볼을 nm으로 확인했다. build/ota-comm-bsp-idf.log
  compiler/linker/CMake warning/error0. unsigned fixture BIN262144B SHA256
  `df141c306db9b3b5d60b0f73ad4d6d3fe8ec5af3cfff724475b5889640b934a5`,
  ELF4155012B `63e4d15b3cb5f2f6743a66b03daf484f04b110c24d9f263c3e7da7003357fcf4`,
  MAP3025942B `7ea16451eb3db1a0233b41cdda25398bc84af8c75a340de1ee807dae3f5a6ec4`.
- generated board drift 없음, 문서328개/링크1351개·plan49개 오류0. firmware source SHA256
  `421f40a151ec0de52f6d9ad928deac78a4f9c8b9dd148632c58a983a23c71fd1`.
  T103 합성 fixture만 동기화했다. 생성기로 생긴 내용 동일 line-ending 변경은 Git 정규화한다.

다음은 body 완료→BSP 검사를 단일 OTA owner에 연결하고 실제 signed descriptor 생성과
schema/CLI/golden을 완성하는 작업이다. 정상 target 통합·영속 policy·독립2인 리뷰는 남아
있다. physical/HIL·장치 RSA 실행은 NOT_RUN, 차량 TX는 NO-GO다. 사용자 파일을 보존했다.

## 2026-09-15 (codex, STM/ESP native metadata 공통 대조)

직전 턴은 구현·push progress였다. `69508bf` clean에서 시작했으며 부모 CI
`34903724621`은 이번 검증 중 재확인까지 in_progress다. 실행 중인 CI를 재시작하지 않았다.

기존 STM `CVIMG001`168B 대조를 `shared/ota/src/native_metadata.c`로 옮겼다.
ESP에도 같은 함수를 사용하고 SDK `app.version[32]`의 정확한 문자열 대조만 더했다.
role/target/signature 조합을 명시적으로 거부하며 epoch와 u64 sequence를 서로 다른
필드로 유지한다. SDK `secure_version`을 release_sequence로 변환하지 않는다.
새 ESP parser/암호/범용 abstraction을 추가하지 않았다. C 스타일·구조 스킬은
무상태/무힙과 SDK 경계를, 문서화 스킬은 기존 README의 입력 수명·검증 책임 갱신에 적용했다.

- Windows Debug138/138(29.38s), Release138/138(24.61s). 기존 공식 MCUboot imgtool/CNG
  STM 교차 시험을 포함한다. `build/ota-metadata-debug.log`, `build/ota-metadata-release.log`.
- 새 CTest는 NULL·길이0..169/SIZE_MAX·전체168byte 각8bit 변이·role/target/signature
  조합·u64 경계·문자열 최대/미종단/비ASCII/zero padding 불일치를 검사했다.
- WSL Clang21 strict C99 ASan/UBSan 통과. `native_metadata.c` 함수6/6·행60/60·
  분기76/76·region108/108. `build/ota-metadata.profdata`, `build/ota-metadata-asan`.
- 실제 ESP-IDF6.0.3 fixture에서 SDK와 공통 검사기를 compile/link했다. SDK version32B와
  custom168B의 compile-time drift assertion을 추가했다. `nm`에 공통 두 함수와
  adapter/SDK verifier가 존재한다. fixture의 NULL negative 외 실제 호출은 미실행이다.
- `build/ota-metadata-idf.log`의 compiler/linker/CMake warning/error0. unsigned fixture
  BIN262144B SHA256 `83b8dbc6d34f346fb8f4c7a9abc5a9fedb03314e1e47f152641f55efb316e2ee`,
  ELF4150236B `22f12bf0c3f628800a0e1ad0fbf97ba0a9362a274c1ba260500d6dae95b52c17`,
  MAP3022892B `95c84d2f6d48e0bcee87523e5acfc1155fc975c2545e682ad6b50e3191cf4c22`.
- generated board check 통과, 문서328개/링크1351개·plan49개 오류0.
- firmware source SHA256 `5cb77580ff911e2bedf542d2f94e734365b5a481e6aec6916a797504db22afaf`.
  T103 합성 fixture만 동기화했다. 사용자 파일·physical evidence는 변경하지 않았다.

다음은 SDK→metadata의 BSP/body provider 연결과 owner/Flash 불변 보장이다.
실제 descriptor 생성·signed golden·schema/CLI, 영속 policy/정상 target 통합과 최종
독립2인 리뷰는 남아 있다. Task/PR은 IN_PROGRESS/Draft다. physical/HIL·장치 RSA
실행은 NOT_RUN, 차량 TX는 NO-GO이며 writer/boot selector/provisioning은 실행하지 않았다.

## 2026-09-15 (codex, ESP native SDK read-only adapter 실제 빌드)

`8749529` clean에서 시작했다. 앞선 정렬 구현 턴은 progress이며 동일 CI
`34901848402`는 작업 시작 시5개 job 성공/target-firmware-windows 실행 중이었고,
커밋 직전 재확인에서6개 job 모두 성공했다. 관찰 timeout으로 재시작하지 않았다.
이 결과는 `8749529`에만 해당한다. T-007/PR #35는 계속 IN_PROGRESS/Draft다.

`firmware/platform/esp32s3/ota_image.c`는 BSP가 준 실제 partition의 내부 Flash·범위·
정렬·signature sector 길이를 검사한다. SDK의 DATA hash 모드로 signature sector까지
전체 file hash를 대조하고 `esp_image_verify()` 뒤 app/custom descriptor를 읽는다.
SDK를 재사용하므로 자체 SHA/RSA/ESP image parser와 Flash writer를 추가하지 않았다.
signature 비활성·0값·다른 scheme·FPGA 및 bootloader alias는 fail-closed다.
실제 Flash 암호화가 켜졌는데 staging이 암호화되지 않았으면 거절한다.

문서화 스킬의 경계·소유권 계약을 [SDK fixture README](../tests/fixtures/idf-ota-image/README.md)에
기록했다. SDK 타입은 platform/BSP에만 있다. 단일 task/Flash 불변은 caller 계약이며
아직 정상 app orchestration에 연결되지 않았다. raw signed metadata와 CANView 정책
대조·body provider·generated staging 암호화 flag 확인은 다음 작업이다.

- SDK compile/link fixture의 실제 ELF/MAP/BIN 생성. BIN262144B,
  ELF4141676B, MAP3019229B. `nm`으로 adapter, 전체 file hash, image verifier와
  `esp_secure_boot_verify_sbv2_signature_block` 심볼을 확인했다.
- `CONFIG_SECURE_SIGNED_ON_UPDATE=y`/RSA scheme의 실제 sdkconfig를 확인했다.
  자동 signing은 꺼져 있으므로 이 BIN은 서명된 CANView 배포 이미지가 아니다.
- 최초 SDK 빌드에서 deprecated `esp_flash_encryption_enabled()` 경고를 발견했다.
  `esp_efuse_is_flash_encryption_enabled()`로 교체하고 재빌드 log의
  compiler/linker/CMake warning/error0을 확인했다. 경고를 억제하지 않았다.
- 최초 `-B ../../../build/idf-ota-image`는 기대와 달리 `F:/build/idf-ota-image`에
  생성됐다. 이후 현재 checkout의 절대 `build/idf-ota-image` 경로로 다시 빌드했다.
  앞선 디렉터리는 삭제/재사용하지 않았으며 아래 증거는 checkout 안의 후속 빌드다.
- Host unsigned 시험의 사용하지 않는 `external_chip` 변수로 strict compile이
  실패했다. 해당 변수의 선언을 실제 사용하는 signed 시험 scope로 옮긴 뒤 재검증했다.
- Windows Debug137/137(28.42s), Release137/137(23.91s). 로그는
  `build/ota-esp-sdk-debug.log`, `build/ota-esp-sdk-release.log`다. 새6개 SDK 설정
  모형은 실제 adapter의 bounds·hash/SDK/read 실패·출력0·호출 순서를 검사한다.
- WSL Clang21 signed SDK 모형 ASan/UBSan 통과. adapter 함수1/1·행54/54·분기70/70.
  `build/ota-esp-sdk.profdata`는 해당 모형 실행이며 실제 RSA 실행 증거가 아니다.
- SDK 로그 `build/ota-esp-idf-build-fixed.log`, BIN SHA-256
  `ac04f8f05241f0d7caf1aaa968a7517ce3007929abacdf027fdf89a2dea7b6df`,
  ELF `b639a8736dd1f67ca8a8b5ba8c24602a7dde776d9c173f73964bbf3c259635da`,
  MAP `7acdd68d9f7f41864bcc685ce98e3bbcfb8ffafb5a8589bd9c702b4874af1e14`.
  local dirty source의 compile fixture이며 CI/production artifact로 재사용하지 않는다.
- firmware source SHA-256은
  `f6652e2099743ab2431633ceb308bbd12605015d175b4d25f55dde6f34e2d468`.
  T103 합성 fixture 식별자만 동기화했다. physical evidence를 수정하지 않았다.
- CI에 실제 SDK fixture build·서명 설정 확인·ELF/MAP/BIN manifest/hash·로그 warning
  검사를 연결했다. 기존 target18개에 probe3개를 더 보존한다. 이 새 CI는 아직 미실행이다.

SDK API는 실제 빌드했으나 board에서 signature를 실행하지 않았다. physical/HIL,
Flash/boot selector/provisioning은 NOT_RUN, 차량 TX는 NO-GO다. 최종 독립2인 review,
정식 schema/CLI/golden, metadata 정책·정상 target integration은 미완료로 남긴다.

## 2026-09-15 (codex, OTA revision2 정렬과 순차 padding 검사)

`4d99222` clean worktree에서 시작했다. PR #35는 OPEN/Draft이며 그 기준선의
CI `34731902196` SUCCESS를 확인했다. 이전 턴은 실제 SDK/BIN 정렬 제약을
확인한 progress였고, 이번에는 C/Python 구현과 회귀시험으로 반영했다.

[ADR-009](adr/009-ota-native-image-alignment.md)에 따라 `CVOTA002`/header2/signed
manifest2로 구분한다. 작은 prefix 이후 각 native image를64KiB에 정렬하며 빈 공간은
0만 허용한다. C body는 prefix 실제 길이부터 chunk를 읽어 padding을 검사하고,
image hash에서는 제외한다.64KiB RAM buffer·별도 ESP parser·Flash writer는 없다.
native metadata/Flash layout version은 바꾸지 않았다. AGENTS의 단순화 원칙을 유지한다.

기존 payload 모든 byte 변이/절단, 단일·역순·최대 image, provider/cleanup/reentry
시험을 유지했다. padding 양 끝과4KiB 경계±1,64KiB 길이±1, 구버전/미래 버전,
완료 뒤 추가 byte를 보강했다. Python assembler 결과를 독립 padding fixture와
대조하고 같은 byte열을 C stream에 넣었다. padding 전체에 대한 전수 변이로
표시하지 않는다. 마지막 추가 시험은 probe의 scenario 상한이7인 탓에 중단됐고
Debug129/131과 ASan probe exit1을 확인했다. 새 scenario8을 명시적으로 허용한 뒤
아래 전체 검증을 재실행했다. 해당 실패를 firmware 결함이나 PASS로 기록하지 않는다.

- Windows strict build 뒤 Host Debug131/131(37.14s), Release131/131(24.64s).
  로그: `build/ota-alignment-debug.log`, `build/ota-alignment-release.log`.
- body 모형1696건, Windows 실제 P256+SHA-2561702건. typed manifest1437/1440건,
  실제 P256 prefix232건, CBOR11989건, floor3847건과 STM native CNG2285건도 통과.
- WSL clang21 ASan/UBSan으로 현재 body1696건, typed manifest1437건과 envelope
  경계 C 시험 통과. `build/ota-alignment.profdata`는 이 세 실행의 profile만 합쳤다.
  body.c: 함수10/10·행219/219·분기92/92. envelope.c: 함수3/3·행80/89·분기32/38.
  manifest.c: 함수16/16·행377/402·분기216/240. 이전 profile 수치를 합산하지 않았다.
- Cortex-M4 GCC15.3 freestanding/strict object compile 통과. body의 보고된 frame은
  open40B/feed56B, helper8~16B이며 전체 call-chain/SDK stack 측정은 아니다.
- `python -B tools/generate_boards.py --check`, document links328문서/1347target,
  plan49task 검증 통과. 전체 host에는 SDK config negative와 generated drift도 포함된다.
- Doxygen1.18/Sphinx9.1 strict build 통과. 추출71개는 기존 public API 범위이며
  private OTA header까지 자동 문서화했다고 주장하지 않는다.
- firmware source SHA-256은
  `18263a9cc9035e7b5601cd3532df3e934c75e97b7172a88e3bbc00a9ae42f5bb`다.
  T103의 합성 JSONL5행과 합성 helper 기대 hash만 동기화했다. 물리 evidence가 아니다.

새 source의 CI와 최종 target 통합·artifact/hash/warning 감사, T-007 최종 독립2인
리뷰는 남아 있다. 다음은 정렬된 staging에서 SDK native verifier·signed metadata를
연결하는 작업이다. 실제 eFuse/Flash/board/HIL은 NOT_RUN, 차량 CAN TX는 NO-GO다.
T-007/PR을 완료·ready·merge하지 않았으며 다른 worktree의 사용자 변경을 보존했다.

## 2026-09-13 (codex, ESP native SDK 재사용의 정렬 제약 확인)

`5b3a711` clean 기준에서 ESP-IDF6.0.3 source와 실제 CI image를 조사했다.
독립 read-only 조사 agent `01a09874-f824-77e2-8ea6-866a6f4cf962`(Pasteur)도
같은 결론을 반환했다. 이는 설계 조사이며 hostile review/PASS가 아니다.

확인한 제약:

- `components/bootloader_support/src/esp_image_format.c:1179` 부근에서 서명 끝을
  **절대 Flash 주소**의4KiB로 올림한다. 임의 offset에 둔 compact image를 그대로
  `esp_image_verify()`에 넘기면 image-relative 서명 배치와 다를 수 있다.
- 같은 파일916행 부근은 mapped segment의 Flash/load 주소를 MMU page로 대조한다.
  `components/soc/Kconfig:25`와 현재8/16MiB board 기준은64KiB다. 따라서4KiB
  정렬만으로는 부족하며, SDK 전체 verifier 재사용에는 image 시작64KiB 정렬이 필요하다.
- `bootloader_flash/src/bootloader_flash.c:53`의 앱용 mmap handle은 전역 하나다.
  OTA/boot 검증 관련 SDK 호출을 한 owner가 직렬화하고 중첩 호출하지 않아야 한다.
- `esp_image_format.c:43`의 `CONFIG_SECURE_SIGNED_ON_UPDATE` 조건을 확인했다.
  서명 검증이 꺼진 bench 빌드를 native signature 성공으로 처리하면 안 된다.

CI34730820401(c0de352)는6/6 성공을 확인했다. `gh run download 34730820401
-n target-firmware-images -D build/ci-34730820401-images`로 실제 산출물을 받았다.
IDF export 후 esptool5.4.0의 `LoadFirmwareImage('esp32s3', path)`로 Communicator,
Controller, Bridge BIN을 각각 읽었다. mapped segment 두 개씩에서 SDK의
`(base + segment.file_offs + 8) % 65536 == segment.addr % 65536` 조건을 재현했다.
세 이미지 모두 base0xA40000/0xA50000은 일치하고0xA41000은 불일치했다.
이는 실제 BIN으로 주소 조건을 재현한 것이며 장치의 verifier/서명 실행 시험은 아니다.

조사에 사용한 BIN SHA256:

- Communicator: `909350e56679dcce4d33cd3285e89f3e007d18a814536b9e499c669fb24b889a`
- Controller: `588705269905bb3ca564eac4f6fb7ee68d9160a97125bcbae5c3b22ffa26667a`
- Bridge: `7cfb7bfbb47d4b23b2cc9b5c8a7bae5549a4130fbb917c2e6b0975ce1fcaa6fd`

단순한 대안은 prefix 뒤/각 image 앞에 canonical zero padding을 두고64KiB 정렬된
bundle을 staging에 그대로 저장하는 방식이다. 임의 주소 필드나 별도 ESP parser,
논리/물리 offset 변환 계층이 필요 없다. 마지막 image 뒤 padding은 불필요하다.
`boards.json`의 staging base0xA40000은 이미64KiB 정렬이다. 최대4MiB ESP와180KiB
STM을 양쪽 순서로 계산하면 bundle은4444160/4456448B이며 staging4718592B에 들어간다.
다만 padding은16KiB 이하 chunk로 검사해야 하며64KiB prefix buffer를 만들면 안 된다.

이 정렬은 현재 compact 후보의 wire 해석을 바꾼다. 이번 조사에서는 parser/서명 byte
계약을 조용히 바꾸지 않았다. 다음 구현에서 포맷 revision/정식 schema와 정렬 규칙을
명시하고 C/Python·padding 변이·streaming·SDK 통합을 함께 검증해야 한다.
기존 v1 체크포인트 결과를 새 배치의 검증으로 재사용하지 않는다.
T-007/최종 2인 리뷰는 미완료, physical/HIL NOT_RUN, 차량 CAN TX NO-GO다.

## 2026-09-13 (codex, OTA version floor와 동일 이미지 복구 사전 판정)

`floor.c/h`에 OTA §7.1의 순수 C99 비교를 구현하고 body open에서 호환성 검사 뒤,
첫 hash 시작 전에 필수 호출한다. uint64 하한 미만은 STALE, 같은 sequence/다른
confirmed digest는 AUTH_FAILED(CONFLICT)다. 실제 정상 앱 검증 snapshot이 일치해야
ALREADY_INSTALLED, 손상/선택 불가가 확인돼야 REPAIR_REQUIRED 후보가 된다.
미확인 policy/설치 상태는 INCOMPLETE이며 영속 floor0으로 초기화하지 않는다.

불필요한 저장 계층이나 범용 policy engine은 추가하지 않았다. 스킬의 무힙·소유권·
문서화 규칙을 적용해 입력은 호출 중 불변으로 빌리고 판정만 복사한다. 실패 시
두 target의 판정을 모두 지운다. 영속 journal A/B 선택·CONFIRM_INTENT·실제 설치본
검사·floor 갱신·automatic rollback은 기존 설계의 owner가 구현할 별도 범위다.

검증과 실패 수정:

- body probe 호출부 변경 중 무관한 manifest_preflight NULL 시험 두 곳에 인자를
  하나 더 넣어 strict compile이 실패했다. 해당 두 호출만 복원한 뒤 재빌드/회귀했다.
- `ctest --test-dir build/host-debug -R 'ota-version-floor|ota-body' -V`: 순수 C3847건,
  본문 모형1480건, 실제 CNG P256+SHA2561486건 통과. 미확인/누락/잘못된 policy,
  u64 하한/충돌/NULL은 첫 hash operation 전에 거절됨을 probe에서 확인했다.
- `tests/ota/test_floor.c`: 네 target, u32/u53/u63/u64 경계 교차, 모든 digest bit,
  잘못된 count/role/target/enum/text, 부분 성공 폐기와 입력 불변성을 검사했다.
- WSL Clang21 ASan/UBSan: floor3847건과 body 모형1480건 통과.
  `build/ota-floor.profdata`의 floor.c 함수5/5·행105/105·분기94/94;
  `build/ota-floor-body.profdata`의 body.c 함수10/10·행203/203·분기84/84다.
  floor는 암호 연산을 하지 않으며 body 모형은 실제 암호 검증으로 집계하지 않는다.
- 고정 Windows Clang23/CMake strict build 뒤 전체 Debug131/131(32.54초),
  Release131/131(26.47초). `ctest --test-dir build/host-debug --output-on-failure
  --output-log build/ota-floor-debug.log` 및 host-release/ota-floor-release.log로 재현한다.
- Arm GNU15.3.rel1 `-mcpu=cortex-m4 -mthumb -ffreestanding -Os -fstack-usage` strict
  object compile 통과. floor_check 단일 frame40B다. target ELF/MAP/BIN 증거는 아니다.
- source digest `76c48306a09135c595f5dc80aa4e3a7e383edf80348b8699d3b221f685a0d5f8`로
  T103 합성 fixture만 갱신했다. 실제 물리 evidence는 변경하지 않았다.
- 직전 c0de352 CI34730820401의 host/portability/sanitizer/browser job 성공,
  target job 실행 중을 확인했다. 이후 floor 변경의 CI 또는 target 통합 증거로 쓰지 않는다.

T-007 IN_PROGRESS/PR #35 Draft다. ESP native 검증·prefix 부분 조립·정식 schema/CLI/
signed golden·실제 provider/target 통합과 최종 독립 2인 리뷰는 남아 있다.
physical/HIL NOT_RUN, 차량 CAN TX NO-GO와 writer/activation 권한 분리를 유지한다.

## 2026-09-13 (codex, MCUboot native P256 image 검사)

공식 MCUboot v2.4.0을 `C:/cv/mcuboot-2.4.0`에 clone했다. 실제 HEAD는
`6d3b3d2c38ab20c242e5b9abb04d050086383eb2`, clean이며 imgtool CLI는2.4.0을 출력했다.
commit은 toolchain manifest, Windows 의존성은 기존 OTA wheel lock에 고정했다.
CI host job도 같은 source를 clone/검증한 뒤 시험한다. upstream 원본은 수정하지 않았다.

`native_stm.c`는 header512/일반 image180KiB 상한, flags/load address0, protected
vendor TLV와 SHA256/KEYHASH/P256 DER의 고정 profile을 검사한다. 전체 image digest와
manifest, protected board/role/layout/epoch/ABI/sequence와 local identity/descriptor,
native version과 정규 version 문자열을 대조한다. native signed-region hash와 P256
signature도 SDK로 독립 검사한다. Windows의 기존 CNG P256 검증을 digest helper로
추출해 재사용했다. DER 정수 변환 외에 암호 알고리즘을 새로 구현하지 않았다.

검증:

- `python -B tests/ota/test_native_stm.py build/host-debug/canview-ota-native-stm-probe.exe`:
  실제 imgtool 생성/검증·CNG SHA256/P2562283건. wrong root/whole hash, 모든 byte 변이/
  절단, 유효하게 재서명한 잘못된 metadata, u64 경계, DER 음수/길이/중복 TLV,
  provider 실패와 최대 image를 검사했다. 임시 image 파일만 생성하며 개인키는 메모리 전용이다.
- WSL Clang21 ASan/UBSan C probe와 같은 script의 `--model --wsl`:2284건.
  Python이 계산한 hash/서명 결과를 반환하는 모형이며 실제 암호 통과로 집계하지 않는다.
  무작위 ECDSA DER 길이에 따라 byte별 시험 건수가 달라진다.
- `build/ota-native-stm.profdata`: native_stm.c 함수9/9·행158/161(98.14%)·
  분기180/190(94.74%). 최초 default.profraw는 생성 위치를 확인한 뒤 ignored
  build/ota-native-stm-initial.profraw로 이동했고 후속 profile은 build에 직접 출력했다.
- Windows Clang23 strict C99/CMake build, CLI dependency 수정 후 최종
  Debug130/130(29.95초), Release130/130(25.61초). 로그는 ignored
  build/ota-native-stm-debug-final.log와 build/ota-native-stm-release-final.log다.
  앞선 envelope/body/manifest 암호 회귀도 포함한다.
- Arm GNU15.3.rel1 Cortex-M4 freestanding object compile. native check 단일 frame160B,
  helper16~56B다. 실제 target ELF/MAP/BIN/call-chain budget 완료는 아니다.
- Doxygen1.18/Sphinx9.1 strict build 통과, 기존 공개 API71개 계약 PASS다.
  이 XML 입력 목록에는 새 내부 OTA header가 없으므로 그 API의 추출 증거로 확대하지 않는다.
- 이전0e62ec6 CI34729444268 success를 확인했다. 이후 source에 재사용하지 않는다.
  합성 source digest는 `8bddaf30c8f30e20d0ebec4c5faea3207cd4b5669327e05af1ad7f47a1fccb0a`다.

wheel 설치 시 user Python의 click/cffi가 lock 버전으로 갱신됐다. pip의 user Scripts
PATH 안내 경고는 target compiler warning과 구분하며 해당 CLI를 설치 검증으로 사용하지
않았다. 명령은 Python module/API로 실행했다. 개발환경 문서에는 공용 Python 보존이
필요한 경우 venv와 CMake Python 경로를 함께 지정하도록 기록했다.
분리된 기존 OTA venv에서 재확인하니 imgtool API 시험은 통과했지만 CLI는 PyYAML
누락으로 실패했다. CLI import에 필요한 PyYAML wheel/hash를 lock에 추가하고 시험에도
실제 CLI version 호출을 넣었다. 환경의 우연한 전역 패키지로 숨기지 않는다.
수정 뒤 같은 분리 venv의 CLI+native CNG2287건과 위 최종 전체 회귀가 통과했다.

스킬의 인터페이스/소유권 규칙에 따라 기존 OTA README에168B metadata 후보와
공식 extension 근거를 기록했다. 정식 schema/ADR 동결·ESP native 검사·packager/golden·
version floor·target SDK/Flash/bootloader 통합과 최종 2인 리뷰는 남아 있다.
합성 bytes의 format/crypto 성공은 부팅 가능성·실물 복구 검증이 아니다.
T-007 IN_PROGRESS, PR #35 Draft, physical/HIL NOT_RUN, 차량 CAN TX NO-GO를 유지한다.

## 2026-09-13 (codex, OTA 로컬 호환성 사전 검사)

`manifest_preflight()`를 기존 C 검사기에 추가하고 body open에서 필수 호출한다.
서명/identity 검사 뒤 신뢰된 로컬 snapshot으로 ESP/STM 구·신 네 조합을 signed
allowlist와 비교한다. 한 image만 업데이트하면 다른 MCU의 ABI는 그대로 유지한다.
MCU별 bootloader/recovery 최소 ABI, hardware capability 부분집합과 보존 config의
읽기 범위를 검사한다. 미확인 snapshot은 INCOMPLETE이며 provider 시작 전 거부한다.
외부 peer의 존재/ABI를 Communicator 자체 복구의 설치 조건으로 추가하지 않는다.

기존 파일/API를 확장했으며 새 framework·wire 필드·writer는 만들지 않았다.
embedded-cstyle/architecture/documentation 스킬의 고정 메모리·소유권 원칙에 따라
snapshot의 출처/수명/실패 동작을 header와 기존 OTA README에 기록했다.

검증 결과:

- 고정 Windows Clang23 strict C99 build, 전체 Host Debug129/129(37.22초),
  Release129/129(28.44초). `ctest --test-dir build/host-debug --output-on-failure`
  및 host-release. ignored 로그: `build/ota-preflight-debug.log`,
  `build/ota-preflight-release.log`.
- `python -B tests/ota/test_body.py build/host-debug/canview-ota-body-probe.exe` 모형1462건,
  crypto-probe.exe와 `--crypto` 실제 P256+SHA-2561468건. 네 조합 각각 누락,
  단일 target·순서 반전·16개 조합·0/u32 최대 ABI, 모든64bit capability 누락/허용,
  boot/recovery/config 경계와 재진입/cleanup 회귀를 포함한다.
- WSL Clang21 ASan/UBSan으로 body1462건과 기존 manifest1422건을 각각 재빌드/실행했다.
  새 임시 profile 디렉터리를 합친 `build/ota-preflight-combined.profdata`에서
  manifest.c 함수16/16·행386/395(97.72%)·분기223/238(93.70%),
  body.c 함수10/10·행198/198·분기82/82(100%)다. provider/장치 전체 coverage가 아니다.
- Arm GNU15.3.rel1 Cortex-M4 strict freestanding object compile 통과.
  `build/ota-preflight-arm.su`의 preflight 단일 frame40B, runtime48B,
  기존 manifest_check864B다. call-chain stack/target ELF/MAP/BIN 증거는 아니다.
- 문서327개/target1340개·task49개 오류0. 합성 source digest는
  `fae13dde1175135377bf9abc93b2b470e0b4934b7c2d6f8b696b0fd0e8d93cf5`이며
  T103 합성 fixture 식별자만 갱신했다. 과거 physical evidence는 그대로다.

snapshot은 저장하지 않으므로 설치 owner가 transaction/상태 변경 뒤 다시 검사해야 한다.
native image 서명/보호 metadata와 manifest 대조, version floor/CONFLICT/REPAIR,
schema/CLI/golden·prefix 조립·실제 target 통합·최종 독립 2인 리뷰는 미완료다.
T-007 IN_PROGRESS, PR #35 Draft, physical/HIL NOT_RUN, 차량 CAN TX NO-GO다.

## 2026-09-13 (codex, OTA 순차 본문 hash와 수신 lifecycle)

기존 manifest 검사 뒤에 body open/feed/finish/reset을 연결했다. 완전한 prefix를
검증하고0..16KiB chunk의 절대 offset·image 길이·SHA-256을 순서대로 대조한다.
chunk/prefix/identity pointer를 저장하지 않고 descriptor와 hash 함수표만 복사한다.
hash context는 NULL을 거부하고 reset 성공까지 빌린다. 중복/누락 offset, 크기
초과, hash/provider 오류는 FAILED이며 manifest를 지운다. cleanup 실패는 자원을
잃지 않고 원 오류와 별도로 기록해 reset을 재시도한다. 동일 객체 callback 재진입은
busy로 거부하며 thread 동기화는 caller의 단일 owner 계약이다.

암호를 새로 구현하지 않았다. 기존 Windows P256 verifier를 host 전용
`tests/ota/cng_provider.c`로 추출해 기존 envelope 시험과 함께 사용하고, 같은 SDK의
SHA-256 operation을 연결했다. Windows provider의 SDK hash allocation은 portable
core의 무힙 특성과 구분한다. provider는 장치 binary에 아직 링크하지 않는다.

최종 검증:

- Windows Clang23/CMake4.4.3/Ninja1.13.2 strict C99 build, Debug129/129(25.43초),
  Release129/129(20.90초). 로그는 ignored `build/ota-body-debug-final.log`,
  `build/ota-body-release-final.log`다.
- `python -B tests/ota/test_body.py build/host-debug/canview-ota-body-probe.exe`:
  sum/length 모형의 수명/실패900건. 모형을 SHA-256 성공으로 집계하지 않는다.
- 같은 script와 `build/host-debug/canview-ota-body-crypto-probe.exe --crypto`:
  실제 Cryptography48 P256 manifest + Windows CNG SHA-256906건. 역할별 임시
  key와 잘못된 root, 잘못된 서명, `abc` known answer·모든 본문 byte 변이,
  최대 slot 길이·image 경계 chunk·EOF·중복/누락·reset·provider/cleanup 실패를 검사했다.
  개인키는 메모리에서만 생성하며 합성 bytes는 부팅 가능한 firmware가 아니다.
- WSL Clang21 ASan/UBSan과 위 모형900건 통과. 매번 새 profile 디렉터리를 사용했고
  `build/ota-body.profdata`의 body.c 함수10/10·행198/198·분기82/82(모두100%)다.
  전체 OTA/native provider/target coverage gate 완료로 확대하지 않는다.
- Arm GNU15.3.rel1 Cortex-M4 freestanding object compile 통과. 단일 frame은
  open48B/feed32B/finish24B/reset864B, helper16~56B다. reset의 aggregate 초기화
  temporary를 포함한 값이며 SDK 포함 call-chain stack·MCU timing·ELF/MAP/BIN
  검증을 대신하지 않는다.
- 직전 b25b69a의 CI34727655450는 success다. 이후 본문 source의 CI/artifact
  검증으로 재사용하지 않는다. 새 staged diff와 secret/VIN은 push 전에 별도 확인한다.

EOF+cleanup 실패 시험의 초기 입력은 Communicator 첫 image를 끝내 reset 실패가
먼저 발생했다. 기대했던 EOF 경로가 아니므로 첫 image가 끝나기 전에 끊도록 시험
입력을 수정했다. 이후 두 모형/실제 암호 시험과 전체 회귀를 재실행했다. 구현의
거절 조건을 완화하지 않았다. 합성 source digest는
`94c2f6fdffc8e820205326b8866bd6cea32960b8edb89fd48771444fa2b78684`다.

스킬의 소유권·정리·상태 계약을 OTA README에 기록했고, 상세 task의 중복 진행
이력은 현재 구현/검증으로 줄였다. 기존 journal/review 원본은 변경하지 않았다.
HASHES_MATCHED는 native image signature/protected metadata, 현재/후보 ABI·
requires/version floor, Flash read-back·PREPARED/boot selector 권한이 아니다.
prefix 부분 수신 조립·정식 schema/CLI/golden·실제 ESP/STM provider와 target 통합,
최종 독립 2인 리뷰는 남아 있다. PR #35 Draft, T-007 IN_PROGRESS,
physical/HIL NOT_RUN, 차량 CAN TX NO-GO를 유지한다.

## 2026-09-13 (codex, OTA typed manifest와 대상·길이 대조)

기존 prefix/실제 서명 경로 뒤에 고정 구조체 decoder를 연결했다. 임의 주소나
경로를 허용하지 않고 역할별 일반 앱 enum·길이 상한으로 제한한다. 신뢰된 로컬
role/board/layout/epoch/key_id를 대조하고, image offset을 순차 합으로 계산해
header image 수·총길이에 대조한다. uint64 release_sequence를 그대로 보존한다.
required field/unknown field/중복 target/key, 잘못된 native signature 형식,
ABI 범위와 조합·config snapshot의 내부 정합성도 거부 경로로 시험했다.
새 범용 tree/framework/암호 구현 없이 기존 bounded parser와 provider를 재사용했다.

검증 결과:

- Windows 고정 Clang23/CMake4.4.3/Ninja1.13.2에서 strict C99 build 통과.
- `ctest --preset host-debug --output-on-failure`, `host-release`: 각각127/127.
- `python -B tests/ota/test_manifest.py build/host-debug/canview-ota-manifest-probe.exe`:
  서명 mock을 사용한 구조/출력 교차1422건. NULL/크기/identity/실패 출력0과 callback
  별도 out 재진입·provider 실패도 C probe에서 실행한다.
- 같은 script에 `build/host-debug/canview-ota-envelope-probe.exe --crypto`:
  Cryptography48→Windows CNG 실제 P256 서명 교차1425건. 개인키는 메모리에서만 생성했다.
- WSL Clang21의 현재 C source에 ASan/UBSan·coverage instrumentation을 함께 적용하고
  같은 portable 교차1422건 통과. manifest.c 함수12/12, 행304/313(97.12%),
  분기169/184(91.85%). profile은 새 `mktemp -d`에서 실행별로 생성·merge해 이전
  run을 섞지 않았다. ignored 결과는 `build/ota-manifest-sanitize`,
  `build/ota-manifest.profdata`다. 전체 OTA coverage gate 완료는 아니다.
- Arm GNU15.3.rel1 `-mcpu=cortex-m4 -mthumb -ffreestanding -fstack-usage` object
  compile 통과. `build/ota-manifest-arm.su`의 public 함수 frame864B/helper16~64B는
  crypto 포함 전체 call-chain stack 또는 target ELF/MAP/BIN 완료의 증거가 아니다.
- 직전 commit da63535의 CI34726660432는6/6 success. 이후 source와 별개이며 해당
  artifact/hash를 이번 세션에서 재감사했다고 주장하지 않는다.

ABI 회귀 추가 직후 재빌드 전 executable로 실행한 두 교차 시험은 old code가 ABI
범위 밖 값을 수락해 실패했다. 현재 source를 재빌드한 뒤 두 교차 시험과 전체
Debug/Release를 다시 실행해 통과했다. 테스트 기대값이나 validator를 완화하지 않았다.
합성 T103 fixture의 source digest만
`1217e49b4b47a40731e8ba7fc82072bc72e0bf6a89ec9f8a2f244a26279b35da`로 갱신했다.

문서 스킬의 책임/수명 설명을 OTA README에 반영했다. resume는 오래된 설치·WSL
차단 설명과 시간순 상세 이력을 제거하고 현재 상태/다음 작업/debt/안전 경계로
줄였다. 과거 journal·review·ADR 원본은 수정/삭제하지 않았다.

현재 manifest는 미배포 내부 후보이며 정식 schema/CLI, 실제 실행중/후보 ABI 조합·
requires/version floor, image 본문 hash/native 서명과 protected metadata,
streaming·target 연결·최종 독립 2인 리뷰는 남아 있다. CBOR checkpoint A/B를
새 코드의 리뷰로 대체하지 않는다. PR #35는 Draft이며 T-007은 IN_PROGRESS,
physical/HIL은 NOT_RUN, 차량 CAN TX는 NO-GO다.

## 2026-09-13 (codex, 실제 서명 prefix 교차 시험)

작은 header+CBOR+64B 서명 prefix와 순차 image 조립을 연결했다. 자체 암호
알고리즘을 만들지 않고 Cryptography48.0.0 및 Windows CNG P256/SHA-256을
사용한다. key는 시험 실행 메모리에서만 생성하고 출력/파일/장치/Git에 쓰지 않았다.
실제 signature/prefix230건에는 wrong key/invalid point, signature 각 byte 변이,
manifest 변이, 유효 서명이 붙은 잘못된 CBOR, 전체 prefix 절단·최대 길이가 있다.
조립기의 잘못된 이미지/서명 길이와 signer가 입력 list를 바꾸는 경우도 검사했다.

`tools/requirements-ota.lock`은 Windows x64/CPython3.14용 실제 PyPI wheel
세 개의 SHA-256을 고정한다. 새 ignored venv에 `--no-index --find-links
build/ota-wheels --only-binary=:all: --require-hashes`로 설치하고230건을 재실행했다.
전체 Debug125/125(26.17초), Release125/125(21.63초), WSL Clang21의 portable
envelope 경계 ASan/UBSan, Cortex-M4 freestanding compile이 통과했다. Arm
envelope 단일 frame64B/helper16B는 전체 crypto call-chain/target evidence가 아니다.
Windows CNG dll 관찰 버전은10.0.26100.8875다. Windows CI에도 같은 lock을 설치한다.

합성 source digest는 `1d1b8d52deff4ed54d4784bce898f5dfd7f1304bb93ca74d5d56f8cbe20e2635`다.
앞선 checkpoint6d83962의 독립 A/B 정적 리뷰는 finding0/PASS로 원문 보존했다.
A 원문의 절대 checkout link 때문에 최초 문서 검사1건이 실패했다. 원문을 바꾸거나
validator를 완화하지 않고 보고서 전체를4-backtick 원문 인용으로 감쌌고
327문서/1348target 오류0으로 재검증했다. 이후 추가된 envelope 코드에는 앞선
리뷰 verdict를 적용하지 않는다. 전체 task의 최종 독립 리뷰는 별도 필요하다.

staged `git diff --check`는 B 원문의 Markdown hard-break 공백4행을 보고했다.
반환 원문과 보존 본문을 직접 대조해 동일함을 확인했고 원문 공백은 유지했다.
해당 원본 파일만 제외한 staged diff 검사는 오류0이다. 코드 검사나 전역 Git
설정은 완화하지 않았으며 이4건을 전체 diff 오류0으로 보고하지 않는다.

현재 검사 성공은 prefix의 구조와 manifest 서명만 뜻한다. unsigned header의
declared image/total은 서명된 manifest 필드와 아직 대조하지 않으므로 설치 정보가
아니다. role/board/layout/epoch/key_id/호환성·native image 자체 검증·streaming과
정식 packager CLI/golden/target 연결이 남아 있다. Flash erase/PREPARED 권한,
physical/HIL NOT_RUN과 차량 TX NO-GO는 변하지 않았다.

## 2026-09-13 (codex, 단순화 원칙과 T-007 CBOR 문서 검사)

사용자가 OTA container의 필요성을 먼저 설명하고 전체적으로 간단한 방법을
사용하라고 요청했다. AGENTS에 가장 단순한 구현·기존 SDK 재사용·실제 사용처
없는 범용화 금지·복잡성 도입 전 대안 설명을 기록했다. 안전/검증 gate는 유지한다.
T-007은 작은 manifest+순차 image와 합성 파일 생성→C 검증 연결을 다음 작업으로
두며, 새로운 범용 package framework나 자체 암호 알고리즘을 만들지 않는다.

중단 전 CBOR 문서 검사 변경을 보존하고 정수 key 정렬·UTF-8·depth8·item2048·
16KiB 한도, 모든 첫 byte·prefix·고정 seed 변이·Python 순환 입력 회귀를 보강했다.
`ctest --preset host-debug --output-on-failure`는123/123(26.03초), Release는
123/123(21.67초)이다. `. F:/dev/canview-wt/t104-stm32-uart-control/tools/environment/foundation-windows.ps1`
로 설치된 pinned 도구만 재사용하고 현재 source를 빌드했다. focused Python/C
11,989건과 WSL Clang ASan/UBSan probe·C test가 통과했다. Arm GCC의 Cortex-M4
freestanding object compile에서 document validator frame216B, UTF-8 helper40B,
key helper16B를 관찰했다. 이는 전체 target binary/실측 call-chain evidence가 아니다.

합성 T103 fixture source digest는 `a3a72738db64375a554557cbc819fbd61cdf4725b97ca6ad22497c8bac7b6810`
이다. `validate_document_links.py`(324문서/1343target 오류0), `validate_plan.py`
(49task 오류0), `git diff --check`를 실행했다. Git LF→CRLF 안내는 target compiler
warning과 구분한다. 기존 head490d2f8 CI34338457956은6job success로 확인했으나
이번 변경의 CI/target/review evidence를 대신하지 않는다. physical/HIL NOT_RUN,
vehicle TX NO-GO와 issue34 OPEN을 유지한다.

## 2026-09-09 (codex, T-007 CBOR head 첫 C99 구현)

Draft PR #35에서 heap·SDK·writer 권한 없는 최대 9-byte CBOR head decoder와
unsigned 64-bit/잘린 prefix/비최소 encoding/major type/reserve 경계 회귀를 추가했다.
새 worktree의 중복 toolchain 다운로드는 중단하고 이미 설치·검증한 동일 버전의
Windows 도구로 소스를 실제 빌드했다. Host Debug 121/121(16.88초), Release
121/121(17.38초), WSL Clang 21.1.8 ASan/UBSan focused 시험이 통과했다. Arm GNU
15.3.rel1 Cortex-M4 freestanding C99 object(1352 B)와 단일 stack frame 72 B를
확인했다. 이는 전체 target binary·OTA 설치 또는 physical 증거가 아니다.

Focused llvm-cov는 PowerShell의 unquoted profile 인자로 첫 report 조회가 실패했다.
같은 생성 profile을 정확히 quote해 조회한 결과 함수1/1·행62/62·분기26/26 모두
100%였다. 최초 명령 실패를 coverage 실패/성공으로 혼동하지 않으며 전체 container
coverage나 CI gate가 완성됐다고 주장하지 않는다.

새 shared source를 포함하는 합성 T103 fixture digest는
`7f8620834513cb2e1e9ac7ea849758a99f7361ca2a70c24dccc6652f57ed1867`로 갱신했다.
과거 capture/서명·review 원문을 바꾸지 않았다. 전체 container/서명·schema·Python
differential·target 연결·2인 적대적 리뷰는 남아 있다. B-12/B-13 clean review
worktree 두 개는 process 부재·main ancestry 확인 후 git worktree remove로 정리했다.
원문/로그는 별도 보존했고 source는 Git에서 복구 가능하다. A debt 및 기존 build
worktree·dirty 기본 checkout은 보존했다.

## 2026-09-09 (codex, PR #33 merge와 T-007 시작)

최종 evidence-only `3ff04b7` CI 34335812873의 6개 job이 모두 성공했다. 다운로드한
manifest의 head/base/run identity, 이미지18/18 bytes·SHA-256, source provenance6/6,
target log21 compiler/linker/CMake warning/error0을 확인했다. Manifest SHA-256은
`1dd10972ccc9ec565f726ac21a58862ea10db704a576b67f9188cf1a421a0514`다. Node20→24
runner 안내는 별도 후속 항목으로 PR에 공개했다. A 면제는 사용자 PR #33 한정이며
원문·P1 확인 debt·P2 defer를 닫지 않았다. 18:55:58 KST `gh pr merge --merge
--match-head-commit`으로 merge했고 `d229772de77a48ae197e2ff1b4e55b6cef9a88ed`가
fetch한 origin/main과 일치하며 candidate가 ancestor임을 확인했다. 이슈 #34 OPEN.

dirty 기본 checkout을 보존하고 `codex/t007-ota-container` 별도 worktree를 만들었다.
선행 T-001 완료와 STM32 boot/core 순서를 근거로 T-007을 선택했다. CBOR primitive
구현부터 시작하며 정식 container/서명/target/review/CI gate는 아직 남아 있다.
physical/HIL·provisioning NOT_RUN, 차량 CAN TX NO-GO를 계속 유지한다.

## 2026-09-09 (codex, T-104 완료 응답 복구와 B closure)

앱 조회에서 비었던 A-10/B-11의 기존 final 응답/작성 원문을 로컬 기록에서 복구했다.
실제 서비스 차단 A-08과 조회 누락을 구분하고 원문을 변경 없이 보존했다. B-11의
과거 타 review 발췌 노출도 숨기지 않았다. B-12는 SDK/mock·문서 P3 두 건 PASS,
B-13은 원 B P1/P2 여섯 건 PASS를 반환했다. A-10 P2 회귀 공백은 owner digitie,
이슈 #34/T-104, 다음 admission 변경·software qualification 전 gate로 defer했다.
PR #33 한정 A 면제만 적용하며 최신 CI/artifact와 merge 확인은 아직 남아 있다.
다음 공용 core 선행 T-007은 merge 확인 뒤 시작하고 물리·차량 gate는 열지 않는다.

## 2026-09-09 (codex, T-104 A 중단 이슈와 사용자 한정 면제)

사용자가 A 중단의 상세 이슈화·skip·merge·다음 단계 진행을 명시했다. GitHub
이슈 #34를 만들고 A-08의 service JSON·22640 ms 실패·원 P1/P2 재확인 미완료,
수정 evidence와 후속 owner/gate를 기록했다. A의 verdict나 원 finding 심각도는
변경하지 않았고 PR #33 한정 예외와 일반 runbook의 충돌을 명시했다. 코드/SDK/
하드웨어 오류나 사용량 초과라고 추측하지 않았으며 서비스 차단을 우회하지 않았다.

B-09 원문을 보존하고 P3 DMAMUX fake 7/8→26/27, vendor LL 독립 C99 assertion,
model 추출 malformed/missing/duplicate unit, 두 worker의 watchdog 문서를 수정했다.
실제 Arm compiler의 RX=7/TX=8 negative probe는 각각 exit 1로 거부됐고 정상은
exit 0이다. host fixture digest는 firmware 문서 변경까지 포함하여 갱신했다.
초기 host 119/120은 raw report의 detached 경로 link 3건 때문이었으며 원문을
fence로 보존해 navigation에서 분리했다. validator 오류 0을 확인했다.

STM32 Debug/Release clean target binary와 54+2 SDK/model 상수, warning/error 0을
재확인했다. 이전 CI 34329023006도 6/6 success, manifest/artifact 18/18·source6/6,
target log21개 diagnostic0을 독립 대조했다. 새 candidate CI와 B 후속 확인은
merge 전에 별도로 완료한다. 물리/HIL은 NOT_RUN, 차량 CAN TX는 NO-GO다.

## 2026-09-09 (codex, T-104 UART review 재수정)

수정 commit `14ea3c9`를 push하고 A-08/B-09 및 최초 P1 reviewer A-10/B-11에
독립 재검토를 요청했다. A-08은 service 보안 제한으로 final report 전에 중단됐다.
service 원문을 보존하고 `INCOMPLETE/BLOCK`으로 기록했으며 제한 우회나 merge를
수행하지 않았다. 다른 실행의 결과를 원 A의 P1 closure로 대체하지 않는다.

`bdc6798`의 A-05/B-07 report를 원문 보존하고 C runtime reset에서 TX DMA를
PRIMASK 안에서 정지한 뒤 이전 completion/error latch를 폐기했다. RX 오류는
유지하며, unread byte와 producer 불명 손실을 분리해 기록한다. time-sync
COMMIT에는 tick 호출 순서와 무관한 1초 경계를 적용했다. HELLO build ID는
GNU linker SHA-1 앞 16 byte를 BSP에서 복사하고 ELF note/symbol/BIN 대조와
잘못된 note·symbol·BIN negative 시험으로 검증한다. SHA-1 ID는 인증이 아니다.

Windows Debug/Release 120/120, STM32 Debug/Release clean target 및 warning/error
scan 0, STM32 coverage, SDK 13/13, Doxygen/Sphinx strict와 TSan pool 1/1을
확인했다. WSL 보충 GCC 실행은 Windows worktree의 `.git` 경로를 해석하지 못해
Python provenance 시험이 실패했다. 확인된 Git directory를 WSL의 `GIT_DIR`와
`GIT_WORK_TREE`로 명시해 같은 HEAD를 검증한 뒤 전체 GCC/sanitizer 각각 120/120을 확인했다.
이 환경 실패를 C firmware 실패나 PASS로 바꿔 기록하지 않는다. main checkout의
사용자 변경과 기존 build directory는 보존했다. reviewer·CI가 닫히기 전 merge하지
않으며 physical/HIL·board flash·차량 TX는 계속 `NOT_RUN`/`NO-GO`다.

## 2026-09-09 (codex, T-103 hostile finding fix와 adapter coverage)

초기 immutable T-103 candidate에 대한 독립 Reviewer A/B raw report는 각각
`CV-HOSTILE-20260909-T103-A-01`과 `CV-HOSTILE-20260909-T103-B-01`이며 둘 다
`BLOCK`이다. 원문은 `docs/reviews/adversarial/evidence/2026-09-09-T-103-reviewer-a.md`
와 `...-reviewer-b.md`에 그대로 보존했다. A는 batch callback reentry, cross-channel
timestamp wrap, PSR/ECR timestamp 오염, IRQ acknowledge, session/owner와 FIFO loss를
지적했고, B는 no-TX evidence parser, timestamp wrap, filter budget, adapter coverage와
bounded parser를 지적했다. 이 report를 PASS로 낮추지 않고 post-fix 재검토를 요구한다.

그 finding을 반영해 module batch를 callback 이후 transactional commit으로 바꾸고,
channel별 timestamp epoch와 status/frame timestamp를 분리했다. IRQ는 RX flag를
FIFO drain 전에 acknowledge하고 FIFO/raw-ring loss를 latch하며, singleton owner와
stop/start session reset을 명시했다. no-TX analyzer는 bounded JSONL/schema/duplicate/
sequence/complete/TX-gate 검증으로 fail-closed하게 고쳤다. module과 CMSIS adapter의
strict C99 fake-register 시험 및 mutation 경계를 추가했다.

source fix candidate `3e13b2ca6e72a3aec5a32a6357285c614bc191f9`에서 T103 focused
CTest 2/2, 전체 Windows CTest 118/118, no-TX helper 6/6, WSL 일반 clone의
ASan/UBSan 전체 CTest 118/118과 독립 coverage function 100%/line≥95%/branch≥90%를
통과했다. FDCAN module coverage는 function 100%/line 99.1%/branch 94.1%, CMSIS
adapter fake-register coverage는 function 100%/line 98.6%/branch 93.2%다.
STM32 Debug/Release target clean build와 warning/error scan 0건도 갱신했다. post-fix
reviewer/CI는 아직 남아 있으며, 실제 board flash, FDCAN electrical/bitrate/IRQ
latency, reset/brownout, analyzer TX-zero와 차량 capture는 장비가 없어 `NOT_RUN`,
차량 CAN TX는 `NO-GO`다.

## 2026-09-08 (codex, T-500 merge closure)

T-500 최종 candidate `ff3121ce04328ff61a73f13492f8be9927f0dc98`의 독립
Reviewer A `CV-HOSTILE-20260908-T500-A-10`과 Reviewer B
`CV-HOSTILE-20260908-T500-B-10` raw report를 보존하고, 두 reviewer의
`PASS` 및 unresolved P0/P1/P2/P3 0건을 통합 report에 기록했다. 초기·중간
BLOCK, invalid candidate와 incomplete service 실행은 PASS로 산정하지 않았다.

PR [#30](https://github.com/digitie/canview/pull/30)을 ready로 전환한 뒤
GitHub Actions `34235313714`의 windows-c99, target-firmware-windows,
Linux GCC/Clang, sanitizer, browser contract 6개 job success를 확인하고
merge했다. merge commit `8f5d97ff924fe7fdb757a3a86a30cde5a80c2a09`와
`origin/main`이 일치하며 ancestor 검증도 통과했다. T-500 focused unit 46/46,
전체 Python 97/97, host 12/12, selected scenario/evidence validator,
compileall, document link와 plan 검사를 다시 확인했다.

g2 read-only rig는 physical backend가 없어 `SKIPPED`이고, 실제 board
flash/HIL·power/reset/brownout·CAN analyzer·차량 bus·provisioning과 차량
CAN TX는 각각 `NOT_RUN`/`NO-GO`로 유지한다. 다음 구현은 T-103 STM32
3채널 FDCAN capture-only C firmware다.

## 2026-09-08 (codex, T-102 merge와 T-500 host harness 시작)

PR #29의 최종 문서 closure head `10716b12a19b7244982d6e1572f1fad81057d348`에서 GitHub Actions `34218499019`의 6개 job 전체 성공을 다시 확인하고, PR #29를 merge commit `50410ba23fcecfa1f28cea837d04a061c201d648`로 `origin/main`에 통합했다. T-102 candidate `1894117`은 source/review/CI closure를 통과했지만 board flash, G1/G2 physical/HIL, UART/FDCAN 계측, Flash root, 차량 CAN과 provisioning은 `NOT_RUN`이며 CAN TX는 `NO-GO`다.

T-103이 요구하는 공용 선행으로 T-500을 `codex/t500-hil-harness`에서 시작했다. `tests/hil/`에 JSON-compatible YAML 1.2 scenario 12개, deterministic host adapter, seed·firmware/harness source digest·scenario digest report, monotonic JSONL offset, capture-only TX zero/allow-list/budget/first-violation analyzer와 fail-closed lab rig 계약을 추가했다. malformed input·중복 key·tampered offset도 fail-closed로 거부한다. host subset은 실제 HIL이 아니며, 연결되지 않은 rig는 `SKIPPED/BLOCKED`로만 출력한다.

## 2026-09-08 (codex, T-102 review closure 준비)

T-102 최종 candidate는 18941170ef475777c62db2f1471b74f937c807ea이다. 346257b에서 발견된 C preprocessing phase-order P2를 line splice 후 comment removal 순서로 수정하고, 직접·alias FDCAN member와 mode directive의 LF/CRLF split-comment 조합 및 reversed-order mutation 회귀시험을 추가했다. 최종 immutable reviewer A CV-HOSTILE-20260908-T102-POSTFIX-A-005와 B CV-HOSTILE-20260908-T102-POSTFIX-B-005는 각각 PASS, unresolved P0/P1/P2/P3 0건을 반환했다. 원문은 [통합 report](reviews/adversarial/2026-09-08-T-102.md)와 [A raw](reviews/adversarial/evidence/2026-09-08-T-102-postfix-reviewer-a-r4.md), [B raw](reviews/adversarial/evidence/2026-09-08-T-102-postfix-reviewer-b-r4.md)에 보존했다.

최종 소스 수정 뒤 Host Debug/Release 116/116, Clang ASan/UBSan 116/116, TSan pool 1/1, coverage 116/116 및 9/9 subset, STM32 core gate 6/6, generator/sdkconfig/plan/link, Doxygen/Sphinx strict, STM32 Debug/Release clean-first ELF/MAP/BIN/HEX와 warning/error 0을 다시 확인했다. GitHub Actions `34216963785`의 Linux sanitizer/portability 2종, Windows C99, browser contract, target firmware 총 6개 job과 target artifact/warning gate가 PASS했다. PR #29 merge closure가 남아 있으며, 실제 board flash/HIL·ST-LINK/serial·clock/reset/rail/brownout·UART/FDCAN 계측·Flash root 배치·차량 CAN·provisioning은 NOT_RUN, 차량 CAN TX는 NO-GO다.

## 2026-09-08 (codex, T-102 hostile review finding fix)

T-102의 immutable candidate를 독립 검토한 A(`CV-HOSTILE-20260908-T102-A-002`)와 B(`CV-HOSTILE-20260908-T102-B-002`)의 원문을 evidence에 보존했다. 두 report의 reset reason 직렬화 P1, 초기화 전 HardFault 무한 대기 P1, health fault latch·module/BSP 경계·CAPTURE_ONLY target-wide 강제·negative test·CubeG4 provenance·fixed-width 정수 finding을 반영했다. diagnostic record는 version 2와 offset 5 reset-reason byte를 사용하고, HardFault는 IWDG 준비 여부와 무관하게 system reset을 먼저 요청한다. build metadata는 BSP provider target으로 분리했으며 target forced include, link anchor, FDCAN TX source/symbol gate와 실 compiler override fixture를 추가했다.

수정 후 pinned Windows Host Debug/Release CTest는 각각 116/116, STM32 function100%/line≥95%/branch≥90% coverage, STM32 Debug/Release target ELF/MAP/BIN/HEX와 post-build gate는 warning/error 0으로 통과했다. post-fix candidate의 fresh reviewer 재검토와 CI는 아직 남아 있고 physical board/HIL·clock/reset/rail/brownout·UART/FDCAN·Flash root·차량 CAN evidence는 `NOT_RUN`, 차량 CAN TX는 `NO-GO`다.

## 2026-09-08 (codex, T-102 STM32 C source와 target 검증)

`codex/t102-stm32-platform`에서 사용자의 G1 이전 firmware 구현 허용과 C 작성 지시에 따라 T-102 source를 진행했다. STM32 `CAPTURE_ONLY` build contract, generated hardware digest와 build metadata, RCC reset reason, static stack watermark, protected service policy skeleton, little-endian diagnostic record를 추가하고 기존 safe GPIO·HSE/PLL·TIM2/SysTick·IWDG·cooperative scheduler와 연결했다. stack watermark의 host register-model 경계 및 scan timeout 시험을 보강했으며, target linker는 실제 reserved stack window를 `__stack_limit`으로 export한다. FDCAN/UART 송수신과 차량 CAN TX는 열지 않았다.

검증은 pinned Windows Clang 23.1.0/CMake 4.4.3/Ninja 1.13.2와 Arm GNU 15.3.Rel1/STM32CubeG4 1.6.3에서 수행했다. Host Debug/Release 전체 CTest는 각각 115/115, 공용·ESP32·STM32 coverage, board generator/config/plan/link 검사는 PASS였다. Doxygen 1.18.0 API 32개와 Sphinx strict도 PASS였고, STM32 Debug/Release ELF/MAP/BIN/HEX 및 post-build memory·stack·symbol gate가 warning/error 0으로 통과했다. 실제 board flash/HIL, clock/reset/rail/brownout 계측, UART/FDCAN, Flash root 배치와 차량 evidence는 장비·선행 조건이 없어 `NOT_RUN`이다. 다음은 immutable candidate commit, 독립 reviewer A/B, Draft PR/CI closure다.
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

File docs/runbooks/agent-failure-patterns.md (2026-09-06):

# CANView 반복 실패 패턴과 복구

| 증상 | 먼저 확인할 것 | 복구 |
|---|---|---|
| CMake가 target을 찾지 못함 | CMake version, Ninja, STM32CubeG4_ROOT | `docs/development/windows.md` 기준으로 도구와 pinned dependency 확인 |
| STM32 build가 헤더를 찾지 못함 | CubeG4 경로와 device package | 환경변수만 고치고 성공 처리하지 말고 미실행 gate 기록 |
| ESP-IDF target 설정이 Controller와 섞임 | esp32s3, Flash/PSRAM, sdkconfig | Controller와 Communicator 설정을 별도 유지 |
| KiCad ERC가 power pin을 경고함 | 실제 symbol pin, PWR_FLAG, rail ownership | 데이터시트·symbol library 대조 후 waiver 근거 작성 |
| netlist와 BOM이 달라짐 | schematic revision, MPN, DNP/variant field | schematic에서 BOM을 재생성하고 consistency script 실행 |
| CAN3가 이상 동작함 | MAX3055 bus type/bitrate/WAKE/ERR | 확인 전 channel disabled, CAPTURE_ONLY 유지 |
| UART frame이 간헐적으로 깨짐 | 4 Mbps timing, RTS/CTS polarity, DMA lifetime | logic analyzer와 malformed-frame test를 함께 확인 |
| CAN 신호가 그럴듯하지만 불확실함 | DBC commit, capture provenance, freshness | candidate/evidence로 유지하고 정상 UI·safety 승격 금지 |
| UI가 오래된 값을 표시함 | signal age, boot epoch, pending 상태 | stale 표시와 fail-safe default를 적용 |
| protocol 변경 후 일부 장치만 동작함 | schema version, generated header, golden vector | 수동 header 수정 대신 generator와 모든 codec을 함께 갱신 |
| queue가 가득 참 | priority별 quota와 backpressure | raw observer부터 drop, safety/control은 BUSY/fail-closed |
| branch merge 후 문서 링크가 깨짐 | docs/tasks.md 이동에 따른 상대 경로 | Markdown local-link 검사와 root README 링크를 함께 확인 |
| Windows와 WSL에서 결과가 다름 | `F:/...`와 `/mnt/f/...` 경로·도구·개행 차이 | Windows checkout을 정본으로 삼고 표준 검증은 Windows native 도구로 재실행 |
| 임시 worktree가 남아 있음 | merge/abandon 후 cleanup 누락 | 활성 프로세스와 미커밋 변경을 확인한 뒤 `git worktree remove`와 `git worktree prune` 실행 |

같은 실패가 반복되면 새 task로 분리하고, 원인·재현 명령·복구·남은 위험을 이 문서 또는 task에 추가한다.

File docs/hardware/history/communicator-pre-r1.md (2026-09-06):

# 기록: R1 이전 Communicator 설계 입력

이 문서는 과거 검토 이력이며 현재 회로 지시가 아니다. USB data-only, PGOOD 직결, 과거 TCAN 핀과 미정 gate 내용을 구현에 사용하지 않는다. 현재 정본은 [R1 상세 회로](../r1/README.md)다.

이 문서는 [문서 지도](../../README.md)에 속한 Communicator 전원·CAN PHY·MCU pinmap의 회로 입력 요구사항이다. 시스템 권한 경계는 [시스템 아키텍처](../../architecture/system.md), 제작 산출물은 T-100이 정본이다.

## 1. 문서 상태와 안전 목표

이 문서는 `Communicator`의 전원, 회로, 핀 할당과 부팅 안전 상태를 정의하는 회로 입력 요구사항이다. 아직 승인 KiCad 회로도·BOM·ERC·firmware 독립 hard TX gate가 없으므로 제작 정본이나 차량 송신 승인으로 사용하지 않는다. 해당 산출물은 [T-100](../../tasks/T-100-communicator-schematic.md)에서 확정한다. AEC/PPAP 적합성 판단은 범위 밖이며, 다음 전기적 목표를 우선한다.

- MCU가 무전원·reset·brownout·watchdog reset·firmware 정지 상태여도 CAN bus를 dominant로 붙잡지 않는다.
- 5 V가 유효해지기 전에 3.3 V MCU rail을 켜지 않고, 3.3 V가 안정된 뒤 두 MCU의 reset을 해제한다.
- CAN PHY는 clock, bitrate, filter와 interrupt가 모두 준비된 뒤에만 normal mode로 전환한다.
- 입력 과전압·역극성·전원 강하 시 PHY는 standby 또는 high-impedance 상태로 수렴한다.

IC 사양과 핀 multiplexing은 제조사 데이터시트에서 확인했지만, 보호소자 정격·MOSFET SOA·thermal·signal integrity는 회로도/ERC와 prototype 시험 전까지 확정값이 아니다.

## 2. 확정 부품과 역할

| 블록 | 적용 부품 | 확인된 주요 사양 | 역할 |
|---|---|---|---|
| 무선 MCU | `ESP32-S3-MINI-1-N4R2` | dual-core LX7 최대 240 MHz, 4 MB Flash, 2 MB PSRAM, 3.0–3.6 V | ESP-NOW, pairing, 설정, 무선/UART queue |
| CAN MCU | `STM32G474CEU6` | Cortex-M4F 170 MHz, Flash 512 KB, SRAM 128 KB, FDCAN 3개, UFQFPN48 | CAN timestamp/filter, UART, 최종 TX safety gate |
| 고속 CAN PHY | `TCAN1046AV-Q1` | dual channel, ISO 11898-2:2016, CAN FD 최대 8 Mbps, VCC 5 V, VIO 3.3 V | CAN 1·2 물리계층 |
| fault-tolerant CAN PHY | `MAX3055ASD+` | 125 kbps, ±80 V bus fault protection, VCC 5 V, 별도 BATT | CAN 3 물리계층 |
| 입력 보호 controller | `LM74800-Q1` | 3–65 V, common-source back-to-back N-FET 구동, reverse blocking, OV disconnect | 역극성·역전류·과전압 차단 |
| 5 V buck-boost | `MAX20040B` 계열 | 기동 후 2–36 V, 최대 1.2 A, open-drain PGOOD | PHY 5 V와 3.3 V 전단 |
| 3.3 V buck | `TPS629210` | 3–17 V 입력, 최대 1 A | STM32·ESP32·TCAN VIO 전원 |
| 3.3 V supervisor | `TLV803EA30DPWR` | 3.08 V nominal threshold, 200 ms nominal delay, open-drain active-low, X2SON | STM32 NRST·ESP CHIP_PU 공통 감시 |
| CAN clock | HSE crystal | STM32 지원 범위 4–48 MHz | FDCAN kernel clock 정확도 확보 |

`ESP32-S3-PICO-1`은 사용하지 않는다. `ESP32-S3-MINI-1-N4R2`의 `GPIO26`은 내부 PSRAM용이므로 외부에 배선하지 않는다. `GPIO19/20`은 native USB, `GPIO0/3/45/46`은 strapping 영향 때문에 UART와 제어선에서 제외한다.

`MAX3055`는 고속 CAN transceiver가 아니다. CAN 3의 실제 차량 bus가 125 kbps fault-tolerant 방식인지 확인되지 않으면 PHY를 enable하지 않는다.

현재 제안 pinmap에는 firmware와 독립적인 차량 송신 차단 net이 없다. 승인 회로에는 세 TXD와 PHY 사이의 tri-state gate, TXD output별 pull-up, default-disabled `/OE`, 물리 `TX_ARM`, rail-good와 100 ms 이하 외부 watchdog/monostable을 추가해야 한다. gate가 닫혀도 RX는 유지하고 상태를 별도 GPIO로 sense한다. exact logic MPN과 sense GPIO는 회로/ERC/SI 검토에서 정하며, 이 gate가 없는 revision은 `CAPTURE_ONLY`로만 사용한다.

## 3. 전원과 reset

### 3.1 전원 tree

```text
Vehicle BATT 12 V
        │
      Fuse
        │
  SMBJ36CA + 입력 EMI/ESD network
        │
  LM74800-Q1 + common-source back-to-back N-FET ×2
  OV rising cutoff nominal 약 31.9 V
        │
   PROTECTED_VBAT ───────────────────────────> MAX3055 BATT
        │
     MAX20040B
        │  5V_PHY
        ├────────────────────────────────────> TCAN1046AV VCC
        ├────────────────────────────────────> MAX3055 VCC
        │
        └─ PGOOD(open drain, 10 kΩ pull-up to BIAS)
                         │
                         └────────────────────> TPS629210 EN
                                                   │
                                              TPS629210
                                                   │  3V3
                     ┌─────────────────────────────┼───────────────┐
                     │                             │               │
               STM32 VDD/VDDA               ESP32 3V3       TCAN VIO
                     │                             │
                     └────────── SYS_RESET_N ──────┘
                                      ▲
                         TLV803EA30DPWR RESET
                         10 kΩ pull-up to 3V3
```

MAX20040 PGOOD은 출력이 regulation 값의 약 96%를 넘을 때 해제되고 약 93% 아래에서 다시 low가 된다. 데이터시트 기준으로 PGOOD을 BIAS에 10 kΩ로 pull-up하고 `TPS629210 EN`에 연결한다. TPS629210의 EN 내부 pull-down은 PGOOD이 유효하지 않은 구간에 3.3 V rail을 off로 수렴시킨다.

MAX20040B의 제안 주문형식은 `MAX20040BATPA/VY+`이고 FB를 VCC에 연결해 5 V fixed output으로 쓴다. TPS629210은 VSET을 open 또는 249 kΩ 이상으로 두는 3.3 V 설정을 사용한다. compensation, switching frequency, inductor와 capacitor는 두 regulator의 공식 design procedure로 계산한다.

MAX20040은 최초 기동에 `IN > 3.5 V`가 필요하며 기동 완료 뒤에만 약 2 V까지 동작 범위가 확장된다. 따라서 배터리가 이미 2–3 V인 상태에서 새 부팅은 보장하지 않는다. 이 구간에서는 reset 유지와 PHY 비활성 상태가 정상 동작이다.

TPS629210의 1 A 한계는 ESP32 RF burst, STM32, TCAN VIO를 모두 포함한다. 회로 확정 전에 3.3 V peak current, startup inrush, 출력 capacitor, junction temperature를 계산하고 Wi-Fi burst 중 rail droop을 계측한다. MAX20040의 1.2 A 한계에도 3.3 V 변환 입력전류와 세 PHY의 worst-case 전류를 포함한다.

### 3.1.1 전원 상태기계

첫 vehicle-capable revision은 명시적 `ACC/KL15`로 기동하고 CAN wake를 사용하지 않는다. ACC가 없는 harness는 bench/capture-only로만 지원한다.

| 상태 | 조건 | rail | CAN TX |
|---|---|---|---|
| `OFF` | ACC low, bench enable 없음 | LM74800/ACC front end만, 5V/3V3 off | hard gate off |
| `STARTING` | ACC rising | MAX20040 on, PGOOD 전 3V3 off | hard gate off |
| `RUN_RX` | 5V PGOOD, 3V3 supervisor 해제 | MCU와 PHY 수신 준비 | hard gate off |
| `RUN_TX_ARMED` | 승인 build+물리 TX_ARM+외부 watchdog+rail-good | 모두 on | generated executor만 허용 |
| `SHUTDOWN` | ACC falling 또는 UV/fault | TX permit을 먼저 비동기 제거한 뒤 rail off | 즉시 gate off |
| `SERVICE` | current-limited bench 12V | 차량과 같은 보호 경로 | 기본 capture-only |

`POWER_EN`은 firmware가 아니라 protected ACC input/bench enable 회로가 MAX20040 EN을 구동한다. ACC loss와 PROTECTED_VBAT UV는 rail이 내려가기 전에 hard TX permit과 MAX3055 EN을 hardware로 제거한다. PGOOD pull-up은 generic `BIAS`가 아니라 회로도에서 실제 `MAX20040_BIAS` package pin으로 이름·전압을 고정한다. OFF 25 °C parked current 목표는 1 mA 이하고 72시간·온도별로 측정한다.

native USB는 data-only로 고정해 target rail을 공급하지 않는다. SWD header의 VTref는 target에서 probe로 나가는 sense이고 전원 입력 pin을 두지 않는다. service 전원은 별도 current-limited 12 V connector로 동일 보호 경로에 넣는다. BATT/ACC/USB/SWD 투입·제거 순서 전체에서 phantom powering과 GPIO injection을 검증한다.

MAX3055 BATT는 protected VBAT에 남으므로 PROTECTED_VBAT UV comparator, 5V PGOOD와 hard TX permit을 CAN3 EN/TXD 차단 조건에 포함한다. WAKE input은 CAN wake 미사용 상태의 데이터시트 권장 bias로 고정하고 INH output은 명시적 no-connect/test point로 처리한다. threshold와 hysteresis는 MAX20040 start/hold, MAX3055 BATT/VCC 영역과 cold-crank 목표를 worst-case로 계산해 회로 산출물에 기록한다.

### 3.2 입력 보호와 OV divider

LM74800 OV divider의 제안값은 다음과 같다.

```text
LM74800_VIN ───── 100 kΩ ──┬── LM74800 OV
                            │
                          4.02 kΩ
                            │
                           GND
```

`VOVR = 1.233 V` nominal을 적용하면 rising cutoff는 `1.233 × (100 kΩ + 4.02 kΩ) / 4.02 kΩ ≈ 31.9 V`다. falling 기준 약 1.13 V를 적용한 nominal 재연결점은 약 29.2 V다. 합계 104.02 kΩ는 OV leakage 오차를 줄이기 위한 제조사 권고 `120 kΩ 미만`을 만족한다. 실제 cutoff 범위는 reference·저항 공차와 온도를 포함해 worst-case로 다시 계산한다.

`SMBJ36CA`는 TI reference 회로에서 ISO 7637 Pulse 1의 음전압을 LM74800의 −65 V absolute maximum 안으로 제한하는 역할이다. 양의 load dump 에너지를 이 TVS 하나가 모두 흡수한다고 가정하지 않는다. 양의 과전압은 OV 차단으로 downstream을 분리하며, 두 N-FET의 `VDS`, avalanche/SOA, gate 보호, TVS pulse rating과 PCB 열을 대상 pulse profile로 검증한다.

입력 connector에서 fuse, TVS, FET power loop를 짧게 배치한다. `PROTECTED_VBAT` 이후에 MAX20040과 MAX3055 BATT를 분기하며, 역급전 경로와 ignition-off 대기전류를 별도 점검한다.

ESP32 native USB service port의 VBUS와 vehicle power가 동시에 들어오는 상태를 별도 power case로 다룬다. USB VBUS가 5V_PHY/3V3/차량 rail을 역급전하거나 차량 rail이 USB host로 흘러가지 않도록 power-path 또는 data-only service 정책을 회로도에 명시하고 네 rail 조합을 prototype에서 측정한다.

### 3.3 3.3 V supervisor와 공통 reset

`TLV803EA30DPWR`의 부품명은 다음 의미다.

- `TLV803E`: active-low open-drain reset
- `A`: 200 ms nominal delay
- `30`: 3.08 V nominal falling threshold
- `DPW`: 0.8 mm × 0.8 mm X2SON-5

RESET에는 3.3 V로 10 kΩ pull-up을 두고 `STM32 NRST`와 `ESP32 CHIP_PU`를 묶은 `SYS_RESET_N`을 구동한다. VDD에는 IC 가까이 100 nF를 둔다. X2SON의 `MR`은 내부 pull-up을 사용하되 service reset test point를 제공한다. 공통선이므로 SWD reset도 ESP32를 함께 reset한다. 독립 reset이 필요하다는 시험 결과가 나오면 open-drain buffer로 두 branch를 분리한다.

ESP32는 3.3 V가 안정된 뒤 CHIP_PU가 high가 되기까지 최소 50 µs가 필요하다. 200 ms supervisor가 이 조건을 충족하므로 supervisor 출력에 큰 RC capacitor를 중복 장착하지 않는다. 정확한 reset delay 보증 범위와 threshold 공차는 BOM 확정 시 최신 데이터시트로 재확인한다.

## 4. CAN 물리계층 회로

### 4.1 CAN 1·2: TCAN1046AV-Q1

두 채널의 reset 기본 상태는 동일하다.

```text
3V3 ── 10 kΩ ──┬── TXD1 <──────── STM PA12 / FDCAN1_TX
                │
                └── STB1 <──────── STM PA4

3V3 ── 10 kΩ ──┬── TXD2 <──────── STM PB13 / FDCAN2_TX
                │
                └── STB2 <──────── STM PA5

TCAN RXD1 ────────────────────────> STM PA11 / FDCAN1_RX
TCAN RXD2 ────────────────────────> STM PB12 / FDCAN2_RX
```

실제 회로에서는 TXD1, STB1, TXD2, STB2 각각에 독립 10 kΩ pull-up을 둔다. MCU가 Hi-Z일 때 `TXD=HIGH`는 recessive, `STB=HIGH`는 standby이므로 부팅·reset 중 두 bus를 dominant로 만들지 않는다. TCAN 내부 bias와 undervoltage 보호가 있어도 외부 저항을 reset 상태의 정본으로 사용한다.

TCAN1046AV에는 VCC 5 V, VIO 3.3 V를 공급하고 각 supply pin 가까이에 데이터시트 권장 decoupling을 둔다. VCC/VIO undervoltage 또는 무전원 상태에서 bus와 logic pin이 high-impedance가 되는 조건도 power-sequence 시험에 포함한다.

| TCAN pin | 신호 | 연결 |
|---:|---|---|
| 1 | TXD1 | STM PA12, 10 kΩ pull-up |
| 2 | GND1 | ground plane |
| 3 | VCC | 5V_PHY |
| 4 | RXD1 | STM PA11 |
| 5 | VIO | 3V3 |
| 6 | TXD2 | STM PB13, 10 kΩ pull-up |
| 7 | GND2 | ground plane |
| 8 | RXD2 | STM PB12 |
| 9 | STB2 | STM PA5, 10 kΩ pull-up |
| 10 | CANL2 | CAN 2 protection·connector |
| 11 | CANH2 | CAN 2 protection·connector |
| 12 | CANL1 | CAN 1 protection·connector |
| 13 | CANH1 | CAN 1 protection·connector |
| 14 | STB1 | STM PA4, 10 kΩ pull-up |

차량 connector 쪽 회로 기준은 다음과 같다.

- connector 바로 뒤에 CAN FD data rate에 맞는 저용량 TVS를 배치한다.
- common-mode choke는 footprint만 두고 기본 `DNP`로 시작한다.
- 차량 bus의 중간 stub이면 종단 부품은 모두 `DNP`다.
- 이 보드가 검증된 endpoint일 때만 `60.4 Ω + 60.4 Ω` split termination과 center tap–GND `4.7 nF` footprint를 장착한다.
- termination 장착 여부는 CAN 1과 CAN 2에서 각각 독립 관리한다.

### 4.2 CAN 3: MAX3055

MAX3055는 STB를 high로 고정하고 EN 하나만 STM32가 제어한다.

```text
5V_PHY ── 10 kΩ ───────────────────────────> MAX3055 STB

STM PA6 / CAN3_EN ─────────────────────────> MAX3055 EN
                │
              10 kΩ
                │
               GND

3V3 ── 10 kΩ ──┬── MAX3055 TXD <────────── STM PA15 / FDCAN3_TX

MAX3055 RXD ── 5.1 kΩ ──┬────────────────> STM PA8 / FDCAN3_RX
                         │
                       10 kΩ
                         │
                        GND

MAX3055 ERR ── 5.1 kΩ ──┬────────────────> STM PB14 / CAN3_ERR
                         │
                       10 kΩ
                         │
                        GND
```

MAX3055 mode table에서 `STB=1, EN=0`은 Power-On Standby, `STB=1, EN=1`은 Normal Operating이다. reset 중 PA6은 Hi-Z이고 외부 10 kΩ pull-down이 EN을 low로 유지한다. firmware가 준비된 뒤 PA6만 high로 전환한다. TXD pull-up은 MCU reset 시 recessive를 보장하며, PA15 자체의 reset pull-up 방향과도 일치한다.

MAX3055 RXD/ERR high는 `VCC − 0.5 V`에서 VCC까지 올라갈 수 있다. PA8/PB14가 5 V tolerant이더라도 5.1 kΩ/10 kΩ divider를 기본 장착해 약 3.3 V로 낮추고 STM32 무전원 시 injection을 제한한다. 이 값은 125 kbps에서 검증하되, 입력 capacitance·threshold·상승시간과 STM32 전원 off injection current를 worst-case로 계산한다. CAN3를 실장·enable하는 variant에서는 ERR과 divider를 mandatory로 둔다. MAX3055 전체가 DNP인 variant에서만 함께 DNP 처리한다.

| MAX pin | 신호 | 연결·처리 |
|---:|---|---|
| 1 | INH | CAN wake 미사용 output, 명시적 NC + test point |
| 2 | TXD | STM PA15, 10 kΩ pull-up to 3V3 |
| 3 | RXD | 5.1 kΩ/10 kΩ divider를 거쳐 STM PA8 |
| 4 | ERR | divider를 거쳐 STM PB14; CAN3 실장 시 mandatory |
| 5 | STB | 10 kΩ pull-up to 5V_PHY, MCU에 연결하지 않음 |
| 6 | EN | STM PA6, 10 kΩ pull-down |
| 7 | WAKE | 데이터시트 권장 inactive bias·protection, floating 금지 |
| 8 | RTH | CANH distributed termination footprint |
| 9 | RTL | CANL distributed termination footprint |
| 10 | VCC | 5V_PHY, local bypass |
| 11 | CANH | CAN 3 protection·connector |
| 12 | CANL | CAN 3 protection·connector |
| 13 | GND | ground plane |
| 14 | BATT | PROTECTED_VBAT, local bypass |

FT-CAN 종단은 고속 CAN과 다르다. CANH–CANL 사이에 120 Ω을 넣지 않는다. RTH와 RTL 각각의 distributed termination footprint를 두고 기본 `DNP`로 시작한다. MAX3055 데이터시트 기준 각 node 저항은 500 Ω 미만으로 내리지 않으며, network의 CANH와 CANL 각각 total target은 100 Ω이다. 소규모·짧은 차량 network에서는 합성값이 더 커도 동작할 수 있으므로 실차 기존 종단을 측정한 뒤 값을 정한다.

## 5. STM32G474CEU6 UFQFPN48 최종 제안 핀맵

당시 기계 판독용 제안은 [이전 pin proposal](../../../hardware/communicator/history/pinmap-pre-r1.csv)에 보존한다. 현재 정본이 아니며 오류를 포함하므로 구현에 사용하지 않는다.

| package pin | MCU pin | AF/모드 | 기능 | 연결·reset 처리 |
|---:|---|---|---|---|
| 5 | `PF0` | `OSC_IN` | HSE input | 4–48 MHz crystal network |
| 6 | `PF1` | `OSC_OUT` | HSE output | crystal network |
| 7 | `PG10-NRST` | reset | `SYS_RESET_N` | TLV803E·SWD, floating 금지 |
| 8 | `PA0` | AF7 `USART2_CTS` | UART CTS | ESP GPIO15 RTS, 10 kΩ pull-up |
| 9 | `PA1` | AF7 `USART2_RTS_DE` | UART RTS | ESP GPIO16 CTS, 10 kΩ pull-up |
| 10 | `PA2` | AF7 `USART2_TX` | UART TX | ESP GPIO18 RX, weak pull-up footprint |
| 11 | `PA3` | AF7 `USART2_RX` | UART RX | ESP GPIO17 TX, weak pull-up footprint |
| 12 | `PA4` | output | TCAN STB1 | external 10 kΩ pull-up → standby |
| 13 | `PA5` | output | TCAN STB2 | external 10 kΩ pull-up → standby |
| 14 | `PA6` | output | MAX3055 EN | external 10 kΩ pull-down → disabled |
| 25 | `PB12` | AF9 `FDCAN2_RX` | CAN 2 RX | TCAN pin 8 |
| 26 | `PB13` | AF9 `FDCAN2_TX` | CAN 2 TX | TCAN pin 6, external 10 kΩ pull-up |
| 27 | `PB14` | input | MAX3055 ERR | divider; CAN3 전체 DNP variant에서만 미실장 |
| 30 | `PA8` | AF11 `FDCAN3_RX` | CAN 3 RX | MAX pin 3 via divider |
| 33 | `PA11` | AF9 `FDCAN1_RX` | CAN 1 RX | TCAN pin 4 |
| 34 | `PA12` | AF9 `FDCAN1_TX` | CAN 1 TX | TCAN pin 1, external 10 kΩ pull-up |
| 36 | `PA13` | AF0 `SWDIO` | debug | SWD header |
| 37 | `PA14` | AF0 `SWCLK` | debug | SWD header |
| 38 | `PA15` | AF11 `FDCAN3_TX` | CAN 3 TX | MAX pin 2, external 10 kΩ pull-up |
| 46 | `PB8-BOOT0` | boot strap | BOOT0 | 10 kΩ pull-down + service pad |

`PA11/PA12`는 STM32 USB와 multiplex되므로 STM32 USB는 사용하지 않는다. service interface는 ESP32 native USB와 STM32 SWD를 사용한다.

이 핀맵은 이전의 `PB3/PB4 = FDCAN3`, `PB5/PB6 = FDCAN2` 배치를 폐기한다. STM32는 reset 시 PA15·PA13·PB4에 debug용 pull-up, PA14에 pull-down을 적용한다. 또한 PB4/PB6에는 UCPD dead-battery 5.1 kΩ pull-down 경로가 개입할 수 있다. UCPD pull-down은 firmware에서 해제할 수 있지만 reset 전부터 보장되는 하드웨어 안전 상태에는 의존할 수 없다. PA15 reset pull-up은 CAN TXD recessive 방향이므로 FDCAN3 TX에는 오히려 적합하다.

## 6. ESP32 UART와 reset 핀

| ESP pad | GPIO | 기능 | STM32 peer | 외부 기본값 |
|---:|---:|---|---|---|
| 19 | 15 | UART1 RTS | PA0 CTS | 10 kΩ pull-up |
| 20 | 16 | UART1 CTS | PA1 RTS | 10 kΩ pull-up |
| 21 | 17 | UART1 TX | PA3 RX | 22–47 kΩ weak pull-up footprint |
| 22 | 18 | UART1 RX | PA2 TX | 22–47 kΩ weak pull-up footprint |
| 23 | 19 | USB D− | USB connector | 다른 기능 배정 금지 |
| 24 | 20 | USB D+ | USB connector | 다른 기능 배정 금지 |
| 26 | 26 | internal PSRAM | 연결 금지 | N4R2 내부 전용 |
| 45 | — | CHIP_PU | SYS_RESET_N | TLV803E + 10 kΩ pull-up |

RTS/CTS 두 선은 각각 high가 되어 상대 송신기가 전송을 멈추는 상태로 시작한다. TX/RX weak pull-up은 line idle을 정의하는 선택 footprint이며 4 Mbps eye 측정 결과로 장착값을 정한다. 두 MCU firmware에서 hardware flow-control polarity를 invert하지 않는다.

## 7. reset 상태와 firmware 부팅 순서

### 7.1 무전원·reset 기본 상태

| 대상 | 하드웨어 기본값 | 결과 |
|---|---|---|
| TCAN TXD1/TXD2 | 각 10 kΩ pull-up | recessive |
| TCAN STB1/STB2 | 각 10 kΩ pull-up | CAN 1·2 standby |
| MAX3055 TXD | 10 kΩ pull-up | recessive |
| MAX3055 STB | 10 kΩ to 5 V | high 고정 |
| MAX3055 EN | 10 kΩ pull-down | Power-On Standby, transmitter 비활성 |
| UART RTS/CTS | 각 10 kΩ pull-up | 양방향 flow stop |
| STM32 BOOT0 | 10 kΩ pull-down | user Flash boot |
| SYS_RESET_N | supervisor open-drain | 3.3 V 부족 시 두 MCU reset |
| CAN termination | switch off 또는 DNP | 차량 기존 종단 불변 |

외부 resistor가 reset 안전의 정본이다. firmware의 첫 GPIO write는 이 상태를 유지하는 보조 계층이다.

### 7.2 STM32 부팅 순서

1. PA4·PA5 output latch를 high, PA6를 low로 먼저 기록한 뒤 output mode로 전환한다.
2. HSE를 시작하고 PLL/FDCAN kernel clock을 검증한다.
3. USART2 4 Mbps와 RTS/CTS를 초기화하되 CTS가 허용되기 전 송신하지 않는다.
4. FDCAN 3채널의 bitrate, message RAM, filter, interrupt와 error 처리를 구성한다.
5. 세 controller를 먼저 start하고 target bus profile을 listen-only로 검증한다.
6. 검증된 채널에 한해 PA4·PA5를 low로 내려 TCAN을 normal로 만들고, PA6를 high로 올려 MAX3055를 normal로 만든다.
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

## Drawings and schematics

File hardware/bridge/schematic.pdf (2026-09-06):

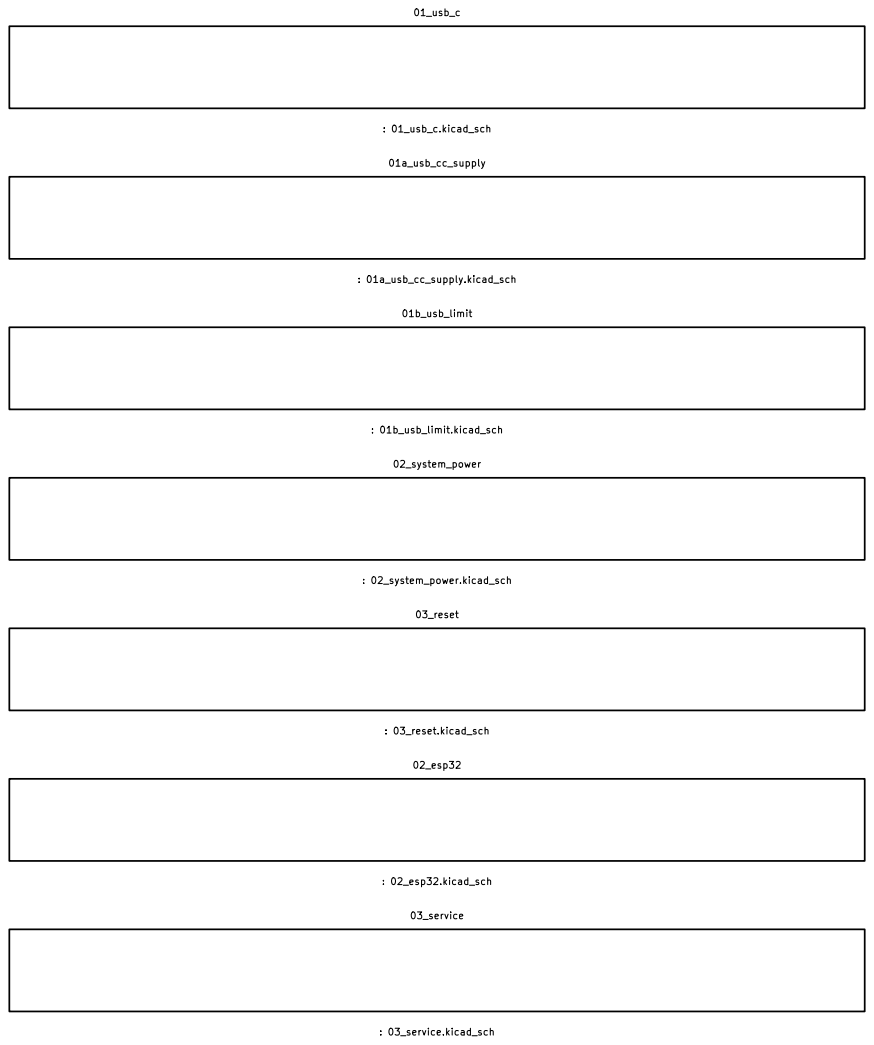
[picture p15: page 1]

SCHEMATIC REVIEW ONLY - PCB/HIL release gates remain open
digitie/canview
Sheet: /
File: bridge.kicad_sch
Title: CANView / bridge

Size: A3 | Rev: R1 REVIEW | F Date: 2026-09-05
KiCad E.D.A. 10.0.6 | Id: 1/8

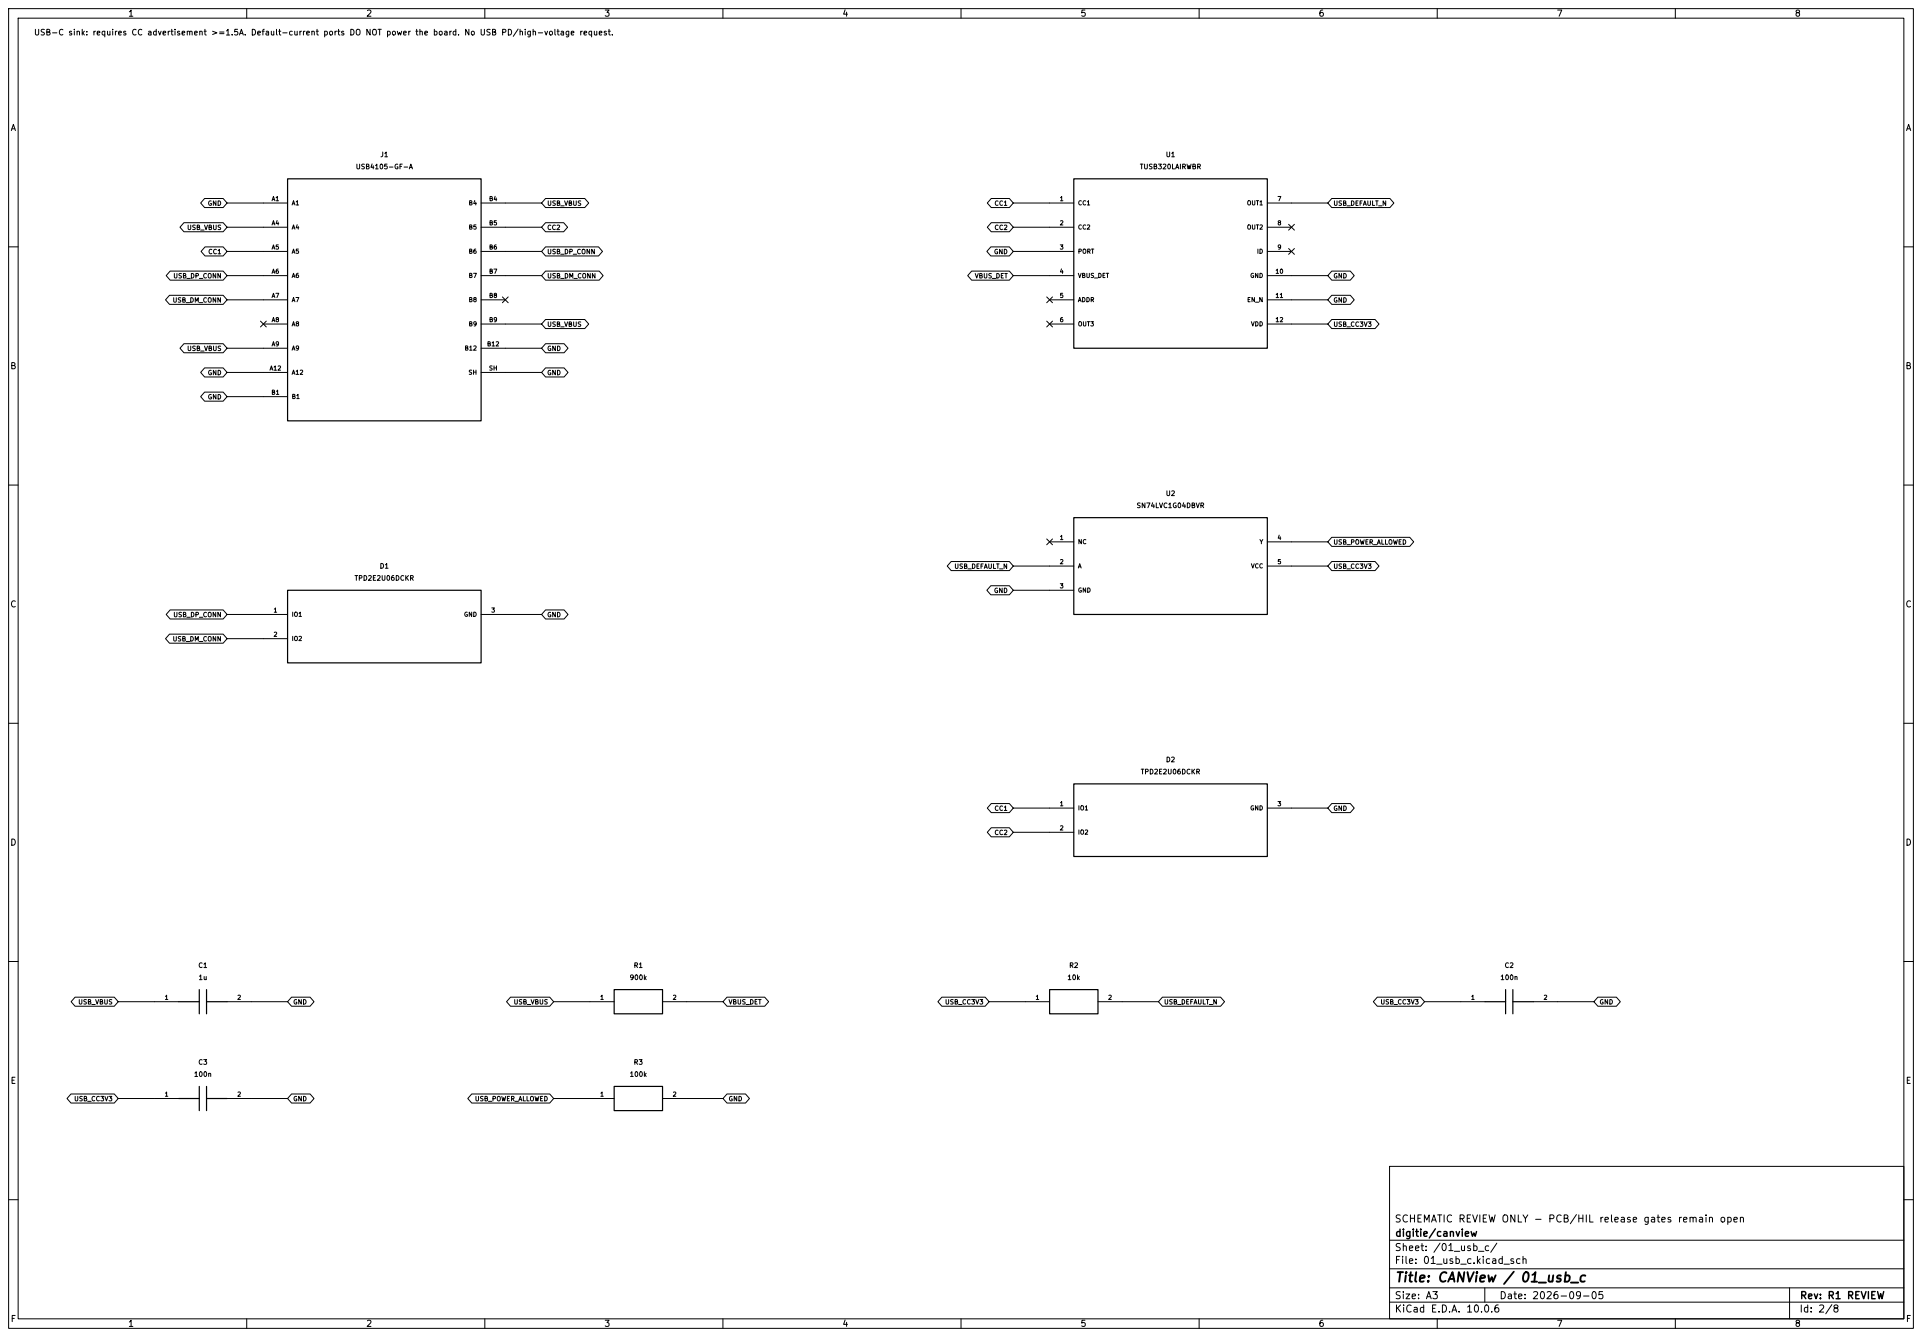
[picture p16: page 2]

USB-C sink: requires CC advertisement >=1.5A. Default-current ports DO NOT power the board. No USB PD/high-voltage request.

SCHEMATIC REVIEW ONLY - PCB/HIL release gates remain open
digitie/canview
Sheet: /01_usb_c/
File: 01_usb_c.kicad_sch
Title: CANView / 01_usb_c

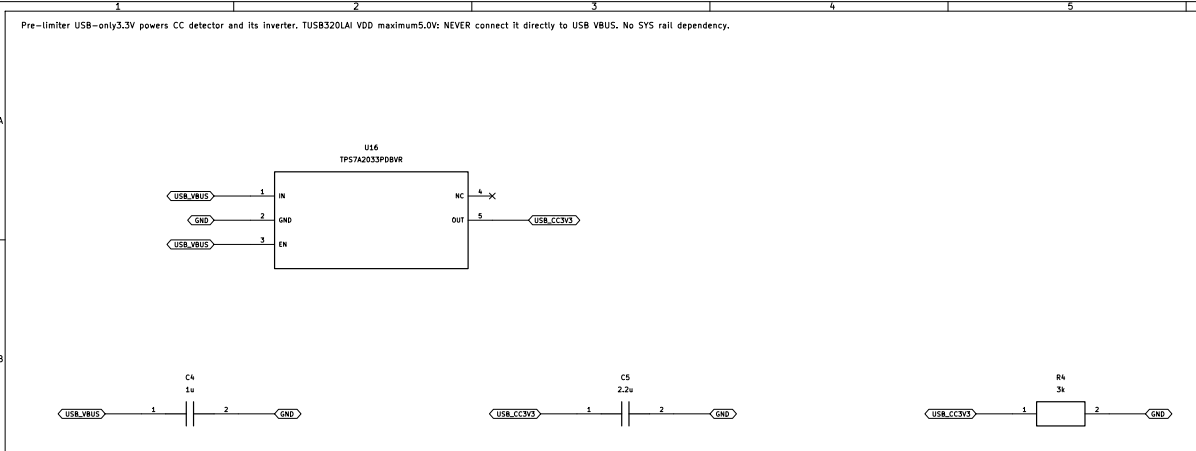
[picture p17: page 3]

SCHEMATIC REVIEW ONLY - PCB/HIL release gates remain open
digitie/canview
Sheet: /01a_usb_cc_supply/
File: 01a_usb_cc_supply.kicad_sch
Title: CANView / 01a_usb_cc_supply

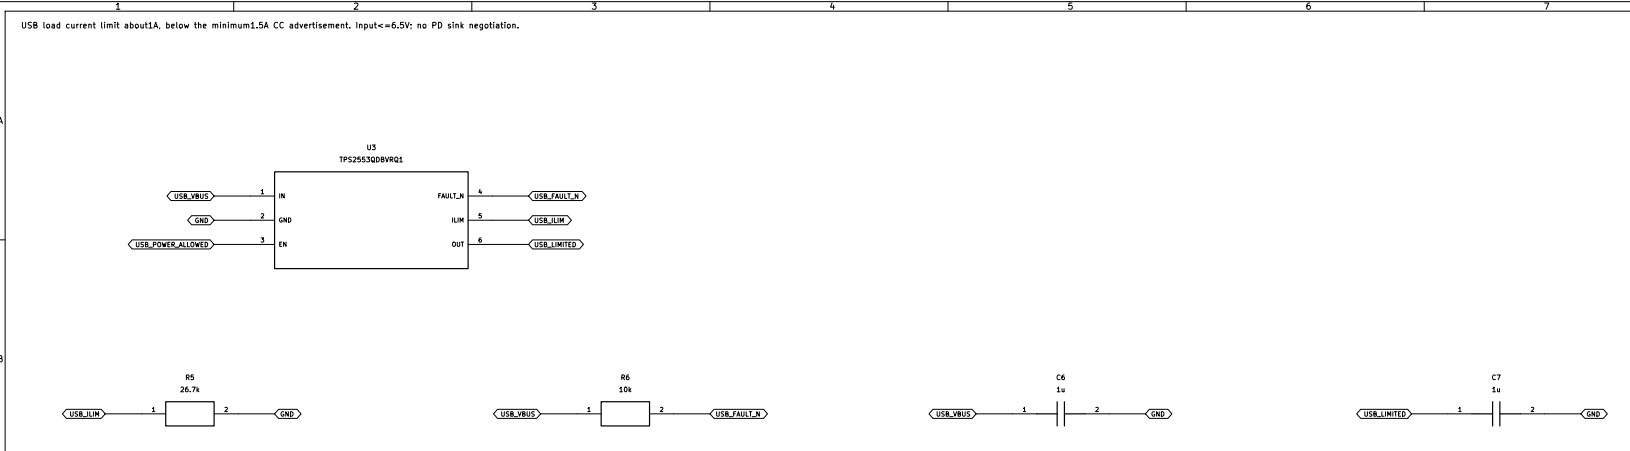
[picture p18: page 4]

SCHEMATIC REVIEW ONLY - PCB/HIL release gates remain open
digitie/canview
Sheet: /01b_usb_limit/
File: 01b_usb_limit.kicad_sch
Title: CANView / 01b_usb_limit

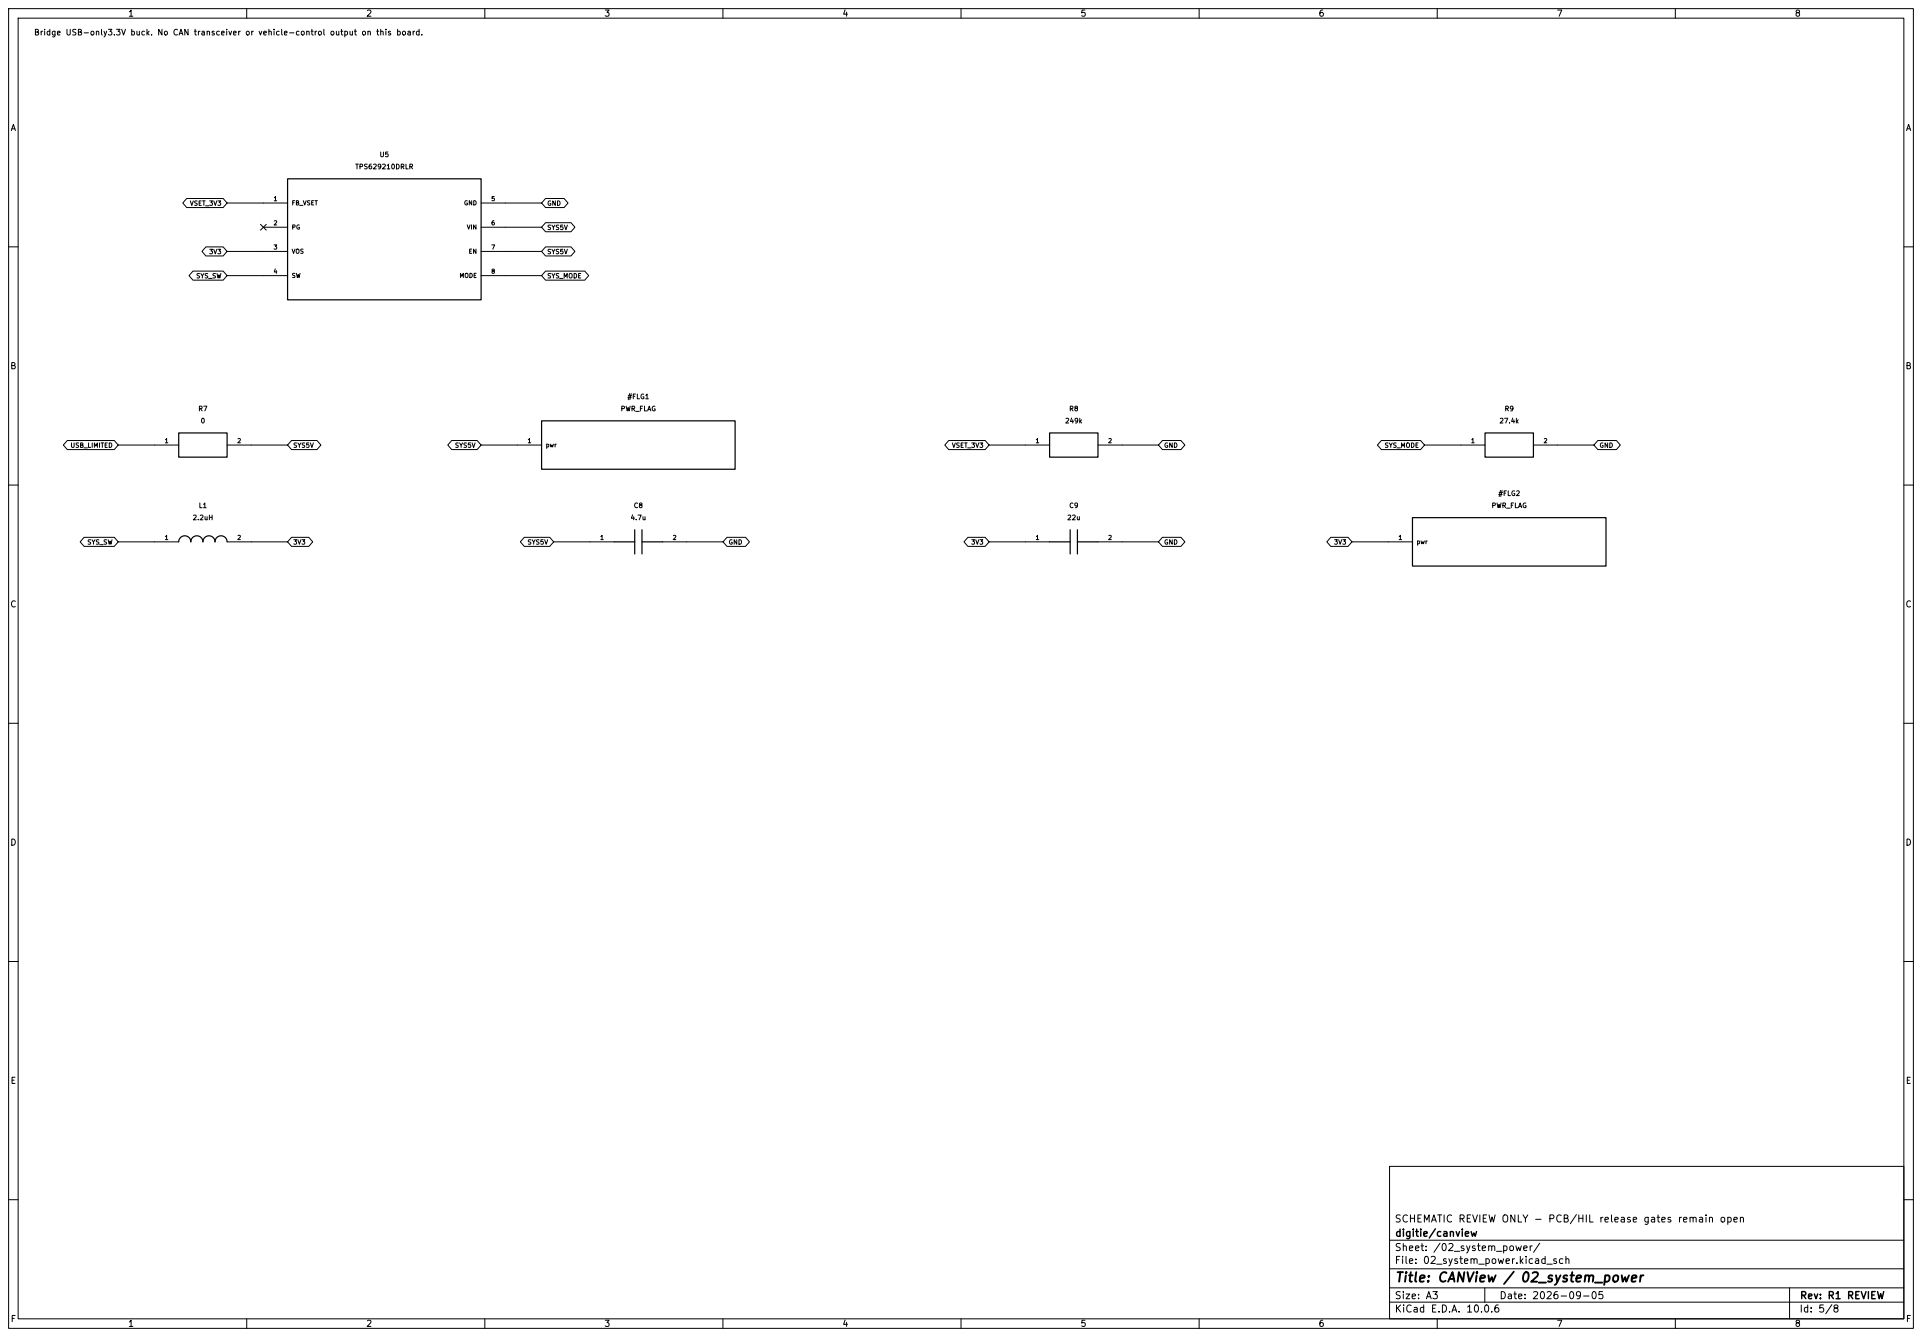
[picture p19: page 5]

Bridge USB-only3.3V buck. No CAN transceiver or vehicle-control output on this board.

SCHEMATIC REVIEW ONLY - PCB/HIL release gates remain open
digitie/canview
Sheet: /02_system_power/
File: 02_system_power.kicad_sch
Title: CANView / 02_system_power

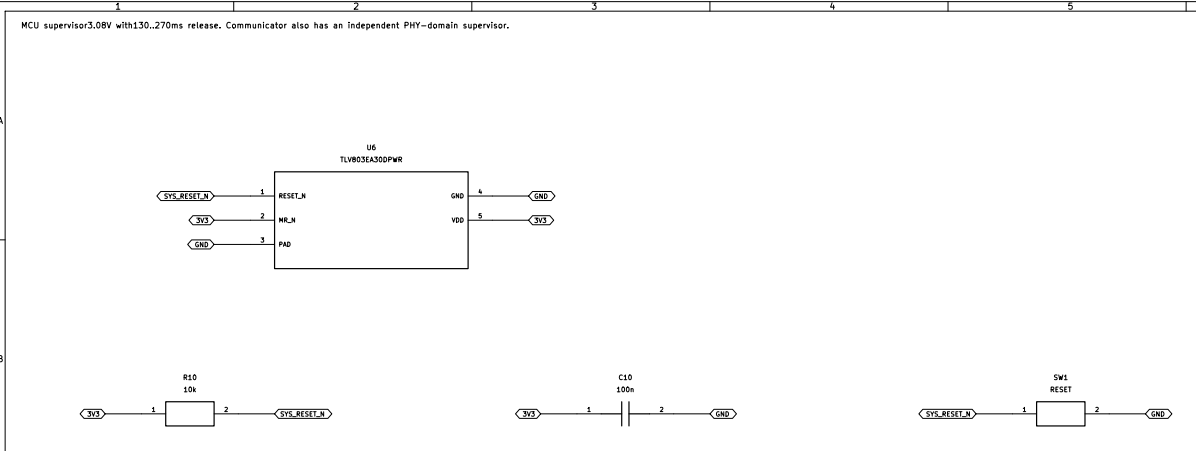
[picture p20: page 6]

SCHEMATIC REVIEW ONLY - PCB/HIL release gates remain open
digitie/canview
Sheet: /03_reset/
File: 03_reset.kicad_sch
Title: CANView / 03_reset

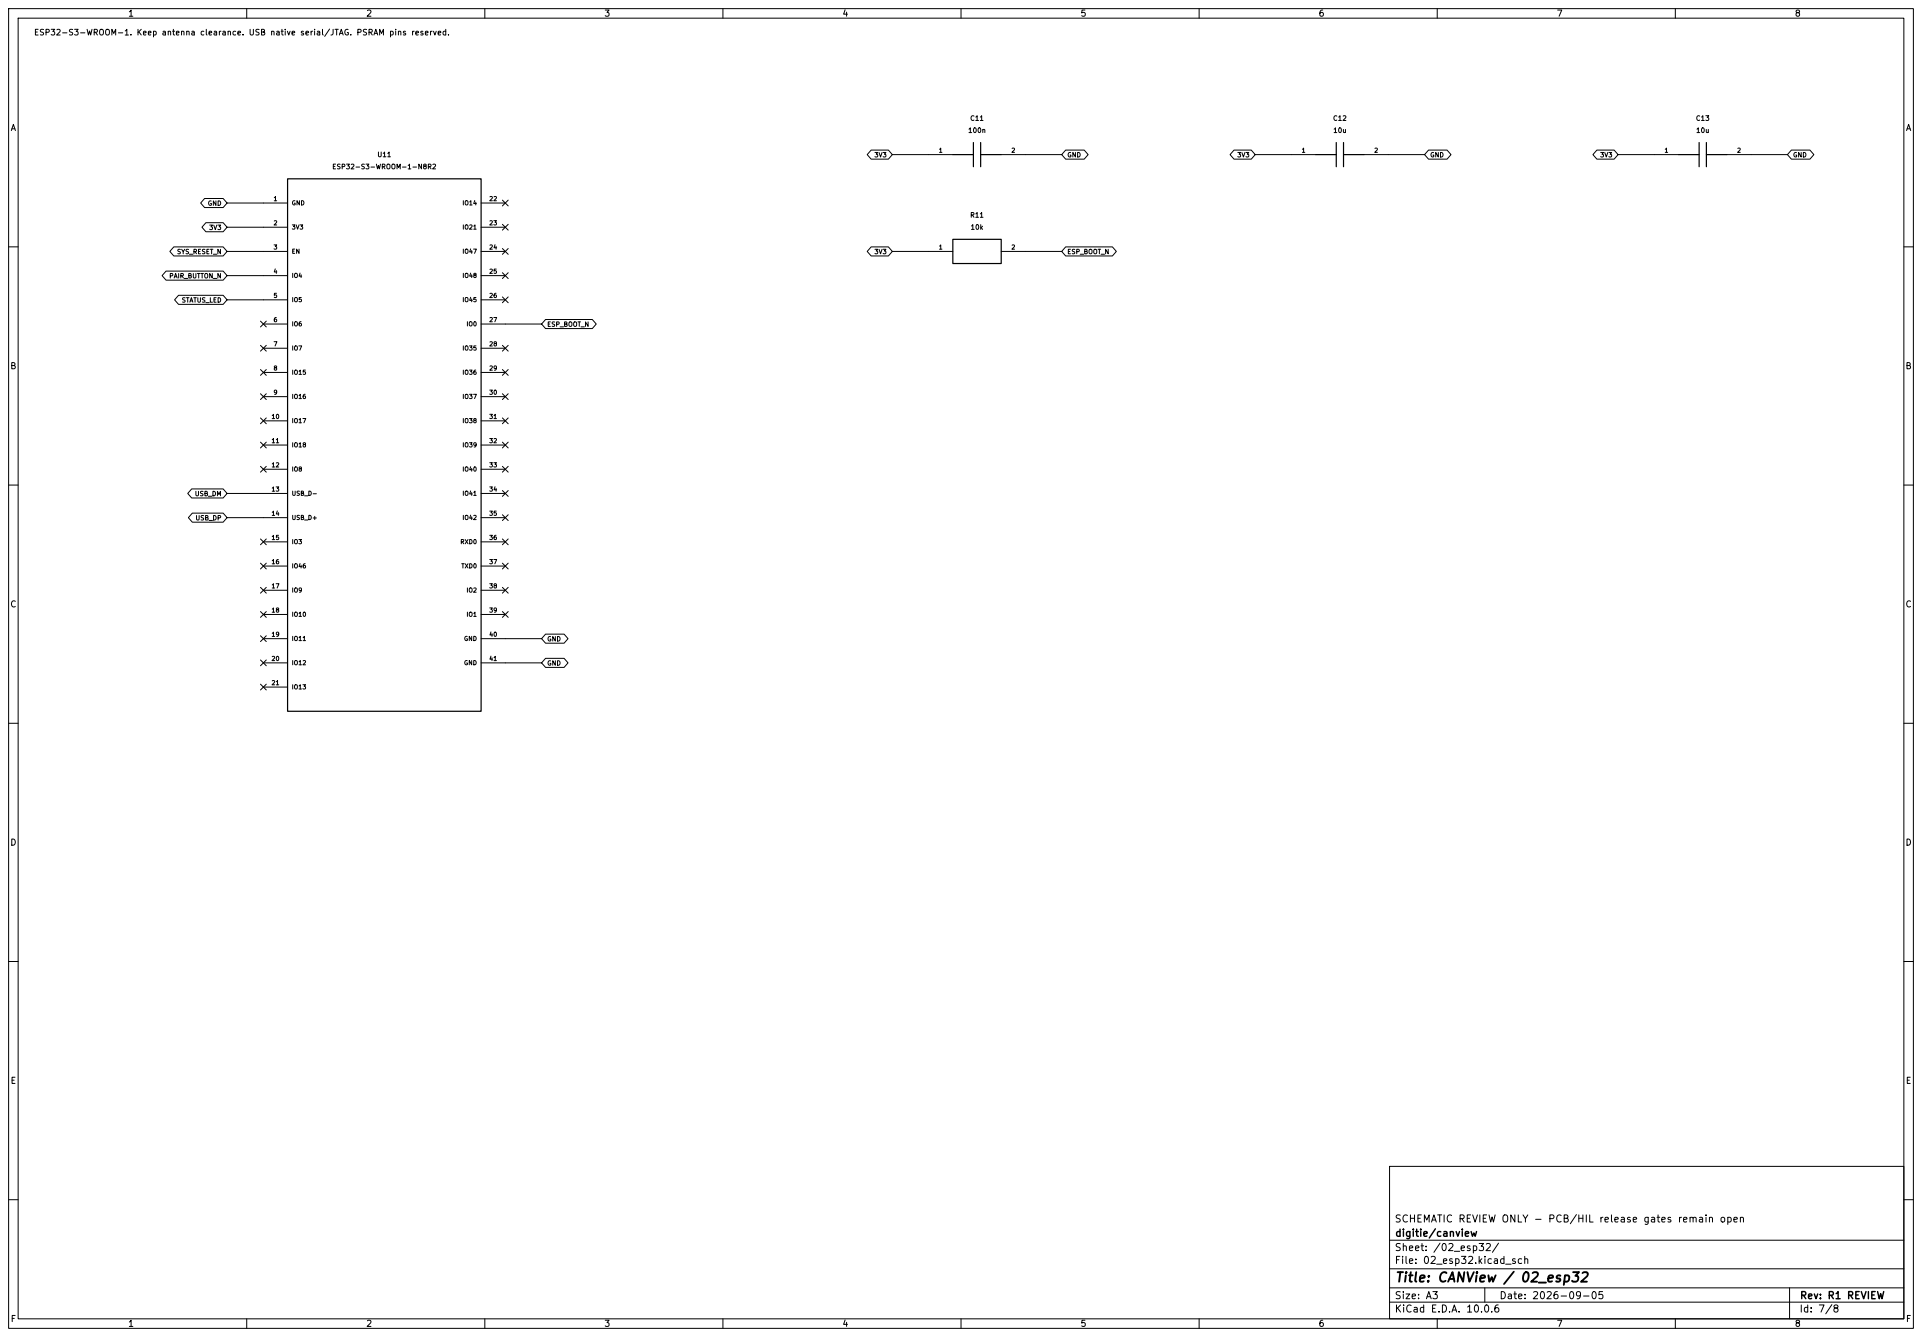
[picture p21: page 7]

SCHEMATIC REVIEW ONLY - PCB/HIL release gates remain open
digitie/canview
Sheet: /02_esp32/
File: 02_esp32.kicad_sch
Title: CANView / 02_esp32

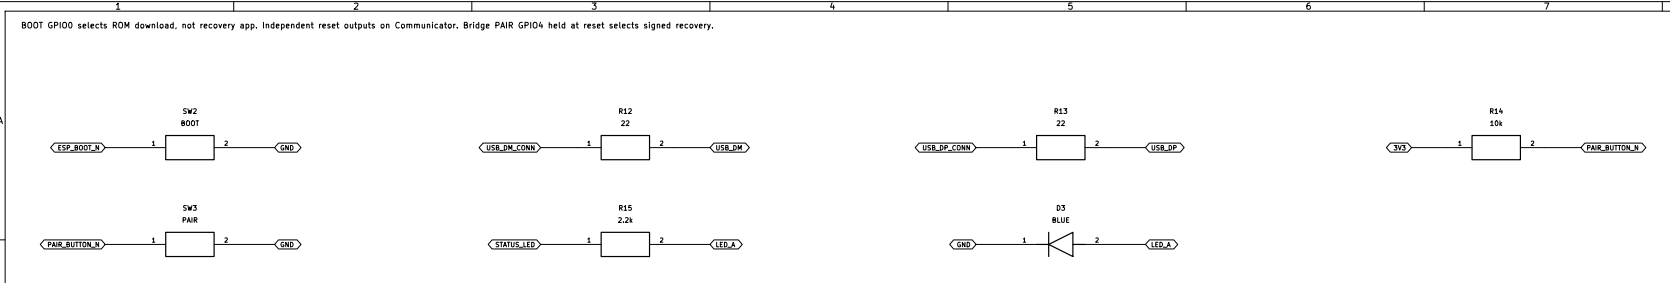
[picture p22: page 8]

PAIR_BUTTON_N BOOT GPIO0 selects ROM download, not recovery app. Independent reset outputs on Communicator. Bridge PAIR GPIO4 held at reset selects signed recovery.

SCHEMATIC REVIEW ONLY - PCB/HIL release gates remain open
digitie/canview
Sheet: /03_service/
File: 03_service.kicad_sch
Title: CANView / 03_service

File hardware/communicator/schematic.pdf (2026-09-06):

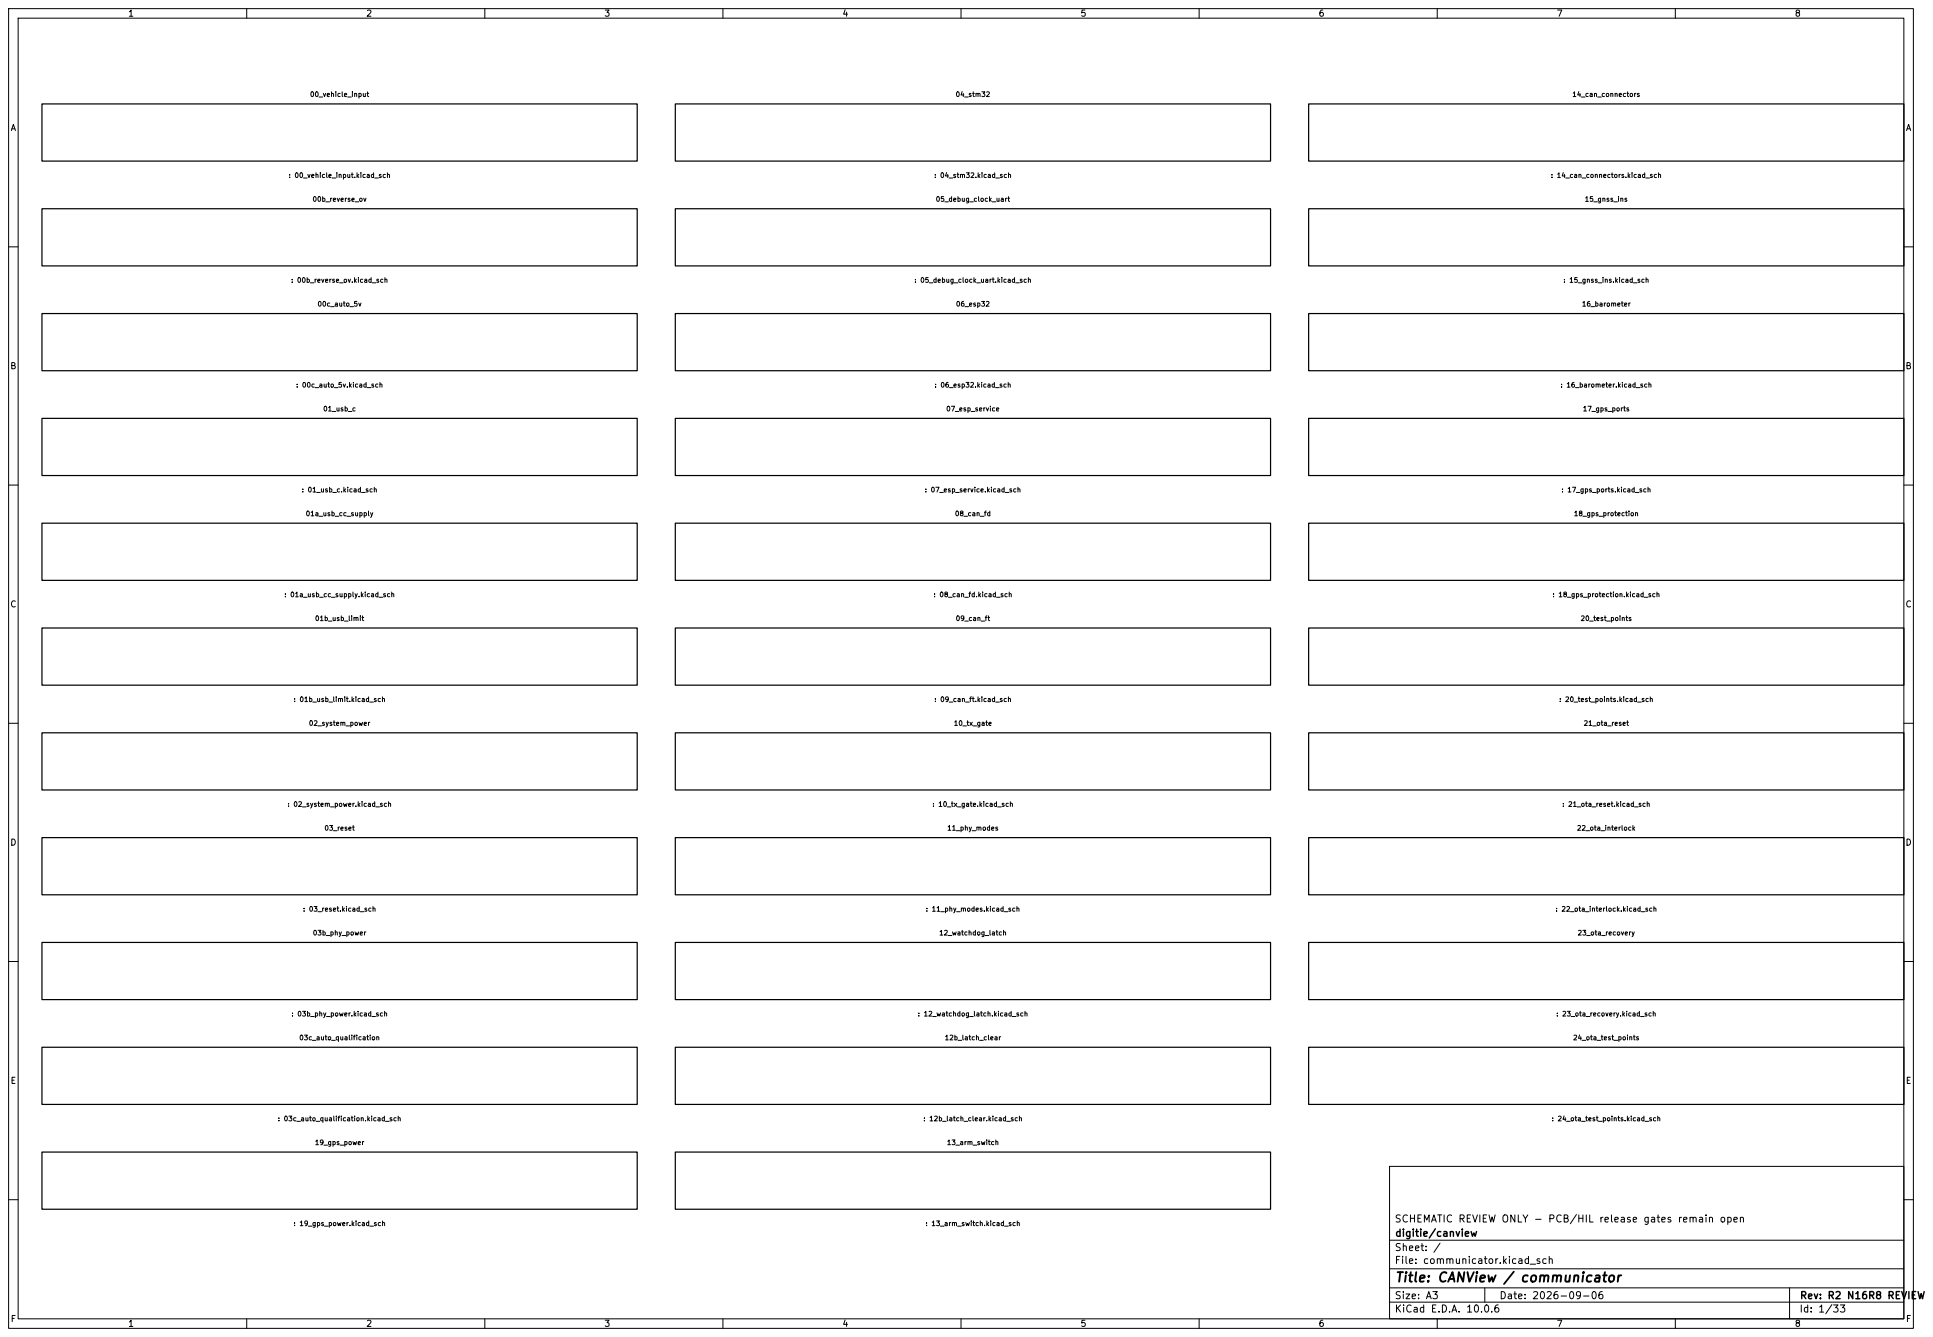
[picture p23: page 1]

SCHEMATIC REVIEW ONLY - PCB/HIL release gates remain open
digitie/canview
Sheet: /
File: communicator.kicad_sch
Title: CANView / communicator

F Date: 2026-09-06

KiCad E.D.A. 10.0.6 | Id: 1/33

SCHEMATIC REVIEW ONLY - PCB/HIL release gates remain open
digitie/canview
Sheet: /00_vehicle_input/
File: 00_vehicle_input.kicad_sch
Title: CANView / 00_vehicle_input

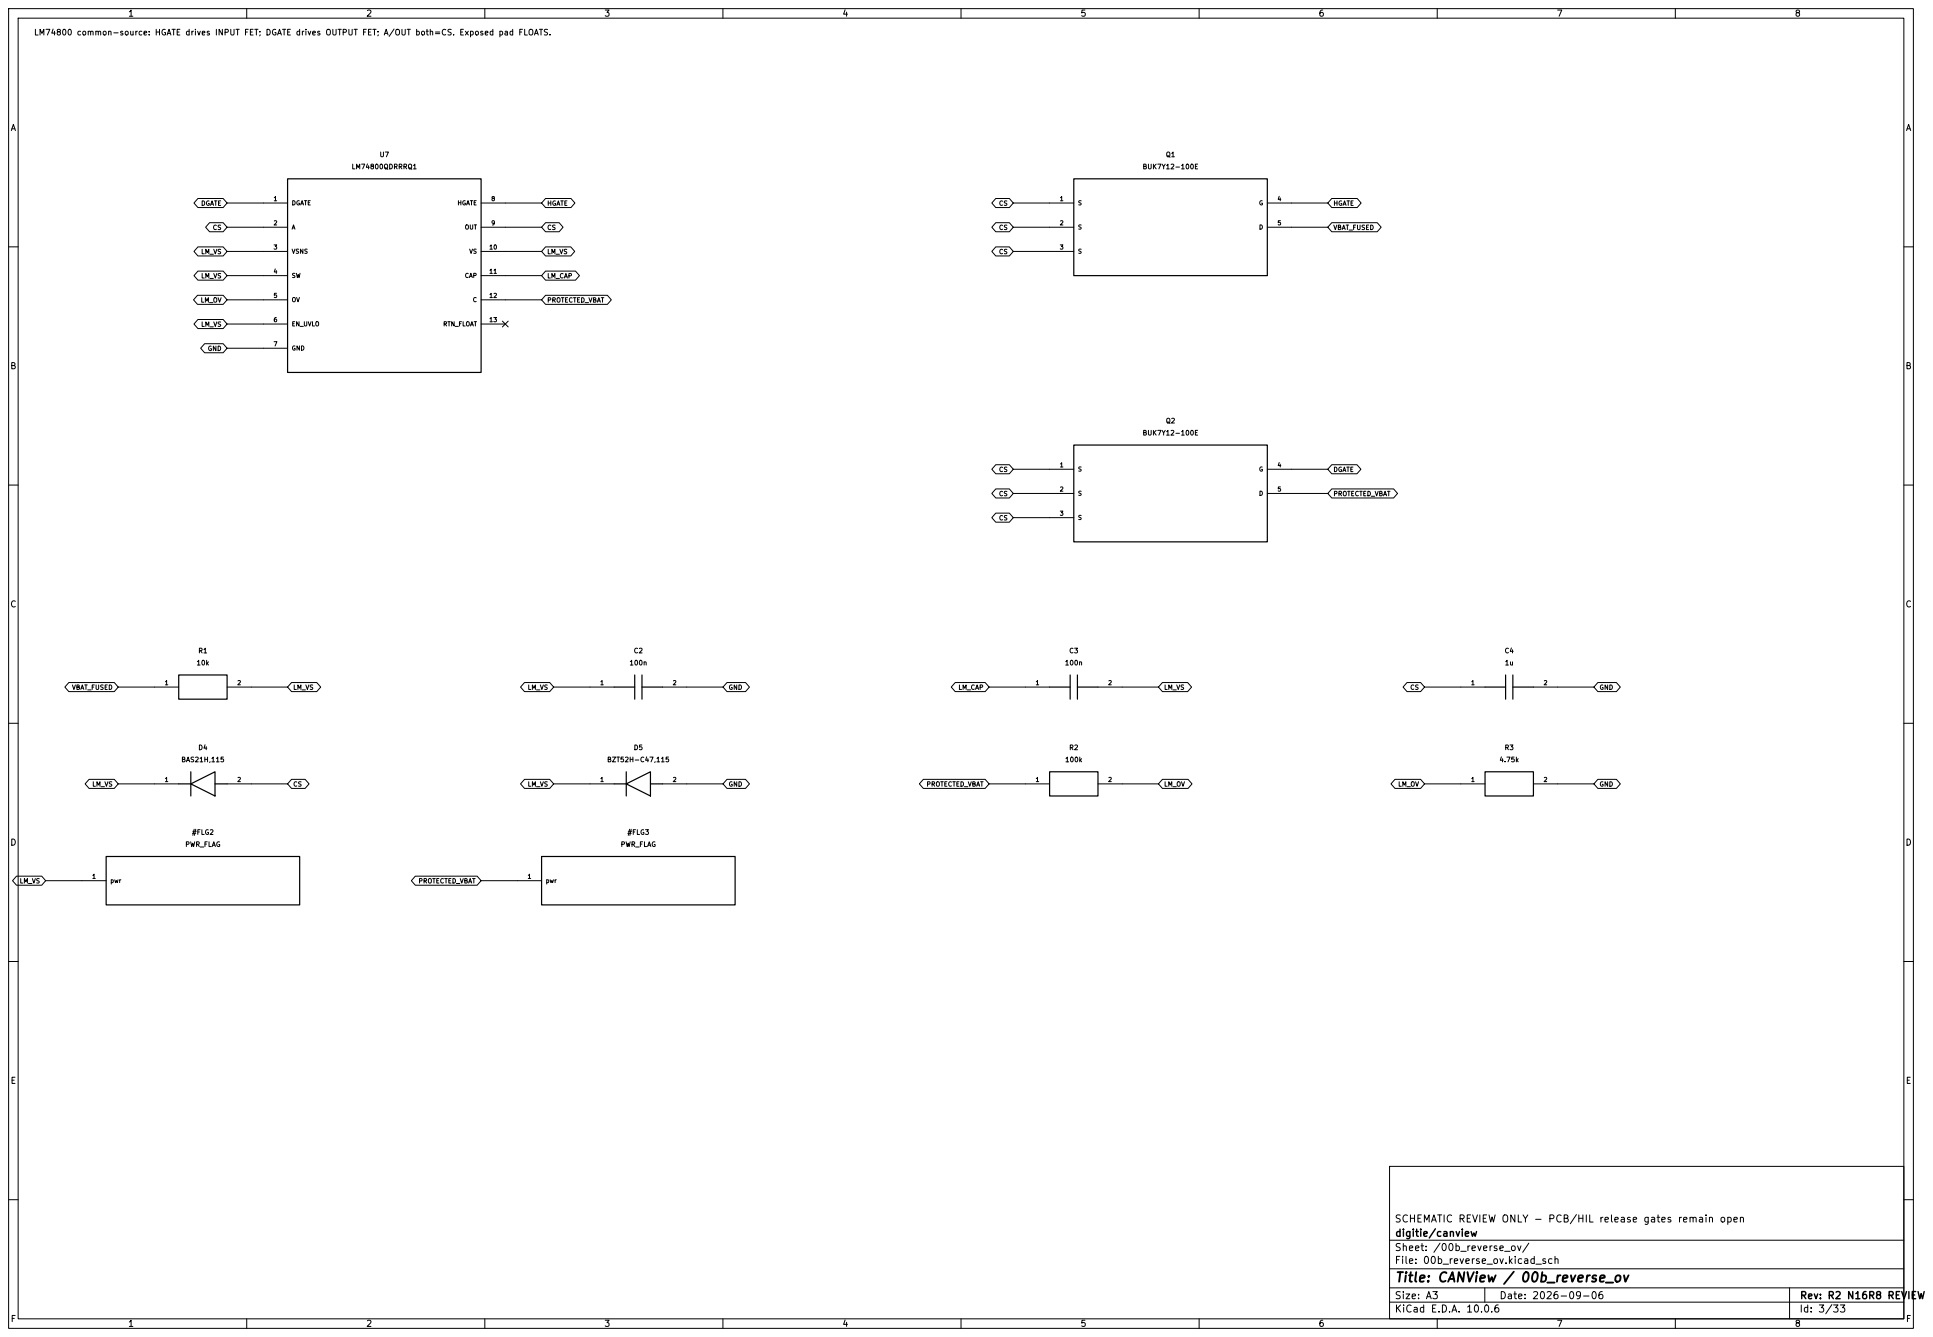
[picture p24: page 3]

LM74800 common-source: HGATE drives INPUT FET; DGATE drives OUTPUT FET; A/OUT both=CS. Exposed pad FLOATS.

SCHEMATIC REVIEW ONLY - PCB/HIL release gates remain open
digitie/canview
Sheet: /00b_reverse_ov/
File: 00b_reverse_ov.kicad_sch
Title: CANView / 00b_reverse_ov

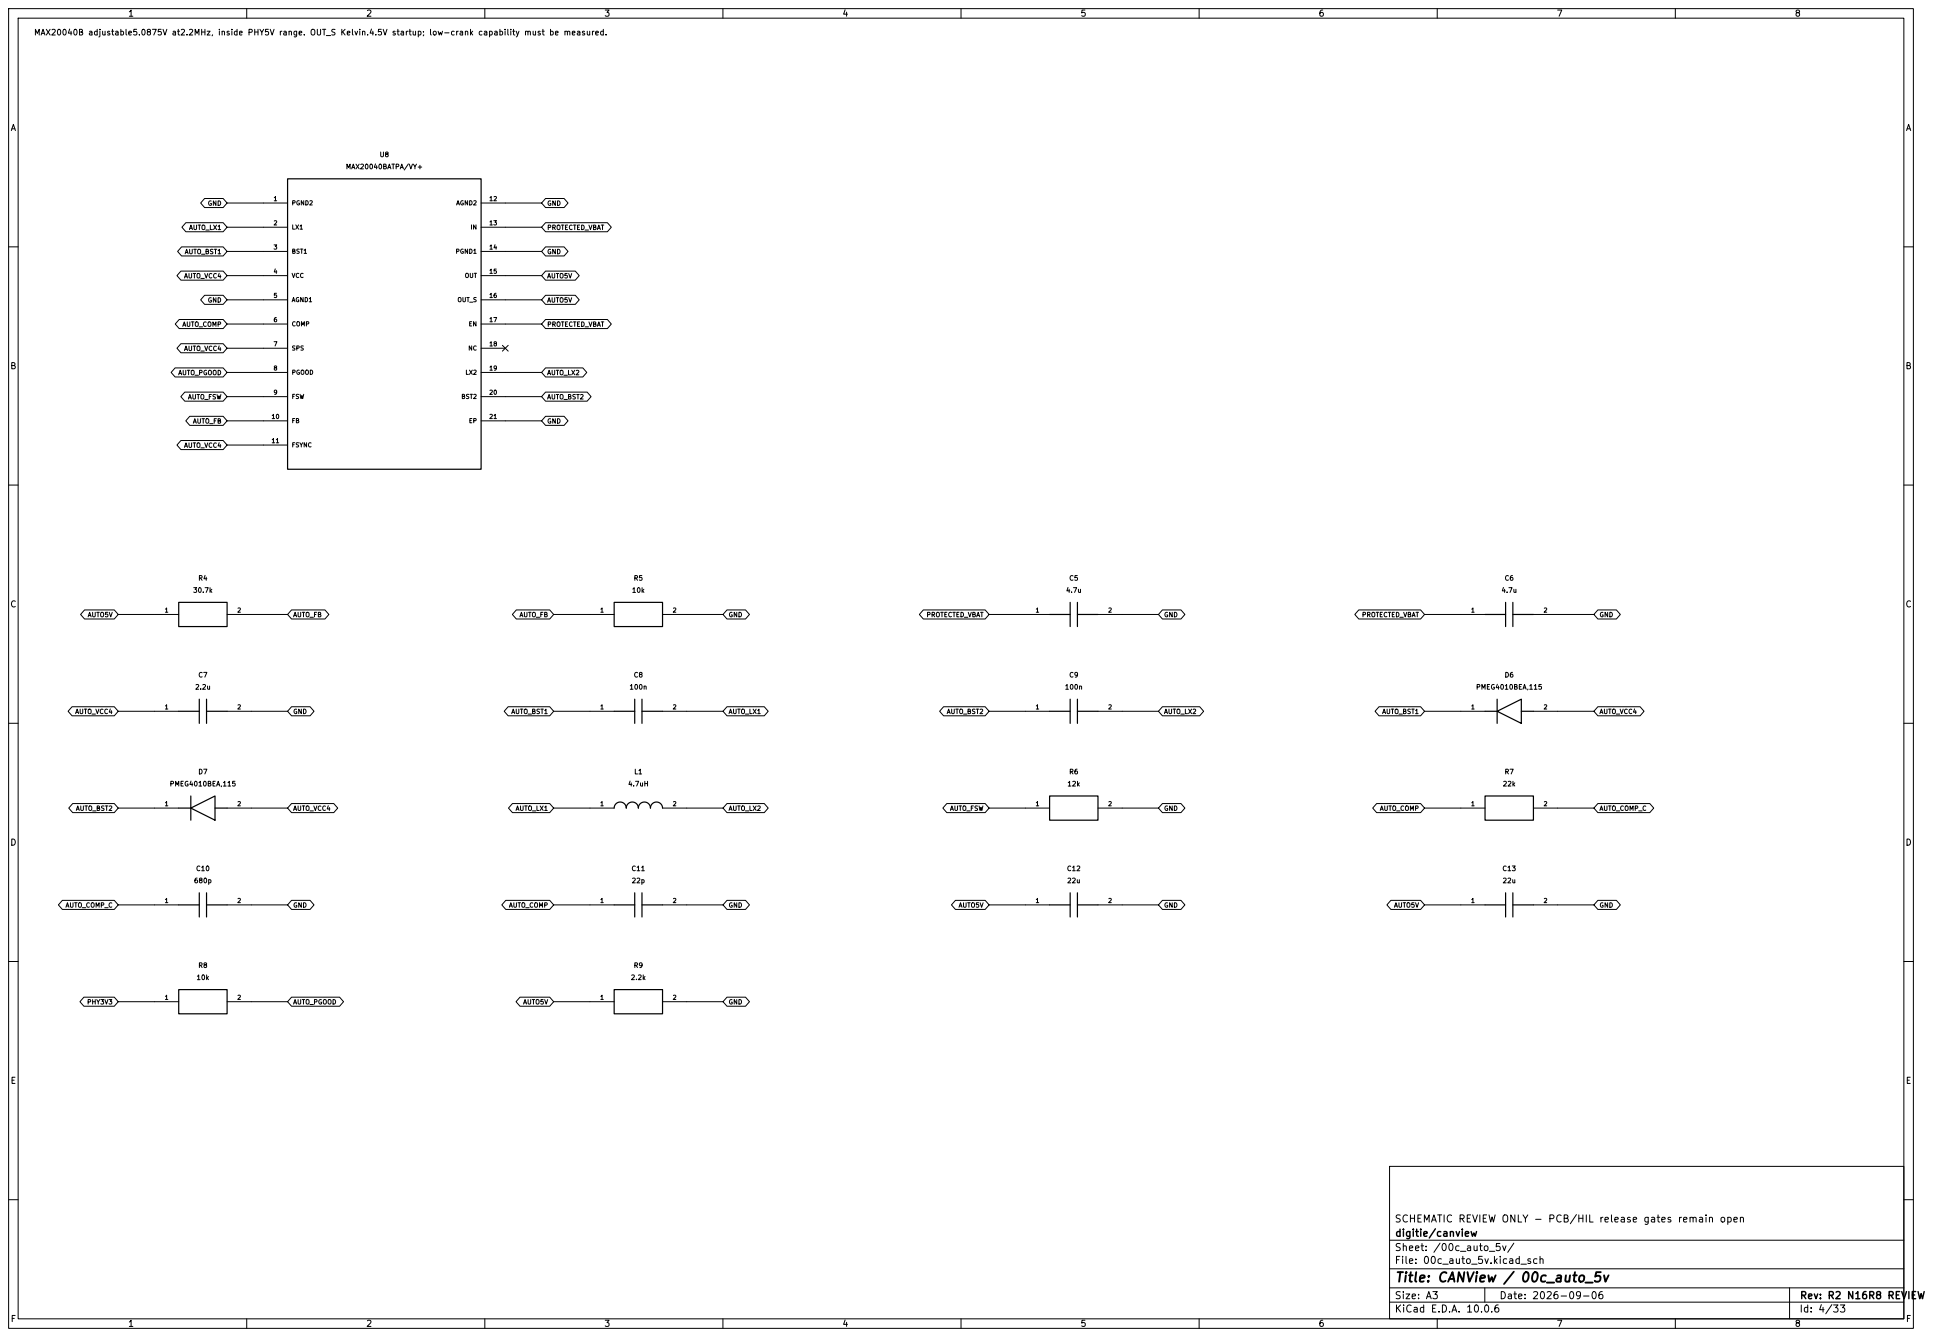
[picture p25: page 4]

MAX20040B adjustable5.0875V at2.2MHz, inside PHY5V range. OUT_S Kelvin.4.5V startup; low-crank capability must be measured.

SCHEMATIC REVIEW ONLY - PCB/HIL release gates remain open
digitie/canview
Sheet: /00c_auto_5v/
File: 00c_auto_5v.kicad_sch
Title: CANView / 00c_auto_5v

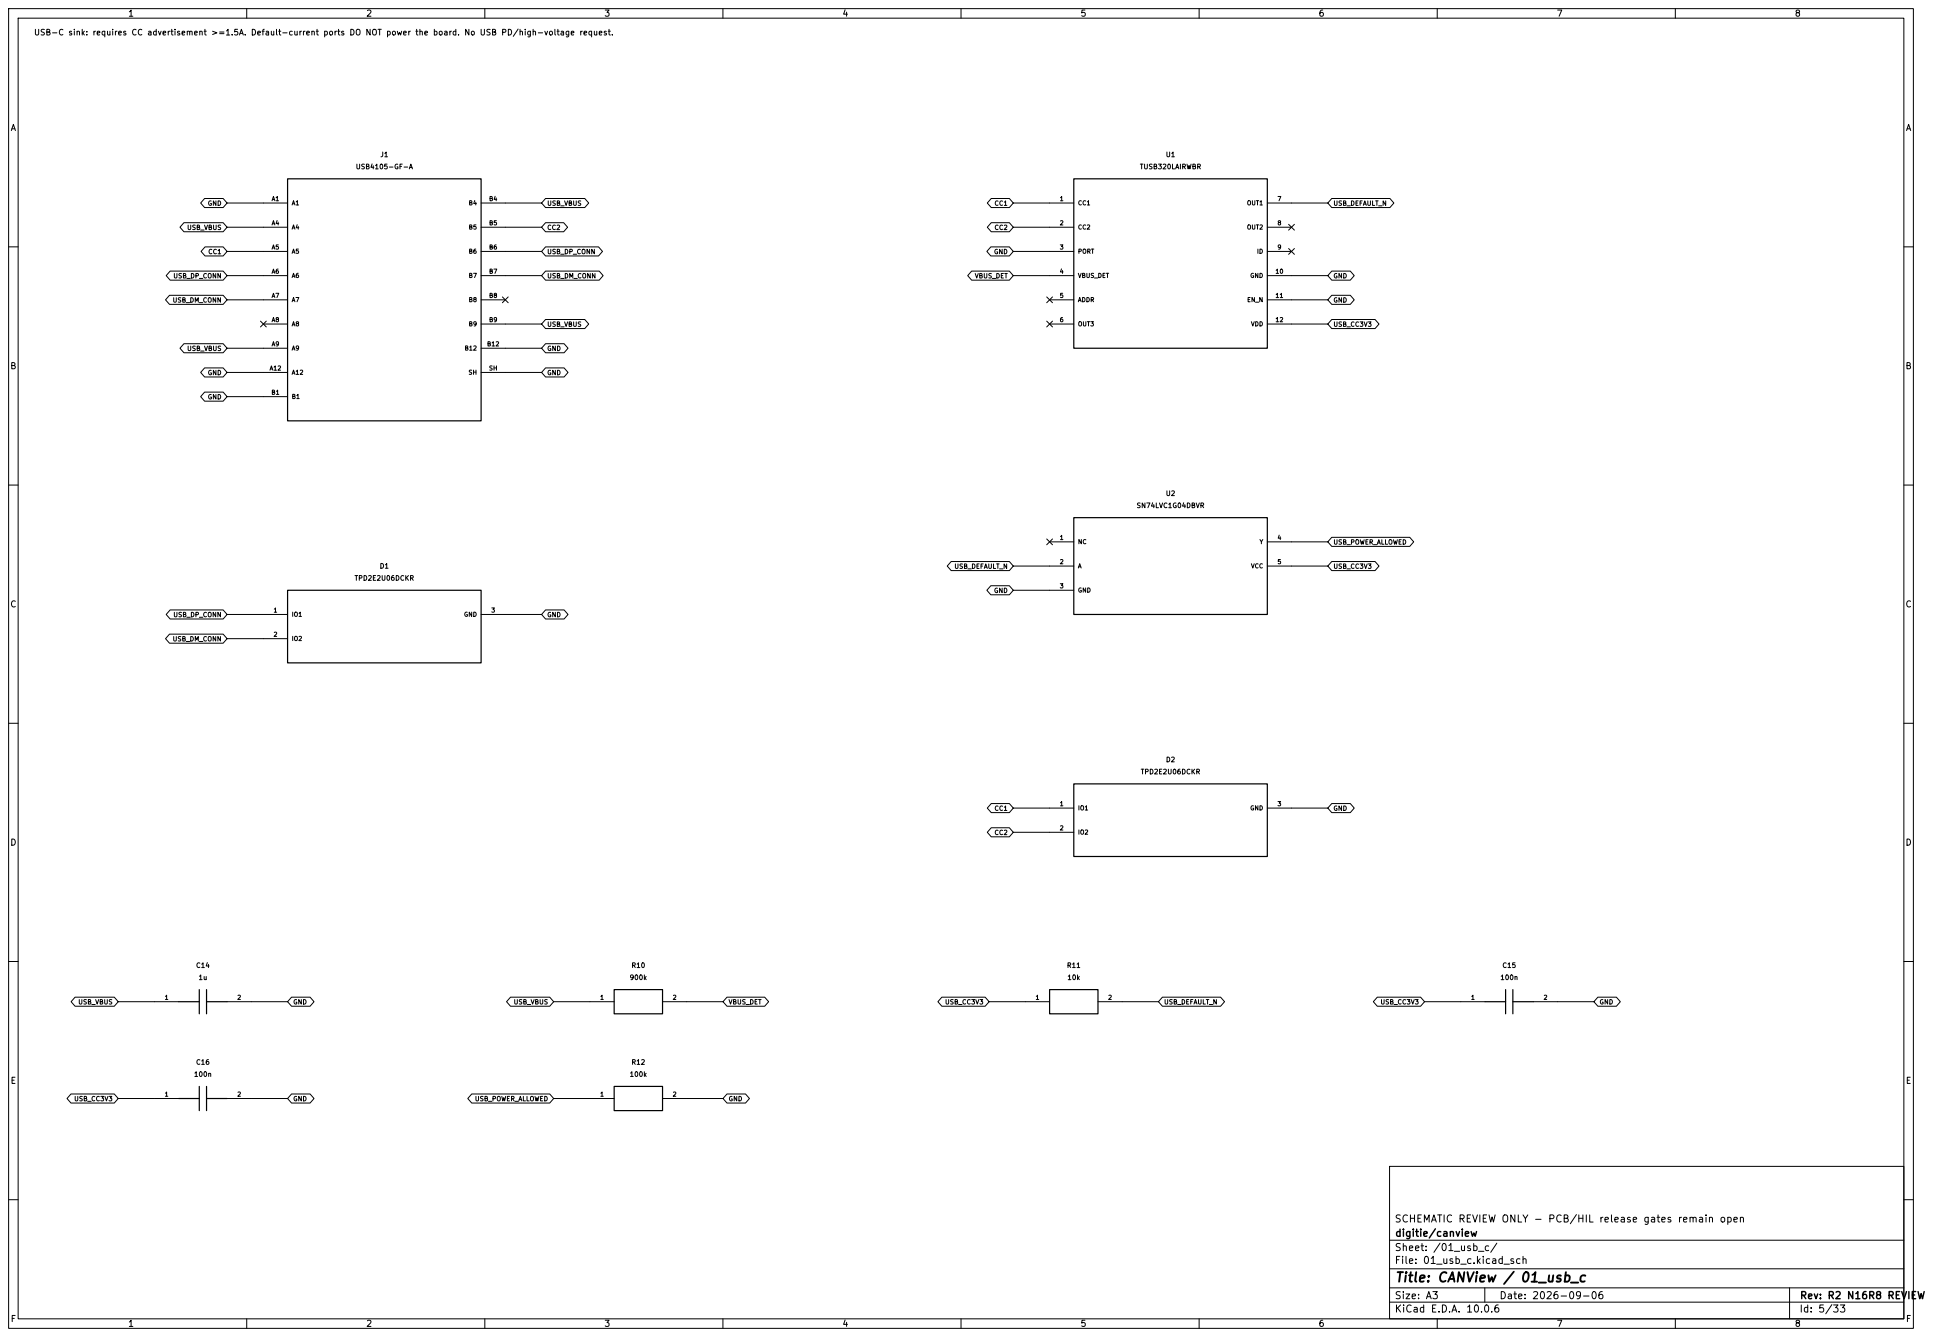
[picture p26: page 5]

USB-C sink: requires CC advertisement >=1.5A. Default-current ports DO NOT power the board. No USB PD/high-voltage request.

SCHEMATIC REVIEW ONLY - PCB/HIL release gates remain open
digitie/canview
Sheet: /01_usb_c/
File: 01_usb_c.kicad_sch
Title: CANView / 01_usb_c

SCHEMATIC REVIEW ONLY - PCB/HIL release gates remain open
digitie/canview
Sheet: /01a_usb_cc_supply/
File: 01a_usb_cc_supply.kicad_sch
Title: CANView / 01a_usb_cc_supply


SCHEMATIC REVIEW ONLY - PCB/HIL release gates remain open
digitie/canview
Sheet: /01b_usb_limit/
File: 01b_usb_limit.kicad_sch
Title: CANView / 01b_usb_limit


TPS2116 isolates automotive5V and USB; CAN PHY/GPS never fed from mux output.3.3V EN follows SYS5V, not automotive PGOOD.

SCHEMATIC REVIEW ONLY - PCB/HIL release gates remain open
digitie/canview
Sheet: /02_system_power/
File: 02_system_power.kicad_sch
Title: CANView / 02_system_power


SCHEMATIC REVIEW ONLY - PCB/HIL release gates remain open
digitie/canview
Sheet: /03_reset/
File: 03_reset.kicad_sch
Title: CANView / 03_reset

PHY_RESET_N PHY3V3 is automotive-only. Its own supervisor initializes arm latch on USB-first hot-plug. FT inputs track AUTO5V, not held-up3.3V.

SCHEMATIC REVIEW ONLY - PCB/HIL release gates remain open
digitie/canview
Sheet: /03b_phy_power/
File: 03b_phy_power.kicad_sch
Title: CANView / 03b_phy_power


Independent battery threshold and real5V qualification. PGOOD alone is not sufficient for MAX3055. Threshold/latency worst cases remain test gates.

SCHEMATIC REVIEW ONLY - PCB/HIL release gates remain open
digitie/canview
Sheet: /03c_auto_qualification/
File: 03c_auto_qualification.kicad_sch
Title: CANView / 03c_auto_qualification


AUTO5V GND GPS automotive-only switched supply. Fault-current limit independent of ESP. Never enable in USB-only service.

SCHEMATIC REVIEW ONLY - PCB/HIL release gates remain open
digitie/canview
Sheet: /19_gps_power/
File: 19_gps_power.kicad_sch
Title: CANView / 19_gps_power

STM32G474CEU6 / UFQFPN48. Pin 7 is the PG10-NRST dual-function reset pad. HSE 16MHz. USART2 4Mbps RTS/CTS. SWD only; USB pins are CAN1.

SCHEMATIC REVIEW ONLY - PCB/HIL release gates remain open
digitie/canview
Sheet: /04_stm32/
File: 04_stm32.kicad_sch
Title: CANView / 04_stm32


16MHz crystal CL18pF: 27pF + estimated 4.5pF parasitic; tune after PCB. SWD VTref is OUTPUT ONLY.

SCHEMATIC REVIEW ONLY - PCB/HIL release gates remain open
digitie/canview
Sheet: /05_debug_clock_uart/
File: 05_debug_clock_uart.kicad_sch
Title: CANView / 05_debug_clock_uart


3V3 ESP32-S3-WROOM-1. Keep antenna clearance. USB native serial/JTAG. PSRAM pins reserved.

SCHEMATIC REVIEW ONLY - PCB/HIL release gates remain open
digitie/canview
Sheet: /06_esp32/
File: 06_esp32.kicad_sch
Title: CANView / 06_esp32


SCHEMATIC REVIEW ONLY - PCB/HIL release gates remain open
digitie/canview
Sheet: /07_esp_service/
File: 07_esp_service.kicad_sch
Title: CANView / 07_esp_service

TCAN1046AV: actual pin11=VIO, pin5=GND2, pin7=RXD2, pin8=STB2. CAN PHY power is vehicle-only.

SCHEMATIC REVIEW ONLY - PCB/HIL release gates remain open
digitie/canview
Sheet: /08_can_fd/
File: 08_can_fd.kicad_sch
Title: CANView / 08_can_fd


MAX3055 only for verified ISO11898-3 125kbps bus. RTH/RTL 4.7k distributed termination; no CANH-CANL 120ohm.
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

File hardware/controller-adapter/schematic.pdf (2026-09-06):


SCHEMATIC REVIEW ONLY - PCB/HIL release gates remain open
digitie/canview
Sheet: /
File: controller-adapter.kicad_sch
Title: CANView / controller-adapter

F Date: 2026-09-06

KiCad E.D.A. 10.0.6 | Id: 1/5


Controller adapter ONLY: use onboard RTC0x51. Camera disabled/disconnected. GPIO38=BCLK,39=WS,40=I2S1 DIN.

SCHEMATIC REVIEW ONLY - PCB/HIL release gates remain open
digitie/canview
Sheet: /01_waveshare_header/
File: 01_waveshare_header.kicad_sch
Title: CANView / 01_waveshare_header


3V3 GND 32kHz / 64fs / 2.048MHz BCLK; two32-bit slots, 24-bit I2S words. Raw I2S is not routed down the long cable.

SCHEMATIC REVIEW ONLY - PCB/HIL release gates remain open
digitie/canview
Sheet: /02_i2s_differential/
File: 02_i2s_differential.kicad_sch
Title: CANView / 02_i2s_differential


CLK_P Four twisted pairs; no RJ45 to avoid Ethernet/PoE misconnection. Power switch/current limit protects host header.

SCHEMATIC REVIEW ONLY - PCB/HIL release gates remain open
digitie/canview
Sheet: /03_mic_cable/
File: 03_mic_cable.kicad_sch
Title: CANView / 03_mic_cable


SCHEMATIC REVIEW ONLY - PCB/HIL release gates remain open
digitie/canview
Sheet: /04_ota_recovery/
File: 04_ota_recovery.kicad_sch
Title: CANView / 04_ota_recovery

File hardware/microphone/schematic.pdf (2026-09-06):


SCHEMATIC REVIEW ONLY - PCB/HIL release gates remain open
digitie/canview
Sheet: /
File: microphone.kicad_sch
Title: CANView / microphone

Size: A3 | Rev: R1 REVIEW | F Date: 2026-09-05
KiCad E.D.A. 10.0.6 | Id: 1/4


Remote microphone board; supply cable5V. Two clock receivers, one data driver. T5848 is 1.8V ONLY.

J1 REMOTE MIC / NOT ETHERNET

SCHEMATIC REVIEW ONLY - PCB/HIL release gates remain open
digitie/canview
Sheet: /01_receiver_power/
File: 01_receiver_power.kicad_sch
Title: CANView / 01_receiver_power


Receiver terminations on BCLK/WS. Use32kHz/2.048MHz. Cable+logic+SD output delay must meet the next rising-edge setup.

SCHEMATIC REVIEW ONLY - PCB/HIL release gates remain open
digitie/canview
Sheet: /02_i2s_link/
File: 02_i2s_link.kicad_sch
Title: CANView / 02_i2s_link


T5848 bottom acoustic port. Pin7=VDD (datasheet p35 prose typo). Shield from direct airflow; no PCB copper/paste across hole.

SCHEMATIC REVIEW ONLY - PCB/HIL release gates remain open
digitie/canview
Sheet: /03_mems_microphone/
File: 03_mems_microphone.kicad_sch
Title: CANView / 03_mems_microphone

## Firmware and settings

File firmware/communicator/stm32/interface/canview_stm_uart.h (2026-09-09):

/* SPDX-License-Identifier: GPL-3.0-only */
/** @file canview_stm_uart.h
 * @brief STM32 UART semantic runtime and bounded command boundary.
 *
 * The runtime is portable C99. It owns no USART/DMA registers and is called
 * by one cooperative worker. The platform adapter only supplies bytes, CTS
 * state and a DMA TX completion result. No API in this module creates a CAN
 * frame or grants vehicle-TX permission.
 */
#ifndef CANVIEW_STM_UART_H
#define CANVIEW_STM_UART_H

#include <stdbool.h>
#include <stddef.h>
#include <stdint.h>

#include "canview_status.h"
#include "canview_uart.h"

#ifdef __cplusplus
extern "C"
{
#endif

#define CANVIEW_STM_UART_RX_DMA_CAPACITY (2048U)
#define CANVIEW_STM_UART_BUILD_ID_DIGEST_SIZE (16U)
#define CANVIEW_STM_UART_TX_QUEUE_CAPACITY (8U)
#define CANVIEW_STM_UART_PENDING_COMMAND_CAPACITY (8U)
#define CANVIEW_STM_UART_COMMAND_PAYLOAD_MAX (240U)
#define CANVIEW_STM_UART_TX_SERIAL_CAPACITY (CANVIEW_UART_MAX_SERIAL_SIZE)
#define CANVIEW_STM_UART_HEARTBEAT_PERIOD_MS (100U)
#define CANVIEW_STM_UART_TIME_SYNC_REPLY_UNCERTAINTY_US (0U)
#define CANVIEW_STM_UART_TIME_SYNC_MAX_DELAY_US (100000U)
#define CANVIEW_STM_UART_TIME_SYNC_PENDING_TIMEOUT_MS (1000U)
#define CANVIEW_STM_UART_ERROR_RATE_LIMIT (10U)
#define CANVIEW_STM_UART_ERROR_RATE_WINDOW_MS (1000U)
#define CANVIEW_STM_UART_CONTEXT_BUDGET_BYTES (88000U)
/* T-105 replaces this foundation revision with the generated safety profile. */
#define CANVIEW_STM_UART_CAPTURE_ONLY_SAFETY_REVISION (UINT32_C(1))

/** @brief Priority class. Lower numeric values are always selected first. */
typedef enum
{
    CANVIEW_STM_UART_TX_P0 = 0,
    CANVIEW_STM_UART_TX_P1,
    CANVIEW_STM_UART_TX_STATE,
    CANVIEW_STM_UART_TX_RAW,
    CANVIEW_STM_UART_TX_CLASS_COUNT
} canview_stm_uart_tx_class_t;

/** @brief Terminal/accepted stages used in COMMAND_RESULT. */
typedef enum
{
    CANVIEW_STM_UART_RESULT_STAGE_ACCEPTED = 1,
    CANVIEW_STM_UART_RESULT_STAGE_EXECUTING = 2,
    CANVIEW_STM_UART_RESULT_STAGE_COMPLETED = 3,
    CANVIEW_STM_UART_RESULT_STAGE_REJECTED = 4,
    CANVIEW_STM_UART_RESULT_STAGE_EXPIRED = 5,
    CANVIEW_STM_UART_RESULT_STAGE_BUSY = 6
} canview_stm_uart_result_stage_t;

/** @brief Stable semantic reason values; never cast from canview_status_t. */
typedef enum
{
    CANVIEW_STM_UART_REASON_NONE = 0,
    CANVIEW_STM_UART_REASON_INVALID = 1,
    CANVIEW_STM_UART_REASON_NOT_READY = 2,
    CANVIEW_STM_UART_REASON_AUTH_FAILED = 3,
    CANVIEW_STM_UART_REASON_CACHE_FULL = 4,
    CANVIEW_STM_UART_REASON_QUEUE_FULL = 5,
    CANVIEW_STM_UART_REASON_DUPLICATE = 6,
    CANVIEW_STM_UART_REASON_TOKEN_CONFLICT = 7,
    CANVIEW_STM_UART_REASON_TIME_SYNC = 8,
    CANVIEW_STM_UART_REASON_UNSUPPORTED = 9,
    CANVIEW_STM_UART_REASON_LINK_OFFLINE = 10,
    CANVIEW_STM_UART_REASON_TIMEOUT = 11
} canview_stm_uart_reason_t;

/** @brief Local lease mirror. It is not a vehicle-TX grant. */
typedef struct
{
    bool valid;
    uint64_t lease_id;
    uint16_t scope;
    uint32_t control_generation;
    uint64_t expires_at_ms;
    uint8_t control_tag[CANVIEW_UART_CONTROL_TAG_SIZE];
} canview_stm_uart_lease_t;

/** @brief Four-timestamp mapping owned by the STM32 worker. */
typedef struct
{
    bool valid;
    uint32_t generation;
    uint32_t uncertainty_us;
    int64_t offset_stm_minus_controller_us;
    uint64_t updated_ms;
    uint64_t controller_boot_id;
    uint64_t stm_boot_id;
} canview_stm_uart_time_mapping_t;

/** @brief Copy of an admitted command retained until an executor consumes it. */
typedef struct
{
    bool valid;
    uint16_t payload_size;
    uint32_t request_sequence;
    uint32_t correlation_id;
    canview_uart_command_handle_t cache_handle;
    canview_uart_command_key_t key;
    uint8_t payload[CANVIEW_STM_UART_COMMAND_PAYLOAD_MAX];
} canview_stm_uart_pending_command_t;

/** @brief Copy-owned application message held by one priority queue. */
typedef struct
{
    bool valid;
    uint8_t message_type;
    uint8_t flags;
    uint16_t payload_size;
    uint32_t sequence;
    uint32_t correlation_id;
    uint64_t sender_time_us;
    uint8_t payload[CANVIEW_STM_UART_COMMAND_PAYLOAD_MAX];
} canview_stm_uart_tx_item_t;

typedef struct
{
    canview_stm_uart_tx_item_t items[CANVIEW_STM_UART_TX_QUEUE_CAPACITY];
    uint8_t head;
    uint8_t tail;
    uint8_t count;
} canview_stm_uart_tx_queue_t;

/** @brief Saturating counters exposed to heartbeat/diagnostic code. */
typedef struct
{
    uint32_t rx_bytes;
    uint32_t rx_frames;
    uint32_t rx_incomplete;
    uint32_t rx_malformed;
    uint32_t rx_unsupported;
    uint32_t rx_crc_failures;
    uint32_t rx_oversize;
    uint32_t protocol_errors;
    uint32_t tx_enqueued;
    uint32_t tx_completed;
    uint32_t tx_dropped;
    uint32_t tx_raw_dropped;
    uint32_t tx_queue_full;
    uint32_t tx_safety_inhibited;
    uint32_t commands_admitted;
    uint32_t commands_completed;
    uint32_t commands_authorization_rejected;
    uint32_t commands_duplicate;
    uint32_t commands_conflict;
    uint32_t commands_cache_busy;
    uint32_t commands_expired;
    uint32_t pending_cancelled;
    uint32_t session_invalidations;
    uint32_t link_resets;
    uint32_t cts_stalls;
    uint32_t time_sync_requests;
    uint32_t time_sync_responses;
    uint32_t time_sync_commits;
    uint32_t time_sync_rejected;
    uint32_t error_responses_rate_limited;
    uint32_t callback_reentry;
    uint32_t execution_count;
} canview_stm_uart_stats_t;

/** @brief Local command authorizer. NULL means deny every control request. */
typedef bool canview_stm_uart_authorize_fn(const canview_uart_message_view_t *view,
                                           uint64_t now_ms, void *context);

/** @brief DMA owner가 runtime session buffer를 지우기 전에 전송을 quiesce한다. */
typedef canview_status_t canview_stm_uart_reset_hook_fn(void *context);

/** @brief Static configuration copied during init. All callback state is caller-owned. */
typedef struct
{
    uint64_t local_boot_id;
    uint64_t local_device_id;
    uint32_t local_safety_revision;
    canview_stm_uart_authorize_fn *authorize;
    void *authorize_context;
    uint8_t build_id_digest[CANVIEW_STM_UART_BUILD_ID_DIGEST_SIZE];
} canview_stm_uart_config_t;
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

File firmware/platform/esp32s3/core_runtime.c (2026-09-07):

/* SPDX-License-Identifier: GPL-3.0-only */
#include "canview_esp_runtime.h"
#include <inttypes.h>
#include <stddef.h>
#if defined(CANVIEW_ESP_SDK_TEST)
#include "sdk_fixture.h"
#else
#include "driver/gpio.h"
#include "esp_app_desc.h"
#include "esp_flash.h"
#include "esp_heap_caps.h"
#include "esp_log.h"
#include "esp_psram.h"
#include "esp_system.h"
#include "esp_task_wdt.h"
#include "esp_timer.h"
#include "freertos/FreeRTOS.h"
#include "freertos/task.h"
#endif

/* SDK adapter의 두 독립 lock. pool lock 아래서 watchdog/SDK callback을 호출하지 않는다. */
static portMUX_TYPE pool_mux = portMUX_INITIALIZER_UNLOCKED;
static portMUX_TYPE feed_mux = portMUX_INITIALIZER_UNLOCKED;

static bool owned(const canview_esp_runtime_t *runtime)
{
    return runtime != NULL && runtime->initialized && runtime->owner == xTaskGetCurrentTaskHandle();
}

static canview_status_t callback_enter(canview_esp_runtime_t *runtime)
{
    if (runtime == NULL || xPortInIsrContext() != pdFALSE || !owned(runtime) ||
        runtime->callback_active)
    {
        return CANVIEW_INVALID_ARGUMENT;
    }
    runtime->callback_active = true;
    return CANVIEW_OK;
}

static void callback_leave(canview_esp_runtime_t *runtime)
{
    runtime->callback_active = false;
}

static canview_status_t pool_context_valid(void *context)
{
    const canview_esp_runtime_t *runtime = context;
    if (runtime == NULL || !runtime->initialized || xPortInIsrContext() != pdFALSE)
    {
        return CANVIEW_INVALID_ARGUMENT;
    }
    return CANVIEW_OK;
}

static canview_status_t safe_gpio(void *context)
{
    canview_esp_runtime_t *runtime = context;
    const canview_status_t entry = callback_enter(runtime);
    if (entry != CANVIEW_OK)
    {
        return entry;
    }
    const canview_status_t status = runtime->config.safe_gpio(runtime->config.safe_context);
    callback_leave(runtime);
    return status;
}

static canview_status_t watchdog_start(void *context)
{
    canview_esp_runtime_t *runtime = context;
    const canview_status_t entry = callback_enter(runtime);
    if (entry != CANVIEW_OK)
    {
        return entry;
    }
    canview_status_t result = CANVIEW_OK;
    if (runtime->watchdog_ready)
    {
        result = CANVIEW_INVALID_ARGUMENT;
    }
    else
    {
        const esp_err_t status = esp_task_wdt_status(NULL);
        if (status != ESP_ERR_NOT_FOUND)
        {
            /* IDF startup가 global TWDT를 초기화한다. 다른 subscription이나 설정을 가로채지 않는다. */
            result = status == ESP_OK ? CANVIEW_RESOURCE_BUSY : CANVIEW_NOT_IMPLEMENTED;
        }
        else if (esp_task_wdt_add(NULL) != ESP_OK)
        {
            result = CANVIEW_NOT_IMPLEMENTED;
        }
        else
        {
            runtime->watchdog_ready = true;
        }
    }
    callback_leave(runtime);
    return result;
}

static canview_status_t now_us(void *context, uint64_t *now)
{
    canview_esp_runtime_t *runtime = context;
    if (now == NULL)
    {
        return CANVIEW_INVALID_ARGUMENT;
    }
    const canview_status_t entry = callback_enter(runtime);
    if (entry != CANVIEW_OK)
    {
        return entry;
    }
    const int64_t value = esp_timer_get_time();
    if (value < 0)
    {
        callback_leave(runtime);
        return CANVIEW_TIMEOUT;
    }
    *now = (uint64_t)value;
    callback_leave(runtime);
    return CANVIEW_OK;
}

static canview_status_t sample(void *context, canview_esp_core_sample_t *output)
{
    const canview_esp_runtime_t *runtime = context;
    if (output == NULL)
    {
        return CANVIEW_INVALID_ARGUMENT;
    }
    const canview_status_t entry = callback_enter((canview_esp_runtime_t *)runtime);
    if (entry != CANVIEW_OK)
    {
        return entry;
    }
    canview_esp_core_sample_t value = {0};
    if (!esp_psram_is_initialized() || esp_flash_get_size(NULL, &value.flash_bytes) != ESP_OK)
    {
        callback_leave((canview_esp_runtime_t *)runtime);
        return CANVIEW_NOT_IMPLEMENTED;
    }
    const size_t psram = esp_psram_get_size();
    const size_t heap = heap_caps_get_free_size(MALLOC_CAP_INTERNAL | MALLOC_CAP_8BIT);
    const size_t block = heap_caps_get_largest_free_block(MALLOC_CAP_INTERNAL | MALLOC_CAP_8BIT);
#if SIZE_MAX > UINT32_MAX
    if (psram > UINT32_MAX || heap > UINT32_MAX || block > UINT32_MAX)
    {
        callback_leave((canview_esp_runtime_t *)runtime);
        return CANVIEW_OVERSIZE;
    }
#endif
    value.psram_bytes = (uint32_t)psram;
    value.heap_free_bytes = (uint32_t)heap;
    value.largest_block_bytes = (uint32_t)block;
    /* ESP-IDF6 task.h는 byte 단위다. upstream FreeRTOS의 word 변환을 적용하지 않는다. */
    value.stack_free_bytes = (uint32_t)uxTaskGetStackHighWaterMark(NULL);
    value.reset_reason = (uint32_t)esp_reset_reason();
    for (uint8_t index = 0U; index < runtime->config.input_count; ++index)
    {
        const uint8_t bit = (uint8_t)(1U << index);
        value.input_valid_mask |= bit;
        if (gpio_get_level((gpio_num_t)runtime->config.input_pins[index]) != 0)
        {
            value.input_level_mask |= bit;
        }
    }
    *output = value;
    callback_leave((canview_esp_runtime_t *)runtime);
    return CANVIEW_OK;
}

static canview_status_t feed(void *context, uint64_t not_before, uint64_t deadline,
                             uint64_t *fed_at)
{
    canview_esp_runtime_t *runtime = context;
    if (fed_at == NULL || not_before > deadline)
    {
        return CANVIEW_INVALID_ARGUMENT;
    }
    const canview_status_t entry = callback_enter(runtime);
    if (entry != CANVIEW_OK)
    {
        return entry;
    }
    if (!runtime->watchdog_ready)
    {
        callback_leave(runtime);
        return CANVIEW_INVALID_ARGUMENT;
    }
    canview_status_t status = CANVIEW_TIMEOUT;
    /* Timer 검사와 SDK reset 사이의 task 선점을 막는다. SDK 내부 lock은 별개다.
     * ISR/NMI·cache 정지와 SDK lock 대기의 실제 상한은 T-200/T-400 HIL로 검증해야 한다. */
    portENTER_CRITICAL(&feed_mux);
    const int64_t before = esp_timer_get_time();
    if (before >= 0 && (uint64_t)before >= not_before && (uint64_t)before <= deadline)
    {
        if (esp_task_wdt_reset() == ESP_OK)
        {
            const int64_t after = esp_timer_get_time();
            if (after >= 0 && (uint64_t)after >= not_before && (uint64_t)after <= deadline &&
                after >= before)
            {
                *fed_at = (uint64_t)after;
                status = CANVIEW_OK;
            }
        }
        else
        {
            status = CANVIEW_NOT_IMPLEMENTED;
        }
    }
    portEXIT_CRITICAL(&feed_mux);
    callback_leave(runtime);
    return status;
}

static void pool_enter(void *context)
{
    (void)context;
    portENTER_CRITICAL(&pool_mux);
}

static void pool_leave(void *context)
{
    (void)context;
    portEXIT_CRITICAL(&pool_mux);
}
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

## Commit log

2026-09-02 하드웨어·개발환경 문서와 Hyundai DBC 추가
    Waveshare 하드웨어·개발환경 문서, 2017 Tucson 검증 계획, opendbc Hyundai DBC 원본을 추가합니다.
2026-09-03 docs: define controller and communicator hardware
    [pinmap-proposed.csv]
2026-09-03 docs: harden communicator power and CAN safety
    [pinmap-proposed.csv]
2026-09-03 feat: refine driver UI and add FFT display
2026-09-04 docs: define implementation-ready CANView design
    [pinmap-proposed.csv]
2026-09-05 build: add latest embedded toolchain bootstraps
    [partitions.csv]
2026-09-05 feat: add communicator hardware review artifacts
    [04_stm32.kicad_sch, 05_debug_clock_uart.kicad_sch, 06_esp32.kicad_sch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]
2026-09-05 feat: add R1 detailed hardware and navigation protocol review candidate
    [00_vehicle_input.kicad_sch, 00b_reverse_ov.kicad_sch, 00c_auto_5v.kicad_sch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]
2026-09-05 fix: close hardware rail-fault paths and sensor contract gaps
    [00b_reverse_ov.kicad_sch, 01_usb_c.kicad_sch, 01_waveshare_header.kicad_sch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]
2026-09-05 Design independent OTA recovery and update N16R8 hardware
    [01_waveshare_header.kicad_sch, 02_esp32.kicad_sch, 03_reset.kicad_sch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]
2026-09-05 Fix OTA service interlock and durable activation policy
    [00_vehicle_input.kicad_sch, 00b_reverse_ov.kicad_sch, 00c_auto_5v.kicad_sch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]
2026-09-05 Align runtime UART module reference with N16R8 OTA design
2026-09-06 feat: reconcile complete plan and harden driver diagnostic UI
2026-09-06 fix: revoke SPORT ownership across gaps and align evidence contracts
    [canview_auto_sport.h]
2026-09-06 T-001: 재현 가능한 host/target foundation toolchain과 CI
    직접 설치한 Arm GNU·ESP-IDF·STM32CubeG4 기반 host/target build와 warning-free artifact gate, 2인 적대적 리뷰, CI evidence를 반영한다.
    [partitions.csv, partitions.ota-template.csv]
2026-09-06 T-002: ESP-NOW v1.3 schema와 생성 header 동결
    T-002 schema ABI, generated header/vector contract, static policy oracle, independent review and host/target CI evidence merged.
2026-09-06 T-003: ESP-NOW codec, session과 QoS
    T-003 completed with host, target, CI, and two-reviewer gates.
2026-09-06 docs: start T-004 UART schema task
2026-09-06 feat: add UART v1.0 schema and semantic codec
2026-09-06 test: add UART fault and semantic coverage
2026-09-06 test: expand UART boundary and state coverage
2026-09-06 fix: harden UART semantic state and admission boundaries
2026-09-06 fix: close UART admission review gaps
2026-09-06 fix: revalidate UART admission views
2026-09-06 fix: bind UART replay and queue admission to session
2026-09-06 test: account for actual UART bytes in duplex soak
2026-09-06 test: define UART queue ownership and verify payload lifetime
2026-09-06 docs: record completed UART full-rate soak and final builds
2026-09-06 docs: archive T-004 and scope STM32 core bench prerequisite
2026-09-06 feat(stm32): add bounded core boot watchdog and bench fault tests
2026-09-06 fix(docs): align STM32 callback types with C API renderer
2026-09-06 fix(stm32): close deadline NMI and validation review gaps
2026-09-06 test(stm32): separate NMI jump lifetime from GCC fault loop
2026-09-06 docs(review): close STM32 core and portability findings
2026-09-06 docs: archive T102a and scope ESP32 core prerequisite
2026-09-06 feat(esp32): add bench health watchdog and bounded payload pool
2026-09-06 test(esp32): enforce actual config at configure and cover app faults
2026-09-07 fix(esp32): enforce bench panic and nonvolatile safety config
2026-09-07 docs(architecture): identify communicator ESP32 bench composition
2026-09-07 docs(review): close ESP32 bench findings with independent evidence
2026-09-07 docs(tasks): start Bridge core after verified ESP32 merge
2026-09-07 feat(bridge): share ESP bench core with fixed board contracts
    [core_runtime.c]
2026-09-07 fix(bridge): close core bench review findings
    [core_runtime.c]
2026-09-07 feat(t400): harden bridge runtime board contracts
2026-09-07 fix(t400): reject wrong BSP before safe GPIO
    [core_runtime.c]
2026-09-08 docs: point bridge status at current candidate
2026-09-08 fix: pin bridge asset line endings
2026-09-08 fix: close bridge auth socket lifetime gaps
2026-09-08 ci: pin target artifacts to pull request head
2026-09-08 ci: pin qualification jobs to PR head
2026-09-08 Implement STM32 platform foundation
2026-09-08 Fix STM32 platform review findings
2026-09-08 Harden STM32 capture-only review gates
2026-09-08 Close STM32 gate review findings
2026-09-08 Match STM32 source gate to C preprocessing
2026-09-08 Record STM32 review closure evidence
2026-09-09 feat(stm32): add three-channel FDCAN capture-only path (#32)
    * feat(stm32): add three-channel fdcan capture path
    * test: bound Python unit suite on WSL mounts
    * docs: record T103 STM32 target evidence
    * docs: bind T103 target evidence to rebuilt candidate
    * Fix STM32 FDCAN capture transaction and loss handling
    * Refresh T103 STM32 target build evidence
    * Guard empty FDCAN inventory periods
    * Record T103 sanitizer and target evidence
    * fix(stm32): close fdcan capture review findings
    * fix(stm32): close fdcan evidence and sticky fault review
    * fix(stm32): bind fdcan message ram to vendor contract
    * fix(stm32): reject stale capture status and bind evidence
    * test(t103): keep candida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
2026-09-09 feat(stm32): add UART DMA control boundary
2026-09-09 fix(stm32): close T104 hostile review findings
    [canview_stm_uart.h]
2026-09-09 fix(stm32): invalidate stale UART completions and bind HELLO build identity
    [canview_stm_uart.h]
2026-09-09 test(stm32): verify DMAMUX model and record scoped review waiver
2026-09-14 feat(ota): connect Communicator staging to SDK and metadata checks
    [partitions.ota-template.csv]
2026-09-19 feat(ota): assemble signed containers and collect bounded C prefixes
2026-09-19 feat(ota): gate staged reception through authenticated C flow
2026-09-19 test(ota): isolate stage argument guards and prove mutation rejection
2026-09-19 docs: record T007 merge and begin STM32 MCUboot work
2026-09-19 feat(stm32): add checked fixed flash layout for MCUboot port
2026-09-19 feat(stm32): build and validate MCUboot primary application images
2026-09-19 feat(stm32): connect MCUboot C port and exercise offset swap recovery
2026-09-19 feat(stm32): bind MCUboot validation to protected image identity
2026-09-19 feat(stm32): guard MCUboot mutations with G474 protection readback
2026-09-19 feat(stm32): add bounded SRAM flash command primitive
2026-09-19 fix(stm32): prime SRAM before startup stack writes
2026-09-19 fix(stm32): initialize startup dummy before parity reads
2026-09-19 feat(stm32): add bounded SRAM ECC guarded Flash read
2026-09-19 fix(stm32): reject Flash read errors and connect bounded boot IO
2026-09-19 test(stm32): exercise MCUboot through production Flash IO
2026-09-19 feat(stm32): provide explicit immutable boot identity and public key
2026-09-19 fix(stm32): reject relative boot trust paths before cache conversion
2026-09-19 docs(review): close STM32 boot trust path finding
2026-09-19 feat(stm32): link boot SRAM code through SDK startup copy
2026-09-19 feat(stm32): bound boot progress and watchdog runtime
2026-09-19 feat(stm32): validate primary vectors before boot handoff
2026-09-19 fix(stm32): route boot libc failures to MCUboot FIH panic
2026-09-19 test(stm32): reject conditional fail-stop branch mutations
2026-09-19 test(stm32): enforce fail-stop control flow and full MCUboot CI link
